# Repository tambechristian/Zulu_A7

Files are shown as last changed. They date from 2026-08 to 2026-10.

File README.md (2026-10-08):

# Zulu A7

Zulu A7 is a USB FPGA board built around an AMD/Xilinx Artix-7
XC7A35T-1CPG236C. An FTDI FT2232HL bridge provides JTAG (channel A) and a
UART (channel B) over one micro-USB port. The board carries 64 MB of SDRAM,
a 128 Mbit quad-SPI configuration flash, a microSD socket, a Pmod host
header and a 40-pin breadboard header. It runs from USB through a
single-cell LiPo charger with power path and three buck regulators (3.3 V,
1.8 V and 1.0 V). The PCB is a 69.85 x 25.40 mm, six-layer HDI board.

The main design is the Altium Designer project in `Zulu_Altium_VS_Code/`.
Its fabrication and turnkey-assembly packages for PCBWay are dated
2026-10-07. Build and test results are not recorded in this repository.

## Origin and attribution

Zulu A7 is an adaptation of **XuLA2**, the USB FPGA prototyping board by
Dave Vandenbout / XESS Corp. (copyright 2012 XESS Corp.), published at
<https://github.com/xesscorp/XuLA2>. Its hardware design (schematic and
layout in `pcb/`) is licensed under
[CC BY-SA 3.0 Unported](https://creativecommons.org/licenses/by-sa/3.0/),
per the notice on its schematic. This repository does
not imply any connection with, or endorsement by, XESS Corp. or Dave
Vandenbout.

XESS's [product listing](https://www.tindie.com/products/xesscorp/xula2-lx25-fpga-prototyping-board/)
says the whole XuLA2 design was made open source and that anyone who
re-designs it must open-source their design too. As of 2026-10-07 it lists
XuLA2 as retired. The licence terms are those of CC BY-SA 3.0.

XuLA2 (schematic version 2.0, EAGLE 5 files) had a Xilinx Spartan-6
XC6SLX25 in FT256 and a Microchip PIC18F14K50 that handled reset and
initialisation, clock generation and USB-to-JTAG. It also had 256 Mbit
SDRAM, 8 Mbit SPI flash, a microSD socket, a mini-USB connector, ZLDO1117
3.3 V and 1.2 V regulators, a 40-pin breadboard prototyping header and an
aux JTAG header.

### Lineage

1. **XuLA2**: XESS Corp., 2012. The upstream design.
2. **XuLA3**: Christian Tambe's own rework of XuLA2, started 2026-08-10 in a
   separate local repository that is not published. It is not an XESS
   design. Its baseline is the XuLA2 schematic in EAGLE XML. The move to the
   Artix-7, the FT2232H bridge and an LTC3569 triple buck was made in XuLA3,
   before the fork. There the `xess` library was renamed `ctambe`, and the
   schematic AUTHOR and copyright line were changed to Christian Tambe.
3. **Zulu A7**: forked from XuLA3 on 2026-08-29 (commit `30a0e65`, "Zulu A7
   forks from XuLA3: the board is renamed, not redesigned"). That commit
   renamed X2's package XULA-DIP37 to ZULU-DIP37 and its deviceset XULA-CONN
   to ZULU-CONN, dropped unused devicesets including XC6SLX25-FT256 and
   PIC18F14K50, and set the version to 1.0. `zulu_a7.brd` took only its
   layer, settings and autorouter sections from the XuLA3 board;
   `tools/make_board.py` writes the geometry new.
4. **Altium and KiCad copies**: the EAGLE schematic was imported into Altium
   with the EAGLE Import Wizard in `Zulu_Altrium/` (commit `6d2efd6`).
   `Zulu_Altium_VS_Code/` is a later working copy of that project. The SC189
   regulators, the BQ24232 charger and the X2 pin field are Altium-side
   changes, and the board was routed there. `Zulu_kicad/` is a KiCad
   conversion of the Altium project.

### Main changes from XuLA2

| | XuLA2 | Zulu A7 |
|---|---|---|
| FPGA | Xilinx Spartan-6 XC6SLX25, FT256 | AMD/Xilinx Artix-7 XC7A35T-1CPG236C |
| USB bridge | Microchip PIC18F14K50 | FTDI FT2232HL with a 93LC46B EEPROM |
| USB connector | Hirose UX60SC-MB-5ST mini-USB | Molex 105017-0001 micro-USB |
| SDRAM | W9825G6JH-5, 256 Mbit | Alliance AS4C32M16SB-7TCN, 512 Mbit |
| Flash | W25Q80BV, 8 Mbit | Winbond W25Q128JV, 128 Mbit quad SPI |
| microSD | ALPS SCHD3A0100 | Hirose DM3D-SF |
| Clock | generated by the PIC18F14K50 | 12.000 MHz oscillator shared by the FT2232HL and the FPGA |
| Power | ZLDO1117 3.3 V and 1.2 V regulators | BQ24232 LiPo charger and three SC189 bucks (3.3 / 1.8 / 1.0 V) |
| Headers | 40-pin breadboard header, aux JTAG header | 40-pin breadboard header X2 with its own pin map, 2x6 Pmod host header J1, unpopulated JTAG holes JP3/JP4 |
| PCB | 2 in x 1 in | 69.85 x 25.40 mm, six-layer HDI |

XuLA3 and the EAGLE-era Zulu A7 used an LTC3569 triple buck. The Altium
copy replaced it on 2026-09-06 with the three SC189 bucks, so the EAGLE
files in this repository still show the LTC3569.

`docs/Zulu_A7-Design-Change-Record.html` lists the part changes from the
fork. Its "Was" column is the XuLA3 rev 1 state, which is mostly but not
entirely the XuLA2-LX25 BOM (the ESP8266 header and the BTN1 PTA-142 button
were XuLA3 additions). It predates the SC189 power section.

### What still comes from XuLA2

Compared with the `xess` library of the XuLA2 schematic (in its EAGLE XML
form), the `ctambe` library in the root `zulu_a7.sch` keeps 16 packages
byte-identical (for example TSOPII-54, SCHD3A0100, UX60SC-MB-5ST, CC_BY,
CC_CC and CC_COPYRIGHT), and 7 symbols and 5 devicesets are identical. The
later EAGLE copies keep the same packages with their keepout outlines
removed. Sheet text such as "Block Diagram",
"PROTOTYPING HEADER", "FPGA Connections" and the three licence lines is
kept verbatim. This material is in the EAGLE files (`zulu_a7.sch`,
`zulu_a7.brd` and the EAGLE copies in `Claude_Fable/`, `Zulu_Altrium/`,
`Zulu_Altium_VS_Code/` and `Altium_backup/`), in the SchDoc, PcbLib and
PcbDoc files of the four Altium copies and the September schematic PDFs,
and in `Zulu_kicad/kicad_project/` (`ctambe.kicad_sym`, footprints in
`zulu_a7.pretty/`, `zulu_a7.kicad_pcb` and `zulu_a7_2.kicad_sch`).

### Notices

In every copy of the schematic, the General IO sheet (sheet 3 of 7 in EAGLE
and Altium, `zulu_a7_2.SchDoc`; page 4 of 8 in KiCad, `zulu_a7_2.kicad_sch`,
under the added root sheet) carries "2026, Christian Tambe. Some rights
reserved." and the three CC BY-SA Unported licence lines, beside the CC
logos. The title block of every sheet reads "AUTHOR: Christian Tambe": in the
EAGLE files through the AUTHOR attribute, and in the Altium copies
(`Zulu_Altium_VS_Code/`, `Zulu_Altium_VS_Code_HDI_Optimized/`) and the KiCad
copy since 2026-10-08 (`Zulu_Altium_VS_Code/docs/schematic_author.md`). The
superseded `Zulu_Altrium/` and the `Altium_backup/` snapshot still show the
importer's placeholder "AUTHOR".
The upstream line "2012, XESS Corp. Some rights reserved." and the upstream
AUTHOR "Dave Vandenbout / XESS Corp." were replaced during the XuLA3 rework
and have never been in this repository's history, and the sheets do not yet
carry the XESS line again.
[LICENSE](LICENSE) reproduces the upstream notice and gives the credit for
XuLA2; keep it with any copy of the schematics.

## Board facts

- **FPGA**: U1 XC7A35T-1CPG236C, CPG236 BGA, 10 x 10 mm, 0.5 mm pitch.
- **USB**: U2 FTDI FT2232HL (LQFP-64). Channel A is MPSSE JTAG plus
  PROG#/DONE, channel B is the UART. U10 93LC46B configuration EEPROM.
  X1 Molex 105017-0001 micro-USB-B.
- **Memory**: U3 Alliance Memory AS4C32M16SB-7TCN, 512 Mbit (64 MB) SDRAM;
  the memory controller must use 10 column bits (A0-A9). U4 Winbond
  W25Q128JVSIQ, 128 Mbit quad SPI; the 17,536,096-bit bitstream leaves about
  14 MB for user data.
- **Clock**: Q1 ECS-3225SMV-120-FP-TR, 12.000 MHz, +-10 ppm HCMOS
  oscillator, driving the FT2232HL and the FPGA through 33 ohm each.
- **Power**: U8 TI BQ24232 single-cell LiPo charger with power path. Its
  output VU, the system rail that feeds the three bucks, is 4.4 V from USB
  and VBAT - 60 mV on battery; 495 mA input limit, 244 mA charge current.
  Battery on X4, a JST PH 2-pin header (pin 1 = battery +); the BOM has no
  battery. U5, U6 and U7 are Semtech SC189 bucks for 3.3 V, 1.8 V and 1.0 V
  (FPGA core).
- **I/O**: X2 40-pin breadboard header, 2.54 mm pitch, rows 22.86 mm apart,
  mounted from the underside; GND on pins 1, 17 and 21, +3.3 V on 18,
  +1.8 V on 19, +1.0 V on 20, VU on 22. J1 2x6 Pmod host header. X3 Hirose
  DM3D-SF microSD socket with card detect. JP3/JP4 unpopulated 1x3 JTAG
  holes. User button BTN, RGB LED LD0 and five 0603 LEDs (LD1-LD5).
- **PCB**: 69.85 x 25.40 mm, six layers (Top / L2 GND / L3 / L4 / L5 VCC3V3 /
  Bottom). Two-step HDI 1+1+N+1+1 with 0.15 mm laser microvias, 0.15 mm
  L3-L4 buried vias and 0.20 mm through vias. 3.0 / 3.5 mil minimum
  track / space. USB pair 90 ohm differential.
- **Status**: fully routed. Altium DRC on the final saved board (2026-10-07
  16:53) reports 0 violations; the report is
  `Zulu_Altium_VS_Code/Imported zulu_a7.PrjPcb/Design Rule Check - zulu_a7.drc`.
  The release packages identify the board by its PcbDoc SHA-256,
  `89a421b9060195d66bed82f7a4e7d80121bd0e9d679a3fee32289e8f541f4bde`.
- **Assembly**: 172 fitted designators (32 top, 140 bottom), 76 parts in
  0201. ENIG finish recommended. No fiducials on the board.

Known caveats, from `Zulu_Altium_VS_Code/docs/power_budget.md` and the
assembly notes:

- The worst-case draw (about 697 mA) exceeds the 495 mA input limit and needs
  the battery; with no battery the board browns out at that load. The board
  draws more than 100 mA before the FT2232HL enumerates.
- Every rail has more output capacitance than the SC189 datasheet's 30 uF
  start-up limit. Scope the three rails at power-on on the first board.
- LD0 green and blue are sunk from 3.3 V through 33 ohm and may be dim or
  dark; only red has margin.
- U5 and U7 look alike; swapping them puts 3.3 V on the FPGA core.

## Repository layout

| Entry | Status | Contents |
|---|---|---|
| `Zulu_Altium_VS_Code/` | **Current, authoritative** | Main Altium project: `Imported zulu_a7.PrjPcb/` (7 SchDocs, PcbDoc, PcbLib, released Gerber and NC-drill files, DRC report), `fabrication/`, `assembly/`, `docs/` (stage and decision records), `tools/`, `board/` (outline DXF; `JLCPCB-HDI-ENQUIRY.md` is superseded). The Stage-13 route plan is `tools/stage13/plan.json`; the root `plan.json` is a small XADC-knot plan. Its root `zulu_a7.sch` is the stale EAGLE import source. |
| `Zulu_Altium_VS_Code_HDI_Optimized/` | Derivative | Same-outline copy of the main board with 13 HDI sites turned into through vias, with its own fab zips and assembly release. |
| `Zulu_kicad/` | Derivative | KiCad 10 conversion of the main project, netlist-proven. Design rules were not translated, so KiCad DRC is not meaningful; do not refill zones. Altium stays the fabrication master. |
| `Zulu_Altrium/` | Superseded | Earlier Altium working copy: the EAGLE import, the September schematic work, routing placed through Stage 8 and the Stage 9-12 records (plans, never placed). Its PcbDoc is an intermediate Stage-13 Phase II board. |
| `Altium_backup/` | Snapshot | Backup of the Altium project taken during the September routing stages. |
| `Claude_Fable/` | Legacy | EAGLE/Fusion-era 8-layer HDI working copy, its board variants and tools. |
| `zulu_a7.sch` | Legacy | EAGLE schematic from the fork. It predates the released design (no BQ24232, no SC189) and is not the Altium import source, which is the later `Zulu_Altrium/zulu_a7.sch`. |
| `zulu_a7.brd` | Legacy | EAGLE board from the fork. |
| `tools/` | Legacy | EAGLE-era Python tools that read or write the root `zulu_a7.sch` / `zulu_a7.brd` (for example `make_board.py`, `validate.py`, `change_record.py`). |
| `board/` | Legacy | EAGLE/Fusion-era fab planning: `STACKUP.md`, EAGLE `.dru` rule files, DFM enquiry drafts, `pcbway/README.md`. Superseded by `Zulu_Altium_VS_Code/fabrication/PCBWAY_FAB_NOTES.txt`. |
| `docs/` | Mixed | `zulu_a7-bom.csv` is the current master BOM. `Zulu_A7-Design-Change-Record.html` is an EAGLE-era record. |
| `vivado/` | Mixed | `zulu_a7_pins.xdc` is current (Stage-13 pin permutation). `zulu_a7_io.rpt`, `zulu_a7_io.csv` and `zulu_a7_clocks.rpt` come from the 2026-09-10 Vivado run and show pre-swap balls; `zulu_a7_top.v` is the HDL top module used for that run. |
| `Zulu A7 Board Plan.html` | Legacy | Generated by `tools/board_plan.py`; shows the old 60.96 x 25.40 mm board. |
| `fix_sheet_names.cmd` | Legacy | EAGLE-era helper, run after exporting `zulu_a7.sch` from Fusion. |
| `W*P1.pdf`, `W*P2.pdf` | Vendor documents | PCBWay order-page printouts. They are not the fabrication spec; see `PCBWAY_FAB_NOTES.txt`. |
| `.gitignore` | | Ignores EAGLE and Vivado scratch files, `Datasheet/`, `board/*.pdf` and `archives/`. |

`archives/` and `Datasheet/` are ignored and are not part of the repository.

## Where to start

1. Open `Zulu_Altium_VS_Code/Imported zulu_a7.PrjPcb/zulu_a7.PrjPcb` in
   Altium Designer. The folder name comes from the EAGLE Import Wizard.
2. `Zulu_Altium_VS_Code/fabrication/PCBWAY_FAB_NOTES.txt`: what the current
   board is (stack, vias, impedance, outline, file map, final DRC).
3. `Zulu_Altium_VS_Code/assembly/Zulu_A7_Assembly_Notes.txt` and
   `Zulu_Altium_VS_Code/docs/pcbway_assembly_release.md`: the assembly
   release. To regenerate it, run
   `python tools/generate_jlcpcb_assembly.py --release-date 2026-10-07` from
   `Zulu_Altium_VS_Code/`.
4. `docs/zulu_a7-bom.csv`: the master BOM. Regenerate it only with
   `Zulu_Altium_VS_Code/tools/master_bom.py`; the copies in `Zulu_Altrium/`
   and `Altium_backup/` read stale sheets.
5. `Zulu_Altium_VS_Code/docs/power_budget.md`: power path, current budget
   and the caveats above.
6. `Zulu_Altium_VS_Code/docs/stage13_route_plan.md`, section "Final
   implementation closeout": how routing was finished. Later board changes
   are in `x1_slot_fix.md`, `x2_power_pins.md`, `x2_pin_labels.md` and
   `btn_move.md` in the same folder.
7. For FPGA work: `vivado/zulu_a7_pins.xdc` is the current pin map (the
   SDRAM ports need DRIVE 8, as set there). This repository has no
   programming instructions, FT2232H EEPROM image or example bitstream.
8. `Zulu_Altium_VS_Code_HDI_Optimized/HDI_OPTIMIZATION_NOTES.md` (the
   derivative board) and `Zulu_kicad/CONVERSION.md` (the KiCad copy).

Notes:

- No current schematic PDF is tracked. The `zulu_a7.pdf` files in
  `Zulu_Altrium/` and `Altium_backup/` are 2026-09-10 prints and are out of
  date.
- `Zulu_Altium_VS_Code/docs/` is a dated record of stages and decisions, and
  older entries describe superseded states. For example,
  `Zulu_Altium_VS_Code/docs/hdi_spec.md` and `board/pcbway/README.md` name
  JLCPCB as the fab. Where they disagree with the release files, the release
  files are current.
- `Zulu_Altium_VS_Code/tools/README.md` covers the import, schematic-edit and
  audit scripts (`pip install olefile pywin32`). It does not cover the
  routing toolkits or the assembly generator, which also needs `pymupdf` and
  `altium-monkey` (`pip install olefile pymupdf altium-monkey`).
- Vendor datasheets are not tracked. After a fresh clone, put AMD's package
  pinout file for the XC7A35T-CPG236 back as
  `Datasheet/xc7a35tcpg236pkg_pinout.txt`. Without it, `tools/validate.py`,
  `tools/vivado_io_check.py`, `tools/escape/rings.py` and
  `tools/change_record.py`, and the Altium copy's `tools/bom_audit.py`,
  `tools/connectivity_check.py` and `tools/stage13/xdc_check.py`, lose their
  ball checks or fail.

## Licence

See [LICENSE](LICENSE). Except for the third-party material listed there,
this repository, scripts included, is licensed under
[CC BY-SA 3.0 Unported](https://creativecommons.org/licenses/by-sa/3.0/legalcode).
It is an adaptation of XuLA2 (see above). Under section 8(b) of the licence,
XESS Corp., as Licensor of XuLA2, offers each recipient a licence to the
original XuLA2 Work on the same terms.

Design references, not files: some circuit choices follow Digilent's Cmod
A7. The SC189 bucks are "Cmod A7 style", the XADC input network is the one
Digilent uses on the Cmod A7, and the SDRAM, microSD and GPIO ball
assignments were first checked against the Cmod A7-35T. No Digilent file is
in this repository, and this licence grants nothing on Digilent's behalf.

Not in this repository: XuLA2's firmware (XESS code under GPL v2 or later,
plus Microchip USB-stack files under Microchip's licence), its FPGA example
designs (many files under GPL or LGPL), and the vendor datasheets and the
AMD/Xilinx pinout file (`Datasheet/` is ignored).

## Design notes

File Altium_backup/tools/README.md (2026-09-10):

# Altium import checks

Scripts used to convert `zulu_a7.sch` (EAGLE 9.7 XML, written by Fusion 360)
into `Imported zulu_a7.PrjPcb` with Altium Designer's EAGLE Import Wizard,
and to check the result.  They edit the SchDoc files directly (OLE compound
documents, `FileHeader` stream of `|RECORD=n|Key=Value|` records), so close
the project in Altium before running the two fix scripts.

    pip install olefile pywin32

* `verify_import.py zulu_a7.sch "Imported zulu_a7.PrjPcb"` - every EAGLE
  part, gate, supply symbol and named net has its Altium counterpart.
* `fix_text_orientation.py <SchDoc...>` - EAGLE draws R180/R270 text
  readable; Altium draws Orientation 2/3 upside down.  Turns them into
  0/90 with mirrored justification, so anchors and text boxes stay put.
* `fix_labels.py <this folder> "Imported zulu_a7.PrjPcb"` - the label
  placements adjusted after reviewing the Smart PDF export (see docstring).
* `fix_gate_labels.py <this folder> <SchDoc...>` - the one-pin-per-gate
  parts (X2, U3, U4, U1) show their gate names through EAGLE's >GATE text;
  the importer gives every such label OwnerPartId=1, so Altium hides all but
  one per part.  Re-owns each label to its gate.
* `add_noerc.py <this folder> "Imported zulu_a7.PrjPcb"` - No-ERC markers on
  the nine pins that are open on purpose (the eight GTP balls the sheet
  marks "float per UG482", and the USB ID pin X1-4).
* `fix_pin_types.py <this folder> "Imported zulu_a7.PrjPcb"` - the EAGLE
  library types the supply/ground pins of U2, U3, U4, U10 and all of X2's
  pins as "io"; makes them Power and Passive so the ERC pin-type rules mean
  something.
* `swap_vcc3v3_to_sw1.py <this folder> "Imported zulu_a7.PrjPcb/zulu_a7_1.SchDoc"` -
  the 2026-09-06 design change: VCC3V3 onto the LTC3569's 1.2 A channel
  (SW1) and VCC1V0 onto SW3, by swapping the two rail labels after L1/L3,
  the R65/R66 and R71/R73 divider values and the EN1/EN3 wiring. Applied
  once; the docstring is the change record. Not reflected in zulu_a7.sch
  (EAGLE), which is now history.
* `sc189_power_section.py <this folder> "Imported zulu_a7.PrjPcb/zulu_a7_1.SchDoc"` -
  the 2026-09-06 regulator change: the LTC3569 section (U8, dividers, the
  EN_BIAS network) replaced by three fixed SC189 bucks U5/U6/U7 with L1-L3
  at 1.5 uH, C80/C82/C84 as 22 uF outputs, new C147-C149 10 uF inputs, C78
  at 10 uF. Rewrites the sheet record by record; run once, on the sheet as
  committed in bedd4a7 (its delete list is keyed to that file). SC189 pin
  numbers (1 VIN, 2 GND, 3 EN, 4 VOUT, 5 LX) were checked against the Semtech
  datasheet (Datasheet/SC189-datasheet 08 27 10.pdf, p2 and p14) on 2026-09-06.
* `fix_sc189_bom.py <this folder> "Imported zulu_a7.PrjPcb/zulu_a7_1.SchDoc"` -
  follow-up to the above: the hidden MANF#/SPEC parameters that the value
  edits had left stale (L2/L3 still named the 3.3/2.2 uH inductors, C82/C84
  a 10 uF part under a 22 uF value, C78 the 22 uF part under 10 uF) and the
  three input caps moved to a 10 V 0805 part (GRM21BR61A106KE19L) because a
  6.3 V 0603 is under the datasheet's 4.7 uF at 5 V. Keyed by designator,
  safe to re-run.
* `x3_dm3d_sf.py <this folder> "Imported zulu_a7.PrjPcb/zulu_a7_3.SchDoc"` -
  2026-09-06: X3 (microSD) from the Hirose DM3AT-SF-PEJM5 push-push socket to
  the DM3D-SF push-pull one (HRS 609-0025-8, DM3 catalog p9 in
  Datasheet/DM3AT-SF-PEJM5.pdf). Same eight contacts; the two 'G1,3'/'G2,4'
  multi-pad shell pins become G1-G4 on the GND bus; new pins A/B for the
  card-detect switch, left open with No-ERC markers; footprint model renamed
  DM3D-SF (to be drawn at the PCB stage). Refuses to run twice.
* `btn_pts810.py <this folder> "Imported zulu_a7.PrjPcb/zulu_a7_2.SchDoc"` -
  2026-09-08: BTN from the PTA-142 (no maker, no distributor) to the C&K /
  Littelfuse PTS810SJM250SMTR LFS (4.2 x 3.2 mm J-lead, 1.6 N). Parameters,
  an inserted MANF parameter (OwnerIndex renumbering) and the footprint model
  name PTS810; pins 1,2 / 3,4 already match the datasheet's 1-2 / 3-4 pairing.
  Refuses to run twice.
* `ld0_east1616.py <this folder> "Imported zulu_a7.PrjPcb/zulu_a7_2.SchDoc"` -
  2026-09-08: LD0 from the Victory VS NRD8 (maker-direct only) to the Everlight
  EAST1616RGBA8 (19-337/R6GHBHW-A01/2T), the same body, pads and arrangement
  with different pad numbers: pins renumbered 1/2/3 -> 2/4/6 (cathodes) and
  4/5/6 -> 1/3/5 (anodes), nets untouched, footprint model EVERLIGHT-19-337.
  Refuses to run twice.
* `x2_sullins.py <this folder> "Imported zulu_a7.PrjPcb/zulu_a7_2.SchDoc"` -
  2026-09-08: the ZULU-CONN pin field X2 gets MANF, MANF#, SPEC and NOTE
  (Sullins PRPC024SAAN-RC + PRPC009SAAN-RC + PRPC011SAAN-RC, one of each per
  board) inserted into all 45 placed gates with OwnerIndex renumbering;
  comment and footprint ZULU-DIP37 unchanged. Refuses to run twice.
* `x2_lipo_corner.py <this folder> "Imported zulu_a7.PrjPcb"` - 2026-09-09: room for
  the LiPo connector at the right-hand end of X2. Sheet 2: +5V-INPUT (pad 44)
  with D2/D3, VEXT and GND5 (pad 23) deleted; +3.3V2/GND3 swapped with
  CHAN12/CHAN13 (pads 2/3 <-> 25/26) as a net-label, GATE-label and GateName
  swap; the two dead sub-parts removed from all 43 gate copies and parts
  renumbered 1-43 (PartCount 44, AllPinCount 42); displayed pins 2/3 retyped
  passive and 25/26 power; MANF#/SPEC/NOTE and the text frame rewritten for
  the split bottom row (PRPC020 + PRPC002). Sheet 1: charger note updated.
  Verifies the result and refuses to run twice. Its sub-part deletion also took the
  seven catalogue parameters of two copies whose serial OwnerPartId was 35 or 45
  (found by the review workflow); `x2_restore_params.py` put them back.
* `x2_restore_params.py <this folder> "Imported zulu_a7.PrjPcb/zulu_a7_2.SchDoc"` -
  2026-09-09: re-appends DeviceName/LibraryName/DeviceSetName/MANF/MANF#/SPEC/NOTE
  to any X2 gate copy missing them, cloned from a healthy copy.
* `x2_jst_gap.py <this folder> "Imported zulu_a7.PrjPcb"` - 2026-09-09, second pass:
  GND3 deleted, the bottom row closed up and re-numbered by position (23 RST#,
  24 +3.3V, 25-27 CHAN14-16, 28-30 empty for the LiPo header, 31-44 CHAN17..
  ANALOG-IO1), gate copies/wires/labels moved to the rows of their new pads,
  designators remapped in all 42 copies, sub-parts renumbered 1-42, catalogue
  parameters exempt from the sub-part deletion; MANF#/SPEC/NOTE and the text
  frame rewritten (PRPC007 + PRPC014 on the bottom row); U8 NOTE on sheet 1
  loses its D2 sentence. Verifies rows against pad numbers; refuses to run twice.
* `x2_drop_3v3.py <this folder> "Imported zulu_a7.PrjPcb"` - 2026-09-09, third pass:
  +3.3V2 (pad 24) deleted, its position left empty like the LiPo gap; sub-part
  removed from all 41 copies and parts renumbered 1-41 (PartCount 42,
  AllPinCount 40); no pin slides, so the only netlist effect is X2-24 leaving
  VCC3V3. MANF#/SPEC/NOTE and the text frame rewritten (bottom row now 1x3 +
  1x3 + 1x14). The header takes 3.3 V from pad 17. Refuses to run twice.
* `x2_renumber_40.py <this folder> "Imported zulu_a7.PrjPcb"` - 2026-09-09, fourth
  pass: CHAN14-16 slide one position right into the hole +3.3V2 left, so the LiPo
  landing widens to four positions and matches the USB landing (12.70 mm between
  neighbouring pin centres, 11.176 mm clear); the field is then renumbered 1-40
  straight through, skipping both landings. Designators remapped in all 41 gate
  copies, three gate copies with their wires and labels shifted, MANF#/SPEC/NOTE
  and the text frame rewritten (1x6 + 1x14 on the bottom row). Connectivity is
  untouched: the netlist differs only in X2 pad names. Refuses to run twice.
* `x2_move_landing.py <this folder> "Imported zulu_a7.PrjPcb"` - 2026-09-09,
  fifth pass: CHAN17-19 (pins 27-29) slide four positions towards the corner, so
  the LiPo landing moves to between pins 29 and 30, on the same four x values as
  the USB landing above it, and the two rows become mirror images (9 + landing +
  11 each). Pin numbers do not move, so the exported netlist is byte-identical;
  only geometry, MANF#/SPEC/NOTE and the text frame change (strips become 2x 1x9
  + 2x 1x11). Refuses to run twice.
* `sc189_pin_ids.py <this folder> "Imported zulu_a7.PrjPcb/zulu_a7_1.SchDoc"` -
  2026-09-09: the fifteen pins of U5, U6 and U7 all carried one UniqueID
  (PDYAEPSY, from cloning a pin record in sc189_power_section.py); each gets a
  fresh one, clear of the others on the sheet. Only the UniqueID field changes,
  which verify() proves by masking it and comparing byte for byte, so the
  netlist is unaffected. Refuses to run twice.
* `x2_top_row_order.py <this folder> "Imported zulu_a7.PrjPcb"` - 2026-09-09,
  sixth pass: the top row put in channel order (1 GND, 2 CHAN-CLK, 3-9 CHAN0-6,
  USB landing, 10-16 CHAN7-13, 17-20 the supplies), so CHAN12/CHAN13 leave the
  corner. Sixteen gate copies move with their wires and labels and every pin
  designator is remapped in all 41 copies; connectivity is unchanged, only which
  X2 pad each net lands on. Refuses to run twice.
* `sheet0_pmic_block.py <this folder> "Imported zulu_a7.PrjPcb"` - 2026-09-09:
  the block diagram gains PMIC BQ24232 between the USB port and the voltage
  regulators, with LiPo Connect on its right; the +5V riser is extended into the
  charger, VU drops from the charger into the regulators and VBATT runs to the
  battery block. Drawing furniture only (RECORD=4 text, RECORD=6 lines), so the
  netlist cannot change. Refuses to run twice.
* `jp_dns.py <this folder> "Imported zulu_a7.PrjPcb/zulu_a7_4.SchDoc"` - 2026-09-08:
  JP3/JP4 (bare JTAG holes) get DNS = Yes and a SPEC line, inserted after
  their NOTE with OwnerIndex renumbering; bom_audit lists them as DNS
  positions instead of parts. Refuses to run twice.
* `u2_ft2232hl.py <this folder> "Imported zulu_a7.PrjPcb"` - 2026-09-09: U2 from
  the FT2232HQ (QFN-64, dry until April 2027) to the FT2232HL (LQFP-64, same
  die and pin numbering): part number, comment, label, device names,
  description, footprint model FT2232HL-LQFP64, SPEC/NOTE inserted, the EP
  pin and its ground stub removed (bus wire shortened), sheet-4 title and
  sheet-0 block renamed. Refuses to run twice.
* `bq24232_charger.py <this folder> "Imported zulu_a7.PrjPcb/zulu_a7_1.SchDoc"` -
  2026-09-09: D1 (USB VBUS Schottky) replaced by a TI bq24232 LiPo charger and
  power path (U8), JST PH battery connector X4, C150/C151, R102-R108, LD3/LD4:
  deletes D1 and its cathode wire by content, appends the new symbols, wires,
  labels, ports and notes. Values from SLUS821J section 9.2.1 (495 mA input
  limit, 244 mA charge, 36 mA termination, 7.5 h timer, TS disabled).
  Footprints VQFN16-3X3-RGT and JST-B2B-PH-SM4-TB are for the PCB stage.
  Refuses to run twice.
* `sheet1_rearrange.py <this folder> "Imported zulu_a7.PrjPcb/zulu_a7_1.SchDoc"` -
  2026-09-09 re-layout of sheet 1: the charger block up under the USB
  connector (+460), the SC189 blocks and the LD5 power-good circuit down
  (-500), X1's VBUS pin wired straight into U8 IN, C78 moved onto U8 OUT
  (pins 10/11) with its own ground, C151 nudged left. Netlist unchanged.
  Refuses to run twice.
* `d2_note.py` - D2 gets the NOTE parameter (D1 removal, SOD323F footprint)
  as a hidden parameter, so the master BOM's note for it comes from the sheet
  like every other note.
* `ft_vcore_caps.py <this folder> "Imported zulu_a7.PrjPcb/zulu_a7_4.SchDoc"` -
  2026-09-09: C152, C153 and C154, three 0.1uF 0201 GRM033R61A104KE15D cloned
  from C136, hung off the FT-VCORE rail beside C39 with their own ground ports,
  one per FT2232H VCORE pin, after connectivity_check.py found that rail carrying
  bulk only. The rail is extended left and junctioned; no net label is added
  because the extension is one wire with the rail. Refuses to run twice.
* `tck_pullup_out.py <this folder> "Imported zulu_a7.PrjPcb/zulu_a7_4.SchDoc"` -
  2026-09-09: R89, the 10 K pull-up on TCK, is removed.  It sat on the BRIDGE
  side of the damping resistor and fought R5, 5.1 K to ground on the FPGA side,
  so with ADBUS0 tri-state -- power-up, and any time no USB host has opened the
  MPSSE -- the FPGA's clock input rested at 3.3 x 5100/(10000+100+5100) = 1.11 V,
  between VIL and VIH.  Dropping the pull-up and keeping the pull-down leaves TCK
  idling low, which is the JTAG convention and the safe level for a clock.  R89's
  rail drop goes with it and so does the junction at (692,1072), which was a
  three-wire branch and is now a corner; the wire carrying U2 pin 16 out to the
  column is SHORTENED rather than deleted, because it holds the TCK net label.
  Netlist: pads 785 -> 783, TCK keeps JP3-1, R4-6 and U2-16.  Refuses to run twice.
* `resistor_packs.py <this folder> "Imported zulu_a7.PrjPcb/zulu_a7_4.SchDoc"` -
  2026-09-09: the six 100 ohm JTAG/config series resistors (R9 PROG#, R38 DONE,
  R8 TDI, R37 TDO, R4 TMS, R36 TCK) become one CTS 742C163101JP and the two 4.7 K
  configuration pull-ups (R1 INIT_B, R3 PROGRAM_B) one CTS 742C043472JP, drawn the
  way R34 is: one RECORD=1 per placed element, all sharing a designator, each
  carrying the whole pin set, differing only in CurrentPartId, PartCount = elements
  + 1.  They read R4A..R4F and R1A/R1B.  Isolated arrays pair pad k with pad 2N+1-k,
  so the bridge side lands on pads 1-6 and the FPGA side on 16-11; the two spare
  elements hold pads 7-10.  A genuine 6-element part exists (CTS 753123101GP,
  12-SRT) but Digi-Key holds none at 28 weeks and MOQ 1000, and its body is bigger
  than the 8-element chip array, so the six go into an eight.  Every pin gets a
  fresh PinUniqueId and the stale HiddenNetName parameters are dropped.  Nets and
  placed pad count come out unchanged (178 and 785); component count 190 -> 184.
  Run sheet4_layout.py first.  Refuses to run twice.
* `sheet4_layout.py <this folder> "Imported zulu_a7.PrjPcb/zulu_a7_4.SchDoc"` -
  2026-09-09, four cosmetic moves that leave the netlist identical.  R3, the
  PROGRAM_B pull-up, is mirrored about its own origin so it stands ON the RST#
  wire with the rail above it instead of hanging below on a 110-unit stub with
  VCC3V3 at the bottom, which read like a pull-down; its rail label becomes a
  horizontal font-3 one like R1's, and the stub wire is deleted.  R1 moves up 60
  to clear it.  C41 turns over (orientation 3 -> 1, pin conglomerates swapped)
  and drops 50 so both FT2232H bypasses hang the same way with their ground
  symbols side by side, and C40 slides 40 right, with its FT-VPHY label, to make
  the room.  Everything around C40 carries sub-unit _Frac offsets from the EAGLE
  import -- three junctions and a 0.04-unit wire hold that node together at three
  different fractional positions -- so that cluster is translated by whole units
  with every _Frac untouched.  Refuses to run twice.
* `r3_pullup_c39_out.py <this folder> "Imported zulu_a7.PrjPcb/zulu_a7_4.SchDoc"` -
  2026-09-09, two changes.  R3 4.7K moves from GND to VCC3V3: connectivity_check.py
  solved the resistor network on every configuration pin and found PROGRAM_B (ball
  V10, net RST#) resting at 1.63 V, in the undefined band, because R3 pulled it
  down and its only pull-up sat behind R9's 100 ohm on a net the FT2232H tri-states
  until a host opens the bridge.  UG470 wants that pin pulled up to VCCO_0; the
  lower end is redrawn the way R1, the INIT_B pull-up on the same sheet, is drawn
  (ground symbol removed, VCC3V3 net label on the stub end).  Both resets survive:
  X2-23 and the bridge through R9.  C39 4.7uF goes: DS_FT2232H Figures 4.1 and 6.1
  show ONE 4.7 uF on the core rail beside the 100 nF parts, and C139 is it, so with
  C152-C154 added the rail now matches the reference exactly.  Its stub, ground
  symbol, net label and rail junction go with it.  Deletes records, so every later
  OwnerIndex is renumbered and the header count rewritten.  Refuses to run twice.
* `sheet0_fixes.py <this folder> "Imported zulu_a7.PrjPcb/zulu_a7_0.SchDoc"` -
  2026-09-09: five things the block diagram said that were not true.  CHAN-I/O
  (28) -> (29), because the netlist holds CHAN0..CHAN28 and the sheet has already
  taught the reader that a bracket is a bus width.  The SDRAM-CLK return branch
  and its arrowhead into the FPGA are deleted -- it implied a feedback path on a
  net that is two pads, U1-M1 and U3-38.  The microSD note's "six bank-34 balls"
  becomes banks 34, 16 and 35, which is what the package file and the sheet-5 pin
  designators say.  The XADC link loses its header-end arrowhead, since the two
  analogue signals only go one way.  The LED/Button link gains an arrowhead into
  the block, because five of its six signals are FPGA outputs.  The Pmod link was
  checked and left alone: the review said it had one arrowhead, it has two.  Ten
  lines deleted and two added, so OwnerIndex is renumbered and the header count
  rewritten -- this is the sheet that was left unopenable once by skipping that.
* `label_justification.py <this folder> "Imported zulu_a7.PrjPcb"` - 2026-09-09:
  254 net labels stop hanging below their wires.  Altium's Justification is a 3x3
  anchor grid (h = j%3, v = j//3); a label with v=2 is anchored at the TOP of its
  text box, so the anchor sits on the wire and the glyphs are drawn underneath it,
  while pin designators are bottom-anchored and sit above theirs.  Rows are 10
  units apart and the text is ~6.8 tall, so every net name landed on the NEXT
  pin's line: CHAN0 (X2 pin 3) rendered at PDF y 100.88..104.00 against the digit
  4 at 101.60..104.72.  Subtracting 6 (6->0, 7->1, 8->2) moves the anchor to the
  bottom and leaves the horizontal half alone; CHAN0 now renders at 97.29..100.40,
  character for character its own digit 3.  Locations are untouched, so the
  netlist is unchanged.  Eight ROTATED top-anchored labels are left alone and
  listed on every run - for those the same flip moves the glyphs sideways.
* `sheet5_ball_captions.py <this folder> "Imported zulu_a7.PrjPcb"` - 2026-09-09:
  the grey "<ball>  <pin function>" captions beside each FPGA pin row on sheet 5
  are regenerated from the pin each one annotates, with the function name read
  from Datasheet/xc7a35tcpg236pkg_pinout.txt.  They had survived the re-pin: 94 of
  137 named a ball that no longer carried that row's net (SD-DAT2's row said W2,
  which really carries SDRAM-CS#), and the Pmod block claimed A14/A15/W7, which
  carry SDRAM D14/D15/D2.  99 rewritten, 37 already right, one left alone and
  reported.  Only pins whose OwnerPartId equals their placement's CurrentPartId
  count as live -- U1 is placed 139 times and every placement carries all 236
  balls, so a naive search finds thousands.  Text only; the netlist is unchanged.
* `schematic_review.py > docs/schematic_review.md` - readability and labelling
  hygiene over the seven sheets, read from the .SchDoc records so it sees what
  Altium sees rather than what the PDF renders.  Checks that every net label and
  power port lands on a wire or a pin (a label one unit off names nothing and the
  netlist never complains), that no wire end dangles, that no two net names differ
  only in case or separator, that every label text became a real net and no net
  has a single pad, that every part can be named by a reader, and how much of the
  printed page the drawing actually gets.  Read-only.  It says where it stops:
  whether a sheet READS well is a judgement it cannot make, so the judgement half
  lives in `schematic_review_notes.md` beside it and is appended verbatim to the
  output -- re-running the tool never overwrites it.
* `connectivity_check.py > docs/connectivity_check.md` - power and ground
  architecture plus bus and differential-pair mapping, read from the exported
  netlist and the datasheets. Traces every supply and ground pin of every IC to
  its rail (the FPGA against the whole CPG236 package pin list, not just the
  symbol), counts the decoupling by value tier against UG483 Table 2-2 and the
  FTDI reference circuit, and verifies every bus line against the pin the part's
  datasheet gives. Read-only. It cannot judge placement, and says so.
* `master_bom.py` - rewrites ../docs/zulu_a7-bom.csv (the master BOM, formerly
  from the root tools/bom.py and the EAGLE schematic) from the Altium sheets,
  keeping its column layout and line order; notes come from the NOTE
  parameters, DNS parts are marked DNP. Run after any sheet change that
  touches parts.
* `bom_audit.py > docs/component_validation.md` - component and BOM validation
  (2026-09-06): BOM from the sheets; FPGA balls and power tree against AMD's
  CPG236 pinout file; FT2232H, SDRAM, flash, EEPROM, oscillator, USB, RGB LED
  and resistor-array pads against their datasheet tables; EAGLE package
  geometry against the datasheet land patterns; capacitor voltage and
  resistor power derating from the nets; a dated Digi-Key snapshot of
  status/stock/price and a second-source table typed in from the lookups.
* `apply_bom_substitutions.py <this folder> "Imported zulu_a7.PrjPcb"` - the
  part-number replacements the audit recommends (obsolete, mistyped and dry
  parts), NOT applied; edit the table, run with the project closed, re-run
  the audit. Rounds applied so far: 2026-09-07 (44 components), 2026-09-08
  (GRM188R61C475KE11D, ECS-3225SMV, the 4.7 uF 0402) and 2026-09-08 U3
  AS4C32M16SB-6TIN -> AS4C32M16SB-7TCN (the -6 grade is dry until October;
  U3 has no SPEC parameter, so the timing text is appended to its NOTE),
  and 2026-09-08 L4-L7 BLM18PG601SN1D (a number Murata never made) ->
  BLM18KG601SN1D.
* `power_budget.py [--fpga-int mA --fpga-io mA --header mA ...]` - rail-by-rail
  power budget from the schematic and the datasheets; writes markdown
  (docs/power_budget.md is its default output). The FPGA dynamic currents
  are assumptions until Vivado's report_power replaces them.
* `erc_summary.py erc.txt` - groups a Messages-panel export (right-click,
  Save...) by message kind.
* `eagle_netlist.py zulu_a7.sch eagle.json` then
  `compare_netlists.py "Imported zulu_a7.PrjPcb/Project Outputs for zulu_a7/zulu_a7.NET" eagle.json`
  - connectivity of the Altium project (Design > Netlist For Project >
  Protel) against the EAGLE schematic, pad by pad.  It last agreed on
  2026-09-07 (190 components, 175 nets, 799 pads, no differences) and has
  since been left behind on purpose: the Altium side has taken the SC189
  regulators, the bq24232 charger, the X2 pin field, the C39 removal and the
  two resistor arrays, none of which exist in ../zulu_a7.sch.  As of
  2026-09-09 it reports 184 components against the EAGLE 190.  Keep it for
  the day the EAGLE source is regenerated; do not read its output as a fault.

Import Wizard settings that matter: untick "Do not translate hidden net
names" (else 16 nets named without a label lose their names).  Pins that
own several pads in EAGLE (BTN 1/2 and 3/4, X1 5+shell, X3 G1/G3 and
G2/G4) become single Altium pins named "1,2" etc.; split them before
matching to the imported board.

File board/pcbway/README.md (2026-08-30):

# PCBWay variant — provisional, do not edit by hand

`zulu_a7.sch` and `zulu_a7.brd` in this directory are a complete, openable Eagle pair
for the **PCBWay 1+4+1 HDI** build. They are **generated**, not authored:

```bash
python tools/make_board.py --fab pcbway
```

Anything you edit here is lost on the next run. **The one schematic to edit is
`zulu_a7.sch` at the repository root.** Both variants come from it, and the only
thing that differs between them is the diameter of the 238 CPG236 ball lands.

## Why this variant exists

The active fab is JLCPCB, at a **0.225 mm** land. This variant keeps the full
**0.275 mm** land — UG475's maximum, and its recommended 1:1 ratio to the package
pad "for improved board level reliability". **HDI is the only route that keeps
it**, and JLCPCB does not do HDI at all.

| | root — JLCPCB | here — PCBWay |
|---|---|---|
| ball land | 0.225 mm (0.82:1) | **0.275 mm (1:1)** |
| solder mask opening | 0.325 mm | 0.375 mm |
| line / space | 3 mil trace, 3.5 mil clearance | 0.065 / 0.065 mm |
| escape | trace between two lands, +0.0188 mm | laser via inside every land |
| vias | 0.2 mm drill, 0.30 mm land, through | 4 mil laser, L1→L2 |
| status | **active, route this one** | provisional |

## What is not settled

1. **The DFM enquiry is unanswered.** It went out 2026-08-26; see
   `board/PCBWAY-DFM-ENQUIRY.md`, questions 5–7. Until they reply this is a
   guess at what they will build, made from their published HDI page.
2. **The layer plan does not survive HDI unchanged.** A 1+4+1 build lands every
   ball on L2, which `STACKUP.md` has as a solid ground plane. That is a rework
   of the plan, not a parameter, and it is not done.
3. **The stackup in the `.dru` is still the through-hole one.** HDI will change
   it. Do not compute an impedance width from this file until PCBWay sends the
   real build.

So: this pair is here so the option stays open and comparable, not because it is
ready to send. Route the root pair.

## Checking it

```bash
python tools/check_board.py board/pcbway/zulu_a7.brd board/pcbway/zulu_a7.sch
```

`check_board.py` reads the fab out of the board's design-rules name and checks
the rules *and the land* against it, so a board carrying the wrong land for its
fab fails rather than looking fine.

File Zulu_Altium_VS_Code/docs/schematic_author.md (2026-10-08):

# Author in the schematic title blocks (2026-10-08)

The user asked for their name, Christian Tambe, to appear as author on the schematic sheets.

## What was wrong

The EAGLE title block (the DOCFIELD symbol) has the text "AUTHOR:" followed by `>AUTHOR`. In EAGLE, `>AUTHOR`
resolves to the schematic's global attribute, which is "Christian Tambe".

The Altium EAGLE importer turned `>AUTHOR` into a DOCFIELD parameter named AUTHOR whose text is the literal word
"AUTHOR". It also dropped the "AUTHOR:" label, whose name collided with that parameter. So every Altium sheet showed
just "AUTHOR" in the author row. "Christian Tambe" existed only as a hidden sheet parameter, `Author`. The KiCad
conversion inherited the same placeholder.

## Change

`tools/schematic_author.py` makes three edits to every SchDoc:
1. It sets the DOCFIELD's AUTHOR parameter to "Christian Tambe", at the `>AUTHOR` position.
2. It appends a sheet label "AUTHOR:" at the PROJECT: label's x and the author row's y, in PROJECT:'s font
   (FontID 2) and colour. The row now reads "AUTHOR: Christian Tambe", as in the EAGLE original.
3. It updates the header Weight to the new record count.

| Sheet | Title block | AUTHOR value at | Label at |
|---|---|---|---|
| zulu_a7_0 Block Diagram | (250, 112) | (330, 97) | (255, 97) |
| zulu_a7_1 Power | (250, 112) | (330, 97) | (255, 97) |
| zulu_a7_2 General IO | (380, 114) | (460, 99) | (385, 99) |
| zulu_a7_3 Memory | (380, 112) | (460, 97) | (385, 97) |
| zulu_a7_4 FT2232 | (262, 112) | (342, 97) | (267, 97) |
| zulu_a7_5 FPGA Connections | (380, 112) | (460, 97) | (385, 97) |
| zulu_a7_6 FPGA Power | (266, 112) | (346, 97) | (271, 97) |

Coordinates are Altium schematic units (10 mil).

The script refuses to run twice, and checks after writing that every other record is byte-identical. The same
script was run on the HDI_Optimized copy's sheets.

## Checks

- **Visual:** Altium opens the sheets, and the title blocks of sheets 1 and 3 read "AUTHOR: Christian Tambe",
  aligned under "PROJECT: zulu_a7".
- **ECO:** the preview (Design > Update PCB Document) lists only the usual baseline: the ten PCB-only net classes
  and the USB differential pair, never executed. The edit adds no schematic-to-PCB change.
- **Records:** in every sheet, every record header is consistent and every record is NUL-terminated.

## Scope

- **Edited:** `Zulu_Altium_VS_Code/` and `Zulu_Altium_VS_Code_HDI_Optimized/` (seven SchDocs each), and the KiCad
  copy (`Zulu_kicad/tools/apply_schematic_author.py`; see `Zulu_kicad/CONVERSION.md`).
- **Left as they were:** the superseded `Zulu_Altrium/` and the `Altium_backup/` snapshot, which still show
  "AUTHOR".
- **Already correct:** the EAGLE files.
- **Not affected:** the PcbDoc and the fabrication and assembly outputs.

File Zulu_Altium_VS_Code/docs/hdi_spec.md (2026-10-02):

# HDI specification — the judge's full reasoning (2026-09-29, workflow wf_d61d6c0f, 7 agents, 1.29M tokens)

Structured result: docs/hdi_spec.json. Proposed tools/hdi.json: docs/hdi.proposed.json. Fab facts: docs/hdi_fab_facts.md.

# Zulu A7 HDI specification (judge, 2026-09-29)

Board `Imported zulu_a7.PrjPcb/zulu_a7.PcbDoc` md5 `210a6f2b7669980309fb2472a125ad98` (= brief). `tools/route_inputs.json`
md5 `e166d74aa85467675801e6e7802c7104` (the brief's `f5903da8` is stale: the `hdi` block was added; geometry identical to the
PcbDoc within 0.044 um -- three independent regenerations agree). Live `tools/hdi.json` md5 `b05f58bb` = the through-only
default. This directory: `hdi.json` (md5 `dab6ffb3`, the exact content for `tools/hdi.json`), `arith.py`/`arith.out` (every
derived number), `exercise_hdi.py`/`.out` (the live `tools/hdi.py` loading that JSON), `remeasure/sites_0p12.out` (U1 site
count re-measured at 0.12/0.27, 0.15/0.30 and 0.10/0.25 with a copy of the u1_sites enumerator; COMBOS swapped, nothing else).

Inputs judged: the three measurements and their verifier verdicts (impedance, dfm_rules, u1_sites), the three fact sheets,
`docs/stack_switch_3313E.md`, `docs/sdram_bus_widths.md`, `docs/pwr_rail_widths.md`, `docs/via_land_decision.md`,
`docs/stage9_decision.md`, `docs/hdi_fab_facts.md`, `board/JLCPCB-DFM-ENQUIRY-2.md`, `tools/hdi.py`, `tools/verify_stack.py`,
Rules6 (55 rules, `dfm_rules/rules_all.json`). Where a verifier refuted a claim the verifier wins; the only re-measurement I
made myself is the U1 site count at 0.12/0.27 (`remeasure/`), because no sibling had measured that combination.

## 1. The decision in one paragraph

**JLCPCB, HDI 2-step, Structure B on the named stack `JLCH061611N2-2116` exactly as JLC publish it** (2+2+2, 1 oz inner
forced), **laser microvia 0.15 mm hole / 0.30 mm land (ring 0.075)**, stacked Top->L2-GND->L3-SIG and Bottom->L5-VCC3V3->L4-SIG,
buried mechanical L3-SIG->L4-SIG 0.15/0.27 through the 0.930 core only once JLC have priced it, through vias 0.20/0.35 unchanged,
**no via-in-pad anywhere, no placed copper changes width** (0 of 1518 tracks). The one fab question that can improve the spec
before ordering is a **0.12 hole / 0.27 land** on the same stack (rule-legal at 0.93:1, ring 0.075; it turns the 47 U1
interstitial sites from a 0.9 um margin into 15.9 um). Cost: **$309.34 (qty 5) / $313.19 (qty 10), 12-13 days** plus the
buried-via and lamination fees JLC only quote manually, against $186.13 / $201.97 and 8-9 days today.

Why this and not the two siblings' preferred 0.10/0.25: on this board the microvia hole/land does not change the U1 site
count (87 legal at 0.075/0.225, 0.10/0.25, 0.12/0.27 and 0.15/0.30 alike, because the board's own 0.09 clearance to the
placed Top fan-out and to the placed 0.35 lands binds first everywhere), while the only stacks that admit a 0.10 hole put a
thin 1080/1078 prepreg under the SDRAM bus and drop the **placed** L3/L4 copper to 43.1-45.2 ohm (wanting 0.092-0.105 mm on
607.8 mm of it = a re-route), and the hybrid that keeps the bus (1078 on L1-L2 only) still needs hole >= 0.112 for the L2-L3
member of every signal stack, so it buys no U1 signal site and costs the USB pair 7.4 ohm plus a custom stack. 2116 as named
costs +2.5 ohm on the (unplaced) USB pair, +1.2 ohm on the placed SDRAM bus, and nothing else.

## 2. Fab and structure

- **Fab: JLCPCB** (HDI launched 2026-09-14; fact sheet `jlcpcb_hdi_facts.md`). PCBWay is out: only 1+N+1 is priceable
  ($495.01 qty 5, 10-11 d, +$185.67 over JLC's 2-step), 2+N+2 "not priceable online", no published 6L HDI stack, via-in-pad
  +$125.61-170.40, and the project already priced and rejected PCBWay for the standard board (memory).
- **Structure: 2-step at 6 layers = Structure B of the brief**: stacked laser microvias Top->L2->L3 and Bottom->L5->L4, through
  vias stay legal, buried L3->L4 "as needed". JLC's 6L 2-step layer pairs are by analogy with their 8L example (L1-L3 / L4-L6):
  **open question 1 of the fact sheet, first fab question below.** 1-step (1+4+1, $208.96) is Structure A's path and rips 288
  inner tracks / 857.8 mm / 50 nets incl. all 39 SDRAM nets (brief) -- refused. Plain 1+4+1 with the planes as they are converts
  97 of 377 vias (brief) -- not enough.
- **Stacked, not staggered**: JLC do both; stacked "requires copper fill (filled and planarized by electroplating, dimple <= 10 um)"
  with an unstated surcharge (fab question 3). Staggered would spend two of U1's 87 legal sites per stack; sites are the binding
  resource (`docs/stage9_decision.md`: "the binding resource is via slots").
- Buried L3->L4: JLC offer mechanical buried 0.15-0.55 mm, epoxy filled and capped, core across the span >= 0.30 (0.930 here,
  aspect 6.2:1); the quote shows "Buried Via Fee: Manual Quote" and "Lamination Fee: Manual Quote" and the named stack is
  listed "no buried". The span is in `hdi.json` so plans can be measured with it, but **no plan may depend on it until JLC price
  it** (user decision 4).

## 3. Stack: named, and the exact per-layer request under "Subject to Review"

Order **by name: `JLCH061611N2-2116`**, 1.58 mm nominal, selected in the HDI impedance flow, and get the engineer-generated
stack onto the order acknowledgement (the lesson of `docs/stack_switch_3313E.md`: a free-text remark is not a binding channel).
The per-layer request, so the emailed stack can be checked line by line:

| # | layer | thickness (mm) | material / Dk | note |
|---|---|---|---|---|
| L1 Top | copper | 0.035 finished (1 oz) | | unchanged |
| PP | 2116 x1 | **0.112 pressed** | Dk 4.29 @1 GHz (JLC PP library) | JLC named-stack figure; library nominal 0.127 |
| L2-GND | copper | **0.030** (1 oz, forced) | | today 0.0152 |
| PP | 2116 x1 | **0.112 pressed** | Dk 4.29 | the SDRAM reference gap; today a 0.100 core Dk 4.6 |
| L3-SIG | copper | 0.030 | | |
| core | | **0.930** | Dk unmeasured (4.6 assumed in every solve; sensitivity 0.9 ohm on the SDRAM far-plane term, 0 on the pair) | today 1.1208 (7628+0.7+7628) |
| L4-SIG | copper | 0.030 | | |
| PP | 2116 | 0.112 | Dk 4.29 | |
| L5-VCC3V3 | copper | 0.030 | | |
| PP | 2116 | 0.112 | Dk 4.29 | |
| L6 Bottom | copper | 0.035 | | |

Laminate 2x0.035 + 4x0.030 + 4x0.112 + 0.930 = **1.568 mm** (JLC round it to 1.58 +-10 %); with the two 1.2 mil masks
1.629 mm; today's laminate 1.65038. Through-via aspect 1.568/0.20 = 7.84:1 (JLC <= 16:1). Laminate TG170 (NP-175F or S1000-2M,
+$6.76 already in the quote). Copper-face-to-copper-face convention for every gap must be confirmed (fab question 4) -- the
whole impedance solve pivots on it.

Refused stacks, with the number that refuses each: `JLCH061611N1-2116D` (1+4+1: Structure A, converts too little; SDRAM
47.0 ohm would be fine); `JLCH06161HN1-1078` (L3 sits 0.550 from L2: placed 0.125 bus reads 83 ohm, 0.545 mm to restore, not
routable in U3's 0.35 mm street); 2+2+2 with 1080/1078 on L1-L2 **and** L2-L3 (bus 45.2 ohm at 0.086 / 43.1 at 0.0784 pressed,
at or below the 45-60 band; restoring 0.105/0.092 mm on 607.8 mm of placed L3/L4 copper = re-route); hybrid 1078 L1-L2 / 2116
L2-L3 (bus stays 50.2, pair 77.9, rule 0.1235/0.150, custom stack, and the 0.10 hole is legal only on the Top->L2 span while every
signal stack's L2->L3 member still needs >= 0.112, so it gains no U1 signal site); 106/1037 outers for a 0.075 hole (custom
stack, USB 63-67 ohm, 90 ohm unreachable at >= 3 mil on 106).

## 4. Microvia

- **Hole 0.15 / land 0.30 mm, laser, ring 0.075.** Forced by JLC's aspect <= 1:1 (hole >= dielectric = 0.112) using their
  default sizes (0.10 default, range 0.075-0.15) and pad >= hole + 0.15. 0.112/0.15 = 0.75:1; if JLC count the 0.035 outer foil
  in the laser depth (unstated), 0.147/0.15 = 0.98:1 still passes, while 0.12 would fail (1.23:1) -- one more reason 0.15 is the
  guaranteed baseline and 0.12/0.27 is a question, not an assumption.
- **Alternative to ask for: 0.12 hole / 0.27 land** (0.933:1, ring 0.075, inside the 0.075-0.15 range; whether JLC laser
  non-default sizes is unstated). Same 87 U1 sites, same 84 max simultaneous, same 51 stackable, but the interstitial margin
  to the 0.09 rule becomes +0.0159 mm (+0.0059 under a "BGA pad to copper 0.10" reading, all 87 kept) instead of +0.0009 /
  -0.0091 (87 -> 40) at 0.15/0.30 (`remeasure/sites_0p12.out`, `arith.out`). Rule values in Altium and `hdi.json` change in
  four places if JLC say yes (`_alternates["0.12_0.27"]`: pitch 0.36, antipad 0.45, laser-to-mechanical 0.40).
- **Spans**: Blind Top->L2-GND, Blind L2-GND->L3-SIG, Blind L4-SIG->L5-VCC3V3, Blind L5-VCC3V3->Bottom (all uVia); Buried
  L3-SIG->L4-SIG (mechanical 0.15/0.27); Thru 1:6. No skip via type: JLC split a Top->L3 skip into a stacked pair anyway and
  Altium has no separate stacked type -- a stack is two objects at one XY.
- **Stacked** (same net, one XY, `stacked_same_xy: true`), copper-filled and planarized per JLC.
- **Via-in-pad: NO, nowhere.** 0.15 in U1's 0.225 land = 0.0375 ring (0.12 -> 0.0525), below JLC's 0.075. The only via-in-pad
  combinations that exist (0.075-in-0.225 on 106/1037; 0.10-in-0.225 on 1078 with a 0.0625-ring waiver) each need a different,
  custom stack; they reach ring 0 (40 of the 42 ring-0 signal balls) but cost 7.4-22 ohm on the USB pair. Not in this order; user
  decision 5 says whether to ask JLC about it as a rev-B option.
- Pitches (different nets, centre to centre, `arith.out`): microvia-microvia 0.39, microvia-through 0.415, microvia-buried
  0.39, buried-buried 0.39, through-through 0.44 (unchanged). Same-net stacks need no pitch (one XY).
- Plane void for a foreign-net microvia on L2-GND / L5-VCC3V3: **0.48 mm** = 2 x max(0.075 + 0.15, 0.15 + 0.09); through vias
  keep 0.70. Two foreign-net voids in adjacent 0.5 mm sites leave a **0.02 mm web** (< 3 mil): foreign-net stacks must not
  occupy two adjacent interstitials/cells; diagonal neighbours (0.7071) keep 0.227. The site matching below did not apply this
  constraint (unmeasured impact on the 41).

## 5. Why the combination is one decision, resolved

The brief's collision (2116 at 0.112 makes a 0.10 hole illegal) resolves as: the hole follows the prepreg, the prepreg follows
the placed SDRAM bus, and the bus is placed. Numbers, all under the file's mask model (1.2 mil / Dk 3.8) with three solvers
agreeing within 0.4 ohm:

| stack (outer PP L1-L2 / L2-L3) | legal laser hole | USB 0.150/0.150 | SDRAM 0.125 L3/L4 (placed) | placed copper |
|---|---|---|---|---|
| today 3313E 0.0994 / 0.100 core | -- | 85.3 | 49.0 | -- |
| **N2-2116 0.112 / 0.112** | **0.15 (0.12 if accepted)** | 87.8 (+2.5) | 50.2 (+1.2; 50.4 with the slot as PP resin) | **none** |
| 2313 0.103 / 0.103 | 0.15 (0.103 > 0.10) | 85.3 | 48.3 | none, but no named stack |
| 1080 0.086 / 0.086 | 0.10 | 81.2 (-4.1) | 45.2 (-3.8) | re-route 607.8 mm |
| 1078 0.0784 / 0.0784 | 0.10 | 77.9 (-7.4) | 43.1 (-5.9) | re-route |
| hybrid 1078 / 2116 | 0.10 on L1-L2 only | 77.9 | 50.2 | none, custom stack, no site gain |
| HN1-1078 (1+4+1) | 0.10 | 77.9 | 83.2 | 0.545 mm to restore: out |

The +2.5 on the pair is a one-solver but not a one-Dk-source delta (today's 4.10 is JLC's 3313E table, 2116's 4.29 is the PP
library at 1 GHz): +1.4 at Dk 4.45, +3.8 at Dk 4.10 (verifier). U2 is an FT2232HL, USB 2.0 Hi-Speed, so 1 GHz Dk is the right
frequency. Absolute pair values carry +-5 ohm of mask-model spread (no mask 94.4, file mask 85.3, Altium stock mask 91.1); the
stack-to-stack deltas are the robust numbers. The docs' 87.37 was reproduced by no model and its two "independent 2-D FEM
solvers" exist nowhere on disk nor in git history.

## 6. `tools/hdi.json` -- exact content: `judge/hdi.json` (md5 dab6ffb3)

Loaded through the live `tools/hdi.py` (`exercise_hdi.out`): spans T-L2 / L2-L3 / L4-L5 / L5-B laser 0.15/0.30 pitch 0.39
antipad 0.48; L3-L4 mechanical 0.15/0.27 pitch 0.39; through 0.20/0.35 pitch 0.44; `laser_to_mechanical_pitch` 0.415;
`disjoint_span_pitch` 0.0 (JLC state no rule for spans that share no layer -- fab question 11); `stacked_same_xy` true. Pitch
matrix as intended (0.39 / 0.415 / 0.44, `None` for disjoint spans); `antipad_r` 0.24 -> 0.48, through 0.70; `punches` void for
foreign nets only; `stacked()` accepts T-L2 over L2-L3 and L2-L3 over the buried L3-L4 on one net, rejects different nets and
non-adjacent spans.

Two things the JSON cannot fix and the tools workflow must (not mine to edit):
1. `via_in_pad` is false on every span (correct: no via-in-pad), but `hdi.field_ban()` lifts U1's land-field ban only for
   via-in-pad spans, so **as hdi.py stands every span here is banned inside the field** (conservative, verified in
   `exercise_hdi.out`). The JSON carries a new key `field_ok` (true on Top->L2, L2->L3, L4->L5, L3->L4; false on L5->Bottom and
   through); `field_ban()` must become `return not bool(self.params(span).get('field_ok', False))`. This is the land-field
   raster change stage 9 left open (user decision 7).
2. `hdi.usable('Top','SIG')` returns only the through span: a Top->L2 via alone reaches no second signal layer, so **the gates
   never propose a stack**; stack planning must pair Blind 1:2 + Blind 2:3 explicitly. Also `route_reach.py:197` bans vias
   across the whole land field and `route_inputs.py EDGE_CLEARANCE = 0.25` is 0.025 short of JLC's 0.35 hole-edge for vias
   (0.275 land-edge at ring 0.075; the project convention 0.80 binds anyway).

## 7. Altium: Via Types and rules

LSM > Via Types (GUI only; save the LSM, then Ctrl+S the PcbDoc): **Blind 1:2** Top Layer -> L2-GND uVia; **Blind 2:3** L2-GND ->
L3-SIG uVia; **Blind 4:5** L4-SIG -> L5-VCC3V3 uVia; **Blind 5:6** L5-VCC3V3 -> Bottom Layer uVia; **Buried 3:4** L3-SIG -> L4-SIG
(uVia off); **Thru 1:6** stays. The final Stage 13 board uses L2-GND and L5-VCC3V3 as Signal layers, not Internal Plane
layers. All six Via Types are saved and file-verified; the NC drill export produced one file for every pair. Script side:
a stack = two `IPCB_Via` objects at one XY, each Size 0.30 / HoleSize 0.15, with `Net.AddPCBObject` too. Drill pairs are
read-only from script, so the Via Types still come first in the GUI.

Rules (name | kind | scope | value | status). Values in brackets are the 0.12/0.27 alternative.

| rule | kind | scope | value | status |
|---|---|---|---|---|
| RoutingVias_uVia | RoutingVias | `IsMicroVia` | hole 0.15 min=max=pref, diameter 0.30 min=max=pref [0.12 / 0.27], priority 1 | new; optional per-span split `IsMicroVia And (StartLayer = 'Top Layer') And (StopLayer = 'L2-GND')` etc. |
| RoutingVias_Buried | RoutingVias | `IsBuriedVia` | hole 0.15, diameter 0.27 (ring 0.06: 0.06 + 0.09 = JLC's 0.15 hole-to-trace), priority 2 | new |
| RoutingVias | RoutingVias | `All` -> `IsThruVia` | 0.20 / 0.35, priority 3 | exists (13.7795 / 7.874 mil, "Through Hole") |
| HoleSize_uVia | HoleSize | `IsMicroVia` | 0.15-0.15 absolute [0.12], priority 1 | new: the existing HoleSize All 0.20-1.02 would flag every microvia |
| HoleSize_Buried | HoleSize | `IsBuriedVia` | 0.15-0.55, priority 2 | new |
| HoleSize | HoleSize | `All` | 0.20-1.02 | exists, drops to priority 3 |
| MinimumAnnularRing_uVia / _Buried / (All) | MinimumAnnularRing | `IsMicroVia` / `IsBuriedVia` / `All` | 0.075 / 0.06 / 0.075 | new (no rule of this kind exists today) |
| HoleToHoleClearance | HoleToHoleClearance | All, All | 0.20 -> **0.24**, "Allow Stacked Micro Vias" TRUE (already TRUE) | exists; audit: 0 pairs below 0.24 today, 8 same-net pairs at exactly 0.2400 (0.44 pitch) -- if the first DRC flags them by rounding, 0.2399 is a rounding artefact, not a JLC concession |
| LayerPairs | LayerPairs | | ENFORCE TRUE | exists; the only check catching a script-placed via whose span is not a Via Type |
| Clearance_Plane_ThruVia | Clearance | named L2/L5 plane polygon, `IsThruVia` | 0.175 mm from the 0.35 mm via land -> 0.70 mm void, priority 1 | final signal-polygon rule; Gerber measures nominal 0.7001 mm |
| Clearance | Clearance | All, All | 0.09 mm; 0.30 mm microvia land -> 0.48 mm void | final signal-polygon microvia behavior; Gerber measures nominal 0.4800 mm |
| PlaneConnect_Vias | plane/polygon connect | `IsVia` | Direct | final DRC 0; all 135 L2 GND and 85 L5 VCC3V3 via positions connect without a centered void |
| BoardOutlineClearance_Vias | BoardOutlineClearance | `IsVia` | 0.80 mm | new (no outline rule exists); JLC need 0.275 land-edge; closest via land-edge today 0.825 -> 0 violations |
| Clearance | Clearance | All, All | 0.09 unchanged | ring 0.075 + 0.09 = 0.165 hole-edge >= JLC 0.15, so the board's rule binds |
| SolderMaskExpansion_Vias | SolderMaskExpansion | `IsVia` | tented both sides | exists, unchanged |
| Fanout_BGA | FanoutControl | `IsBGA` | Centered | exists, unchanged |
| DiffPairsRouting | DiffPairsRouting | All | 0.150 / 0.150 provisional (see widths) | exists |

Scope keywords `IsBuriedVia` / `IsThruVia` are documented for Routing Via Style. The final saved board and zero-violation
DRC verify `IsBuriedVia` in HoleSize and `IsThruVia` in the named-polygon Clearance rule. `IsMicroVia` in HoleSize /
MinimumAnnularRing is documented and the final board's 1,038 marked records pass it.

**Gate result, completed 2026-10-02:** the negative-plane representation was not retained. L2/L5 were converted to Signal
layers with full GND/VCC3V3 polygons before Stage 13 placement. Final Gerbers contain all 0.300 mm microvia lands,
nominal 0.4800 mm foreign-microvia voids, nominal 0.7001 mm foreign-through-via voids, and direct same-net via
connections. This signal-polygon implementation is the baseline for future routing.

## 8. Width changes -- rules and placed copper, before / after

Placed copper: **0 of 1518 tracks change** (SDRAM 39 nets: L3 81 tracks / 276.2 mm, L4 127 / 331.6 mm, Bottom 45 / 48.7 mm at
0.125, Top 147 / 121.1 mm at 0.0762; the only placed inner rail copper is VCC1V0 on L3, 5 tracks / 13.6 mm at exactly the 0.50
floor; USB_D_P / USB_D_N have zero tracks).

| what | before | after | reason |
|---|---|---|---|
| `Width_SDRAM` L3/L4/Bottom | 0.10 / 0.125 / 0.15 | **unchanged** | placed 0.125 reads 50.2 ohm on N2-2116 (etch band 48.24-52.28) vs 49.0 today, nearer the 8 mA (~50 ohm) driver; inside the docs' 45-60 band |
| `Width_SDRAM` Top | 0.0762 / 0.0762 / 0.15 | unchanged | the 3 mil escape reads 68.0 ohm single-ended vs 65.4 today (number, not a constraint) |
| `DiffPairsRouting` USB | 0.150 / gap 0.150 | **0.150 / 0.150 provisional** | 87.8 ohm on N2-2116 (today 85.3), nearer the 90 nominal, inside JLC's +-10 % (81-99); 0.162/0.150 would hold today's 85.3, 0.141/0.150 gives 90 in our model. Freeze only after JLC's calculator figure (fab question 5); the pair is not placed, so this is rule-only |
| `Width_PWR_VCC3V3` inner min | 1.05 | **1.05 now; 0.55 optional** once 1 oz inner is on the acknowledgement | IPC-2221 10 C width 1.0187 -> 0.5161 at 0.030 Cu (ratio 0.5067); DRC-only, no copper moves |
| `Width_PWR_U8` inner min | 1.10 | 1.10 now; 0.60 optional | 1.0937 -> 0.5541 |
| `Width_PWR_VCC1V0` inner min | 0.50 | 0.50 now; 0.25 optional | 0.4515 -> 0.2288; the 5 placed L3 tracks at 0.50 stay |
| every other Width / Clearance rule | | unchanged | |

If the floors are relaxed, `tools/verify_widths.py` (the acceptance test) and `SetPwrRailWidths` in `tools/ZuluSetup.pas` carry
the same values. The relaxation is void if JLC honour 0.5 oz inner on request (fab question 6): on 0.0152 Cu the floors stand.

## 9. U1 via sites under 0.15/0.30 on N2-2116 (`remeasure/sites_0p12.out`, u1_sites verifier)

- **87 of 447 positions legal today** (40 vacant cells: E6-E15, F5, F14, G5, G15, H5, H15, J5, J15, K5, L5, L6, L15, M5, M6,
  M14, M15, N5, P5, P15, R5-R15; 47 interstitials: 42 ring-1/2 + 5 moat/core); **max simultaneous 84** (diagonal
  cell/interstitial pairs 0.3536 apart are exclusive: land gap 0.0534 < 0.09, hole gap 0.2034 < 0.24); **51 of the 87 also
  clear the placed L3 copper** for the L2->L3 member (stackable), **45** also clear L3+L4 for a buried via beneath. Identical
  at 0.12/0.27 and 0.10/0.25 (87 / 84 or 87 / 51 / 45): the placed copper and the 0.09 rule bind, never JLC's hole rules.
- Interstitial margin to the 0.09 rule: **+0.0009 mm at 0.30** (grid minimum 0.240946 - 0.150 - 0.09), **-0.0091 under a
  "BGA pad to copper 0.10" reading (87 -> 40)**; at 0.27: +0.0159 / +0.0059 (87 kept). This is the quantified reason for the
  0.12/0.27 question and for fab question 9.
- Signal balls served by in-field sites: at most **41 of 117** (18 ring-1 + 23 ring-2 by maximum matching; 37 of 40 ring-1
  alone); **ring 0: 0 of 42** at every combination without via-in-pad; restricted to L3-stackable sites 16. Of the 82 ring-0/1
  balls that need an outside via today, 64 still do.
- The **24 signal-net Top-only vias** (107 Top-only in all) convert in place at every combination (nearest foreign through via
  0.5 mm: hole and land margins +0.085 at 0.15/0.30); far ends 8 Bottom-only / 8 through-hole / 8 Top or Top+Bottom nets.
- Through via 0.20/0.35: 41 sites (40 cells + 1 interstitial).
- Plane web: foreign-net stacks in two adjacent 0.5 mm sites cut L2 to 0.02 mm -- alternate sites; the effect on the 41 is
  unmeasured.

## 10. `tools/verify_stack.py` must become

1. `EXPECT` for `JLCH061611N2-2116`: Top Layer 0.035; Dielectric 2 **0.112 Dk 4.29 PREPREG**; L2-GND **0.030**; Dielectric 4
   **0.112 Dk 4.29 PREPREG** (today 0.100 core 4.6, type CORE=1 -> 2); L3-SIG 0.030; Dielectric 1 **0.930, type CORE (1)**, Dk =
   JLC's emailed value (4.6 assumed; today 1.1208 / 4.523 / GENERIC because it was a merged row -- now a single core, so CORE is
   the honest label); L4-SIG 0.030; Dielectric 5 0.112 / 4.29 / PREPREG; L5-VCC3V3 0.030; Dielectric 3 0.112 / 4.29 / PREPREG;
   Bottom 0.035; masks unchanged 1.2 mil / 3.8 / SURFACE. `INNER_CU_MM = 0.030`. Dk values are placeholders until the stack
   review: keep `TOL_DK` and print the emailed figure beside them.
2. Laminate line: **1.568 mm <- JLC 1.58 +-10 %** (not 1.65040); total with mask 1.629.
3. Legacy `LAYERn` table expectations: Top 0.112/4.29, L2 0.112/4.29, L3 0.930/Dk core, L4 0.112/4.29, L5 0.112/4.29; PASS string
   `JLCH061611N2-2116`.
4. Section [4] unchanged (PLANE1NETNAME GND, PLANE2NETNAME VCC3V3, 20 mil pullbacks, the six LAYERIDs) -- the edit must again be
   in place, row by row, Stack Symmetry OFF, never a rebuild (stack_switch_3313E.md's warning stands).
5. **New section [5]: the Via Types.** After the GUI save, read Board6/Data for the drill-pair keys (`LAYERPAIR0LOW/HIGH` exist
   today; the count key and any uVia flag are unknown to every open parser) and assert the five spans Top-L2, L2-L3, L4-L5, L5-Bottom,
   L3-L4 plus Thru; fail if a pair is missing or a plane layer is not offered. Section [6] (or `verify_widths.py`): the new
   Rules6 entries -- RoutingVias_uVia 0.15/0.30, HoleSize_uVia, MinimumAnnularRing_uVia, HoleToHole 0.24, PlaneClearance_uVia,
   BoardOutlineClearance_Vias.
6. `Vias6` census: bytes 29/30 per via must now be one of (1,39), (39,2), (3,40), (40,32), (2,3), (1,32) once microvias exist
   (layer codes TOP 1 / MID1 2 / MID2 3 / BOTTOM 32 / PLANE1 39 / PLANE2 40 per the KiCad offsets; the fact sheet's "(74,1,0)" is
   wrong, byte 30 is 32 on all 377 today).

## 11. Cost and lead time (fact sheets, 70x26 mm, 6L, 1.6 mm, ENIG, 3 mil tier, impedance)

- **JLC HDI 2-step: $309.34 qty 5 / $313.19 qty 10, 12-13 days**; standard 6L today $186.13 / $201.97, 8-9 days: **+$123.21
  (+66.2 %) / +$111.22 (+55.1 %), +4 days**; vs 1-step ($208.96) +$100.38. Itemised: HDI structure fee $167.30 (1-step $66.92),
  eng $33, impedance $33.08 (the standard stack had it at $0 per JLC's 2026-09-14 reply -- ask), ENIG $16.80, inner Cu 1 oz
  $16.62, min via $16.77, Kelvin $16.66, material $6.76, board $1.20, file confirm $1.05 (sum 308-309, matches).
- **Not in the quote: Buried Via Fee and Lamination Fee ("Manual Quote"), the stacked-via copper-fill surcharge (unstated), and
  whether the 12-13 days include the "Subject to Review" stack round trip.** JLC holidays Sep 25, 27, Oct 1-4 2026.
- PCBWay 1+N+1 $495.01 / $507.23, 10-11 days; 2+N+2 not priceable; via-in-pad +$125.61-170.40 -- not chosen.

## 12. Questions to send JLC before ordering (in the order they decide the spec)

1. On `JLCH061611N2-2116` ordered as HDI 2-step, confirm the layer pairs: L1-L2 and L2-L3 laser (stacked, copper filled and
   planarized) and L6-L5 / L5-L4 likewise; surcharge for stacked vs staggered; may a stack sit on an epoxy-filled buried via?
2. Laser hole sizes on the 0.112 mm 2116 outer PP: is 0.12 mm (0.93:1, pad 0.27) accepted, or only 0.10/0.15 -- which discrete
   sizes do you laser between 0.075 and 0.15? Does the 1:1 aspect count the 0.035 mm outer foil (0.147 mm)? Via-hole and
   laser-position tolerance ("not controlled" on the capability page) and layer-to-layer registration.
3. Buried via L3-L4 (0.15 hole, 0.27 pad, 0.930 mm core) on this stack: Buried Via Fee and Lamination Fee amounts; do they apply
   to the N-type named stack; may we keep the stack name with buried vias added?
4. The engineer-generated stack: PRESSED thickness and Dk (state the frequency) of each 2116 (we assume 0.112 / 4.29; your
   3313E table used 4.10 and PCBWay quote 4.45 for 2116 -- the USB pair moves 2.4 ohm across that range) and of the 0.930 core;
   confirm gaps are copper-face to copper-face; 1.58 mm total.
5. Impedance on HDI: your calculator's figure for a 0.150/0.150 Top-layer pair on this stack (we solve 87.8; 85 at 0.162/0.150;
   90 at 0.141/0.150), the mask thickness/Dk you model (1.2 mil / 3.8?), the +-10 % promise, the $33.08 line item (standard
   stacks were $0), and whether the 3 mil / 0.09 BGA allowance (+20 % tier, 2026-09-14 reply) still stands on an HDI order with
   impedance control; fine-line tolerance +-8-12 % on HDI outer layers.
6. Is 0.5 oz (0.0152 mm) inner copper honoured on a 6L HDI order or is 1 oz truly forced? (Our inner power floors halve at 1 oz.)
7. Plane anti-pads: is a 0.48 mm void around a 0.15/0.30 microvia on an inner plane acceptable (hole-edge to plane copper
   0.165); is a plane web narrower than 3 mil between two adjacent voids rejected, or merged by CAM?
8. Hole-edge rules: 0.24 different-net / 0.13 same-net applies laser-to-mechanical too (0.15 microvia vs 0.20 through = 0.415
   pitch)? Is a same-net trace entering its own via exempt from the 0.15 hole-to-trace figure?
9. Does "BGA pad to trace >= 0.10" apply to a microvia land at an interstitial of the 0.5 mm BGA? A 0.30 land clears the 0.225
   lands by 0.0909 (0.27: 0.1059) against our 0.09 rule.
10. "Blind via edge to board edge >= 0.35": hole edge or pad edge; the through-via-to-edge minimum on HDI.
11. Any minimum spacing between two vias whose spans share no layer (a Top-L2 microvia directly over an L5-Bottom one)?
12. Lead time: do 12-13 days include the stack review; the forced 4-wire Kelvin test; expedite options; Oct 1-4 holiday effect.
13. (Rev B, not this order) Filled-and-capped microvia in a 0.225 mm BGA land: 0.10 hole (ring 0.0625) or 0.075 hole (ring
    0.075) -- accepted, on which outer prepreg, at what cost?

## 13. User decisions

1. **Approve the stack + microvia**: `JLCH061611N2-2116` as named with 0.15/0.30 as the rule-guaranteed baseline; authorise
   asking for 0.12/0.27 and switching the four rule values if JLC say yes.
2. **DiffPairsRouting**: keep 0.150/0.150 (87.8, nearer 90) or move to 0.162/0.150 (hold today's 85.3); either way freeze only
   after JLC's own figure. Stage 9's "may USB ship broken in rev A" decision is still open and interacts: if USB is deferred the
   value is moot for rev A.
3. **Inner power floors**: keep 1.05/1.10/0.50 or relax to 0.55/0.60/0.25 once 1 oz inner is on the acknowledgement (DRC-only;
   no copper moves; void if 0.5 oz is honoured).
4. **Buried L3-L4 via**: keep it in the structure (unknown fee, +lamination) or drop it (plain 2+2+2 with stacks only); no plan
   depends on it until priced.
5. **Via-in-pad at ring 0**: not in this order; ask JLC question 13 for rev B, or not.
6. **Budget**: +$123 (+66 %) and +4 days over the standard board, plus the unpriced buried/lamination/copper-fill items.
7. **Lift the U1 land-field via ban for microvia spans only** (`field_ok`): the blanket rectangle was the user's constraint and
   every gate was built on it (stage 9 decision 2).
8. **If the L2 test via shows no landing pad for a foreign-net stack**: convert L2-GND / L5-VCC3V3 to signal layers with full
   polygons (a structural edit of the file with its own verification chain), or restrict stacks to GND/VCC3V3 nets and use
   Structure A's spans for signals -- decide after the 10-minute test, not before.
9. Still open from stage 9: the MUST 52, the 2 GND ties (R15-1, U2-5) by hand, teardrops, final DRC, IBIS, fab outputs.

## 14. Corrections to the record

1. Brief: `route_inputs.json` md5 `f5903da8` -> `e166d74a` (hdi block added; geometry identical). Brief: 1518 tracks is the
   JSON's copper-layer count; the PcbDoc holds 1526 track records (+4 on L2-GND, +4 on L5-VCC3V3: split-plane boundary lines).
2. Brief: via census 155/136/86 holds only with GNDADC (2) counted as GND and VCC1V8/VCC1V0/VCCADC (20) as "signal"; by net name
   157 / 134 / 86.
3. Brief: "203 at a 0.35 land" IS a grid count (123 vacant cells + 80 moat interstitials, pre-copper), and "447 at <= 0.30" is
   pre-copper too; with today's placed copper the counts are 87 (<= 0.30) and 41 (0.35).
4. Brief: 0.241124 mm is the 0.5001-pitch maximum; the binding minimum is 0.240946 (0.4999 pitch); `docs/via_land_decision.md`'s
   0.240941 is 5 nm off.
5. Brief: "a 0.10 mm microvia is ILLEGAL on N2-2116; it needs a 0.15 hole (pad 0.30)": the rule's minimum is hole >= 0.112, so
   0.12/0.27 is legal if JLC laser non-default sizes; 0.15/0.30 is the default-size choice.
6. Brief: "26 placed Top-only stubs" -> 24 signal-net Top-only vias (107 in all), invariant to endpoint tolerance 0.2-50 um.
7. `docs/stack_switch_3313E.md`: the "two independent 2-D FEM solvers" exist nowhere on disk nor in git history; 87.37 ohm is
   reproduced by no width/gap/mask combination (file mask 85.3, Altium stock mask 91.1, substrate-only 87.9); "bit-for-bit
   unchanged on both stacks" has no surviving instrument. Absolute pair values carry +-5 ohm of mask-model spread.
8. `altium_microvia_facts.md`: "(74,1,0)" is wrong -- byte 30 = 32 (Bottom) on all 377 vias; the KiCad offsets hold.
9. u1_sites finding: its impedance table (z0.py) was grid-biased (1080 solved at an effective 0.090 mm); corrected 1080 shift on
   the pair -4.1 ohm (-4.7 %), not -2.1; 90-ohm width on 1080 0.118-0.128, not 0.140; 2116 +1.7 (aligned z0.py) / +2.5
   (impedance solvers).
10. u1_sites finding: "(b) reaches 16 ring-0 signal balls / 49 of 82" -> 0 ring-0 signal balls (the 16 are GND, VCC3V3 and
    no-net); (b) serves 33 ring-1 + 35 ring-2 = 68. Its "all 42 ring-0" under (a) is 40 (T1, U1 refused). Far ends 8/8/8, not
    8/9/7. Pads6 shape byte is 49, not 72 (all 238 lands circles; the rectangular-land uncertainty is dropped).
11. u1_sites recommendation "(c) 0.10/0.25 on a 1080-outer 2+2+2 as the nothing-waived baseline" is refuted by the impedance
    workflow: 1080 on L2-L3 drops the placed SDRAM bus to 45.2 ohm (0.086) / 43.1 (0.0784) and wants 0.105 / 0.092 mm on
    607.8 mm of placed copper; its hdi.json laser-to-mechanical 0.44 -> 0.39 (0.10/0.25) / 0.415 (0.15/0.30).
12. dfm_rules finding: "hdi.json = the exact tools/hdi.json content" -> the live file is still the through-only default
    (b05f58bb); its proposal (39a1f943) and now this one (dab6ffb3) are proposals. Its headline "zero margin" -> the placed
    different-net minimum is 0.2430 hole-edge; the 8 pairs at 0.2400 are same-net (JLC 0.13). Its 0.2411 interstitial figure is
    the first cell; the grid minimum is 0.2410.
13. impedance finding: the Cohn calibration numbers are not what its validate.py prints (K(k)/K(k') inverted); correct Cohn
    67.52 / 48.47 / 31.54, solvers within 1.8 %; the thick-copper microstrip cases rest on three-solver agreement, not on a closed
    form; "USB full-speed" -> U2 is an FT2232HL, USB 2.0 Hi-Speed (docs/zulu_a7-bom.csv line 44, in Zulu_A7/docs, not
    Zulu_Altrium/docs as memory says); "w = g has no solution on 1080" -> crosses 85.3 at about 0.115-0.120 (bracketing
    failure); N2-2116 SDRAM slot should be PP resin (50.39, +0.2); "every comparison is a delta under one model" -> one solver
    but two Dk sources (+1.4..+3.8 on the pair).
14. `tools/route_inputs.py EDGE_CLEARANCE = 0.25` is 0.025 short of JLC's 0.35 hole-edge for a 0.075-ring via (land-edge 0.275);
    harmless while the 0.80 convention binds. `tools/route_reach.py:197` (stage 9 correction 1) still bans the whole land field.
15. `tools/hdi.py`: `field_ban()` conflates via-in-pad with field permission, and `usable()` never proposes a stack -- both must
    change before any gate can use the 87 in-field sites.

## 15. Unmeasured, stated as such

The former negative-plane landing-pad and clearance-model questions are closed by the final signal-polygon Gerbers and
DRC. Still unmeasured: `IsBuriedVia`/`IsThruVia` in rule kinds not exercised by the final board; JLC's 6L 2-step layer
pairs, discrete laser sizes, foil-in-aspect reading, buried/lamination/copper-fill
fees, stack-review lead time; the 0.930 core's Dk; the pressed 2116 thickness; whether 1 oz inner really ships; the effect of the
L2 plane-web constraint on the 41-ball matching; JLC's laser position tolerance against the 0.9 um interstitial margin at
0.30 (the reason 0.27 is asked for).

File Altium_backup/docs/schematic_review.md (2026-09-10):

# Zulu A7 schematic review: readability, labelling and flow

Generated by `tools/schematic_review.py` from the seven `.SchDoc` files, so it sees what Altium sees rather than what the PDF renders. It covers the objective half of a review -- geometry and spelling. Where a question needs judgement rather than arithmetic, it says so and stops.

| Sheet | Title | Parts | Wires | Net labels | Power ports | Free text | Junctions |
|---|---|---:|---:|---:|---:|---:|---:|
| 0 | block diagram | 1 | 0 | 0 | 0 | 50 | 0 |
| 1 | power supplies | 32 | 81 | 6 | 30 | 7 | 29 |
| 2 | general IO | 76 | 121 | 88 | 2 | 5 | 13 |
| 3 | memory | 84 | 90 | 58 | 22 | 3 | 24 |
| 4 | FT2232HL, JTAG, clock | 46 | 149 | 61 | 29 | 1 | 55 |
| 5 | FPGA connections | 148 | 145 | 134 | 7 | 154 | 4 |
| 6 | FPGA power | 49 | 271 | 5 | 20 | 11 | 177 |

## 1. Labels and power ports that do not sit on a wire

A net label one unit off its wire names nothing at all, and the netlist gives no warning: the net simply is not called that. Pins carry their own hidden names, so a missed label can hide until the board is routed.

None. Every net label and power port lands on a wire.

## 2. Wire ends that touch nothing

An end that meets no pin, no other wire, no junction and no label is either a leftover or a connection that was never made. Ends that carry a label are listed separately: a labelled stub is a deliberate off-sheet connection, not a fault.

10 unlabelled loose ends, 272 ends that carry a label.

| Sheet | X | Y | Note |
|---|---:|---:|---|
| 1 | 735 | 207 | nothing within 1.5 units |
| 1 | 735 | 247 | nothing within 1.5 units |
| 1 | 740 | 377 | nothing within 1.5 units |
| 1 | 845 | 357 | nothing within 1.5 units |
| 4 | 197 | 852 | nothing within 1.5 units |
| 4 | 632 | 1027 | nothing within 1.5 units |
| 4 | 692 | 802 | nothing within 1.5 units |
| 6 | 606 | 557 | nothing within 1.5 units |
| 6 | 606 | 702 | nothing within 1.5 units |
| 6 | 606 | 872 | nothing within 1.5 units |

## 3. What grid the sheets are actually on

The sheet records say `SnapGridSize=10`, but the EAGLE importer placed parts on its own grid and Altium kept the coordinates. This matters for the redraw: a wire drawn on the declared grid will not meet a pin that sits between grid points, and the mismatch is why a hand edit here needs the snap turned off or reset first.

| Sheet | On 10 | On 5 (not 10) | Whole units | Fractional | Worst example |
|---|---:|---:|---:|---:|---|
| 0 | 0 | 0 | 1 | 0 | none |
| 1 | 17 | 9 | 6 | 0 | none |
| 2 | 0 | 0 | 76 | 0 | none |
| 3 | 0 | 0 | 84 | 0 | none |
| 4 | 0 | 0 | 45 | 1 | C40 at (304.557, 1087.756) |
| 5 | 0 | 0 | 148 | 0 | none |
| 6 | 0 | 0 | 44 | 5 | C141 at (86.000, 662.866) |

6 parts sit at fractional coordinates, in two clusters. C40 on sheet 4 is the FT2232H VPHY bypass, whose node the import left held together by three junctions and a 0.04-unit wire at three different sub-unit positions; that one is documented in `tools/sheet4_layout.py` and must be moved as a block, never rebuilt. The other five are FPGA bulk capacitors on sheet 6 sharing two fractional Y values (662.866 and 521.134), which is the signature of a row the importer scaled rather than placed. None of them is a fault in itself -- every one is wired correctly -- but each is a place where a hand edit on the snap grid will miss the pin it is aiming at.

## 4. Net names that differ only in case, separator or spacing

One net becoming two is usually a spelling accident, and the netlist cannot tell you: both names are valid. Names are folded to lower case with `-` and `_` removed, and anything that collides is listed.

None.

## 5. Labels against the exported netlist

The previous section asks whether names collide. This one asks the netlist whether each name actually became a net, and whether any net ended up with a single pad. A label whose text is not a net name did not name what its author thought; a one-pad net is a connection that was never completed.

The netlist holds 179 nets over 785 pads, against 167 distinct label and port texts on the sheets.

Every label and port text appears as a net name in the netlist.

No net has fewer than two pads.

## 6. How each part is named on the drawing

A multi-gate part shows its reference on one gate and hides it on the rest, which is right. What would matter is a part a reader cannot name at all. The EAGLE importer did not always use the designator object for this: on the biggest parts it left every designator hidden and put the reference in a visible parameter on the part-value gate instead. That prints the same and is not a fault, but it is worth knowing before anyone goes looking for the designator to move it.

183 placements carry a reference. 4 references are hidden on every one of their placements; of those, 0 are not written anywhere else on the sheet either.

| Sheet | Reference | Placements | Symbol | Named elsewhere on the sheet |
|---|---|---:|---|---|
| 2 | X2 | 41 | `ZULU-CONN` | yes, by a visible parameter or note |
| 3 | U3 | 55 | `SDRAM-X16-ALLIANCE-512M` | yes, by a visible parameter or note |
| 3 | U4 | 9 | `SPI_FLASH-SOIC_150_208` | yes, by a visible parameter or note |
| 5 | U1 | 139 | `XC7A35T-CPG236-1CPG236C` | yes, by a visible parameter or note |

Every part on every sheet can be named by a reader.

## 7. Text that lands on a wire

Approximate: a designator, comment or free-text anchor within half a character height of a wire it does not belong to. Altium draws text over wires without complaint, and it is the commonest reason a printed sheet is hard to read.

1 text anchors sit on a wire.

| Sheet | Text | X | Y | Belongs to |
|---|---|---:|---:|---|
| 6 | `VCCBRAM -- 1x0.47uF, 1x47uF ` | 151 | 822 | free text |

## 8. How much of the printed page the drawing gets

Measured off the exported PDF itself, with no assumption about what the sheet records mean: each page is 792 x 612 points, landscape letter, and the drawing on it is portrait. Nothing here is inferred from the schematic files.

| Page | Page size | Ink on it | Share of the page | Blank width |
|---|---|---|---:|---:|
| 0 | 792 x 612 | 456 x 602 | 57% | 42% |
| 1 | 792 x 612 | 453 x 602 | 56% | 43% |
| 2 | 792 x 612 | 477 x 602 | 59% | 40% |
| 3 | 792 x 612 | 477 x 602 | 59% | 40% |
| 4 | 792 x 612 | 460 x 602 | 57% | 42% |
| 5 | 792 x 612 | 490 x 602 | 61% | 38% |
| 6 | 792 x 612 | 463 x 602 | 58% | 41% |

Every page fits its drawing to the HEIGHT -- the ink is 602 points tall against a 612-point page -- and leaves 43 per cent of the width blank. Turn the page portrait and the same drawing has 792 points of height to fill instead of 612, which is about 1.3x linearly: every line and character a third bigger, no redrawing. It is a page-setup choice in the Smart PDF wizard, and it is the cheapest readability gain available on this schematic.

What I could NOT settle from the records: whether any content falls outside the sheet rectangle. The header gives `CustomX`/`CustomY` per sheet, and taken as a portrait rectangle those numbers reproduce the printed aspect exactly on every page -- but they also put thousands of objects on sheet 5 outside the sheet, while the rendered page shows the border comfortably enclosing all of them. Rather than pick a reading, it is left open: if sheet 5 ever prints clipped at the right, this is where to look.

## What the machine half found

Worth acting on before the board work:

- 10 wire ends touch nothing.
- the PDF prints portrait sheets on landscape pages, wasting ~40% of the width.

Worth knowing, not worth stopping for:

- 6 parts sit at fractional coordinates.
- 1 text anchors land on a wire.

For context on what a clean result here does and does not mean: this checks that labels land on wires, that names resolve to nets, that nothing dangles and that the page is used. It cannot see a sheet that is correct and still hard to read.

## 9. The half that needs eyes

Everything above is arithmetic. This half is judgement, and it was done by looking: seven reviewers,
one per sheet, each rendering its page in overlapping tiles at 320 dpi and higher and reading them,
with the `.SchDoc` records and the exported netlist beside them. They returned 127 findings, 48 of
them marked as things that could mislead a competent reader. A verification pass then re-rendered
the areas behind every "misleading" claim and tried to knock it down; nine did not survive, and the
five that matter are ranked below. This file is written by hand and is appended to the generated
document; re-running `tools/schematic_review.py` does not touch it.

**The headline, because the volume of findings hides it: the schematic is sound.** Every
connectivity claim in the review was checked against the project's own netlist and exactly one came
back as a real circuit defect. The nets are right, the pin map in the netlist is right, and the
board can be laid out from this schematic. What is wrong is presentation -- text placement inherited
from the EAGLE importer -- and documentation that was never regenerated after the FPGA re-pin and
the part substitutions. That second category is the dangerous one, because stale text looks
authoritative.

### The five that matter, in the order to fix them

**1. Sheet 5's ball annotations were stale on three rows in four. FIXED 2026-09-09.** Beside each
FPGA pin row is a grey `<ball>  <pin function>` caption. It named a ball that no longer carried that
row's net on 94 of 137 rows. Two independent methods agreed: matching each caption to the live pin
on its row gave 42 right and 94 wrong; cross-checking each caption against the exported netlist gave
34 right and 102 wrong. The failures were coherent, which is what made it certain -- `SD-DAT2`'s row
was captioned `W2`, a ball that really carries SDRAM-CS#; `CHAN0`'s said `W3`, which carries CAS#;
`CHAN2`'s said `W5`, which carries D5. It was the fingerprint of a pin reshuffle where the captions
were left behind.

Worst was the Pmod block, whose captions claimed balls A14, A15 and W7. Those three carry SDRAM D14,
D15 and D2. The real Pmod balls are U18, U19, G17, C17, T17, E19, V19 and U17.

`tools/sheet5_ball_captions.py` rewrote 99 captions from the pin each one annotates, taking the
function name from `Datasheet/xc7a35tcpg236pkg_pinout.txt` -- the same package file `bom_audit.py`
checks the power tree against, and the source the originals were copied from. 37 were already right.
One was left alone and reported: `C13  VCCADC`, whose row has no live pin for the tool to check it
against, and which is correct anyway. Re-running the netlist cross-check afterwards gives **128 agree,
0 disagree**, with 9 rows carrying no net label to check (the floating MGT balls).

STILL OPEN on the same block: the symbol's own pin NAMES still read `IO_A14`, `IO_A15` and `IO_W7`,
so the old assignment is still baked into the symbol even though the captions beside it are now
right. Those are library pin names, not sheet text, and changing them is a different job.

**2. `PGOOD` is two different things wearing one name, and one of them is a dead net.** The netlist
gives `PGOOD = {Q2-G, R77-1}` with R77's other end on VCC3V3. Nothing can pull Q2's gate down, so Q2
is permanently on and LD5 lights whenever 3.3 V is present. The bq24232's actual PGOOD output, U8
pin 7, is on a different net entirely -- the auto-named `NetLD3_K`, with LD3's cathode. The drawing
shows a pin called PGOOD at the top left and a wire called PGOOD at the bottom right whose left end
dangles in mid-air, as though the signal arrives from somewhere.

This is a leftover from the LTC3569 era: that part had a power-good output, the three SC189s that
replaced it do not, and R77 was left pulling the gate high. Electrically LD5 works -- it is a
power-ON indicator. The name is what misleads, and Q2 with R77 and R78 is three parts doing a
resistor's job.

*Fix:* a decision, then two or three objects. If LD5 is meant to be a 3V3-present indicator, delete
Q2 and R77 and run VCC3V3 - R78 - LD5 - GND, and rename the net. If it is meant to follow the
charger, wire it to U8 pin 7 and drop the duplicate name. **Not actioned: this is a design choice.**

**3. Every net label hung below its wire while every pin number sat above its own. FIXED
2026-09-09.** The labels were `Justification=8` -- anchored at the top of the text box -- so although
the anchor sat exactly on the wire, the glyphs were drawn underneath it, while pin designators are
anchored at the bottom and sit above theirs. Rows are 10 units apart and the text is about 6.8 units
tall, which put every net name on the NEXT pin's line.

Measured on the PDF before: on sheet 2 the label `CHAN0` -- X2 pin 3 -- had its glyph box at y
100.88..104.00 while the digit 4 sat at 101.60..104.72, a 2.4 point overlap of a 3.1 point box; its
own digit 3 was above at 97.29..100.40. Reading across a row to find which pin a signal is on, which
is exactly what the 40-pin footprint work needs, gave the wrong answer. On the Pmod the pin name
inside the symbol did not save you either: pin 11's `GND` landed on the `PMOD-10` line.

`tools/label_justification.py` subtracted 6 from the justification of every horizontal net label that
had a top value (6 -> 0, 7 -> 1, 8 -> 2), which moves the anchor to the bottom of the box and leaves
the horizontal half alone: 254 labels over sheets 1 to 5. Measured on the PDF after, `CHAN0` is at y
97.29..100.40 -- character for character the same box as its own digit 3. Nothing moved
electrically; a label's Location is its attachment point and was not touched, and the netlist came
back with the same 178 nets over 783 pads.

The 117 labels that were already bottom-anchored are why this was worth doing at all: the sheets were
inconsistent with themselves, so a reader could not learn one rule and trust it.

STILL OPEN: eight ROTATED labels that are also top-anchored (two on sheet 1, three on sheet 4, three
on sheet 5). For a label at 90 degrees the vertical half of the justification moves the glyphs
sideways rather than up, so the same flip is not obviously right and eight is few enough to judge by
eye. `tools/label_justification.py` lists them every time it runs.

**4. Five things the block diagram said that were not true. FIXED 2026-09-09.** Three were the
factual errors ranked here, and checking the sheet to fix them turned up two more of the same kind.

`CHAN-I/O (28)` should have been 29: the netlist holds CHAN0 through CHAN28, and the sheet has
already taught the reader that a number in brackets is a bus width via `CTRL (7)`, `ADDRESS (15)` and
`DATA (16)`, all three correct. 28 was a trap because it is also the highest channel number, so it
survives a spot-check.

`SDRAM-CLK` was drawn leaving the FPGA at (460,612), running down to y 542, jogging right to x 480
and coming back UP into an arrowhead at (480,612) pointing into the FPGA, while the main line
continued down into the SDRAM. It read as a clock the FPGA sends out and gets back; the net is
exactly two pads, U1-M1 and U3-38. The return branch and its arrowhead are gone, leaving one line
with one arrowhead, drawn the way CTRL and ADDRESS beside it are.

The microSD note claimed six bank-34 balls. It spans three: CLK U8 and CMD U7 in bank 34, DAT0 C15,
DAT1 B15 and DAT3 A16 in 16, DAT2 L3 in 35 -- confirmed against the package file and the pin
designators on sheet 5. The note now says so, and keeps the claim that actually matters, which is
that a card cannot reach the config bus.

Found while fixing those: the `XADC` link was drawn with an arrowhead at BOTH ends, i.e.
bidirectional, when X2-39 and X2-40 feed the XADC through dividers and nothing comes back. The
header-end arrowhead is gone and the line now runs flat to the header, which is the shape this sheet
already uses for one-way links. And the `LED/Button` link had a single arrowhead pointing INTO the
FPGA, which on this sheet's convention means the FPGA only receives -- but LED0_R (P19), LED0_G
(R18), LED0_B (N19), LED1 (N18) and LED2 (M19) are FPGA outputs and only BTN (N17) is an input. An
arrowhead into the block has been added, so it now reads bidirectional.

CHECKED AND LEFT ALONE: the review also said the Pmod link was drawn with a single arrowhead into
the FPGA. It already had one at each end -- into the FPGA at (615,722) and up into the block at
(720,787) -- so that claim was wrong and the link was correct as drawn.

`tools/sheet0_fixes.py` does all five: ten line records deleted, two added, two text edits. Sheet 0
is the sheet that was left unopenable once by deleting records without renumbering OwnerIndex, so
the script renumbers and rewrites the header count, and the first thing done after applying it was
to open sheet 0 in Altium and watch it draw.

STILL NOT CHANGED on this sheet, because they are naming style rather than error: the rail nicknames
+5V, +3.3V, +1.8V and +1.0V, which are not the net names (USB5V0, VCC3V3, VCC1V8, VCC1V0); the flash
link labels FCS_B, CCLK and DQ[3:0], which are pin names where the neighbouring SD-CLK, SD-CMD and
SD-DAT[3:0] are net names; the 12 MHz oscillator drawn as a two-terminal passive when Q1 is an
active four-pad part; and the absence of designators on the blocks.

**5. GND and VCC drawn as bare red text instead of power ports. FIXED 2026-09-09.** On sheets 1, 3,
4, 5 and 6 the supply and ground connections were plain net labels sitting on a wire rather than port
symbols. Sheet 3 was the extreme: 24 rail labels and not one power port on the whole page.

Three places where it made a correct netlist read as a wrong circuit, and all three are now redrawn:

*Sheet 3's seven-row U3 decoupling ladder* rendered as an unbroken line, `pin 54 -GND- ||C3||
-VCC3V3- pin 1`, seven times. Every row was right -- each cap bridges one supply ball to the ground
ball opposite it -- but nothing on the row said which half was ground except two words of 8-point
text. A named ground bar is 30 units tall and the rows were 30 units apart, so there was physically
nowhere to put one: the GND text would have finished 0.5 units above the next row's wire. The pitch
is now 45 (the ladder had 145 units of headroom before U3's body; the new top row uses 90 of it), the
two labels moved to the middle of the segments they name, and each row now reads ground symbol, cap,
supply arrow.

*Sheet 6's bulk column* stacked three cap banks 70 units apart when a bank needs about 99 from the
top of a supply arrow's name to the bottom of a ground bar's, so each ground bar was drawn straight
through the next bank's supply label -- `GND` at x 22..88 across `VCC1V8` at 65..145 on the same
line. The column is boxed in by C86/C92 above and U1C below, 315 units, which holds two banks and not
three, so the VCC3V3 bank moved out into the empty band beside U1C and the VCC1V8 bank dropped 40
into the space it left. Three banks, three supply arrows, three ground symbols, nothing touching.

*Sheet 4's oscillator*: the `VCC3V3` naming C38's top plate sat on a stub that ran LEFT out of its
junction, right-justified, so Q1's pin-2 ground drop went through its glyphs 3 points above the
ground symbol -- it read as VDD grounded. The stub now runs down instead, into clear space between
the ground bar and C38's designator.

`tools/rail_layout.py` makes that room; `tools/rail_ports.py` then rewrites each label in place as a
RECORD=17 port -- same index, same UniqueID, same location -- choosing Style 4 for GND and GNDADC and
Style 2 for the seven supplies, and choosing which way the symbol points by reading the wire
directions at the point and then testing the symbol's own footprint against every drawn object on the
sheet. 55 labels became ports and 31 junctions were added at mid-wire taps. Sheet 3 went from 0 ports
to 22.

34 labels are still labels, and that is the tool working rather than failing: they are rows of a
connector or FPGA pin list on a 10-unit pitch, where a 30-unit ground symbol cannot go and the word
GND in a column of row labels is the clearer drawing anyway. It is also why sheet 2 was never in the
run -- almost all of its rail names are ZULU-CONN rows. Each one that keeps its label is printed with
the reason every time the tool runs.

WHAT THE NETLIST CAUGHT, and the reason to export it rather than trust the drawing: the first run
lost two nets. A net label does not have to touch its wire -- Altium associates it with the wire it
is nearest -- but a port has one electrical hot point and must land ON the conductor, and two sheet-6
wires sit at y 682.866 and 612.134 (`Y1_Frac=86600`). Ports written at whole units missed them by
0.866 and 0.134 of a unit, and because those two cap banks are islands whose only tie to their rail
was that one name, they fell off as `NetC141_1` and `NetC145_1`. `tools/snap_ports.py` now projects
every port and junction onto the exact wire, `_Frac` included; 4 of 396 needed it. This is the same
sub-unit trap the C40 cluster on sheet 4 sprang once already. After the fix the exported netlist is
identical to the one before any of this work: 183 components, 178 nets, 783 pads, every net the same
set of pads.

**7. Text printed on top of other text, on five sheets. FIXED 2026-09-10.** Not one of the original
findings either; it came out of checking that the rail-port work had not made anything worse.

Counting glyph boxes in the exported PDF gives 12409 overlapping pairs, which is nonsense: Altium
writes three invisible metadata layers into the PDF, `COxxx` per component, `PIxxx` per pin and
`NLxxx` per net, each sitting exactly on the visible text it describes. Filter those, and ignore a
parameter drawn twice at one spot the way the title block does it, and 40 real collisions are left --
5 on sheet 1, 5 on sheet 2, 4 on sheet 3, 13 on sheet 4 and 13 on sheet 5, with sheets 0 and 6 clean.

The worst were two labels drawn on top of each other. Sheet 4 carried two `FT-RESETN` labels on one
wire, at 302 left justified and 343 right justified, so both sets of glyphs landed on x 300..345; the
same for `FT-REF`. The net keeps its name from the survivor and the duplicate goes. Everything else
is a nudge: `tools/text_overlaps.py` takes the geometry from the PDF, because a pin's name and number
are drawn by the pin and are not records at all, matches each span back to the record that drew it,
and searches candidate positions until one hits nothing. A net label may only slide along the wire it
names; a gate pin name only along its own row and only away from its pin; a port not at all unless
nothing else can move, and then only on its own wire. Pins never move.

Two things were caught by checking rather than by looking. `UART_FT_RXD` slid 30 units up its stub,
past R94, and landed on the VCC3V3 rail -- which would have named the rail UART_FT_RXD. Sliding is
now confined to one connected wire run. And the last stubborn overlap was one this project had made
itself: `rail_ports.py` had pointed a ground symbol on sheet 3 RIGHT, because down was blocked at the
time, and its name landed on R6's pin number; the fix was to turn it down, not to move it.

40 down to 0 on all seven sheets, with the netlist identical at 182 components, 179 nets and 785 pads.

**6. Sheet 5's right-hand blocks were drawn through the frame. FIXED 2026-09-09.** Not one of the
original findings -- it came from reading the exported PDF. 25 objects crossed the inner border at
x 1020 and ran off the printed page: `MGTREFCLK0P/0N/1P/1N` by 34.6 units, `UART_CTS/RTS/DTR` by
31.7, `MGTPTXP0/N0/P1` and `MGTPTXN1` and `UART_TXD/RXD` by 21.7, the six `IO_A1x/B15/C15/W19` names
by 13.2, `IO_N2` and `IO_W7` by 8.9, and four `GNDADC` net labels by 2.5. 21 of them are the gate pin
names -- RECORD=41 parameters drawn just right of the pin, which is where this symbol puts its pin
names on every block of the sheet.

A row of those blocks is caption, net label, wire, pin, pin name: 165 units end to end with the
border 165 units away, so it fits only if the whole row moves left. Two of the five blocks had
nowhere to go -- the SDRAM block's pin names end at x 830.3 and the Pmod captions begin at 843.6 --
so the SDRAM block moved too; it had 71.8 units of clear space to its own left. Six blocks now sit 40
units further left, translated rigidly, and nothing on the sheet reaches the border.

Measured two ways that agree to 0.3 units over an 11-character string: from the PDF, and from the
records using a Courier advance of 0.535 * FontSize schematic units calibrated against it. That
metric is what let `rail_ports.py` decide where a power port would fit.

### What did not survive checking

Nine "misleading" findings were knocked down, and they are listed because a review that reports only
its hits cannot be trusted:

- Sheet 3, C11 printed over the `FLASH-D03` label: re-rendered at 1100 dpi, the plates stop above
  the text and the label is fully legible.
- Sheet 3, the R34/R35 array reading off by one: in that block the label and the pin number are both
  above the wire, so they pair correctly. The U3 half of the same finding is confirmed.
- Sheet 3, the offset "flipping mid-symbol" so a reader carries the wrong rule across: U3's right
  column reads correctly on its own terms. The left column alone justifies the fix.
- Sheet 0, XADC drawn bidirectional "against the sheet's own convention": the fact survives, the
  reasoning does not -- CHAN-CLK one row below is drawn the same way.
- Sheet 1, C78's ground symbol appearing to sit on the battery-positive net: it is 10 pt clear. The
  X1 instance of the same finding is real.
- Sheet 1, the rotated GND pin name destroying the SC189 suffix: the overprint is real but it
  strikes the "18", not the Z/L/A that carries the meaning.
- Sheet 1, R102-R106 values misreading at ordinary scale: the overprint is real, the misreading is
  not demonstrated.

And one correction to this document's own machine half, which claimed on its first run that U1, U3,
U4 and X2 are never named on the drawing. Their designators are indeed hidden on every placement,
but the importer put the reference in a visible parameter instead, so the drawing reads correctly.

### Where this leaves the ZULU-DIP37 redraw

Nothing blocks it, and the two findings that touched it are now fixed. Sheet 2, the sheet the
footprint is drawn from, no longer pairs each net name with the next pin's number; sheet 5, where
the ball assignments get read, no longer names the wrong ball on three rows in four. Both were fixed
before the redraw rather than after precisely because a footprint drawn against a misread row is
expensive to find later.

What is left for the redraw to work around: the symbol pin names `IO_A14`, `IO_A15` and `IO_W7` on
the Pmod block, which still carry an assignment the board no longer has.

Four of the five ranked findings are now fixed -- the ball captions, the label justification, the
block diagram, and the bare GND and VCC text -- along with the sheet-5 blocks that were drawn through
the frame. What remains is finding 2, the `PGOOD` name and its vestigial Q2/R77/R78 driver, which is
a design decision rather than a drawing fault and is the user's to make.

Every one of those changes was checked the same way: the project's own netlist exported from Altium
before and after, and required to come back with the same 183 components, 178 nets and 783 pads, with
every net holding the same set of pads. It caught a real break once, which is the only reason to keep
doing it.

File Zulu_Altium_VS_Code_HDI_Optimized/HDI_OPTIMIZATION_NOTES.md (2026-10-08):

# Zulu A7 conservative HDI optimization

## Scope

This is an isolated, same-outline derivative of the fully routed Zulu A7
production board. The production board was not edited.

The optimization is deliberately conservative:

- No components were moved.
- No nets, track widths, layer assignments, keepouts, or board-outline
  geometry were changed.
- Thirteen existing HDI transition sites were replaced by genuine mechanical
  through vias using the existing 0.35 mm land / 0.20 mm drill rule.
- L2-GND and L5-VCC3V3 polygons were repoured in Altium so they clear the new
  through vias.
- `ZULU A7` was added to Top Overlay at X=6.0 mm, Y=20.0 mm using 2.0 mm
  stroke text with a 0.25 mm stroke width.
- X1-MS1 and X1-MS2 were corrected from 0.60 mm round holes to the Molex
  105017-0001 requirement: plated 0.60 mm x 1.30 mm vertical slots.
- A short CHAN12 corridor and its two stacked vias were moved locally to clear
  the corrected X1 slot. Net, width, layers, and total track/via counts remain
  unchanged.
- The `HoleSize_X1` rule permits the 1.30 mm X1 slot length without weakening
  the global hole-size rule, and the X1 designator was moved clear of solder
  mask.
- Later on 2026-10-07 the MS1/MS2 lands and slot clearances were brought to
  PCBWay's "normal" class, matching the production board's fix. CHAN12 was
  re-routed around the slots. See "X1 lands and clearances" below.
- Also on 2026-10-07, at the user's request, X2's supply pins were re-ordered:
  17 GND, 18 VCC3V3, 19 VCC1V8, 20 VCC1V0 (was 17 VCC3V3, 18 VCC1V8,
  19 VCC1V0, 20 GND). See "X2 power pins" below.
- Then X2's pin numbers and short names went onto the top silkscreen for the
  33 pins with room. To make room, the U2 designator moved, and the `ZULU A7`
  title moved to free space at 1.6 mm. See "X2 pin labels" below.

This remains an HDI board. It is not the full placement/layer-function/reroute
redesign that would be required to approach zero buried vias, and it does not
make the design eligible for JLCPCB assembly.

## Files and fingerprints

| Item | SHA-256 |
|---|---|
| Historical production source used for the optimization | `72E9A716E03616D9464C0040A7B1187561E740C551104720DD288EA147B4E30B` |
| Production `zulu_a7.PcbDoc` when the X1 slot correction was made here, not written by it | `181B1A8CC47D591023BFB5E683A1D7FC3F66063C18EC0D94D65964AD3BB25504` |
| Production `zulu_a7.PcbDoc` after its own X1 slot and land fixes (never written from this copy) | `4F73E1A215A21D19623C0956719072AEAA8C6B258501A21DE8923BFFF705F688` |
| Production `zulu_a7.PcbDoc` after the X2 power-pin re-order | `517B553E53D2148F2704600BB90345A12782C01B58199DC36E62376971A67054` |
| Production `zulu_a7.PcbDoc` after the X2 pin labels | `BD7CBFD775B741521D8AB8AC197FF58D2A7674C2757522FA4702CB32F46489C2` |
| Production `zulu_a7.PcbDoc` now, after the BTN move | `89A421B9060195D66BED82F7A4E7D80121BD0E9D679A3FEE32289E8F541F4BDE` |
| Via-only intermediate, before Altium repour | `FB9CE613BED4512F1B3B67D9AB6BFB29A3CFA007ED5AE46BBEAC22C5E7F620C7` |
| Optimized board, 2026-10-04 (History `~(2)`) | `60294BF7E6B159569DF3BF40E12B51081653BCD40C5434E55782723CB1B5F80B` |
| Board just before the X1 slot correction (History `~(5)`, 2026-10-06) | `52E8438F649E04845077D82DEA01D3EB8FE0A85B03D1F2F668040158DBF87F8A` |
| After the X1 slot correction, round 0.90 mm lands (History `~(8)`); superseded | `5E885D522F27F39FE3042062336B2A9D71FBCC85A11B77017C1D22DBD5F929C8` |
| After the X1 land fix (slots plus PCBWay lands and clearances); superseded | `0CFFBF05E98EB0DCA85336350EE6244E748E4679B6C28E9545B0198F8F05D6C5` |
| After the X2 power-pin re-order; superseded | `71E75C10890AF834F98ECEB9E10981AA1AD6301A51087FBB7A328B4E49486D6E` |
| After the X2 pin labels; superseded | `A3436176F03BD3E7195F777322BC68DA107D3A8AB82A80259D8F1A6A5AAC6A4E` |
| Final `zulu_a7_hdi_optimized.PcbDoc`, after the BTN move | `F97D0F4D6FB9439ADDF64BD6DA2620E2BF3D35228E0CC4B053859F38BDB5E64B` |

The production board hash was rechecked after the isolated X1 slot correction
and was still `181B...`; only the optimized derivative was written. The
production board has since had its own fixes (`4F73...`, then `517B...`, then
`BD7C...`, then `89A4...`).

`~(2)` is not the board immediately before the slot correction. Between them,
History `~(3)` (2026-10-05) moved the X1 designator, and `~(4)` (2026-10-06)
moved the X3, U1, JP3 and JP4 designators; autoposition was cleared on all
five. `~(5)` is geometrically equal to `~(4)`. The slot correction first
appears in `~(6)` (2026-10-07 04:27).

## Board and routing invariants

- Outline: 69.85 mm x 25.40 mm, unchanged.
- Layer stack: JLC06161H-3313E, unchanged.
- Signal tracks: 4,200 (4,828 track objects in all). The land fix changed four
  CHAN12 tracks and added four; the slot correction before it only moved CHAN12
  endpoints. The BTN move added three: 4,203 (4,831).
- Physical via locations: 1,081, unchanged.
- Via objects: 1,768, unchanged by the X1 correction; 1,771 after the BTN move.
- X1 slot centers: (29.5199, 23.9585) mm and (36.5201, 23.9585) mm.
- X1 slot geometry: plated 0.60 mm x 1.30 mm, vertical.
- X1-MS1/MS2 lands: 1.11 x 1.81 mm oblong on Top and Bottom, 0.90 x 1.60 mm on
  L2-L5.
- Pad centers, pad nets, net classes, keepouts, and outline match the
  pre-correction optimized model.

## Via census

| Via type/span | Production | Optimized | Change |
|---|---:|---:|---:|
| Top-Bottom through | 380 | 393 | +13 |
| Top-L2 microvia | 296 | 291 | -5 |
| L2-L3 microvia | 282 | 278 | -4 |
| L3-L4 buried | 369 | 362 | -7 |
| L4-L5 microvia | 230 | 222 | -8 |
| L5-Bottom microvia | 230 | 222 | -8 |
| Total via objects | 1,787 | 1,768 | -19 |

Laser-microvia records fell from 1,038 to 1,013. Physical HDI sites fell from
701 to 688. The BTN move (below) later added one Top-L5 stack and removed one through
via: 1,016 records, 689 sites.

## Converted sites

| Net | X (mm) | Y (mm) |
|---|---:|---:|
| CHAN19 | 53.2 | 23.5 |
| CHAN23 | 36.3 | 7.1 |
| CHAN25 | 47.9 | 2.0 |
| CHAN27 | 38.825 | 4.075 |
| CHAN28 | 16.5 | 6.0 |
| CHAN7 | 49.4 | 13.45 |
| CHAN9 | 49.4 | 12.4 |
| CLK-12M-FT | 61.1 | 13.0 |
| EE-CLK | 24.4 | 20.0 |
| GND | 45.9 | 11.8999 |
| JA1 | 61.35 | 6.2 |
| PMOD-4 | 63.5 | 9.9 |
| TDI | 62.75 | 12.7 |

## Validation

The final saved board passed:

- Altium full Design Rule Check: 0 warnings, 0 rule violations.
- X1-MS1/MS2: exactly two plated 0.60 mm x 1.30 mm vertical slots.
- Fresh NC Drill output: exactly two 0.60 mm G85 slot records, each using a
  0.70 mm route centerline for 1.30 mm overall length.
- Top-Bottom round-hole output: 393 x 0.20 mm vias, 2 x 0.85 mm X1 holes,
  and 58 x 1.016 mm component holes.
- CHAN12 stacked vias: two records at (37.45, 24.40) mm (at (35.80, 23.35) mm
  after the slot correction, before the land fix).
- X1 designator: (37.442, 22.250) mm.
- Top Overlay title: one `ZULU A7` record at X=6.0 mm, Y=20.0 mm,
  2.0 mm height, 0.25 mm stroke, and 0 degree rotation.
- Refreshed Top Overlay Gerber: title stroke aperture and coordinates verified.
- Clearance: 0.
- Short-circuit: 0.
- Un-routed net: 0.
- Net antennae: 0.
- Hole size: 0.
- Hole-to-hole clearance: 0.
- Modified polygon: 0.
- Saved-file geometry comparison: 4,196 tracks and 1,768 via objects, with
  no missing or extra objects (4,200 tracks after the land fix).
- Stack verification: all V9, V8, legacy, plane, and via-type checks passed.
- Microvia metadata: all 1,013 remaining laser-via records verified.
- Signal connectivity: all 174 routed non-plane signal nets joined.
- GND plane ties: 206/206 SMD pads tied.
- VCC3V3 plane ties: 129/129 SMD pads tied.

The signal-only island checker reports VCC3V3 as split because it does not
model the full-board L5 polygon as routed copper. The independent VCC3V3 plane
tie check is the authoritative result and passes 129/129.

The final reports are:

- `Imported zulu_a7.PrjPcb/Project Outputs for zulu_a7_hdi_optimized/Design Rule Check - zulu_a7_hdi_optimized.html`
- `Imported zulu_a7.PrjPcb/Project Outputs for zulu_a7_hdi_optimized/Design Rule Check - zulu_a7_hdi_optimized.drc`

## Reproduction

1. Start from a byte-identical copy of the production board whose SHA-256 is
   the guarded value above.
2. Run `tools/apply_through_via_optimization.py`.
3. Open `zulu_a7_hdi_optimized.PrjPcb` in Altium Designer.
4. Repour all polygons.
5. Run `tools/AddZuluTitle.pas` with the optimized PcbDoc focused.
6. Run `tools/CorrectX1Slots.pas` procedures `CorrectX1Slots`,
   `ResolveX1SlotClearances`, and `RefineX1SlotClearances` in that order.
   This file was reconstructed after the board was saved: run on History
   `~(6)` it reproduces the saved geometry, but it is not byte-for-byte the code
   that ran.
7. Run the full Design Rule Check.
8. Require 0 warnings and 0 rule violations, then save the optimized PCB.
9. Apply the land fix: `tools/HdiX1Pads.pas` (`HdiX1Canary`, then `FixHdiX1`,
   then `AddX1Rules`) and `tools/HdiX1Rules.pas` (`FixX1RuleScope`), each
   loaded as its own `.PrjScr`. Then save, close and reopen the board, repour
   all polygons, run the DRC and save again.
10. Re-order X2's supply pins: run `Zulu_Altium_VS_Code/tools/x2_power_pins.py`
    on this copy's `zulu_a7_2.SchDoc`, then `tools/X2PowerPins.pas`
    (`X2PinsCanary`, then `FixX2PowerPins`) on the board. Save, close and
    reopen, repour, run the DRC, import the X2 NOTE change only (untick the
    ten net-class removals and the USB pair), and save again.
11. Add the X2 pin labels with `tools/X2PinLabels.pas` (`X2LabelsCanary`, then
    `PlaceX2LabelsHdi`), run the DRC and save.

The optimizer uses `altium-monkey==2026.6.9` and refuses an input board whose
source hash or planned via-span multiset does not match the verified baseline.
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

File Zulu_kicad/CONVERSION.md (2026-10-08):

# Zulu A7: Altium to KiCad 10 conversion (2026-10-06)

Source: `Zulu_Altium_VS_Code/Imported zulu_a7.PrjPcb` working copy (includes the
uncommitted HDI stack), imported with KiCad 10.0.5 *Import Non-KiCad Project > Altium*.

Open `kicad_project/zulu_a7.kicad_pro`.

## What was fixed after the import (tools/, in run order)

| Step | Script | Why |
|---|---|---|
| 1 | `fix_hierarchy.py` | Altium project is Flat (HierarchyMode=0): net labels are project-wide, but KiCad imported them as sheet-local, which broke every cross-sheet net. All 351 labels are now global labels. KiCad 10 also imported the 7 sheets as 7 top-level sheets, which kicad-cli could not read. They now sit under a classic root sheet (`zulu_a7.kicad_sch`; old page 1 is `zulu_a7_0.kicad_sch`). The 119 `#PWR?` symbols are annotated. |
| 2 | `link_board.py` | Footprints were not linked to symbols (178 parity errors). Each footprint now has its symbol path, and `zulu_a7.pretty` holds the 32 footprints as placed on the board. |
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

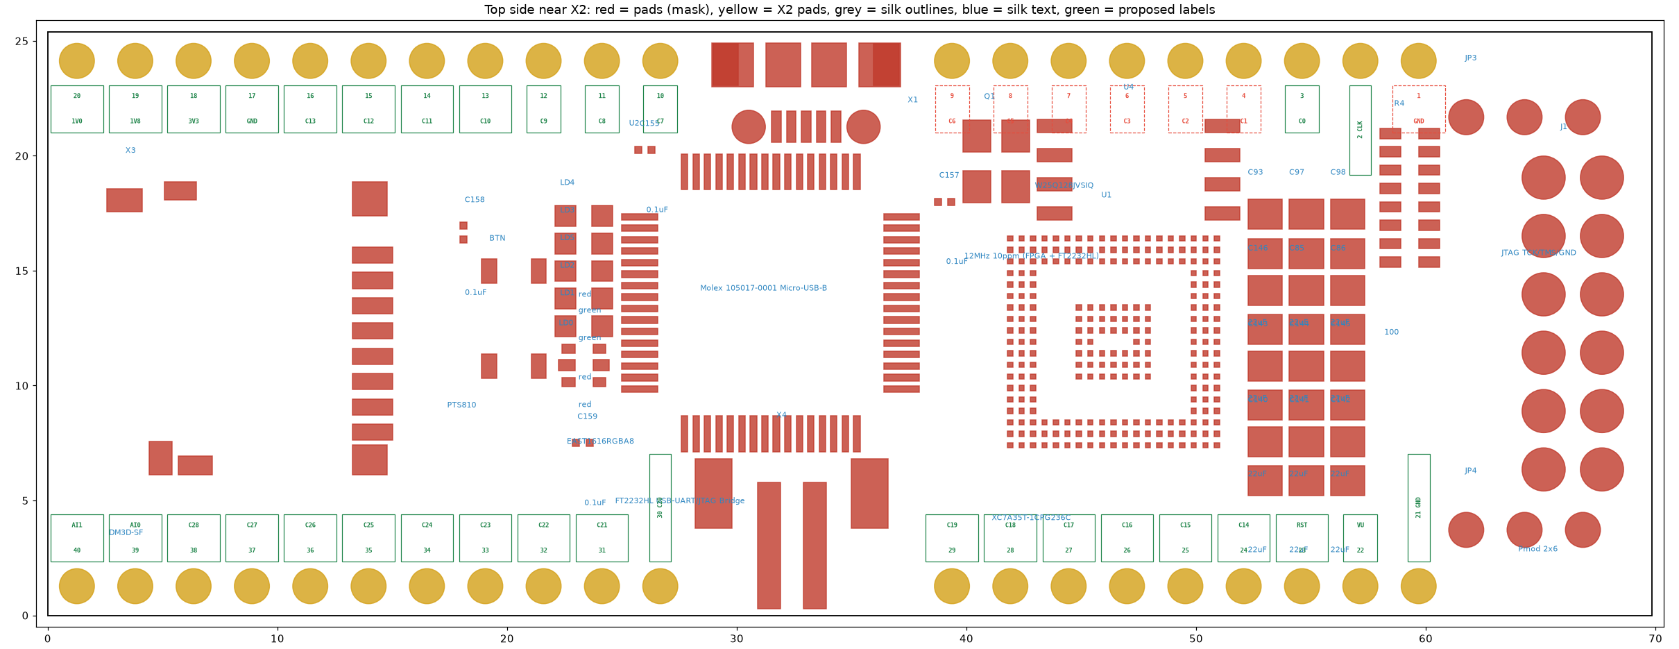
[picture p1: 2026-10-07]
Zulu_Altrium/x2_label_proposal.png

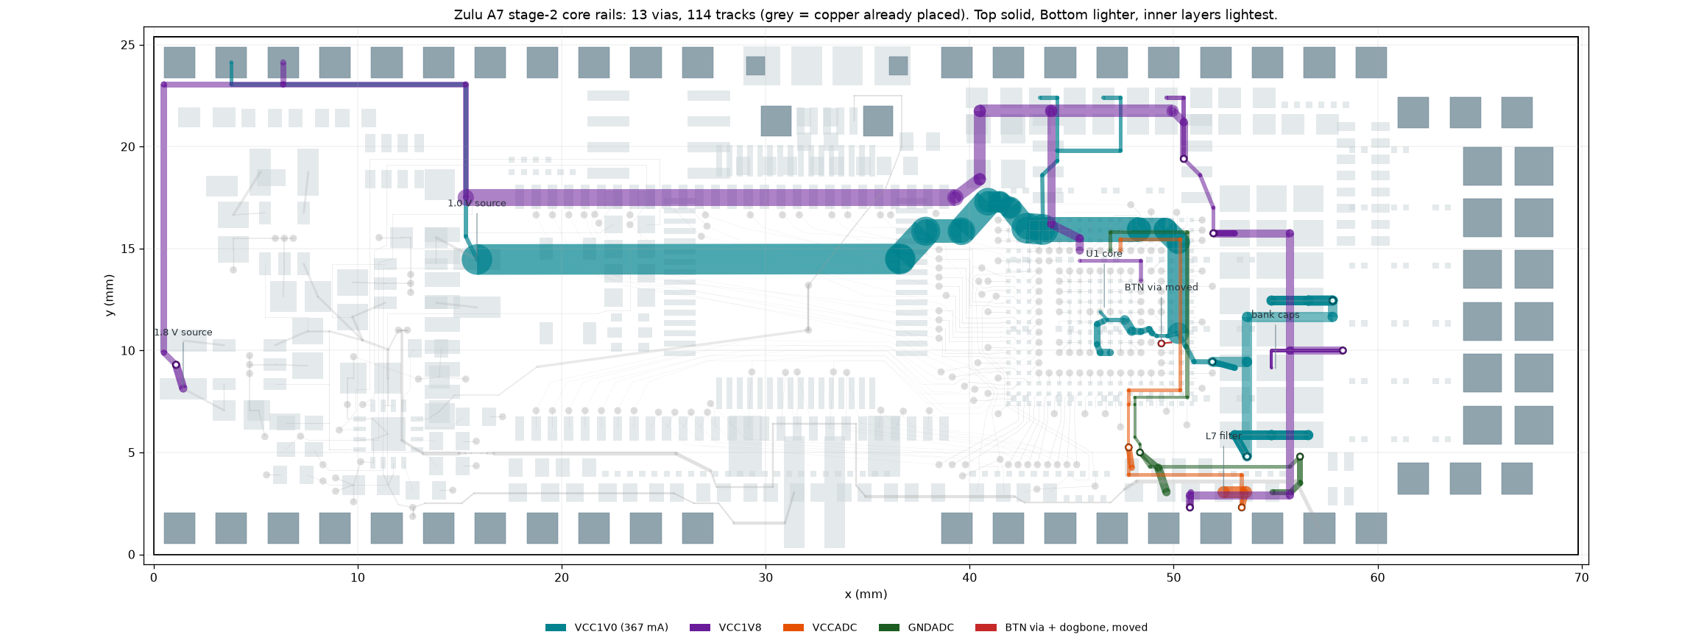
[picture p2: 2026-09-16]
Altium_backup/docs/stage2_rails.png

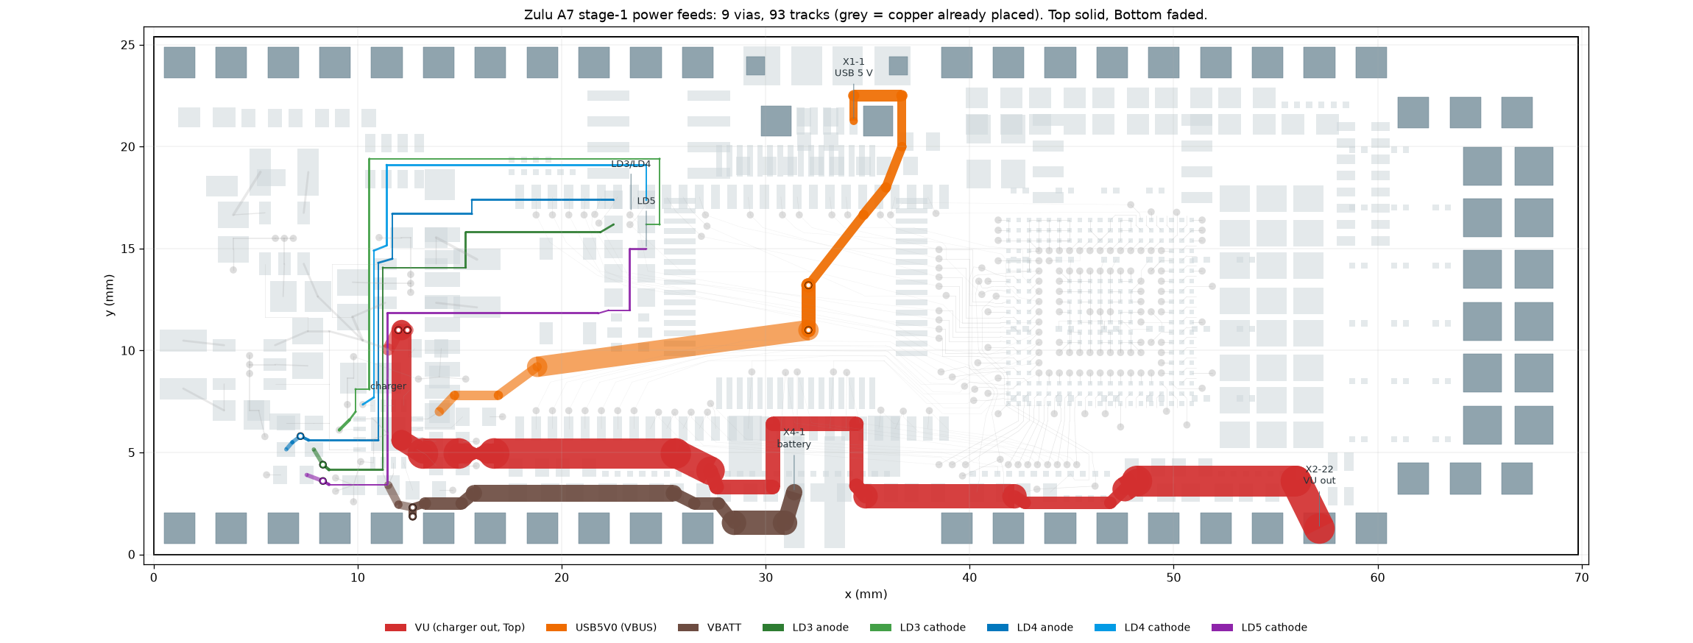
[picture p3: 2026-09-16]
Altium_backup/docs/stage1_feeds.png

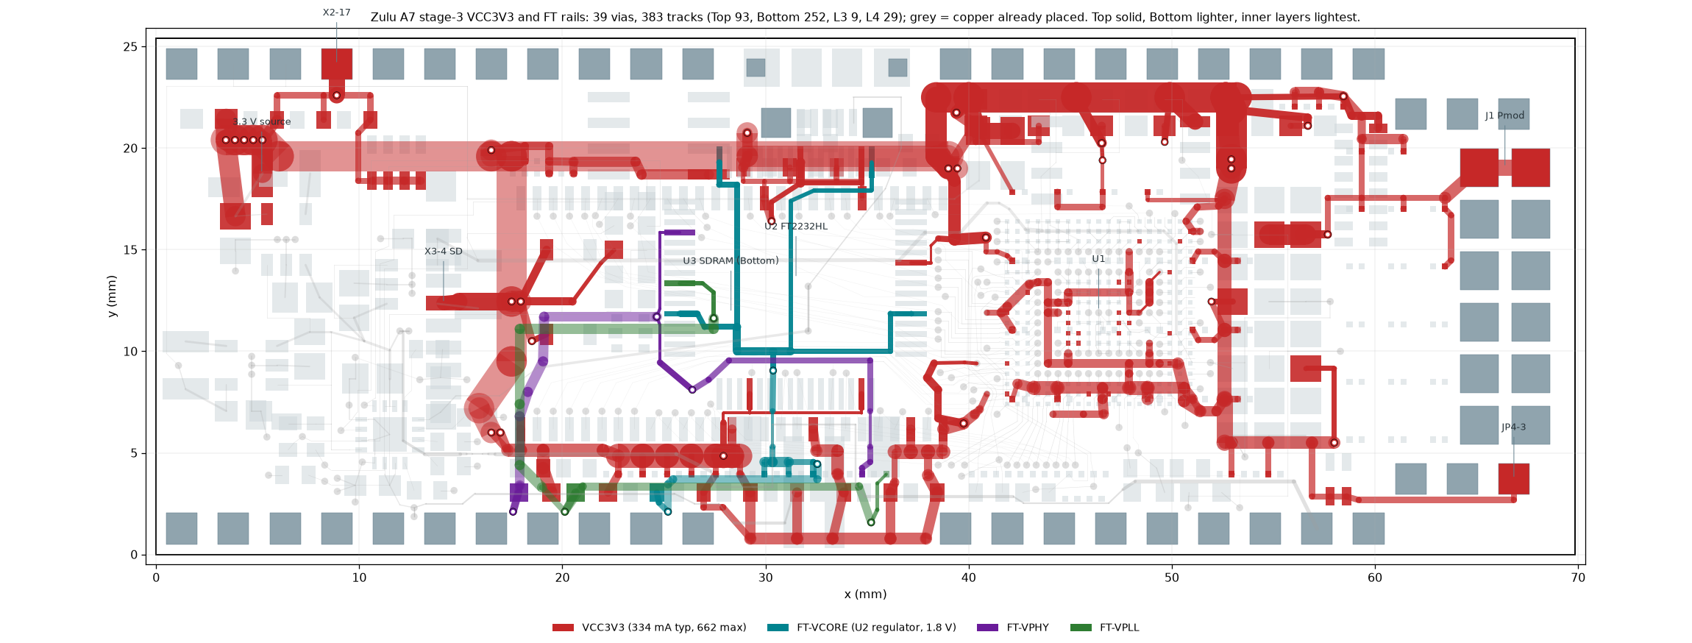
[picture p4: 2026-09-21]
Altium_backup/docs/stage3_vcc3v3.png

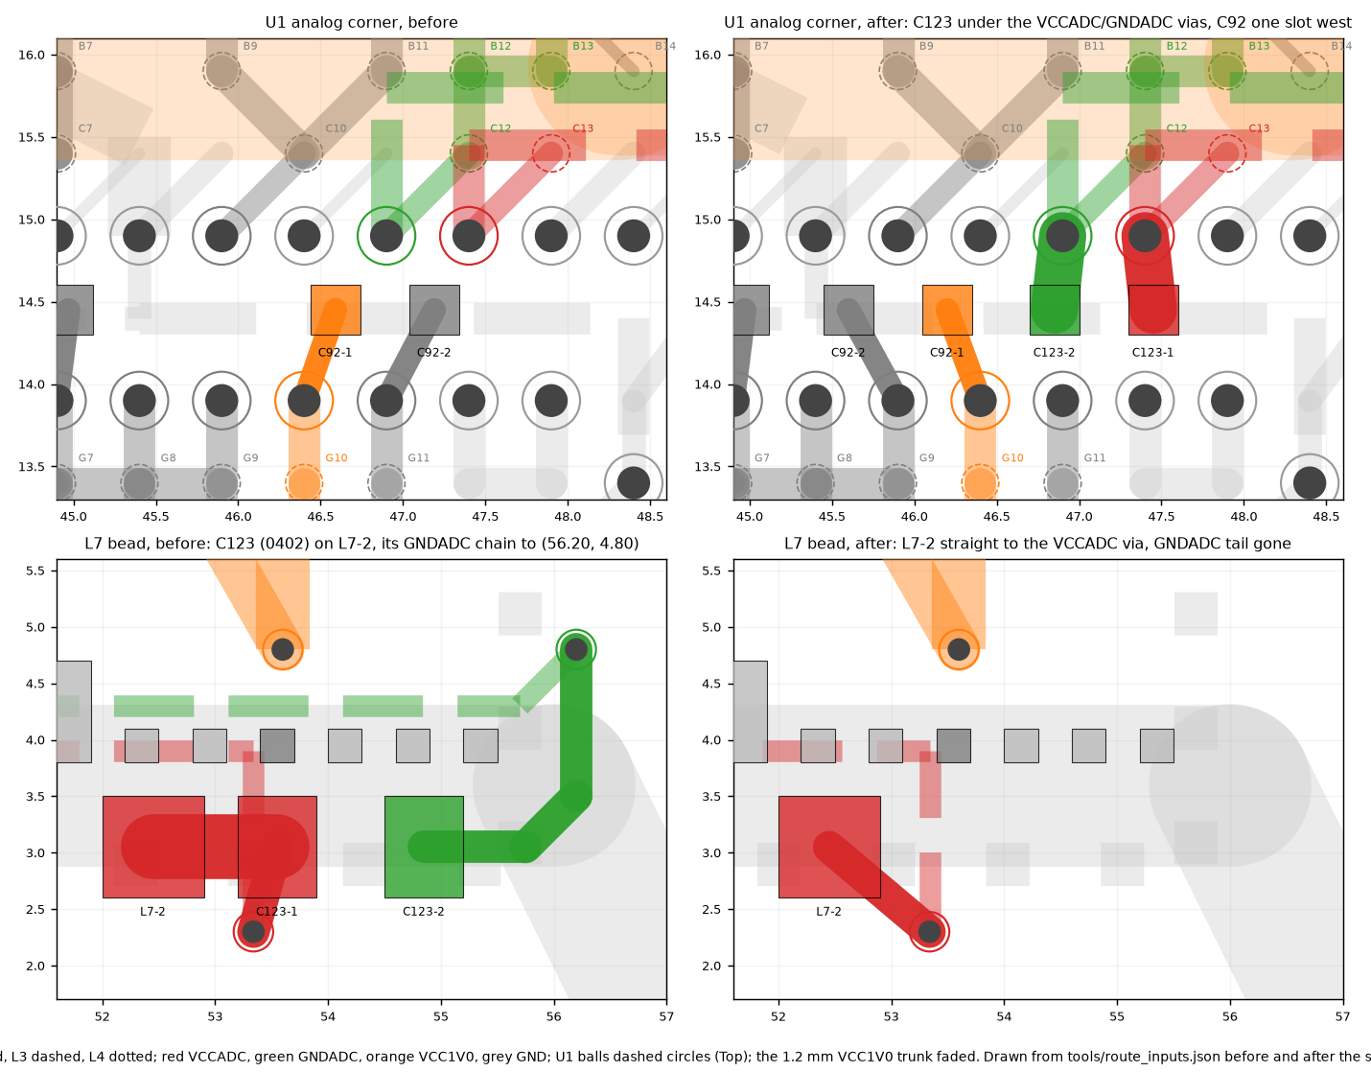
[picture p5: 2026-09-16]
Altium_backup/docs/c123_move.png

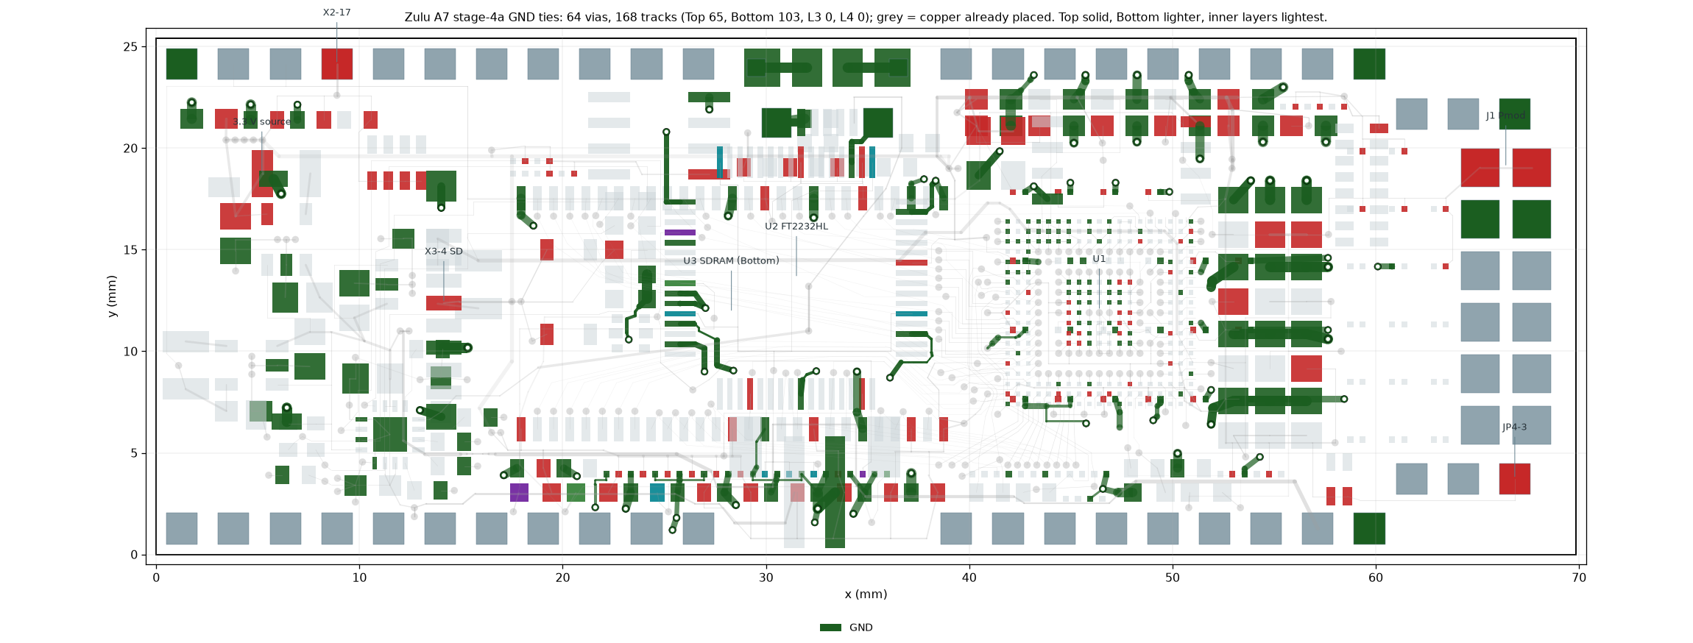
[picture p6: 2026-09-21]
Altium_backup/docs/stage4a_gnd_ties.png

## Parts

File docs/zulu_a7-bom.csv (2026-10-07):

Item | Qty | Refdes | Value | Package | Manufacturer | MANF# | Spec | Fitted | Note
1 | 1 | J1 | Pmod 2x6 | 2X06 | Sullins | PPTC062LFBN-RC | 2x6 female header, 2.54 mm pitch, through-hole, 12 way -- Pmod host socket | yes | A SOCKET, NOT PINS, AND THE LIBRARY NAME DISAGREES WITH THAT. The package is called PIN HEADER 2x6 and the deviceset PINHD-2X6, which is inherited naming, but on a Digilent Pmod the HOST carries the female socket and the peripheral module carries the male pins that plug into it. Cmod A7 is the same. Order male pins off that library name and no Pmod will mate. The footprint is 12 plated holes on 2.54 either way, so a male header such as Sullins PRPC006DAAN-RC drops into the same land if you would rather have pins and a cable. Height 8.5 mm is not a problem: J1 is on the FRONT, and it is the back that faces a breadboard a couple of millimetres away.
2 | 1 | Q1 | 12MHz 10ppm (FPGA + FT2232HL) | 32X25 | ECS | ECS-3225SMV-120-FP-TR | 12.000 MHz HCMOS XO, 1.62-3.63 V, +-10 ppm incl. initial, temp -40..105 C, supply, load, reflow and aging (ECS-3225SMV sheet p1), 3.2x2.5x1.2 mm, pin 1 tri-state (H/NC = run), 6 mA typ / 10 mA max; replaced the +-50 ppm ASEM1-12.000MHZ-LC-T on 2026-09-08 | yes | ACTIVE OSCILLATOR, NOT A CRYSTAL -- the schematic settles it: pin 2 to GND, pin 4 to VCC3V3, pin 3 out into R24 and R25, and pin 1 tied to VCC3V3, which is a 4-pad XO with its enable held high. A crystal would have two pads and load capacitors. THE FREQUENCY IS NOT A CHOICE: the FT2232H wants 12 MHz for its USB PLL, so that was fixed before anything else. 25 ppm is the value already recorded and is comfortably inside what FTDI asks of the reference. Output drives two loads through 33R each, the FT2232's OSCI and the FPGA clock ball. Pin 1 to Vdd suits either an OE part or one with pin 1 not connected, so the choice is not narrowed by it. ASEM1 is the family the design note already named. Confirm the suffix -- it encodes stability and temperature range and is the easy thing to get wrong.
3 | 1 | R1 | 4.7K | 742C043 | CTS | 742C043472JP | 2 x 4.7K +-5% isolated array, 0606 concave 1.60 x 1.60 mm, 0.80 mm pitch, 63 mW per element | yes | The two configuration pull-ups in one package: A on INIT_B (net FPGA-INIT#), B on PROGRAM_B (net RST#). Both commons are pads 3 and 4, side by side on one long side of the body, and both go to VCC3V3. CTS publishes ONE recommended land pattern for the whole 742 package family, so this footprint is the 742C083 pad cell already validated for R34 with two pads per side instead of four. 5 percent: the 742C043 has no 1 percent option either, and a configuration pull-up does not care; 63 mW per element against the 2.3 mW that 3.3 V across 4.7 k actually dissipates. Alternate on the identical land: Panasonic EXB-V4V472JV, same 1.60 x 1.60 mm concave body on 0.80 mm pitch. Do NOT substitute EXB-34V472JV -- same size, convex terminals, different land. R99, the third 4.7 k pull-up on this sheet, stays discrete: it sits on PROG#, the far side of the 100 ohm now in R4. TOLERANCE AGAINST UG470: Table 2-4 asks for a pull-up of 4.7 kohm OR LESS on both of these pins, and this is a 5 percent part, so its worst case is 4.935 k -- 5 percent outside the stated maximum. That is a wording problem rather than a physical one. The limit exists to hold the pin high against input leakage, and DS181 worst-case leakage of 15 uA across 4.935 k is 74 mV, against a VIH of 2.0 V. The discretes this replaces were 1 percent parts and were already outside the same limit, at 4.747 k. Strict compliance would mean 4.3 kohm +-5 percent (4.515 k worst case), but CTS does not stock a 432 code in the 742C043 family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
4 | 1 | R34 | 4.7K | 742C083 | CTS | 742C083472JP | 4x4.7K isolated array 0603x4, 0.8 mm pitch; direct successor of the obsolete JTR | yes | The microSD DAT0-3 pull-ups, all four elements used -- which is what an array is actually for. R1, R2 and R4 used 2, 3 and 6 of theirs in the EAGLE original and were split into discretes during the import; on 2026-09-09 R1 and R4 went back into arrays of their own (742C043472JP and 742C163101JP), so all three arrays on this board are CTS 74x concave parts sharing one land-pattern rule. R2 is still a discrete. 4.7k is the conventional value for SD data lines and it was already chosen; only the part number was missing. 5 percent is ample for a pull-up, so this is a J part where the discrete resistors on this board are F. CTS 742C is the family the footprint is named after. Confirm the suffix -- it encodes tolerance and packaging and is the easy thing to get wrong.
5 | 1 | R4 | 100 | 742C163 | CTS | 742C163101JP | 8 x 100 ohm +-5% isolated array, 2506 concave 6.40 x 1.60 mm, 0.80 mm pitch, 63 mW per element; six elements used, two spare | yes | The six 100 ohm series resistors between the FT2232H and the FPGA in one package: A PROG#, B DONE, C TDI, D TDO, E TMS, F TCK, in the order they are drawn down the sheet. Pads 1-6 face the bridge and pads 16-11 face the FPGA, one long side of the body per end of the link. TWO ELEMENTS ARE SPARE (pads 7-10); they sit at the far end of the body, so the six used run contiguously from pad 1. Leave the spare pads unconnected. There is no purchasable 6-element part: CTS 753123101GP is a genuine 12-terminal, 6-isolated-element, 100 ohm array, but Digi-Key holds none, quotes 28 weeks at MOQ 1000 and $2.63 each, and its 12-SRT body is 8.76 x 2.03 mm, LARGER than this 8-element chip array. Same CTS 74x concave family as R34, so all three arrays on the board answer to one CTS land-pattern rule (0.45 x 0.80 mm pads, 0.80 mm pitch, 2.60 mm across). 5 percent like R34: the 742C163 has no 1 percent option, which series damping does not care about, and 63 mW per element is twenty times the worst case. Alternate if the layout needs the length back: Panasonic EXB-2HV101JV is the same 8 x 100 ohm isolated in 3.80 x 1.60 mm, but convex terminals on 0.50 mm pitch, so it needs its own land pattern. AT LAYOUT: all six lines now converge on one part -- put it between the bridge and the FPGA where the four JTAG lines already run together, and keep TCK, element F on pads 6/11, at the end of the body: its only live neighbour is TMS. SUPPLY CAVEATS, all read 2026-09-09. (1) CTS files the whole 74x ser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
6 | 22 | C89 C90 C91 C92 C95 C96 C107 C108 C109 C110 C111 C112 C113 C114 C115 C116 C117 C118 C119 C120 C121 C122 | 0.47uF | C0201 | Murata | GRM033R60J474KE90D | X5R 6.3V +-10% 0201 0.47uF; KE15D was a typo, KE90D is the live number | yes | 0402 -> 0201 to cut ESL, following Cmod A7. THE VOLTAGE RATING DROPS 16V to 6.3V and that costs real capacitance: on VCC3V3 a 6.3V 0201 sits at 52 percent of rating and DC bias typically removes 60-75 percent of it, against 15-25 percent for the 16V 0402 it replaces. The BOM value is unchanged, so validate.py's UG483 count still passes -- it counts nominal values and cannot see bias derating. Effective decoupling on 3V3 is roughly half what it was. Confirm the MPN suffix and the bias curve against Murata's data before ordering.
7 | 17 | C40 C41 C123 C133 C134 C135 C136 C137 C138 C152 C153 C154 C155 C156 C157 C158 C159 | 0.1uF / 100nF | C0201 | Murata | GRM033R61A104KE15D | X5R 10V +-10%, 0.30 mm max | yes | C40: 0402 -> 0201 on U2's support. The DIELECTRIC AND VOLTAGE BOTH CHANGE: X7R 16V becomes X5R 10V, because 0201 at this capacitance is an X5R part. X5R narrows the temperature range to -55..+85 C from X7R's +125, which suits this board but is not a like-for-like swap. At 0.1 uF the DC bias derating is mild, unlike the 0.47 uF on sheet 7. Confirm the MPN suffix against Murata's data before ordering. || C152: FT2232H core-rail decoupling. DS_FT2232H Figures 4.1 and 6.1 show a 100 nF at each VCORE pin besides the 4.7 uF bulk (C39, C139); the board had the bulk and none of these. Same part as the eight 0.1 uF and 100 nF 0201 capacitors already on this sheet, so no new BOM line. AT LAYOUT: put one beside each of pins 12, 37 and 64 with the shortest ground return you can manage -- that placement is the whole point of them. || C155: RETURN-PATH STITCHING FOR THE L5 PLANE, NOT DECOUPLING. L5 carries VCC3V3 and L2 carries GND, so a signal via that moves between an L2-referenced layer (Top, L3) and an L5-referenced one (L4, Bottom) has nowhere for its return current to go except through a VCC3V3-to-GND capacitor. Fifty-two vias on this board do that and thirty-nine of them are the AS4C32M16SB bus; before these five parts the nearest such capacitor was a median of 3.30 mm and up to 12.70 mm away, because all forty-six sit in the y 3.0-4.2 row, round U1, or at x 2.6-7.6, and none was anywhere in x 12-39, y 6-25.4. These five fill that hole: C155 (26.000,20.250) Top carries UDQM, CKE a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
8 | 1 | C38 | 0.01uF | C0201 | Murata | GRM033R71E103KE14D | X7R 25V +-10%, 0.30 mm max | yes | 0402 -> 0201 on U2's support. 50V drops to 25V, which is still far over what a 3.3V rail needs -- the 50V part was over-specified. Confirm the MPN suffix before ordering.
9 | 1 | C124 | 470nF | C0402 | Samsung | CL05A474KO5NNNC | X5R 16V +-10% 0402 0.47uF, 0.55 mm max; replaced GRM155R61C474KA88D (a number no distributor knows) on 2026-09-07 | yes
10 | 9 | C3 C4 C5 C6 C7 C8 C9 C11 C12 | 0.1uF | C0402 | Murata | GRM155R71C104KA88D | X7R 16V +-10%, 0.50 mm max | yes
11 | 2 | C36 C37 | 1nF | C0402 | Murata | GRM155R71H102KA01D | X7R 50V +-10%, 0.50 mm max | yes
12 | 1 | C139 | 4.7uF | C0402 | Taiyo Yuden | MSASJ105BB5475MFNA01 | X5R 6.3V +-20% 0402 4.7uF, 0.65 mm max, about 3.7 uF left at 1.8 V; Digi-Key alias JMK105BBJ475MV-F (587-2787-1-ND, 1.6 M pcs); replaced the unobtainable 3.3 uF GRM155R60J335ME15D on the FT2232H VCORE node (FTDI minimum 3.3 uF) on 2026-09-08 | yes
13 | 2 | C82 C84 | 22uF | C0603 | Samsung | CL10A226MP8NUNE | X5R 10V +-20% 0603 22uF, 1.05 mm max (T 0.80 +-0.25); replaced the 6.3 V Murata GRM188R60J226MEA0D (1.00 mm max, dry until 2027) on 2026-09-07 | yes
14 | 1 | C13 | 10uF | C0603 | Murata | GRM188R60J106ME47D | X5R 6.3V +-20%, 0.90 mm max | yes
15 | 13 | C87 C88 C94 C99 C100 C101 C102 C103 C104 C105 C106 C150 C151 | 4.7uF | C0603 | Murata | GRM188R61C475KE11D | X5R 16V +-10% 0603 4.7uF, 0.95 mm max; 10 V grades (KE15D obsolete, KAAJD NRND) replaced by the 16 V one on 2026-09-08 | yes
16 | 4 | C78 C147 C148 C149 | 10uF / 10uF 10V | C0805 | Samsung | CL21A106KPFNNNG | X5R 10V +-10% 0805 10uF; replaces the obsolete Murata GRM21BR61A106KE19L | yes
17 | 13 | C80 C85 C86 C93 C97 C98 C140 C141 C142 C143 C144 C145 C146 | 22uF | C0805 | Murata | GRM21BR61A226ME44L | X5R 10V +-20%, 1.45 mm max -- SC189 COUT on VCC3V3, sense pin 4 lands here | yes | Second half of a bulk position: each 47uF 1206 became two 22uF 0805. Nominal drops 47 -> 44 uF per position, but the 0805 is 10V where the 1206 was 6.3V, so it derates less under bias and the pair should deliver at least what the single part did. Height also drops 1.60 -> 1.45 mm max, which the back-side budget against the 2.54 mm header standoff cares about.
18 | 1 | X3 | DM3D-SF | DM3D-SF | Hirose | DM3D-SF | microSD push-pull (no eject), top mount, 0.5 A; 8 contacts + 4 shell pads G1-G4 + card-detect switch A/B (open without card); DM3 catalog p9 | yes
19 | 1 | LD0 | EAST1616RGBA8 | EVERLIGHT-19-337 | Everlight | EAST1616RGBA8 | RGB LED, three independent diodes, 1.6 x 1.6 x 0.35 mm, diffused lens, 624 / 525 / 468 nm, VF typ 2.05 / 3.2 / 3.2 V (max 2.4 / 3.7 / 3.7), IF 25 mA max per colour; anodes 1 B, 3 R, 5 G, cathodes 2 B, 4 R, 6 G (19-337 sheet p8); replaced the distributor-less Victory VS NRD8 on 2026-09-08 | yes | Everlight EAST1616RGBA8 = 19-337/R6GHBHW-A01/2T (DSE-0009126 Rev.3, 22-Dec-2016); water-clear twin EAST1616RGBA4 = 19-337/R6GHBHC-A01/2T. Same body, lens and recommended pads as the Victory VS NRD8 it replaces (0.55 x 0.4 outer pads at +-0.725 mm, 0.7 x 0.5 middle, 1.9 / 2.2 mm spans) and the same arrangement: cathodes in the left column under the cathode mark, blue / red / green top to bottom, anodes on the right. Only the numbering differs (Everlight anodes 1/3/5 on the right, cathodes 2/4/6 on the left), so on 2026-09-08 the pins were renumbered 1/2/3 -> 2/4/6 and 4/5/6 -> 1/3/5 with the nets unchanged: LED0_B/R/G on the cathodes to the FPGA, N$LD0B/R/G on the anodes through R80/R81/R82. Footprint EVERLIGHT-19-337 = the VS-NRD8 pattern with Everlight pad numbers. Digi-Key 15,840 in stock at $0.43 on 2026-09-08.
20 | 1 | U2 | FT2232HL USB-UART/JTAG Bridge | FT2232HL-LQFP64 | FTDI | FT2232HL-REEL | USB 2.0 Hi-Speed dual-channel UART/FIFO/MPSSE bridge, LQFP-64 10 x 10 mm body, 12 x 12 mm over leads, 0.5 mm pitch, JEDEC MS-026 BCD, no exposed pad; same die and pin numbering as the FT2232HQ (DS_FT2232H v2.10 section 3.1); channel A MPSSE JTAG + PROG#/DONE, channel B UART; 12 MHz CMOS oscillator into OSCI, internal 1.8 V regulator, 93LC46B EEPROM, REF 12 k; replaced the FT2232HQ (0 stock until April 2027) on 2026-09-09 | yes | FT2232HL-REEL: Digi-Key 0 with 1,000 expected 19-Feb-2027 ($5.30, 50-week lead); LCSC C27882 4,767 in stock at $11.45 (not an FTDI-authorized channel: name it explicitly or consign for a PCBWay build). Pin numbers unchanged from the FT2232HQ; the QFN exposed pad (pin EP, GND) has no LQFP counterpart, so that pin and its ground stub were removed. thetaJA 37.66 C/W for the LQFP vs 29.67 for the QFN (DS_FT2232H Table 5.7). Footprint FT2232HL-LQFP64 to be drawn from Figure 8.2 or FTDI TN_166. Alternates on the same pin numbers: FT2232HQ (QFN-64) and FT4232HL / FT4232HQ (UART lands on channel C, EEPROM re-templated, PID 0x6011); the FT2232H-56Q keeps every signal but renumbers every pin.
21 | 4 | L4 L5 L6 L7 | FB 600R | IND0603 | Murata | BLM18KG601SN1D | ferrite bead 600 ohm at 100 MHz +-25%, 1.3 A at 85 C, 0.15 ohm max, 0603, 0.90 mm max; replaced BLM18PG601SN1D (a number Murata never made; the spec 600 ohm/1.5 A is BLM18SP601SN1D) on 2026-09-08; L4/L5 feed the FT2232H VPHY/VPLL (60 mA max), L6 GNDADC, L7 VCCADC (25 mA) | yes
22 | 3 | L1 L2 L3 | 1.5uH | IND2520 | Murata | DFE252010P-1R5M=P2 | 1.5uH +-20%, Isat >=1.8A, 1.00 mm max -- SC189 LX inductor, 2.5 MHz, <=0.31 A p-p ripple | yes
23 | 1 | X4 | JST PH 2-pin, 1S LiPo | JST-B2B-PH-SM4-TB | JST | B2B-PH-SM4-TB(LF)(SN) | JST PH 2.0 mm, 2 circuits, top-entry SMT header with fixing tabs, 2 A, 100 V, -25..85 C, mates with PHR-2 housing; pin 1 = battery +, pin 2 = GND | yes | B2B-PH-SM4-TB(LF)(SN): 8 mm tall, wire leaves upward; the side-entry twin is S2B-PH-SM4-TB(LF)(SN) (5.5 mm). There is no polarity standard for JST-PH LiPo packs: check pin 1 = + against the pack before plugging in. Footprint JST-B2B-PH-SM4-TB to draw from the catalog page (two contact pads on 2.0 mm plus two 1.6 x 3.0 mm fixing pads). Digi-Key 57,541 in stock at $0.47 on 2026-09-09.
24 | 2 | LD3 LD5 | green | LED0603 | Lite-On | LTST-C191KGKT | green indicator, 0603, Vf 2.1V max at 2mA | yes | LD3: Charger power-good: bq24232 PGOOD sinks LD3 through R107 1.5k from VU when a valid USB input is present || LD5: Power-good indicator: VCC3V3 to LD5 to R78 680R to Q2 drain to GND. SELECTED FROM THE CIRCUIT, not recovered -- the part carried no value and no number. THE RESISTOR ALREADY CHOSE THE COLOUR: 680R off 3.3 V passes (3.3 - Vf)/680, which is 1.9 mA for a green LED or 2.1 for a red, but only 0.6 mA for a blue or white one, too dim to read. So it is a green or red part, and green is the convention for power good. 1.9 mA is low but plain on a modern high-efficiency 0603; take R78 to 330R if you want it brighter.
25 | 3 | LD1 LD2 LD4 | red | LED0603 | Lite-On | LTST-C191KRKT | red indicator, 0603, Vf 2.1V max at 4mA | yes | LD1: User status LED, driven straight off an FPGA pin through R83 at 330R: (3.3 - Vf)/330 is 3.9 mA green, 4.2 red, 3.6 yellow, and 1.2 mA blue or white. Any of the first three is comfortable and well inside an LVCMOS33 pin's 12 mA. RED IS A PREFERENCE, NOT A CONSTRAINT -- the circuit takes green just as happily. It is red so that the two user LEDs read differently from LD5, which is green and means power good; on a board being brought up that is worth being able to tell apart at a glance. Same LTST-C191 family and the same 0603 land as LD5, so it is one line in the catalogue, not two. Confirm the suffix before ordering. || LD2: User status LED, driven straight off an FPGA pin through R84 at 330R: (3.3 - Vf)/330 is 3.9 mA green, 4.2 red, 3.6 yellow, and 1.2 mA blue or white. Any of the first three is comfortable and well inside an LVCMOS33 pin's 12 mA. RED IS A PREFERENCE, NOT A CONSTRAINT -- the circuit takes green just as happily. It is red so that the two user LEDs read differently from LD5, which is green and means power good; on a board being brought up that is worth being able to tell apart at a glance. Same LTST-C191 family and the same 0603 land as LD5, so it is one line in the catalogue, not two. Confirm the suffix before ordering. || LD4: Charging: bq24232 CHG sinks LD4 through R108 1.5k from VU while the battery charges, off when done or disabled
26 | 1 | X1 | Molex 105017-0001 Micro-USB-B | MOLEX-105017-0001 | Molex | 105017-0001 |  | yes
27 | 1 | BTN | PTS810 | PTS810 | Littelfuse (C&K) | PTS810SJM250SMTR LFS | tactile switch SPST-NO momentary, SMT J-lead, 4.2 x 3.2 x 2.5 mm, 1.6 N (160 gf), 0.15 mm travel, 150000 cycles, 16 VDC 50 mA, -40..85 C; terminals 1-2 and 3-4 internally common (PTS810 sheet p1); replaced the unsourceable PTA-142 on 2026-09-08 | yes | PTS810SJM250SMTR LFS, Littelfuse (C&K) PTS810 series, Datasheet/Littelfuse-CK-Tactile-PTS810-Series-Datasheet.pdf rev 02/02/26. Recommended PCB layout (p1): four pads (5.2 - 3.1)/2 = 1.05 mm wide by (2.8 - 1.5)/2 = 0.65 mm high, centred at +-2.075 mm and +-1.075 mm; body 4.2 x 3.2 mm, J-leads to 4.6 mm, height 2.5 mm. The datasheet schematic joins 1 with 2 and 3 with 4, so pins 1,2 (VCC3V3) and 3,4 (BTN) are unchanged. Footprint PTS810 to be drawn at the PCB stage; the PTA-142 pattern (1.6 mm pads at +-3.75 / +-1.4 mm) does not fit. Other force grades on the same pads: K 2.6 N, G 4.0 N, S 6.0 N. Digi-Key 106,352 in stock at $0.58, 16-week lead (2026-09-08); LCSC C116501 dry, the K grade C221896 stocked.
28 | 9 | R19 R90 R91 R92 R93 R94 R96 R97 R98 | 10K / 10k | R0201 | Yageo | RC0201FR-0710KL | thick film +-1%, 1/20W, 0201 | yes
29 | 2 | R12 R16 | 140 | R0201 | Yageo | RC0201FR-07140RL | thick film +-1%, 1/20W, 0201 | yes
30 | 5 | R11 R15 R20 R22 R23 | 1K | R0201 | Yageo | RC0201FR-071KL | thick film +-1%, 1/20W, 0201 | yes
31 | 8 | R26 R27 R28 R29 R30 R31 R32 R33 | 200 | R0201 | Yageo | RC0201FR-07200RL | thick film +-1%, 1/20W, 0201 | yes
32 | 1 | R101 | 2.21k | R0201 | Yageo | RC0201FR-072K21L | thick film +-1%, 1/20W, 0201 | yes
33 | 2 | R10 R14 | 2.32K | R0201 | Yageo | RC0201FR-072K32L | thick film +-1%, 1/20W, 0201 | yes
34 | 2 | R24 R25 | 33 | R0201 | Yageo | RC0201FR-0733RL | thick film +-1%, 1/20W, 0201 | yes
35 | 4 | R2 R6 R7 R99 | 4.7K / 4.7k | R0201 | Yageo | RC0201FR-074K7L | thick film +-1%, 1/20W, 0201 | yes
36 | 1 | R5 | 5.1K | R0201 | Yageo | RC0201FR-075K1L | thick film +-1%, 1/20W, 0201 | yes
37 | 2 | R13 R17 | 845 | R0201 | Yageo | RC0201FR-07845RL | thick film +-1%, 1/20W, 0201 | yes
38 | 3 | R85 R86 R106 | 10K | R0402 | Yageo | RC0402FR-0710KL | thick film +-1%, 1/16W, 0402 | yes
39 | 1 | R18 | 12K 1% | R0402 | Yageo | RC0402FR-0712KL | thick film +-1%, 1/16W, 0402 | yes | Stays 0402 deliberately. Power is trivial (0.9 mW) and 1 percent is 1 percent at any size, but this is the FT2232's RREF -- it sets the USB transceiver bias current. There is no space pressure on this board any more, so there is nothing to gain against a part whose drift shows up as USB signal quality.
40 | 2 | R107 R108 | 1.5K | R0402 | Yageo | RC0402FR-071K5L | thick film +-1%, 1/16W, 0402 -- PGOOD LED current: (4.4 - 2.1) / 1.5k = 1.5 mA | yes
41 | 1 | R21 | 1K | R0402 | Yageo | RC0402FR-071KL | thick film +-1%, 1/16W, 0402 | yes
42 | 3 | R81 R83 R84 | 330 | R0402 | Yageo | RC0402FR-07330RL | thick film +-1%, 1/16W, 0402 | yes | RGB LED balance. The green and blue dice are 3.3 V-class parts on a 3.3 V rail, so the resistor never dominates their current -- that is structural and no resistor value fixes it. What the values CAN do is stop red swamping the other two. As built, and as Cmod A7 ships the same LED, 182/182/100 gave red 6.9 mA against green 1.9 and blue 1.5: red about four times either. At 330/33/33 it is red 3.8, green 2.9, blue 2.9. Worst case improves too, not just nominal -- green with a part 0.15 V high in Vf goes from 1.4 mA to 1.8. Lower resistors do make the current MORE sensitive in percentage terms, 77 percent of nominal retained at 100R against 61 at 33R, but the absolute floor is what you see and it rises. Currents read off the datasheet's own Vf/If curve at the working point, not off the 20 mA table.
43 | 2 | R80 R82 | 33 | R0402 | Yageo | RC0402FR-0733RL | thick film +-1%, 1/16W, 0402 | yes | RGB LED balance. The green and blue dice are 3.3 V-class parts on a 3.3 V rail, so the resistor never dominates their current -- that is structural and no resistor value fixes it. What the values CAN do is stop red swamping the other two. As built, and as Cmod A7 ships the same LED, 182/182/100 gave red 6.9 mA against green 1.9 and blue 1.5: red about four times either. At 330/33/33 it is red 3.8, green 2.9, blue 2.9. Worst case improves too, not just nominal -- green with a part 0.15 V high in Vf goes from 1.4 mA to 1.8. Lower resistors do make the current MORE sensitive in percentage terms, 77 percent of nominal retained at 100R against 61 at 33R, but the absolute floor is what you see and it rises. Currents read off the datasheet's own Vf/If curve at the working point, not off the 20 mA table.
44 | 1 | R103 | 3.09K | R0402 | Yageo | RC0402FR-073K09L | thick film +-1%, 1/16W, 0402 -- ILIM: 1530 / 3.09k = 495 mA input current limit (EN2 = VU, EN1 = GND select the resistor) | yes
45 | 1 | R102 | 3.57K | R0402 | Yageo | RC0402FR-073K57L | thick film +-1%, 1/16W, 0402 -- ISET: 870 / 3.57k = 244 mA fast-charge current | yes
46 | 1 | R105 | 4.32K | R0402 | Yageo | RC0402FR-074K32L | thick film +-1%, 1/16W, 0402 -- ITERM: 0.03 A x 4.32k / 3.57k = 36 mA termination (15 % of the charge current) | yes
47 | 1 | R35 | 4.7K | R0402 | Yageo | RC0402FR-074K7L | thick film +-1%, 1/16W, 0402 | yes
48 | 1 | R104 | 56.2K | R0402 | Yageo | RC0402FR-0756K2L | thick film +-1%, 1/16W, 0402 -- TMR: 10 x 56.2k x 48 s/k = 7.5 h fast-charge and 45 min precharge safety timers | yes
49 | 1 | R78 | 680 | R0402 | Yageo | RC0402FR-07680RL | thick film +-1%, 1/16W, 0402 | yes
50 | 1 | U4 | W25Q128JVSIQ | SOIC-8_208MIL | Winbond | W25Q128JVSIQ |  | yes | 128Mbit quad SPI, SOIC-8 208mil. The XC7A35T bitstream is 17,536,096 bits, so the previous W25Q80BV (8Mbit) could not boot the part at all. 128Mbit leaves ~14MB for user data above the bitstream.
51 | 1 | U7 | SC189ASKTRT | SOT23-5 | Semtech | SC189ASKTRT |  | yes
52 | 1 | U6 | SC189LSKTRT | SOT23-5 | Semtech | SC189LSKTRT |  | yes
53 | 1 | U5 | SC189ZSKTRT | SOT23-5 | Semtech | SC189ZSKTRT |  | yes
54 | 1 | U10 | 93LC46BT-I/SN | SPI-8_SOIC_150 | Microchip | 93LC46BT-I/SN |  | yes
55 | 1 | U3 | AS4C32M16SB-7TCN | TSOPII-54 | Alliance Memory | AS4C32M16SB-7TCN |  | yes | 512Mbit (32M x 16) = 64MB. Pin-for-pin and dimensionally identical to the 256Mb AS4C16M16SA-6TIN it replaces: all 54 pins and every TSOP-II dimension were checked against both datasheets, and pin 40 is NC on both. ONE DIFFERENCE, AND IT IS NOT A PIN -- the column address is A0-A9 (1024 columns) instead of A0-A8 (512). The memory controller must be set to 10 column bits or it reaches only half the array. Row A0-A12, banks BA0/BA1 and refresh (8192 cycles/64ms) are unchanged. IDD1 rises 60mA to 120mA on the 600mA VCC3V3 buck (LTC3569 SW3). 2026-09-08: AS4C32M16SB-6TIN replaced by AS4C32M16SB-7TCN (same B die, 54-TSOP II 400 mil and pinout, datasheet Rev 1.4 Table 2): -7 speed bin, 143 MHz max at CL3 (tCK 7 ns, tAC 5.4 ns), tRCD/tRP 21 ns, tRC/tRFC 63 ns, tRRD/tMRD/tWR 14 ns, tCH/tCL 2.5 ns; 100 MHz at CL2 for every grade. Commercial TA 0..70 C, matching the -1C FPGA. IDD1 max 110 mA (was 120). AS4C32M16SB-7TIN (industrial) is the timing-identical alternate; the -6TIN only if the controller is clocked above 143 MHz.
56 | 1 | U8 | BQ24232 LiPo charger + power path | VQFN16-3X3-RGT | Texas Instruments | BQ24232RGTR | single-cell Li-ion/LiPo linear charger with power path, 16-pin VQFN 3 x 3 mm (RGT), IN 4.35-10.2 V with 10.5 V OVP, OUT 4.4 V regulated or VBAT - 60 mV on battery, input limit 495 mA (R103), charge 244 mA (R102), termination 36 mA (R105), 7.5 h timer (R104), TS disabled with 10k (R106), CE and EN1 to GND, EN2 to VU; thetaJA 44.5 C/W; added 2026-09-09 in place of D1 | yes | bq24232 (SLUS821J): USB5V0 into IN, OUT onto VU, battery on BAT/X4. With USB present OUT is 4.4 V (LDO) and the input is capped at 495 mA: DPPM trims the charge current first, then the battery supplements the load; the board therefore never draws more than the limit from the port. On battery alone VU = VBAT - 60 mV, and the 3.3 V buck holds regulation down to about 3.45 V. The +5V-INPUT path with D2 and D3 was removed on 2026-09-09, so the charger is the only input. Dissipation about 0.6 W worst case (0.3 W power path at 500 mA plus 0.3 W charging), a 27 C rise at 44.5 C/W. Battery-only start-up into the 40 uF on VU relies on the part's inrush sequence and the 250 mV / 250 us short-circuit detector: scope it on the first board. Footprint VQFN16-3X3-RGT to draw from the datasheet package drawing (3 x 3 mm, 0.5 mm pitch, 1.68 mm pad). Digi-Key 541 in stock at $1.93 on 2026-09-09.
57 | 1 | U1 | XC7A35T-1CPG236C | XC7A35T-CPG236 | AMD/Xilinx | XC7A35T-1CPG236C |  | yes
58 | 1 | X2 | ZULU-CONN | ZULU-DIP37 | Sullins | 2x PRPC009SAAN-RC + 2x PRPC011SAAN-RC | four 0.1 in male breakaway header strips, 0.64 mm square gold-flash pins, 2.54 mm pitch, through-hole, mounted from the underside, two part numbers and two of each per board: PRPC009SAAN-RC 1x9 twice (pins 1-9 and 21-29) and PRPC011SAAN-RC 1x11 twice (pins 10-20 and 30-40); the two rows are cut identically since the LiPo landing was moved opposite the micro-USB on 2026-09-09 | yes | Pin field ZULU-DIP37: 40 pins of 1.016 mm on 2.54 mm pitch, two rows 22.86 mm (0.900 in) apart, numbered 1-40 straight through and skipping both landings. The rows are mirror images: top row pins 1-9 (x 59.69..39.37) = GND, CHAN-CLK, CHAN0..CHAN6, FOUR positions for the micro-USB X1 (36.83..29.21), pins 10-20 (26.67..1.27) = CHAN7..CHAN13, GND, +3.3V, +1.8V, +1.0V (channel order since 2026-09-09, power pins re-ordered 2026-10-07); bottom row pins 21-29 (59.69..39.37), FOUR positions for the LiPo header X4 at the SAME four x values (36.83..29.21), pins 30-40 (26.67..1.27), so X4 sits on the top side directly opposite the edge-mounted USB receptacle. Each landing is 12.70 mm between the neighbouring pin centres, 11.176 mm clear: the JST B2B-PH-SM4-TB body is 7.95 mm, so 1.61 mm each side. Reworked 2026-09-09 from the old 44-position pattern: +5V-INPUT with D2/D3, GND5, GND3 and +3.3V2 removed, CHAN12/CHAN13 moved to pins 2/3, the bottom row closed up, the field renumbered and the landing moved. Three grounds (1, 17, 21); 3.3 V for the header is pin 18 alone; pin 22 VU sources the 4.4 V rail. THE PCB FOOTPRINT MUST BE REDRAWN with 40 pads named 1-40 in these positions -- the imported ZULU-DIP37 still names 44. Sullins PRPC strips fit the holes (0.64 mm square pins, Sullins recommends 1.02 mm). Digi-Key 2026-09-08: PRPC009SAAN-RC 1,201 at $0.18, PRPC011SAAN-RC 428 at $0.22, two of each per board (the 1x11 stock covers about 200 boards). Alternate: any 2.54 mm 1x40 breakaway str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
59 | 1 | JP3 | JTAG TCK/TMS/GND | 1X03-NOSILK |  |  | DNS - do not stuff: three bare plated holes, 1x3 on 2.54 mm, for flying leads or pogo pins; no part to order (flagged 2026-09-08) | DNP | Bare plated holes -- NO HEADER FITTED, nothing to order. Three of the six JTAG holes; JP4 carries the other three, 17.96 mm away on the far side of the Pmod. Each row has 3.05 mm of board to the Pmod but only 0.09 mm to a 1x3 strip's body, so these are for flying leads or a pogo jig. The FT2232 does JTAG over USB on channel B; this is the fallback.
60 | 1 | JP4 | JTAG TDI/TDO/3V3 | 1X03-NOSILK |  |  | DNS - do not stuff: three bare plated holes, 1x3 on 2.54 mm, for flying leads or pogo pins; no part to order (flagged 2026-09-08) | DNP | Bare plated holes -- NO HEADER FITTED, nothing to order. Three of the six JTAG holes; JP3 carries the other three, 17.96 mm away on the far side of the Pmod. Each row has 3.05 mm of board to the Pmod but only 0.09 mm to a 1x3 strip's body, so these are for flying leads or a pogo jig. The FT2232 does JTAG over USB on channel B; this is the fallback.

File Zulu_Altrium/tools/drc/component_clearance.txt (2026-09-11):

Component Clearance Constraint ( Horizontal Gap = 10mil, Vertical Gap = 10mil ) (All),(All)
===========================================================================================
Component Clearance Constraint: (Collision < 10mil) Between BGA Component U1-XC7A35T-1CPG236C (1649.606mil,645.669mil) on Top Layer And DIP Component X2-ZULU-CONN (0mil,0mil) on Top Layer
Component Clearance Constraint: (Collision < 10mil) Between BGA Component U1-XC7A35T-1CPG236C (1649.606mil,645.669mil) on Top Layer And SMT Small Component C140-22uF (2086.618mil,263.775mil) on Top Layer
Component Clearance Constraint: (Collision < 10mil) Between BGA Component U1-XC7A35T-1CPG236C (1649.606mil,645.669mil) on Top Layer And SMT Small Component C143-22uF (2086.618mil,393.684mil) on Top Layer
Component Clearance Constraint: (Collision < 10mil) Between BGA Component U1-XC7A35T-1CPG236C (1649.606mil,645.669mil) on Top Layer And SMT Small Component C146-22uF (2086.618mil,523.598mil) on Top Layer
Component Clearance Constraint: (Collision < 10mil) Between BGA Component U1-XC7A35T-1CPG236C (1649.606mil,645.669mil) on Top Layer And SMT Small Component C93-22uF (2086.618mil,653.507mil) on Top Layer
Component Clearance Constraint: (Collision < 10mil) Between BGA Component U1-XC7A35T-1CPG236C (1649.606mil,645.669mil) on Top Layer And SOIC Component U4-W25Q128JVSIQ (1714.588mil,838.779mil) on Top Layer
Component Clearance Constraint: (Collision < 10mil) Between Component BTN-PTS810 (799.214mil,508.662mil) on Top Layer And DIP Component X2-ZULU-CONN (0mil,0mil) on Top Layer
Component Clearance Constraint: (Collision < 10mil) Between Component LD0-EAST1616RGBA8 (968.505mil,428.543mil) on Top Layer And DIP Component X2-ZULU-CONN (0mil,0mil) on Top Layer
Component Clearance Constraint: (Collision < 10mil) Between Component LD0-EAST1616RGBA8 (968.505mil,428.543mil) on Top Layer And LCC Component U2-FT2232HL USB-UART/JTAG Bridge (1297.245mil,535.435mil) on Top Layer
Component Clearance Constraint: (Collision < 10mil) Between Component LD0-EAST1616RGBA8 (968.505mil,428.543mil) on Top Layer And SMT Small Component LD1-red (968.504mil,495.472mil) on Top Layer
Component Clearance Constraint: (Collision < 10mil) Between Component Q1-12MHz 10ppm (FPGA + FT2232HL) (1592.52mil,820.862mil) on Top Layer And DIP Component X2-ZULU-CONN (0mil,0mil) on Top Layer
Component Clearance Constraint: (Collision < 10mil) Between Component Q1-12MHz 10ppm (FPGA + FT2232HL) (1592.52mil,820.862mil) on Top Layer And LCC Component U2-FT2232HL USB-UART/JTAG Bridge (1297.245mil,535.435mil) on Top Layer
Component Clearance Constraint: (Collision < 10mil) Between Component Q1-12MHz 10ppm (FPGA + FT2232HL) (1592.52mil,820.862mil) on Top Layer And SOIC Component U4-W25Q128JVSIQ (1714.588mil,838.779mil) on Top Layer
Component Clearance Constraint: (Collision < 10mil) Between Component R1-4.7K (2291.341mil,145.67mil) on Bottom Layer And SMT Small Component R24-33 (2324.802mil,222.441mil) on Bottom Layer
Component Clearance Constraint: (Collision < 10mil) Between Component U5-SC189ZSKTRT (96.455mil,228.345mil) on Bottom Layer And Component U6-SC189LSKTRT (206.684mil,228.345mil) on Bottom Layer
Component Clearance Constraint: (Collision < 10mil) Between Component U5-SC189ZSKTRT (96.455mil,228.345mil) on Bottom Layer And SMT Small Component L1-1.5uH (216.536mil,356.295mil) on Bottom Layer
Component Clearance Constraint: (Collision < 10mil) Between Component U5-SC189ZSKTRT (96.455mil,228.345mil) on Bottom Layer And SMT Small Component Q2-2N7002 (92.52mil,356.296mil) on Bottom Layer
Component Clearance Constraint: (Collision < 10mil) Between Component U6-SC189LSKTRT (206.684mil,228.345mil) on Bottom Layer And Component U7-SC189ASKTRT (316.916mil,228.345mil) on Bottom Layer
Component Clearance Constraint: (Collision < 10mil) Between Component U6-SC189LSKTRT (206.684mil,228.345mil) on Bottom Layer And SMT Small Component L1-1.5uH (216.536mil,356.295mil) on Bottom Layer
Component Clearance Constraint: (Collision < 10mil) Between Component U6-SC189LSKTRT (206.684mil,228.345mil) on Bottom Layer And SMT Small Component Q2-2N7002 (92.52mil,356.296mil) on Bottom Layer
Component Clearance Constraint: (Collision < 10mil) Between Component U7-SC189ASKTRT (316.916mil,228.345mil) on Bottom Layer And LCC Component U8-BQ24232 LiPo charger + power path (444.868mil,224.412mil) on Bottom Layer
Component Clearance Constraint: (Collision < 10mil) Between Component U7-SC189ASKTRT (316.916mil,228.345mil) on Bottom Layer And SMT Small Component L1-1.5uH (216.536mil,356.295mil) on Bottom Layer
Component Clearance Constraint: (Collision < 10mil) Between Component U7-SC189ASKTRT (316.916mil,228.345mil) on Bottom Layer And SMT Small Component L2-1.5uH (362.205mil,356.295mil) on Bottom Layer
Component Clearance Constraint: (Collision < 10mil) Between Component X1-Molex 105017-0001 Micro-USB-B (1300.001mil,836.949mil) on Top Layer And DIP Component X2-ZULU-CONN (0mil,0mil) on Top Layer
Component Clearance Constraint: (Collision < 10mil) Between Component X1-Molex 105017-0001 Micro-USB-B (1300.001mil,836.949mil) on Top Layer And LCC Component U2-FT2232HL USB-UART/JTAG Bridge (1297.245mil,535.435mil) on Top Layer
Component Clearance Constraint: (Collision < 10mil) Between Component X4-JST PH 2-pin, 1S LiPo (1275.591mil,208.663mil) on Top Layer And DIP Component X2-ZULU-CONN (0mil,0mil) on Top Layer
Component Clearance Constraint: (Collision < 10mil) Between Component X4-JST PH 2-pin, 1S LiPo (1275.591mil,208.663mil) on Top Layer And LCC Component U2-FT2232HL USB-UART/JTAG Bridge (1297.245mil,535.435mil) on Top Layer
Component Clearance Constraint: (Collision < 10mil) Between DIP Component J1-Pmod 2x6 (2614.173mil,500mil) on Top Layer And Small Component JP3-JTAG TCK/TMS/GND (2531.496mil,853.543mil) on Top Layer
Component Clearance Constraint: (Collision < 10mil) Between DIP Component J1-Pmod 2x6 (2614.173mil,500mil) on Top Layer And Small Component JP4-JTAG TDI/TDO/3V3 (2531.496mil,146.457mil) on Top Layer
Component Clearance Constraint: (Collision < 10mil) Between DIP Component X2-ZULU-CONN (0mil,0mil) on Top Layer And LCC Component U2-FT2232HL USB-UART/JTAG Bridge (1297.245mil,535.435mil) on Top Layer
Component Clearance Constraint: (Collision < 10mil) Between DIP Component X2-ZULU-CONN (0mil,0mil) on Top Layer And Small Component JP3-JTAG TCK/TMS/GND (2531.496mil,853.543mil) on Top Layer
Component Clearance Constraint: (Collision < 10mil) Between DIP Component X2-ZULU-CONN (0mil,0mil) on Top Layer And Small Component JP4-JTAG TDI/TDO/3V3 (2531.496mil,146.457mil) on Top Layer
Component Clearance Constraint: (Collision < 10mil) Between DIP Component X2-ZULU-CONN (0mil,0mil) on Top Layer And SMT SIP Component X3-DM3D-SF (346.457mil,491.142mil) on Top Layer
Component Clearance Constraint: (Collision < 10mil) Between DIP Component X2-ZULU-CONN (0mil,0mil) on Top Layer And SMT Small Component C140-22uF (2086.618mil,263.775mil) on Top Layer
Component Clearance Constraint: (Collision < 10mil) Between DIP Component X2-ZULU-CONN (0mil,0mil) on Top Layer And SMT Small Component C141-22uF (2157.488mil,263.775mil) on Top Layer
Component Clearance Constraint: (Collision < 10mil) Between DIP Component X2-ZULU-CONN (0mil,0mil) on Top Layer And SMT Small Component C142-22uF (2228.358mil,263.775mil) on Top Layer
Component Clearance Constraint: (Collision < 10mil) Between DIP Component X2-ZULU-CONN (0mil,0mil) on Top Layer And SMT Small Component C143-22uF (2086.618mil,393.684mil) on Top Layer
Component Clearance Constraint: (Collision < 10mil) Between DIP Component X2-ZULU-CONN (0mil,0mil) on Top Layer And SMT Small Component C144-22uF (2157.488mil,393.684mil) on Top Layer
Component Clearance Constraint: (Collision < 10mil) Between DIP Component X2-ZULU-CONN (0mil,0mil) on Top Layer And SMT Small Component C145-22uF (2228.358mil,393.684mil) on Top Layer
Component Clearance Constraint: (Collision < 10mil) Between DIP Component X2-ZULU-CONN (0mil,0mil) on Top Layer And SMT Small Component C146-22uF (2086.618mil,523.598mil) on Top Layer
Component Clearance Constraint: (Collision < 10mil) Between DIP Component X2-ZULU-CONN (0mil,0mil) on Top Layer And SMT Small Component C85-22uF (2157.488mil,523.598mil) on Top Layer
Component Clearance Constraint: (Collision < 10mil) Between DIP Component X2-ZULU-CONN (0mil,0mil) on Top Layer And SMT Small Component C86-22uF (2228.358mil,523.598mil) on Top Layer
Component Clearance Constraint: (Collision < 10mil) Between DIP Component X2-ZULU-CONN (0mil,0mil) on Top Layer And SMT Small Component C93-22uF (2086.618mil,653.507mil) on Top Layer
Component Clearance Constraint: (Collision < 10mil) Between DIP Component X2-ZULU-CONN (0mil,0mil) on Top Layer And SMT Small Component C97-22uF (2157.488mil,653.507mil) on Top Layer
Component Clearance Constraint: (Collision < 10mil) Between DIP Component X2-ZULU-CONN (0mil,0mil) on Top Layer And SMT Small Component C98-22uF (2228.358mil,653.507mil) on Top Layer
Component Clearance Constraint: (Collision < 10mil) Between DIP Component X2-ZULU-CONN (0mil,0mil) on Top Layer And SMT Small Component LD1-red (968.504mil,495.472mil) on Top Layer
Component Clearance Constraint: (Collision < 10mil) Between DIP Component X2-ZULU-CONN (0mil,0mil) on Top Layer And SMT Small Component LD2-red (968.504mil,542.716mil) on Top Layer
Component Clearance Constraint: (Collision < 10mil) Between DIP Component X2-ZULU-CONN (0mil,0mil) on Top Layer And SMT Small Component LD3-green (968.504mil,637.205mil) on Top Layer
Component Clearance Constraint: (Collision < 10mil) Between DIP Component X2-ZULU-CONN (0mil,0mil) on Top Layer And SMT Small Component LD4-red (968.504mil,684.449mil) on Top Layer
Component Clearance Constraint: (Collision < 10mil) Between DIP Component X2-ZULU-CONN (0mil,0mil) on Top Layer And SMT Small Component LD5-green (968.504mil,589.961mil) on Top Layer
Component Clearance Constraint: (Collision < 10mil) Between DIP Component X2-ZULU-CONN (0mil,0mil) on Top Layer And SOIC Component R4-100 (2334.646mil,715.669mil) on Top Layer
Component Clearance Constraint: (Collision < 10mil) Between DIP Component X2-ZULU-CONN (0mil,0mil) on Top Layer And SOIC Component U4-W25Q128JVSIQ (1714.588mil,838.779mil) on Top Layer
Component Clearance Constraint: (Collision < 10mil) Between LCC Component U2-FT2232HL USB-UART/JTAG Bridge (1297.245mil,535.435mil) on Top Layer And SMT Small Component LD1-red (968.504mil,495.472mil) on Top Layer
Component Clearance Constraint: (Collision < 10mil) Between LCC Component U2-FT2232HL USB-UART/JTAG Bridge (1297.245mil,535.435mil) on Top Layer And SMT Small Component LD2-red (968.504mil,542.716mil) on Top Layer
Component Clearance Constraint: (Collision < 10mil) Between LCC Component U2-FT2232HL USB-UART/JTAG Bridge (1297.245mil,535.435mil) on Top Layer And SMT Small Component LD3-green (968.504mil,637.205mil) on Top Layer
Component Clearance Constraint: (Collision < 10mil) Between LCC Component U2-FT2232HL USB-UART/JTAG Bridge (1297.245mil,535.435mil) on Top Layer And SMT Small Component LD4-red (968.504mil,684.449mil) on Top Layer
Component Clearance Constraint: (Collision < 10mil) Between LCC Component U2-FT2232HL USB-UART/JTAG Bridge (1297.245mil,535.435mil) on Top Layer And SMT Small Component LD5-green (968.504mil,589.961mil) on Top Layer
Component Clearance Constraint: (Collision < 10mil) Between Small Component JP3-JTAG TCK/TMS/GND (2531.496mil,853.543mil) on Top Layer And SOIC Component R4-100 (2334.646mil,715.669mil) on Top Layer
Component Clearance Constraint: (Collision < 10mil) Between SMT Small Component C100-4.7uF (1622.043mil,830.709mil) on Bottom Layer And SMT Small Component C101-4.7uF (1744.086mil,830.709mil) on Bottom Layer
Component Clearance Constraint: (Collision < 10mil) Between SMT Small Component C100-4.7uF (1622.043mil,830.709mil) on Bottom Layer And SMT Small Component C106-4.7uF (1622.043mil,881.89mil) on Bottom Layer
Component Clearance Constraint: (Collision < 10mil) Between SMT Small Component C100-4.7uF (1622.043mil,830.709mil) on Bottom Layer And SMT Small Component C87-4.7uF (1744.086mil,881.89mil) on Bottom Layer
Component Clearance Constraint: (Collision < 10mil) Between SMT Small Component C101-4.7uF (1744.086mil,830.709mil) on Bottom Layer And SMT Small Component C102-4.7uF (1866.125mil,830.709mil) on Bottom Layer
Component Clearance Constraint: (Collision < 10mil) Between SMT Small Component C101-4.7uF (1744.086mil,830.709mil) on Bottom Layer And SMT Small Component C106-4.7uF (1622.043mil,881.89mil) on Bottom Layer
Component Clearance Constraint: (Collision < 10mil) Between SMT Small Component C101-4.7uF (1744.086mil,830.709mil) on Bottom Layer And SMT Small Component C87-4.7uF (1744.086mil,881.89mil) on Bottom Layer
Component Clearance Constraint: (Collision < 10mil) Between SMT Small Component C101-4.7uF (1744.086mil,830.709mil) on Bottom Layer And SMT Small Component C88-4.7uF (1866.125mil,881.89mil) on Bottom Layer
Component Clearance Constraint: (Collision < 10mil) Between SMT Small Component C102-4.7uF (1866.125mil,830.709mil) on Bottom Layer And SMT Small Component C103-4.7uF (1988.169mil,830.709mil) on Bottom Layer
Component Clearance Constraint: (Collision < 10mil) Between SMT Small Component C102-4.7uF (1866.125mil,830.709mil) on Bottom Layer And SMT Small Component C87-4.7uF (1744.086mil,881.89mil) on Bottom Layer
Component Clearance Constraint: (Collision < 10mil) Between SMT Small Component C102-4.7uF (1866.125mil,830.709mil) on Bottom Layer And SMT Small Component C88-4.7uF (1866.125mil,881.89mil) on Bottom Layer
Component Clearance Constraint: (Collision < 10mil) Between SMT Small Component C102-4.7uF (1866.125mil,830.709mil) on Bottom Layer And SMT Small Component C94-4.7uF (1988.169mil,881.89mil) on Bottom Layer
Component Clearance Constraint: (Collision < 10mil) Between SMT Small Component C103-4.7uF (1988.169mil,830.709mil) on Bottom Layer And SMT Small Component C104-4.7uF (2110.208mil,830.709mil) on Bottom Layer
Component Clearance Constraint: (Collision < 10mil) Between SMT Small Component C103-4.7uF (1988.169mil,830.709mil) on Bottom Layer And SMT Small Component C88-4.7uF (1866.125mil,881.89mil) on Bottom Layer
Component Clearance Constraint: (Collision < 10mil) Between SMT Small Component C103-4.7uF (1988.169mil,830.709mil) on Bottom Layer And SMT Small Component C94-4.7uF (1988.169mil,881.89mil) on Bottom Layer
Component Clearance Constraint: (Collision < 10mil) Between SMT Small Component C103-4.7uF (1988.169mil,830.709mil) on Bottom Layer And SMT Small Component C99-4.7uF (2110.208mil,881.89mil) on Bottom Layer
Component Clearance Constraint: (Collision < 10mil) Between SMT Small Component C104-4.7uF (2110.208mil,830.709mil) on Bottom Layer And SMT Small Component C105-4.7uF (2232.247mil,830.709mil) on Bottom Layer
Component Clearance Constraint: (Collision < 10mil) Between SMT Small Component C104-4.7uF (2110.208mil,830.709mil) on Bottom Layer And SMT Small Component C94-4.7uF (1988.169mil,881.89mil) on Bottom Layer
Component Clearance Constraint: (Collision < 10mil) Between SMT Small Component C104-4.7uF (2110.208mil,830.709mil) on Bottom Layer And SMT Small Component C99-4.7uF (2110.208mil,881.89mil) on Bottom Layer
Component Clearance Constraint: (Collision < 10mil) Between SMT Small Component C104-4.7uF (2110.208mil,830.709mil) on Bottom Layer And SMT Small Component R2-4.7K (2194.849mil,868.11mil) on Bottom Layer
Component Clearance Constraint: (Collision < 10mil) Between SMT Small Component C105-4.7uF (2232.247mil,830.709mil) on Bottom Layer And SMT Small Component C99-4.7uF (2110.208mil,881.89mil) on Bottom Layer
Component Clearance Constraint: (Collision < 10mil) Between SMT Small Component C105-4.7uF (2232.247mil,830.709mil) on Bottom Layer And SMT Small Component R2-4.7K (2194.849mil,868.11mil) on Bottom Layer
Component Clearance Constraint: (Collision < 10mil) Between SMT Small Component C105-4.7uF (2232.247mil,830.709mil) on Bottom Layer And SMT Small Component R6-4.7K (2242.09mil,868.11mil) on Bottom Layer
Component Clearance Constraint: (Collision < 10mil) Between SMT Small Component C105-4.7uF (2232.247mil,830.709mil) on Bottom Layer And SMT Small Component R7-4.7K (2289.33mil,868.11mil) on Bottom Layer
Component Clearance Constraint: (Collision < 10mil) Between SMT Small Component C106-4.7uF (1622.043mil,881.89mil) on Bottom Layer And SMT Small Component C87-4.7uF (1744.086mil,881.89mil) on Bottom Layer
Component Clearance Constraint: (Collision < 10mil) Between SMT Small Component C11-0.1uF (208.657mil,842.126mil) on Bottom Layer And SMT Small Component C12-0.1uF (299.204mil,842.126mil) on Bottom Layer
Component Clearance Constraint: (Collision < 10mil) Between SMT Small Component C11-0.1uF (208.657mil,842.126mil) on Bottom Layer And SMT Small Component C13-10uF (102.358mil,844.095mil) on Bottom Layer
Component Clearance Constraint: (Collision < 10mil) Between SMT Small Component C12-0.1uF (299.204mil,842.126mil) on Bottom Layer And SMT Small Component R35-4.7K (389.755mil,842.126mil) on Bottom Layer
Component Clearance Constraint: (Collision < 10mil) Between SMT Small Component C123-100nF (2133.869mil,120.079mil) on Bottom Layer And SMT Small Component L7-FB 600R (2033.472mil,120.079mil) on Bottom Layer
Component Clearance Constraint: (Collision < 10mil) Between SMT Small Component C123-100nF (2133.869mil,120.079mil) on Bottom Layer And SMT Small Component R20-1K (2072.834mil,155.508mil) on Bottom Layer
Component Clearance Constraint: (Collision < 10mil) Between SMT Small Component C123-100nF (2133.869mil,120.079mil) on Bottom Layer And SMT Small Component R22-1K (2120.074mil,155.508mil) on Bottom Layer
Component Clearance Constraint: (Collision < 10mil) Between SMT Small Component C123-100nF (2133.869mil,120.079mil) on Bottom Layer And SMT Small Component R23-1K (2167.314mil,155.508mil) on Bottom Layer
Component Clearance Constraint: (Collision < 10mil) Between SMT Small Component C124-470nF (1913.385mil,167.319mil) on Bottom Layer And SMT Small Component L6-FB 600R (1923.232mil,120.079mil) on Bottom Layer
Component Clearance Constraint: (Collision < 10mil) Between SMT Small Component C124-470nF (1913.385mil,167.319mil) on Bottom Layer And SMT Small Component L7-FB 600R (2033.472mil,120.079mil) on Bottom Layer
Component Clearance Constraint: (Collision < 10mil) Between SMT Small Component C124-470nF (1913.385mil,167.319mil) on Bottom Layer And SMT Small Component R17-845 (1828.723mil,155.508mil) on Bottom Layer
Component Clearance Constraint: (Collision < 10mil) Between SMT Small Component C124-470nF (1913.385mil,167.319mil) on Bottom Layer And SMT Small Component R21-1K (2003.937mil,167.319mil) on Bottom Layer
Component Clearance Constraint: (Collision < 10mil) Between SMT Small Component C133-0.1uF (883.857mil,155.508mil) on Bottom Layer And SMT Small Component C134-0.1uF (931.097mil,155.508mil) on Bottom Layer
Component Clearance Constraint: (Collision < 10mil) Between SMT Small Component C133-0.1uF (883.857mil,155.508mil) on Bottom Layer And SMT Small Component C139-4.7uF (944.893mil,120.079mil) on Bottom Layer
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

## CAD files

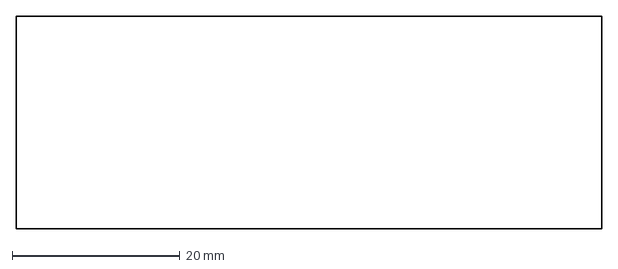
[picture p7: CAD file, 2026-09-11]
Altium_backup/board/zulu_a7_outline.dxf
69.8 x 25.4 mm

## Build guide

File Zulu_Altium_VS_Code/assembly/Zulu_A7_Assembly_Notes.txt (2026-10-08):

ZULU A7 - PCBWAY ASSEMBLY NOTES
Release date: 2026-10-07
Source: working copy after commit 07b7bb4 (the PCB SHA-256 below identifies it)
PCB SHA-256: 89A421B9060195D66BED82F7A4E7D80121BD0E9D679A3FEE32289E8F541F4BDE

UPLOAD SET
PCBWay fabricates the HDI board and assembles it, Turnkey: PCBWay buys every part.
- PCB: Zulu_A7_PCBWay_Fabrication_2026-10-07.zip (Gerbers incl. the GTP/GBP paste
  layers, drill files, PCBWAY_FAB_NOTES.txt), ordered as "HDI (Buried/blind
  vias)" per PCBWAY_FAB_NOTES.txt.
- BOM: Zulu_A7_PCBWay_BOM.csv (PCBWay's BOM template columns). Centroid:
  Zulu_A7_PCBWay_CPL.csv (SMT parts only, both sides in one file).
- Drawings: Zulu_A7_Assembly_Drawing_Top.pdf,
  Zulu_A7_Assembly_Drawing_Bottom.pdf. These notes.
- Preferred: tick Assembly Service on the HDI quote, so it is one order.
  Alternative: once the HDI PCB order exists and before it ships, open a
  separate assembly quote and link it with "Select PCBWay's PCB Order#".
Copy every critical item below into "Detailed information of assembly" and
email this file to Service@pcbway.com with the order number.

RECOMMENDED FORM SETTINGS (adjust if you decide otherwise)
- Assembly: Service = Turnkey; Assembly side(s) = Both sides.
- Number of Unique Parts = 59; Number of SMD Parts = 170;
  Number of BGA/QFP Parts = 2 (U1 BGA, U2 LQFP); Number of Through-Hole
  Parts = 5 (J1 and four X2 strips, 52 joints).
- Contains sensitive components/parts = Yes. Paste into its box:
  "XC7A35T-1CPG236C, FT2232HL-REEL, AS4C32M16SB-7TCN, W25Q128JVSIQ,
  BQ24232RGTR: moisture sensitive, follow the MSL label, bake if floor life
  is exceeded. XC7A35T-1CPG236C: 0.5 mm BGA, X-ray every board. 105017-0001:
  one reflow cycle maximum."
- Do you accept alternatives/substitutes made in China = No.
- Number of X-ray test = the number of boards ordered (one X-ray of U1 per
  board); please confirm what this field counts.
- PCB: surface finish ENIG recommended (0.225 mm BGA lands, 0201 pads).
- Panel (the board is only 69.85 x 25.40 mm): PCB Board type = Panel by
  Supplier; Break-away rail = Yes; Route Process = Panel as Tab Route;
  X-out Allowance = Not Accept. Assembly Board type = Panelized PCBs;
  Depanel the boards to delivery = Yes.

ASSEMBLY SCOPE
Fitted PCB designators: 172
Top-side fitted designators: 32
Bottom-side fitted designators: 140
Physical parts per board: 175 (X2 is four strips under one designator)
BOM purchase lines: 59; DNS lines: 2 (JP3, JP4)
Assembly is required on both sides: SMT bottom, SMT top, then hand soldering.
BGA: U1 only, XC7A35T-1CPG236C, 0.5 mm pitch, 238 round lands of
0.225 mm. Other 0.5 mm pitch: U2 LQFP-64 (top), U8 VQFN-16 with
exposed pad (bottom). Smallest package 0201: 76 parts (4 on top).
Board: 69.85 x 25.40 mm, six-layer two-step sequential HDI, about 1.63 mm
thick with solder mask.

HDI AND U1 ORDER GATE
The bare board is a 1+1+N+1+1 HDI build with stacked, copper-filled laser
microvias and an L3-L4 buried-via stage, quoted manually after engineering
review (PCBWAY_FAB_NOTES.txt). Before payment, please confirm in writing:
- turnkey assembly is accepted on this HDI build within the same order;
- U1's 0.225 mm round lands (0.5 mm pitch) are within your fabrication
  line and the assembly process you quote;
- U1's top-side land field holds 59 plated 0.20 mm through vias (all at depopulated
  ball sites) and 33 Top-L2 laser microvias (10 at depopulated ball sites, 16
  interstitial, 7 elsewhere in the field). No via is in a land.
  The through vias are tented but not filled. Per your BGA rule (tent and
  fill vias near BGA pads), please plug or fill them and quote the method.
PANEL: please send the panel drawing for approval before production.
- Copper reaches about 0.3 mm from the board edge: rails on the long edges
  and tab routing, not V-score.
- Keep tabs clear of X1 (top edge, X about 29-37 mm) and X4 (bottom edge,
  X about 28-37 mm). X2's housings seat along both long edges: no tab
  residue where a housing seats.
- MLCCs sit about 3 mm from the long edges: depanel with a router or
  cutter, not by hand-snapping. Depanel before fitting X2.
- The board has no fiducials. Please put global fiducials on the rails
  (top and bottom) and confirm that they suffice for U1 and the 0201s,
  or propose another alignment method.

CPL AND ORIENTATION
Zulu_A7_PCBWay_CPL.csv: Designator, Mid X, Mid Y, Layer (Top/Bottom), Rotation.
It lists the SMT parts only; J1 and X2 are hand-soldered and are not in it.
If your line needs one file per side, please split it by the Layer column.
- Units are millimetres ("mm" suffix). Origin: the board's lower-left
  corner; the outline runs from 0,0 to 69.85,25.40.
- Coordinates on both sides are as viewed from the top. Bottom-side X
  values are NOT mirrored.
- Mid X/Y is the centre of each part's pad extents, not the footprint
  origin. For connectors (X1, X3, X4) align the part to its pads in CAM.
- Rotations are the values stored in the final Altium PCB, in degrees
  (0/90/180/270), not converted for bottom-side parts. Please confirm your
  bottom-side convention against the bottom drawing before programming.
- The top drawing is viewed from the top; the bottom drawing is mirrored,
  viewed from the bottom. Red dot = pin 1/A1; red bar = LED cathode (K);
  dashed red label = DNP. The silkscreen has no polarity marks, so the
  drawings and this file are the orientation reference.
If the CPL and a drawing disagree, please send an engineering query.

SPECIAL COMPONENT INSTRUCTIONS
- Reflow order: bottom side FIRST, top side LAST. X1 is rated for one
  reflow cycle and U1 should see only one. Then hand-solder J1, X2 and
  X1's shell stakes.
- X2 is not one 40-pin part: four single-row 2.54 mm THT strips mounted on
  the underside, 2 x Sullins PRPC009SAAN-RC (X2 pins 1-9, 21-29) and
  2 x PRPC011SAAN-RC (pins 10-20, 30-40). The BOM has one line per strip
  part number with designator X2 on both. Housings on the BOTTOM side;
  insert the SHORT post end (about 3 mm) up through the board so about
  1.4 mm stands on top for soldering; the LONG mating end points down.
  Solder on top by hand or selectively, after both reflows and depanel.
  Fit check: in plan view the housings overlap the pads of C87, C88, C94, C99,
  C106, R1 (worst 0.14 mm) and come within 0.1 mm of C3, C4, C8, C36, C37,
  C139, L4, L5, L6, L7, R10, R11, U10. Seat each strip without force, check
  that it sits flush on the first article, and report any interference rather
  than forcing it.
  If you cannot quote X2, leave it unpopulated, do not buy the strips,
  and say so in the quotation.
- J1 (Sullins PPTC062LFBN-RC): vertical 2x6 female Pmod header, top side.
  Pin 1 is the square pad. Hand or selective solder after both reflows.
- JP3 and JP4 are intentional DNS flying-lead/pogo positions (DNS rows in
  the BOM): bare plated holes, no paste, leave empty.
- X1 (Molex 105017-0001 micro-USB-B, top side) opens toward the upper
  board edge. Its shell stakes go into the plated 0.60 x 1.30 mm slots
  MS1/MS2 at the mating-face end, beside the board edge. The MP1/MP4
  paste only tacks them: please hand-solder MS1/MS2 from the bottom side
  after reflow to
  full barrel fill. Please confirm from the Molex drawing whether the
  MH1/MH2 locating pegs are to be soldered.
- X3 (Hirose DM3D-SF microSD, top side): the card opening faces the left
  board edge.
- X4 (JST B2B-PH-SM4-TB, top side): pin 1 (the west contact) is battery
  positive, pin 2 is GND.
- U5, U6 and U7 are look-alike Semtech SC189 bucks (SOT23-5, bottom side):
  U5 = SC189ZSKTRT (3.3 V), U6 = SC189LSKTRT (1.8 V), U7 = SC189ASKTRT
  (1.0 V, FPGA core). A U5/U7 swap puts 3.3 V on U1's core. Check reel and
  marking at each position on the first article.
- LD1, LD2, LD3, LD4, LD5 (0603): cathode = pad K on the EAST side (X 24.15 mm);
  all face the same way. The drawings mark it with a red bar.
- LD0 (Everlight EAST1616RGBA8, 1.6 x 1.6 mm): cathodes are pads 2, 4, 6
  on the WEST side, anodes 1, 3, 5 on the east side, opposite to the
  0603 LEDs. The drawing's red dot marks pad 1, an anode. The land is
  symmetric, so a part turned 180 degrees fits but stays dark.
- Verify pin 1/A1 against the drawings on U1, U2, U3, U4, U5, U6, U7, U8,
  U10, Q1 and X4.
- Stencil from the GTP/GBP layers, whose apertures are 1:1 with copper.
  Please apply your house reductions, in particular: U2 LQFP-64 0.5 mm
  pitch; U8 exposed pad (about 85 % area, windowpane); U1 0.225 mm round
  apertures need a thin stencil (0.08 mm or thinner suggested) and a
  paste that releases them reliably.

SOURCING
Please buy by the Manufacturer and Mfg Part # columns; every purchase line
carries an exact manufacturer part number. Nothing is consigned.
- Make no substitution without our written approval. Report any line with
  no stock, a lifecycle problem or an ambiguous MPN as an engineering query.
- U1 XC7A35T-1CPG236C: AMD-authorized distributors only (e.g. Digi-Key,
  Mouser, Avnet); no local, broker or open-market stock. Ask us first if
  none can supply it.
- U2 FT2232HL-REEL: FTDI-authorized distributors only (FTDI clones exist).
- The BOM's last column carries per-line instructions; please follow them.

QUALITY AND TEST
- Lead-free (SAC) solder process.
- Moisture-sensitive parts: U1, U2, U3, U4 and U8. Follow their MSL labels
  for storage, floor life and bake.
- X-ray U1 on every board and include it in the quotation.
- AOI on both sides; workmanship to IPC-A-610 Class 2.
- No firmware programming or functional test is included unless separately
  quoted and supplied with a test procedure and programming image.
- First article: please send photos of BOTH sides and the U1 X-ray images,
  and wait for our approval before building the rest.

REQUIRED ORDER REVIEW
Before releasing the order, please confirm in writing:
- the HDI fabrication quote, with turnkey assembly on the same order;
- U1 land acceptance, and the plugging or filling of the vias near U1;
- the panel drawing, tab positions and rail fiducials (and that rail
  fiducials alone suffice);
- your bottom-side CPL rotation convention;
- authorized sourcing for U1 and U2, and any lines with no stock;
- hand soldering of X2's four strips and X1's stakes, or X2 left
  unpopulated;
- the stencil apertures for U1, U2 and U8, and X-ray of U1 (and what the
  Number of X-ray test field counts);
- polarity and pin 1 against both drawings, then first-article approval.

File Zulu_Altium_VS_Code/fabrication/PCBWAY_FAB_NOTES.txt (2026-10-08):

ZULU A7 - PCBWAY FABRICATION NOTES
Release date: 2026-10-07
Source: working copy after commit 07b7bb4 plus the 2026-10-07 BTN move;
zulu_a7.PcbDoc SHA-256
89a421b9060195d66bed82f7a4e7d80121bd0e9d679a3fee32289e8f541f4bde

FABRICATOR
PCBWay, bare-board fabrication. Order as Material "HDI (Buried/blind vias)"
with Custom stackup ticked and impedance control ticked. Online HDI pricing
covers 1+N+1 only, so this two-step build needs a manual quotation and
engineering review before release.

HDI CONSTRUCTION (sequential 1+1+N+1+1, symmetric)
  Top -> L2       0.15 mm laser microvia
  L2 -> L3        0.15 mm laser microvia
  L3 -> L4        0.15 mm mechanically drilled buried via (in the core)
  L4 -> L5        0.15 mm laser microvia
  L5 -> Bottom    0.15 mm laser microvia
  Top -> Bottom   0.20 mm plated through via
Stacked adjacent-layer microvias share XY locations: copper-fill and planarize
them ("Via filled with copper"). The vias in U1's land field (0.5 mm BGA)
sit at depopulated ball sites or interstitial positions, never in a land, so no
via-in-pad is required. The 0.20 mm through vias there are tented but not
filled: please plug or fill them per your BGA rule (tent and fill vias near BGA
pads) and state the method in the quotation.
Via-in-pad occurs only at BTN (PTS810 switch, top side): three filled Top-L2
microvias overlap its pads 1, 3 and 4 (pad 3's lies inside the pad; the other
two cross the pad edge). Copper-fill and cap them flat (VIPPO) so the pads
take paste normally.

TARGET STACKUP (as modelled in the PCB file; please return your proposed
manufacturable stack with pressed thicknesses and Dk for approval)
  L1  Top          copper 0.035
      Prepreg      0.112   (2116-class; design assumed Dk 4.29)
  L2  GND          copper 0.030
      Prepreg      0.112
  L3  Signal       copper 0.030
      Core         0.930   (Dk 4.6 assumed)
  L4  Signal       copper 0.030
      Prepreg      0.112
  L5  VCC3V3       copper 0.030
      Prepreg      0.112
  L6  Bottom       copper 0.035
  Laminate about 1.57 mm; about 1.63 mm with solder mask. Inner copper 1 oz.
The outer prepregs carry the 0.15 mm laser vias, so keep them at or below
about 0.12 mm (1:1 laser aspect ratio).

CONTROLLED IMPEDANCE
USB_D_P / USB_D_N: 90 ohm differential, +/-10 %.
Top layer, 0.150 mm trace / 0.150 mm gap, referenced to L2 GND.
Please return the calculated impedance on your stack; trace width may be
adjusted by your CAM within tolerance.

BOARD
Finished outline 69.85 mm x 25.40 mm. Layer order:
  L1  Top
  L2  GND plane polygon (positive plot)
  L3  Signal
  L4  Signal
  L5  VCC3V3 plane polygon (positive plot)
  L6  Bottom
The L2 and L5 Gerbers are positive polygon plots, not negative plane files.

VIA AND HOLE GEOMETRY
Laser microvias: 0.15 mm hole / 0.30 mm land
L3-L4 buried vias: 0.15 mm hole / 0.27 mm land
Signal through vias: 0.20 mm hole / 0.35 mm land
Component holes: 0.85 mm (X1 MH1/MH2) and 1.016 mm (headers), plated.
There are no non-plated holes.

PLATED SLOTS (X1, Molex 105017-0001 micro-USB-B front shell stakes)
Two plated slots, 0.60 mm wide x 1.30 mm long overall, long axis
perpendicular to the board edge, centred at X 29.520 / Y 23.959 mm and
X 36.520 / Y 23.959 mm. They are in zulu_a7-SlotHoles.TXT as G85 drilled
slots (0.60 mm tool, 0.70 mm between end centres). They are oval; do not
make them round. There are no slots on GKO/GM1. Lands: 1.11 x 1.81 mm oblong
on Top and Bottom (0.255 mm ring), 0.90 x 1.60 mm on the inner layers.

ITEMS FOR ENGINEERING REVIEW (the design was drawn to tighter limits than
some of your published "normal" values; please confirm or propose changes)
  - Minimum track / space 0.0762 / 0.09 mm (3.0 / 3.5 mil) on all layers.
  - Via annular rings: through 0.075 mm, laser 0.075 mm, buried 0.06 mm.
  - Different-net via hole-to-hole down to 0.24 mm.
  - 0.20 mm through vias in a board of about 1.63 mm (aspect about 8:1).
  - Laser and buried via holes to inner plane copper about 0.165 mm
    (0.075 mm ring + 0.09 mm clearance).

FILE MAP
  zulu_a7.GTL   Top copper
  zulu_a7.G1    L2 GND
  zulu_a7.G2    L3 signal
  zulu_a7.G3    L4 signal
  zulu_a7.G4    L5 VCC3V3
  zulu_a7.GBL   Bottom copper
  zulu_a7.GTS   Top solder mask
  zulu_a7.GBS   Bottom solder mask
  zulu_a7.GTO   Top silkscreen
  zulu_a7.GBO   Bottom silkscreen
  zulu_a7.GTP   Top paste
  zulu_a7.GBP   Bottom paste
  zulu_a7.GM    Board profile
  zulu_a7-RoundHoles.TXT   Top-Bottom plated round holes
  zulu_a7-SlotHoles.TXT    Top-Bottom plated slots (X1, G85)
  zulu_a7-RoundHoles.TX3   L3-L4 buried vias
  zulu_a7-RoundHoles.TX6   Top-L2 microvias
  zulu_a7-RoundHoles.TX7   L2-L3 microvias
  zulu_a7-RoundHoles.TX9   L4-L5 microvias
  zulu_a7-RoundHoles.TX10  L5-Bottom microvias
  zulu_a7.LDP   Drill-pair layer map
  zulu_a7.DRR   Drill sizes and counts

FINAL VERIFICATION
Altium DRC 2026-10-07 16:53 (after the final save): 0 warnings, 0 rule violations
Gerbers: metric RS-274X, 0.0001 mm coordinate resolution
Microvias: 1,041 total; L3-L4 buried vias: 370; signal through vias: 379;
plated slots: 2 (X1).

Solder-mask colour, surface finish, quantity and panelization are order
selections and are not encoded by this text file.

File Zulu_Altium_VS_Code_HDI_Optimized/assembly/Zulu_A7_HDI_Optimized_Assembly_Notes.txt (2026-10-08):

ZULU A7 HDI OPTIMIZED - ASSEMBLY NOTES
Release date: 2026-10-07
Source: working copy after commit 07b7bb4 (the PCB SHA-256 below identifies it)
PCB SHA-256: F97D0F4D6FB9439ADDF64BD6DA2620E2BF3D35228E0CC4B053859F38BDB5E64B

UPLOAD SET
Provide the fabrication ZIP to the PCB fabricator and provide this BOM,
CPL, both drawings, and these notes separately to the assembly provider.
Copy all critical instructions into the quotation/order remarks.

ASSEMBLY SCOPE
Fitted PCB designators: 172
Top-side fitted designators: 32
Bottom-side fitted designators: 140
Do not populate: JP3, JP4
Assembly is required on both sides.

ASSEMBLER QUALIFICATION
JLCPCB does not support assembly of this HDI board. Use a separate
assembler qualified for six-layer two-step sequential HDI, stacked
laser microvias, an L3-L4 buried-via stage, 0201 parts, two-sided SMT,
mixed SMT/THT assembly, and X-ray inspection of the CPG236 BGA.

CPL AND ORIENTATION
CPL units are millimetres from the board lower-left origin. The top drawing
is viewed from the top; the bottom drawing is mirrored and viewed from the
bottom. CPL rotations are the rotations stored in the final Altium PCB.
Review every polarized part and all rotations in the assembly provider's placement preview.
Do not approve the order if the preview disagrees with either assembly drawing.

SPECIAL COMPONENT INSTRUCTIONS
- X2 is not one 40-pin component. It is four underside-mounted THT strips:
  2 x PRPC009SAAN-RC (9-pin) and 2 x PRPC011SAAN-RC (11-pin). The BOM
  therefore reports physical quantity 4 for the single PCB designator X2.
  Quote this as manual THT work. If the assembler cannot process that exception,
  leave X2 unpopulated for post-assembly installation.
- J1 is a vertical 2x6 female through-hole Pmod header on the top side.
- JP3 and JP4 are intentional DNP flying-lead/pogo positions.
- X4 pin 1 is battery positive.
- X3's microSD card opening faces the left board edge.
- X1's micro-USB opening faces the upper board edge.
- X1-MS1/MS2 are plated 0.60 x 1.30 mm front shell-stake slots. Confirm
  that both connector shell stakes seat fully before soldering.
- Verify pin 1/A1 on U1, U2, U3, U4, U8, U10, Q1, and every polarized LED.
- LD0 cathodes are pads 2, 4, and 6; its anodes are pads 1, 3, and 5.

SOURCING
The LCSC codes in the BOM are exact identities captured by the project's
September 2026 sourcing audit, not a claim of current stock. Revalidate
manufacturer, MPN, package, lifecycle, authenticity, and stock using
the selected supplier's live parts system. Do not make substitutions
without written approval.
BOM lines without a verified exact LCSC code: 17
  C124: CL05A474KO5NNNC (C0402)
  L1,L2,L3: DFE252010P-1R5M=P2 (IND2520)
  LD0: EAST1616RGBA8 (EVERLIGHT-19-337)
  R1: 742C043472JP (742C043)
  R2,R6,R7,R99: RC0201FR-074K7L (R0201)
  R4: 742C163101JP (742C163)
  R10,R14: RC0201FR-072K32L (R0201)
  R12,R16: RC0201FR-07140RL (R0201)
  R101: RC0201FR-072K21L (R0201)
  R102: RC0402FR-073K57L (R0402)
  R103: RC0402FR-073K09L (R0402)
  R104: RC0402FR-0756K2L (R0402)
  R105: RC0402FR-074K32L (R0402)
  R107,R108: RC0402FR-071K5L (R0402)
  U3: AS4C32M16SB-7TCN (TSOPII-54)
  U7: SC189ASKTRT (SOT23-5)
  X2: 2x PRPC009SAAN-RC + 2x PRPC011SAAN-RC (ZULU-DIP37)

QUALITY AND TEST
- Inspect all BGA joints for U1 with the process controls appropriate to
  an Artix-7 CPG236 package; follow MSL storage/bake requirements.
- No firmware programming or functional test is included unless separately
  quoted and supplied with a test procedure and programming image.
- Request first-article inspection and placement-photo approval before the
  remainder of the build.

REQUIRED ORDER REVIEW
Confirm HDI-capable two-sided SMT/THT assembly, BGA X-ray inspection,
X2's four-piece manual installation, unresolved/consigned parts,
polarity, and placement preview before releasing the order.

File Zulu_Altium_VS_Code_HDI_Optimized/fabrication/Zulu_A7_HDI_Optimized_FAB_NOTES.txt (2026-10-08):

ZULU A7 HDI OPTIMIZED - JLCPCB FABRICATION NOTES
Release date: 2026-10-07
PCB SHA-256: F97D0F4D6FB9439ADDF64BD6DA2620E2BF3D35228E0CC4B053859F38BDB5E64B

FABRICATOR AND ASSEMBLY LIMITATION
This bare-board release targets the named JLCPCB six-layer stack
JLC06161H-3313E. Select that stack by name in the impedance-control flow
and place it on the order acknowledgement. Do not substitute the similarly
named -3313 or -1080 stacks.

Request JLCPCB engineering review and a manual HDI fabrication quotation
before release. JLCPCB does not support assembly of this HDI board. Send the
separate assembly release to a qualified HDI-capable assembly provider.

BOARD
Finished outline: 69.85 mm x 25.40 mm
Layer order:
  L1  Top
  L2  GND plane polygon
  L3  Signal
  L4  Signal
  L5  VCC3V3 plane polygon
  L6  Bottom

The L2 and L5 Gerbers are positive signal-layer polygon plots, not negative
plane files.

HDI CONSTRUCTION
The drill data requires a symmetric two-step sequential buildup:
  Top -> L2       0.15 mm laser microvia
  L2 -> L3        0.15 mm laser microvia
  L3 -> L4        0.15 mm mechanically drilled buried via
  L4 -> L5        0.15 mm laser microvia
  L5 -> Bottom    0.15 mm laser microvia
  Top -> Bottom   0.20 mm plated through via

Stacked adjacent-layer microvias occur at common XY locations. Apply JLCPCB's
required copper fill and planarization process for stacked microvias.
Via-in-pad occurs only at BTN (PTS810 switch, top side): three filled Top-L2
microvias overlap its pads 1, 3 and 4 (pad 3's lies inside the pad; the other
two cross the pad edge). Copper-fill and cap them flat (VIPPO) so the pads
take paste normally.

VIA GEOMETRY AND DRILL COUNTS
Laser microvias: 0.15 mm hole / 0.30 mm land
L3-L4 buried vias: 0.15 mm hole / 0.27 mm land
Signal through vias: 0.20 mm hole / 0.35 mm land

  Top -> Bottom signal through vias: 392
  Top -> L2 microvias:               292
  L2 -> L3 microvias:                279
  L3 -> L4 buried vias:              363
  L4 -> L5 microvias:                223
  L5 -> Bottom microvias:            222
  Total laser-microvia records:    1,016

The Top-Bottom round-hole drill file also contains two 0.85 mm and 58
1.016 mm plated component holes. There are no separate non-plated holes.

X1 MOLEX 105017-0001 PLATED SLOTS
X1-MS1 and X1-MS2 are two plated, vertical 0.60 mm x 1.30 mm full-radius
front shell slots (mating-face end). Their centers are (29.5199, 23.9585) mm and
(36.5201, 23.9585) mm. The dedicated SlotHoles file uses a 0.60 mm tool
over a 0.70 mm G85 centerline route to produce the 1.30 mm overall length.
Do not convert these slots to round holes or treat them as non-plated.
Slot lands: 1.11 x 1.81 mm oblong on Top and Bottom (0.255 mm ring),
0.90 x 1.60 mm oblong on L2-L5. Other-net copper is at least 0.247 mm
from the slot walls on every layer.

CONTROLLED IMPEDANCE
USB_D_P / USB_D_N: 90 ohm differential target
Top-layer geometry: 0.15 mm trace / 0.15 mm pair gap, referenced to L2 GND

FILE MAP
  zulu_a7_hdi_optimized.GTL   Top copper
  zulu_a7_hdi_optimized.G1    L2 GND
  zulu_a7_hdi_optimized.G2    L3 signal
  zulu_a7_hdi_optimized.G3    L4 signal
  zulu_a7_hdi_optimized.G4    L5 VCC3V3
  zulu_a7_hdi_optimized.GBL   Bottom copper
  zulu_a7_hdi_optimized.GTS   Top solder mask
  zulu_a7_hdi_optimized.GBS   Bottom solder mask
  zulu_a7_hdi_optimized.GTO   Top silkscreen
  zulu_a7_hdi_optimized.GBO   Bottom silkscreen
  zulu_a7_hdi_optimized.GTP   Top paste
  zulu_a7_hdi_optimized.GBP   Bottom paste
  zulu_a7_hdi_optimized.GM    Board profile
  zulu_a7_hdi_optimized-RoundHoles.TXT   Top-Bottom plated round holes
  zulu_a7_hdi_optimized-SlotHoles.TXT    Top-Bottom plated X1 slots
  zulu_a7_hdi_optimized-RoundHoles.TX3   L3-L4 buried vias
  zulu_a7_hdi_optimized-RoundHoles.TX6   Top-L2 microvias
  zulu_a7_hdi_optimized-RoundHoles.TX7   L2-L3 microvias
  zulu_a7_hdi_optimized-RoundHoles.TX9   L4-L5 microvias
  zulu_a7_hdi_optimized-RoundHoles.TX10  L5-Bottom microvias
  zulu_a7_hdi_optimized.LDP   Drill-pair layer map
  zulu_a7_hdi_optimized.DRR   Drill sizes and counts

FINAL VERIFICATION
Altium DRC 2026-10-07 16:48: 0 warnings, 0 rule violations
Gerbers: metric RS-274X, 0.0001 mm coordinate resolution
NC Drill: metric Excellon, separate round/slot files, G85 plated slots
Total via objects: 1,771
Physical HDI sites: 689

Solder-mask color, surface finish, finished copper options, quantity, and
panelization are order selections and are not encoded by this text file.

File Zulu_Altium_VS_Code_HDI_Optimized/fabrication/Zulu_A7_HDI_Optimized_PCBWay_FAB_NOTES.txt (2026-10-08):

ZULU A7 HDI OPTIMIZED - PCBWAY FABRICATION NOTES
Release date: 2026-10-07
PCB SHA-256: F97D0F4D6FB9439ADDF64BD6DA2620E2BF3D35228E0CC4B053859F38BDB5E64B

ORDER AND CAM GATE
This is a bare-board, six-layer, two-step sequential HDI release. Route it to
PCBWay HDI engineering/CAM review. Do not release fabrication as a standard
six-layer prototype without confirming every blind/buried drill pair.

PCBWay previously advised this project that its controlled-impedance stack is
customized from the impedance target rather than selected from a committed
standard stack. Return the proposed materials, copper weights, dielectric
thicknesses, finished thickness, lamination sequence, and calculated USB
impedance for written approval before fabrication. Do not silently substitute
a standard stack or change the artwork.

BOARD
Finished outline: 69.85 mm x 25.40 mm
Nominal thickness class: 1.6 mm
Surface finish: ENIG
Solder mask: green
Silkscreen: white
Layer order:
  L1  Top signal/components
  L2  GND plane polygon
  L3  Signal
  L4  Signal
  L5  VCC3V3 plane polygon
  L6  Bottom signal/components

The L2 and L5 Gerbers are positive signal-layer polygon plots, not negative
plane files. Minimum designed signal trace width is 0.0762 mm. Minimum designed
copper spacing is 0.09 mm. Do not globally resize copper without approval.

NOMINAL ELECTRICAL STACK TARGET
The source board was routed and checked against this nominal construction:

  Layer/material                         Thickness       Nominal Dk
  L1 finished copper                     0.0350 mm
  3313 prepreg, L1-L2 gap                0.0994 mm       4.100
  L2 finished copper                     0.0152 mm
  Core, L2-L3 gap                        0.1000 mm       4.600
  L3 finished copper                     0.0152 mm
  Central bonded structure, L3-L4 gap    1.1208 mm       4.523 effective
  L4 finished copper                     0.0152 mm
  Core, L4-L5 gap                        0.1000 mm       4.600
  L5 finished copper                     0.0152 mm
  3313 prepreg, L5-L6 gap                0.0994 mm       4.100
  L6 finished copper                     0.0350 mm

Nominal laminate thickness: 1.65038 mm
Nominal total with 0.01016 mm solder mask per side: 1.67070 mm

The central 1.1208 mm row is an electrical solver model of the bonded central
structure, not a mandatory material recipe. PCBWay may propose a manufacturable
equivalent, but L2-L3 and L4-L5 must remain close reference-plane gaps and the
large separation between L3 and L4 must be preserved as closely as practical.
Do not substitute 1 oz inner copper without confirming that every 0.0762 mm
trace and 0.09 mm spacing remains manufacturable.

HDI CONSTRUCTION
The drill data requires a symmetric two-step sequential buildup:
  Top -> L2       0.15 mm laser microvia
  L2 -> L3        0.15 mm laser microvia
  L3 -> L4        0.15 mm mechanically drilled buried via
  L4 -> L5        0.15 mm laser microvia
  L5 -> Bottom    0.15 mm laser microvia
  Top -> Bottom   0.20 mm plated through via

Adjacent-layer laser microvias are stacked at common XY locations. Fill and
planarize the receiving microvias before the next buildup step. Confirm the
complete lamination and fill/cap process in the CAM response.
Via-in-pad occurs only at BTN (PTS810 switch, top side): three filled Top-L2
microvias overlap its pads 1, 3 and 4 (pad 3's lies inside the pad; the other
two cross the pad edge). Copper-fill and cap them flat (VIPPO) so the pads
take paste normally.

VIA GEOMETRY AND DRILL COUNTS
Laser microvias: 0.15 mm hole / 0.30 mm land
L3-L4 buried vias: 0.15 mm hole / 0.27 mm land
Signal through vias: 0.20 mm hole / 0.35 mm land

  Top -> Bottom signal through vias: 392
  Top -> L2 microvias:               292
  L2 -> L3 microvias:                279
  L3 -> L4 buried vias:              363
  L4 -> L5 microvias:                223
  L5 -> Bottom microvias:            222
  Total laser-microvia records:    1,016

The Top-Bottom round-hole drill file also contains two 0.85 mm and 58
1.016 mm plated component holes. There are no non-plated holes.

X1 MOLEX 105017-0001 PLATED SLOTS
X1-MS1 and X1-MS2 are two plated, vertical 0.60 mm x 1.30 mm full-radius
front shell slots (mating-face end). Their centers are (29.5199, 23.9585) mm and
(36.5201, 23.9585) mm. The dedicated SlotHoles file uses a 0.60 mm tool
over a 0.70 mm G85 centerline route to produce the 1.30 mm overall length.
Do not convert these slots to round holes or treat them as non-plated.
Slot lands: 1.11 x 1.81 mm oblong on Top and Bottom (0.255 mm ring),
0.90 x 1.60 mm oblong on L2-L5. Other-net copper is at least 0.247 mm
from the slot walls on every layer.

CONTROLLED IMPEDANCE
USB_D_P / USB_D_N: 90 ohm differential, +/-10 percent
Layer/reference: L1 Top referenced to L2 GND
Drawn geometry: 0.15 mm trace / 0.15 mm pair gap

Use the returned CAM stack to calculate this pair. If the target cannot be met
without changing the drawn geometry, stop and request approval. Provide the
final impedance calculation and, if included in the quotation, coupon results.

FILE MAP
  zulu_a7_hdi_optimized.GTL   L1 Top copper
  zulu_a7_hdi_optimized.G1    L2 GND
  zulu_a7_hdi_optimized.G2    L3 signal
  zulu_a7_hdi_optimized.G3    L4 signal
  zulu_a7_hdi_optimized.G4    L5 VCC3V3
  zulu_a7_hdi_optimized.GBL   L6 Bottom copper
  zulu_a7_hdi_optimized.GTS   Top solder mask
  zulu_a7_hdi_optimized.GBS   Bottom solder mask
  zulu_a7_hdi_optimized.GTO   Top silkscreen
  zulu_a7_hdi_optimized.GBO   Bottom silkscreen
  zulu_a7_hdi_optimized.GTP   Top paste
  zulu_a7_hdi_optimized.GBP   Bottom paste
  zulu_a7_hdi_optimized.GM    Board profile
  zulu_a7_hdi_optimized-RoundHoles.TXT   Top-Bottom plated round holes
  zulu_a7_hdi_optimized-SlotHoles.TXT    Top-Bottom plated X1 slots
  zulu_a7_hdi_optimized-RoundHoles.TX3   L3-L4 buried vias
  zulu_a7_hdi_optimized-RoundHoles.TX6   Top-L2 microvias
  zulu_a7_hdi_optimized-RoundHoles.TX7   L2-L3 microvias
  zulu_a7_hdi_optimized-RoundHoles.TX9   L4-L5 microvias
  zulu_a7_hdi_optimized-RoundHoles.TX10  L5-Bottom microvias
  zulu_a7_hdi_optimized.LDP   Drill-pair layer map
  zulu_a7_hdi_optimized.DRR   Drill sizes and counts

FINAL VERIFICATION
Altium DRC 2026-10-07 16:48: 0 warnings, 0 rule violations
Gerbers: metric RS-274X, 0.0001 mm coordinate resolution
NC Drill: metric Excellon, separate round/slot files, G85 plated slots
Total via objects: 1,771
Physical HDI sites: 689

This ZIP intentionally contains fabrication data only. Assembly BOM, CPL,
drawings, and assembly instructions are supplied separately if assembly is
quoted.

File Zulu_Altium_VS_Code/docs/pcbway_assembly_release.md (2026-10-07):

# PCBWay assembly release (2026-10-07)

Fabrication moved to PCBWay, so the production assembly release now targets a PCBWay turnkey order, in which
PCBWay fabricates the HDI board and assembles it. `tools/generate_jlcpcb_assembly.py` gained
`--assembler {pcbway,jlcpcb,neutral}`.
- **pcbway:** the default.
- **jlcpcb:** reproduces the old JLCPCB files byte for byte.
- **neutral:** what the HDI copy uses. `--assembler-neutral` still works.

## Files (`assembly/`)

| File | What changed for PCBWay |
|---|---|
| `Zulu_A7_PCBWay_BOM.csv` (was `Zulu_A7_JLCPCB_BOM.csv`) | See the BOM list below. |
| `Zulu_A7_PCBWay_CPL.csv` (was `Zulu_A7_JLCPCB_CPL.csv`) | SMT parts only (PCBWay's centroid rule): J1 and X2 are hand-soldered. Every other row is unchanged. |
| `Zulu_A7_Assembly_Notes.txt` | Rewritten for PCBWay; see the notes list below. |
| Assembly drawings | The LED cathode (pad K) is marked with a red bar. LD1-LD5 had no polarity mark anywhere in the release. The footer refers to PCBWay's engineering review. |

The new BOM:
- **Columns:** PCBWay's own template: Item #, Designator, Qty, Manufacturer, Mfg Part #, Description / Value,
  Package/Footprint, Type (SMD / thru-hole / DNS), Your Instructions / Notes.
- **No LCSC column and no "consign" wording.** PCBWay buys by manufacturer part number.
- **X2** is split into its two strip part numbers (PRPC009SAAN-RC x2, PRPC011SAAN-RC x2).
- **JP3/JP4** appear as DNS rows.
- **Per-line instructions:**
  - U1 and U2: authorized channels only.
  - SC189 look-alikes: which voltage goes where.
  - LED polarity.
  - X1: one reflow only.
  - X2: pin orientation.
- **Descriptions** are the schematic SPEC without its design commentary.

The new notes:
- **Upload set:** with the recommended form settings (unique parts 59, SMD 170, BGA/QFP 2, THT 5 strips with 52
  joints).
- **Sensitive parts:** text ready to paste into the sensitive-parts box.
- **Order settings:** X-ray count, panelization (Panel by Supplier, rails, tab route, depanel by router) and
  fiducials on the rails.
- **HDI and U1 gate:**
  - U1's top land field holds 59 tented but unfilled 0.20 mm through vias, all at depopulated ball sites. The
    sites are classified by U1's 0.5 mm grid, as an independent check found.
  - PCBWay's BGA rule asks for them to be plugged.
- **CPL conventions.**
- **Reflow order:** bottom first, top last. X1 is rated for one reflow.
- **X2:** the short post end goes up through the board, and the housings overlap R1 and five 0603 caps in plan view.
- **X1:** stakes hand-soldered after reflow.
- **Polarity:** LED polarity by side and X, and look-alike-part checks.
- **Stencil and sourcing:** stencil notes; sourcing with no substitution without approval.
- **QA and order review:** a QA list and the order-review checklist.

## How it was checked

- **Research and review:** a research workflow read PCBWay's pages (BOM template, centroid rules, DNP marking,
  substitutes, sourcing policy, the order-form fields) and the project files, and drafted the notes. Three
  independent reviewers then tried to refute the draft, checking:
  - the PCBWay facts;
  - the board and BOM facts;
  - completeness for an assembly engineer.
- **Reviewer findings applied:**
  - the "consign" wording in the old BOM;
  - LD1-LD5 had no polarity mark;
  - X2's pin orientation was unstated;
  - X1's stake fill;
  - the U1 via plugging;
  - the panel form fields;
  - the THT rows in the CPL;
  - the 58-line vs 59-part count.
- **Generator checks:** it validates the PCBWay BOM columns and quantities, the DNS rows, the SMT-only CPL, and
  that the notes contain no JLCPCB/LCSC text and no line over 88 characters.
- **Not pre-approved:** the alternates in `docs/pcbway_bom_substitutes.csv` (2026-09-08, partly stale) were left
  out. The notes ask PCBWay to raise an engineering query rather than substitute.
- **Fab notes, U1 vias:** `PCBWAY_FAB_NOTES.txt` called U1's vias interstitial. It now says where they sit
  and asks PCBWay to plug or fill the through vias, matching the assembly notes.
- **Fab notes, X1 slots:** `PCBWAY_FAB_NOTES.txt` called X1's slots "rear shell legs". They are the front shell stakes at the
  mating-face end beside the board edge (MH1/MH2 are the rear pegs). The wording was corrected here and in the
  HDI copy's notes.

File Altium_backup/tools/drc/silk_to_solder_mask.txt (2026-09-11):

Silk To Solder Mask (Clearance=10mil) (IsPad),(All)
===================================================
Silk To Solder Mask Clearance Constraint: (Collision < 10mil) Between Pad C147-1(72.835mil,442.913mil) on Bottom Layer And Text "Q2" (131.778mil,447.542mil) on Bottom Overlay [Bottom Overlay] to [Bottom Solder] clearance [0mil]
Silk To Solder Mask Clearance Constraint: (8.211mil < 10mil) Between Pad C147-2(139.755mil,442.913mil) on Bottom Layer And Text "L1" (218.542mil,447.541mil) on Bottom Overlay [Bottom Overlay] to [Bottom Solder] clearance [8.211mil]
Silk To Solder Mask Clearance Constraint: (Collision < 10mil) Between Pad C147-2(139.755mil,442.913mil) on Bottom Layer And Text "Q2" (131.778mil,447.542mil) on Bottom Overlay [Bottom Overlay] to [Bottom Solder] clearance [0mil]
Silk To Solder Mask Clearance Constraint: (Collision < 10mil) Between Pad C148-1(202.744mil,442.913mil) on Bottom Layer And Text "L1" (218.542mil,447.541mil) on Bottom Overlay [Bottom Overlay] to [Bottom Solder] clearance [0mil]
Silk To Solder Mask Clearance Constraint: (Collision < 10mil) Between Pad C149-1(332.658mil,442.913mil) on Bottom Layer And Text "L2" (379.463mil,447.541mil) on Bottom Overlay [Bottom Overlay] to [Bottom Solder] clearance [0mil]
Silk To Solder Mask Clearance Constraint: (Collision < 10mil) Between Pad C149-2(399.577mil,442.913mil) on Bottom Layer And Text "L2" (379.463mil,447.541mil) on Bottom Overlay [Bottom Overlay] to [Bottom Solder] clearance [0mil]
Silk To Solder Mask Clearance Constraint: (2.221mil < 10mil) Between Pad C150-1(198.811mil,503.937mil) on Bottom Layer And Text "L1" (218.542mil,447.541mil) on Bottom Overlay [Bottom Overlay] to [Bottom Solder] clearance [2.221mil]
Silk To Solder Mask Clearance Constraint: (2.221mil < 10mil) Between Pad C151-1(320.85mil,503.937mil) on Bottom Layer And Text "L2" (379.463mil,447.541mil) on Bottom Overlay [Bottom Overlay] to [Bottom Solder] clearance [2.221mil]
Silk To Solder Mask Clearance Constraint: (2.221mil < 10mil) Between Pad C151-2(387.77mil,503.937mil) on Bottom Layer And Text "L2" (379.463mil,447.541mil) on Bottom Overlay [Bottom Overlay] to [Bottom Solder] clearance [2.221mil]
Silk To Solder Mask Clearance Constraint: (Collision < 10mil) Between Pad C78-1(462.567mil,442.913mil) on Bottom Layer And Text "L3" (525.136mil,447.541mil) on Bottom Overlay [Bottom Overlay] to [Bottom Solder] clearance [0mil]
Silk To Solder Mask Clearance Constraint: (Collision < 10mil) Between Pad C78-2(529.487mil,442.913mil) on Bottom Layer And Text "L3" (525.136mil,447.541mil) on Bottom Overlay [Bottom Overlay] to [Bottom Solder] clearance [0mil]
Silk To Solder Mask Clearance Constraint: (2.222mil < 10mil) Between Pad C80-1(72.835mil,513.784mil) on Bottom Layer And Text "Q2" (131.778mil,447.542mil) on Bottom Overlay [Bottom Overlay] to [Bottom Solder] clearance [2.222mil]
Silk To Solder Mask Clearance Constraint: (2.222mil < 10mil) Between Pad C80-2(139.755mil,513.784mil) on Bottom Layer And Text "Q2" (131.778mil,447.542mil) on Bottom Overlay [Bottom Overlay] to [Bottom Solder] clearance [2.222mil]
Silk To Solder Mask Clearance Constraint: (2.221mil < 10mil) Between Pad C82-2(509.814mil,503.937mil) on Bottom Layer And Text "L3" (525.136mil,447.541mil) on Bottom Overlay [Bottom Overlay] to [Bottom Solder] clearance [2.221mil]
Silk To Solder Mask Clearance Constraint: (Collision < 10mil) Between Pad JP3-2(2531.496mil,853.543mil) on Multi-Layer And Text "J1" (2539.667mil,848.745mil) on Top Overlay [Top Overlay] to [Top Solder] clearance [0mil]
Silk To Solder Mask Clearance Constraint: (Collision < 10mil) Between Pad L1-1(170.276mil,356.295mil) on Bottom Layer And Text "U6" (231.941mil,365.591mil) on Bottom Overlay [Bottom Overlay] to [Bottom Solder] clearance [0mil]
Silk To Solder Mask Clearance Constraint: (7.184mil < 10mil) Between Pad L1-2(262.796mil,356.295mil) on Bottom Layer And Text "U6" (231.941mil,365.591mil) on Bottom Overlay [Bottom Overlay] to [Bottom Solder] clearance [7.184mil]
Silk To Solder Mask Clearance Constraint: (3.225mil < 10mil) Between Pad L1-2(262.796mil,356.295mil) on Bottom Layer And Text "U7" (342.173mil,365.591mil) on Bottom Overlay [Bottom Overlay] to [Bottom Solder] clearance [3.225mil]
Silk To Solder Mask Clearance Constraint: (Collision < 10mil) Between Pad L2-1(315.945mil,356.295mil) on Bottom Layer And Text "U7" (342.173mil,365.591mil) on Bottom Overlay [Bottom Overlay] to [Bottom Solder] clearance [0mil]
Silk To Solder Mask Clearance Constraint: (Collision < 10mil) Between Pad L2-2(408.465mil,356.295mil) on Bottom Layer And Text "U8" (442.812mil,337.657mil) on Bottom Overlay [Bottom Overlay] to [Bottom Solder] clearance [0mil]
Silk To Solder Mask Clearance Constraint: (Collision < 10mil) Between Pad L3-1(461.618mil,356.295mil) on Bottom Layer And Text "U8" (442.812mil,337.657mil) on Bottom Overlay [Bottom Overlay] to [Bottom Solder] clearance [0mil]
Silk To Solder Mask Clearance Constraint: (Collision < 10mil) Between Pad LD1-K(1000.004mil,495.472mil) on Top Layer And Text "LD0" (969.492mil,511.788mil) on Top Overlay [Top Overlay] to [Top Solder] clearance [0mil]
Silk To Solder Mask Clearance Constraint: (Collision < 10mil) Between Pad LD2-K(1000.004mil,542.716mil) on Top Layer And Text "LD0" (969.492mil,511.788mil) on Top Overlay [Top Overlay] to [Top Solder] clearance [0mil]
Silk To Solder Mask Clearance Constraint: (Collision < 10mil) Between Pad Q1-3(1659.45mil,734.252mil) on Top Layer And Text "U1" (1637.1mil,731.415mil) on Top Overlay [Top Overlay] to [Top Solder] clearance [0mil]
Silk To Solder Mask Clearance Constraint: (3.235mil < 10mil) Between Pad Q2-G(55.12mil,383.856mil) on Bottom Layer And Text "U5" (121.713mil,365.591mil) on Bottom Overlay [Bottom Overlay] to [Bottom Solder] clearance [3.235mil]
Silk To Solder Mask Clearance Constraint: (Collision < 10mil) Between Pad Q2-S(129.92mil,383.856mil) on Bottom Layer And Text "U5" (121.713mil,365.591mil) on Bottom Overlay [Bottom Overlay] to [Bottom Solder] clearance [0mil]
Silk To Solder Mask Clearance Constraint: (4.276mil < 10mil) Between Pad R97-1(690.945mil,761.811mil) on Bottom Layer And Text "U3" (756.609mil,760.163mil) on Bottom Overlay [Bottom Overlay] to [Bottom Solder] clearance [4.276mil]
Silk To Solder Mask Clearance Constraint: (Collision < 10mil) Between Pad R97-2(714.565mil,761.811mil) on Bottom Layer And Text "U3" (756.609mil,760.163mil) on Bottom Overlay [Bottom Overlay] to [Bottom Solder] clearance [0mil]
Silk To Solder Mask Clearance Constraint: (Collision < 10mil) Between Pad R98-1(738.185mil,761.811mil) on Bottom Layer And Text "U3" (756.609mil,760.163mil) on Bottom Overlay [Bottom Overlay] to [Bottom Solder] clearance [0mil]
Silk To Solder Mask Clearance Constraint: (Collision < 10mil) Between Pad R98-2(761.805mil,761.811mil) on Bottom Layer And Text "U3" (756.609mil,760.163mil) on Bottom Overlay [Bottom Overlay] to [Bottom Solder] clearance [0mil]
Silk To Solder Mask Clearance Constraint: (Collision < 10mil) Between Pad U2-10(1072.835mil,505.905mil) on Top Layer And Text "LD0" (969.492mil,511.788mil) on Top Overlay [Top Overlay] to [Top Solder] clearance [0mil]
Silk To Solder Mask Clearance Constraint: (9.087mil < 10mil) Between Pad U2-17(1149.605mil,311.025mil) on Top Layer And Text "X4" (1141.833mil,353.408mil) on Top Overlay [Top Overlay] to [Top Solder] clearance [9.087mil]
Silk To Solder Mask Clearance Constraint: (8.912mil < 10mil) Between Pad U2-18(1169.295mil,311.025mil) on Top Layer And Text "X4" (1141.833mil,353.408mil) on Top Overlay [Top Overlay] to [Top Solder] clearance [8.912mil]
Silk To Solder Mask Clearance Constraint: (8.873mil < 10mil) Between Pad U2-19(1188.975mil,311.025mil) on Top Layer And Text "X4" (1141.833mil,353.408mil) on Top Overlay [Top Overlay] to [Top Solder] clearance [8.873mil]
Silk To Solder Mask Clearance Constraint: (Collision < 10mil) Between Pad U2-8(1072.835mil,545.275mil) on Top Layer And Text "LD0" (969.492mil,511.788mil) on Top Overlay [Top Overlay] to [Top Solder] clearance [0mil]
Silk To Solder Mask Clearance Constraint: (Collision < 10mil) Between Pad U2-9(1072.835mil,525.595mil) on Top Layer And Text "LD0" (969.492mil,511.788mil) on Top Overlay [Top Overlay] to [Top Solder] clearance [0mil]
Silk To Solder Mask Clearance Constraint: (Collision < 10mil) Between Pad X2-1(2350mil,950mil) on Multi-Layer And Text "R4" (2314.889mil,888.414mil) on Top Overlay [Top Overlay] to [Top Solder] clearance [0mil]
Silk To Solder Mask Clearance Constraint: (Collision < 10mil) Between Pad X2-11(950mil,950mil) on Multi-Layer And Text "U10" (958.663mil,959.269mil) on Bottom Overlay [Bottom Overlay] to [Bottom Solder] clearance [0mil]
Silk To Solder Mask Clearance Constraint: (0.272mil < 10mil) Between Pad X2-12(850mil,950mil) on Multi-Layer And Text "U10" (958.663mil,959.269mil) on Bottom Overlay [Bottom Overlay] to [Bottom Solder] clearance [0.272mil]
Silk To Solder Mask Clearance Constraint: (Collision < 10mil) Between Pad X2-7(1750mil,950mil) on Multi-Layer And Text "U4" (1728.33mil,916.025mil) on Top Overlay [Top Overlay] to [Top Solder] clearance [0mil]
Silk To Solder Mask Clearance Constraint: (Collision < 10mil) Between Pad X2-8(1650mil,950mil) on Multi-Layer And Text "Q1" (1590.014mil,900.608mil) on Top Overlay [Top Overlay] to [Top Solder] clearance [0mil]

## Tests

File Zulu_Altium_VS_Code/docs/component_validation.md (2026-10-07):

# Zulu A7 component and BOM validation

Generated by tools/bom_audit.py on 2026-09-07 from the Altium sheets, the Protel netlist, the EAGLE packages in zulu_a7.sch, AMD's CPG236 pinout file and the datasheets in Datasheet/. Distributor data is a Digi-Key snapshot from the evening of 2026-09-06.

## 1. Bill of materials

169 fitted components, 65 distinct parts, plus 2 DNS positions (do not stuff). Frames and the licence logos are excluded.

| Part | Manufacturer | Footprint | Value | Qty | Designators |
|---|---|---|---|---:|---|
| PTS810SJM250SMTR LFS | Littelfuse (C&K) | PTS810 | PTS810 | 1 | BTN |
| GRM155R71C104KA88D | Murata | C0402 | 0.1uF | 9 | C3, C4, C5, C6, C7, C8, C9, C11, C12 |
| GRM188R60J106ME47D | Murata | C0603 | 10uF | 1 | C13 |
| GRM155R71H102KA01D | Murata | C0402 | 1nF | 2 | C36, C37 |
| GRM033R71E103KE14D | Murata | C0201 | 0.01uF | 1 | C38 |
| GRM033R61A104KE15D | Murata | C0201 | 100nF | 2 | C40, C41 |
| CL21A106KPFNNNG | Samsung | C0805 | 10uF 10V | 1 | C78 |
| GRM21BR61A226ME44L | Murata | C0805 | 22uF | 13 | C80, C85, C86, C93, C97, C98, C140, C141, C142, C143, C144, C145, C146 |
| CL10A226MP8NUNE | Samsung | C0603 | 22uF | 2 | C82, C84 |
| GRM188R61C475KE11D | Murata | C0603 | 4.7uF | 13 | C87, C88, C94, C99, C100, C101, C102, C103, C104, C105, C106, C150, C151 |
| GRM033R60J474KE90D | Murata | C0201 | 0.47uF | 22 | C89, C90, C91, C92, C95, C96, C107, C108, C109, C110, C111, C112, C113, C114, C115, C116, C117, C118, C119, C120, C121, C122 |
| GRM155R71C104KA88D | Murata | C0402 | 100nF | 1 | C123 |
| CL05A474KO5NNNC | Samsung | C0402 | 470nF | 1 | C124 |
| GRM033R61A104KE15D | Murata | C0201 | 0.1uF | 9 | C133, C134, C135, C136, C137, C138, C152, C153, C154 |
| MSASJ105BB5475MFNA01 | Taiyo Yuden | C0402 | 4.7uF | 1 | C139 |
| CL21A106KPFNNNG | Samsung | C0805 | 10uF | 3 | C147, C148, C149 |
| PPTC062LFBN-RC | Sullins | 2X06 | Pmod 2x6 | 1 | J1 |
| DNS: JTAG TCK/TMS/GND |  | 1X03-NOSILK | JTAG TCK/TMS/GND | 1 | JP3 |
| DNS: JTAG TDI/TDO/3V3 |  | 1X03-NOSILK | JTAG TDI/TDO/3V3 | 1 | JP4 |
| DFE252010P-1R5M=P2 | Murata | IND2520 | 1.5uH | 3 | L1, L2, L3 |
| BLM18KG601SN1D | Murata | IND0603 | FB 600R | 4 | L4, L5, L6, L7 |
| EAST1616RGBA8 | Everlight | EVERLIGHT-19-337 | EAST1616RGBA8 | 1 | LD0 |
| LTST-C191KRKT | Lite-On | LED0603 | red | 3 | LD1, LD2, LD4 |
| LTST-C191KGKT | Lite-On | LED0603 | green | 2 | LD3, LD5 |
| ECS-3225SMV-120-FP-TR | ECS | 32X25 | 12MHz 10ppm (FPGA + FT2232HL) | 1 | Q1 |
| 2N7002LT1G | onsemi | SOT23-3 | 2N7002 | 1 | Q2 |
| 742C043472JP | CTS | 742C043 | 4.7K | 1 | R1 |
| RC0201FR-074K7L | Yageo | R0201 | 4.7K | 3 | R2, R6, R7 |
| 742C163101JP | CTS | 742C163 | 100 | 1 | R4 |
| RC0201FR-075K1L | Yageo | R0201 | 5.1K | 1 | R5 |
| RC0201FR-072K32L | Yageo | R0201 | 2.32K | 2 | R10, R14 |
| RC0201FR-071KL | Yageo | R0201 | 1K | 5 | R11, R15, R20, R22, R23 |
| RC0201FR-07140RL | Yageo | R0201 | 140 | 2 | R12, R16 |
| RC0201FR-07845RL | Yageo | R0201 | 845 | 2 | R13, R17 |
| RC0402FR-0712KL | Yageo | R0402 | 12K 1% | 1 | R18 |
| RC0201FR-0710KL | Yageo | R0201 | 10K | 6 | R19, R90, R91, R92, R93, R94 |
| RC0402FR-071KL | Yageo | R0402 | 1K | 1 | R21 |
| RC0201FR-0733RL | Yageo | R0201 | 33 | 2 | R24, R25 |
| RC0201FR-07200RL | Yageo | R0201 | 200 | 8 | R26, R27, R28, R29, R30, R31, R32, R33 |
| 742C083472JP | CTS | 742C083 | 4.7K | 1 | R34 |
| RC0402FR-074K7L | Yageo | R0402 | 4.7K | 1 | R35 |
| RC0402FR-07100KL | Yageo | R0402 | 100K | 1 | R77 |
| RC0402FR-07680RL | Yageo | R0402 | 680 | 1 | R78 |
| RC0402FR-0733RL | Yageo | R0402 | 33 | 2 | R80, R82 |
| RC0402FR-07330RL | Yageo | R0402 | 330 | 3 | R81, R83, R84 |
| RC0402FR-0710KL | Yageo | R0402 | 10K | 3 | R85, R86, R106 |
| RC0201FR-0710KL | Yageo | R0201 | 10k | 3 | R96, R97, R98 |
| RC0201FR-074K7L | Yageo | R0201 | 4.7k | 1 | R99 |
| RC0201FR-072K21L | Yageo | R0201 | 2.21k | 1 | R101 |
| RC0402FR-073K57L | Yageo | R0402 | 3.57K | 1 | R102 |
| RC0402FR-073K09L | Yageo | R0402 | 3.09K | 1 | R103 |
| RC0402FR-0756K2L | Yageo | R0402 | 56.2K | 1 | R104 |
| RC0402FR-074K32L | Yageo | R0402 | 4.32K | 1 | R105 |
| RC0402FR-071K5L | Yageo | R0402 | 1.5K | 2 | R107, R108 |
| XC7A35T-1CPG236C | AMD/Xilinx | XC7A35T-CPG236 | XC7A35T-1CPG236C | 1 | U1 |
| FT2232HL-REEL | FTDI | FT2232HL-LQFP64 | FT2232HL USB-UART/JTAG Bridge | 1 | U2 |
| AS4C32M16SB-7TCN | Alliance Memory | TSOPII-54 | AS4C32M16SB-7TCN | 1 | U3 |
| W25Q128JVSIQ | Winbond | SOIC-8_208MIL | W25Q128JVSIQ | 1 | U4 |
| SC189ZSKTRT | Semtech | SOT23-5 | SC189ZSKTRT | 1 | U5 |
| SC189LSKTRT | Semtech | SOT23-5 | SC189LSKTRT | 1 | U6 |
| SC189ASKTRT | Semtech | SOT23-5 | SC189ASKTRT | 1 | U7 |
| BQ24232RGTR | Texas Instruments | VQFN16-3X3-RGT | BQ24232 LiPo charger + power path | 1 | U8 |
| 93LC46BT-I/SN | Microchip | SPI-8_SOIC_150 | 93LC46BT-I/SN | 1 | U10 |
| 105017-0001 | Molex | MOLEX-105017-0001 | Molex 105017-0001 Micro-USB-B | 1 | X1 |
| 2x PRPC009SAAN-RC + 2x PRPC011SAAN-RC | Sullins | ZULU-DIP37 | ZULU-CONN | 1 | X2 |
| DM3D-SF | Hirose | DM3D-SF | DM3D-SF | 1 | X3 |
| B2B-PH-SM4-TB(LF)(SN) | JST | JST-B2B-PH-SM4-TB | JST PH 2-pin, 1S LiPo | 1 | X4 |

## 2. Footprint and pin verification

### 2.1 U1 XC7A35T-1CPG236C against the AMD pinout file

- Symbol pins: 238; AMD balls: 238; missing from the symbol: none; not in the package: none.
- Power, ground and dedicated balls and the nets they sit on:

| Ball function | Net(s) | Balls |
|---|---|---:|
| CCLK | FPGA-CCLK (1) | 1 |
| CFGBVS | VCC3V3 (1) | 1 |
| DONE | FPGA-DONE (1) | 1 |
| DXN | GND (1) | 1 |
| DXP | GND (1) | 1 |
| GND | GND (52) | 52 |
| GNDADC | GNDADC (1) | 1 |
| INIT_B | FPGA-INIT# (1) | 1 |
| M0 | CFG-M0 (1) | 1 |
| M1 | CFG-M1 (1) | 1 |
| M2 | CFG-M2 (1) | 1 |
| MGTAVCC | GND (5) | 5 |
| MGTAVTT | GND (4) | 4 |
| MGTPRXN0 | GND (1) | 1 |
| MGTPRXN1 | GND (1) | 1 |
| MGTPRXP0 | GND (1) | 1 |
| MGTPRXP1 | GND (1) | 1 |
| MGTPTXN0 | <open> (1) | 1 |
| MGTPTXN1 | <open> (1) | 1 |
| MGTPTXP0 | <open> (1) | 1 |
| MGTPTXP1 | <open> (1) | 1 |
| MGTREFCLK0N | <open> (1) | 1 |
| MGTREFCLK0P | <open> (1) | 1 |
| MGTREFCLK1N | <open> (1) | 1 |
| MGTREFCLK1P | <open> (1) | 1 |
| MGTRREF | GND (1) | 1 |
| PROGRAM_B | RST# (1) | 1 |
| TCK | FPGA-TCK (1) | 1 |
| TDI | FPGA-TDI (1) | 1 |
| TDO | FPGA-TDO (1) | 1 |
| TMS | FPGA-TMS (1) | 1 |
| VCCADC | VCCADC (1) | 1 |
| VCCAUX | VCC1V8 (2) | 2 |
| VCCBATT | VCC1V8 (1) | 1 |
| VCCBRAM | VCC1V0 (2) | 2 |
| VCCINT | VCC1V0 (6) | 6 |
| VCCO | VCC3V3 (27) | 27 |
| VN | GNDADC (1) | 1 |
| VP | GNDADC (1) | 1 |
| VREFN | GNDADC (1) | 1 |
| VREFP | GNDADC (1) | 1 |
| IO bank 14 | 50 signal nets | 50 |
| IO bank 16 | 12 signal nets | 12 |
| IO bank 34 | 24 signal nets | 24 |
| IO bank 35 | 20 signal nets | 20 |

VCCINT and VCCBRAM on VCC1V0, VCCAUX and VCCBATT on VCC1V8, every VCCO on VCC3V3, the unused GTP supplies and receivers on GND with the transmitters and reference clocks open (UG482 allows both), VP/VN/VREFP/VREFN on GNDADC (internal reference), CFGBVS high for a 3.3 V bank 0. Dedicated config pins (CCLK, DONE, INIT_B, PROGRAM_B, M0-M2, TCK/TMS/TDI/TDO) and the SPI flash D00-D03/FCS_B all sit on their AMD balls; CLK12M is on an MRCC pin and CHAN-CLK on an SRCC pin.

### 2.2 Other parts against their datasheet pin tables

| Part | Check | Result |
|---|---|---|
| U2 FT2232HL | 64 pins, symbol names vs DS_FT2232H tables 3.1-3.4 (the LQFP and QFN share the numbering; no EP on the LQFP) | all match |
| U3 AS4C32M16SB | 54 pads: net on each pad vs the JEDEC x16 pin assignment | all 54 match (pin 40 NC open) |
| U4 W25Q128JVSIQ | 8 pads vs W25Q128JV SOIC-8 pin configuration (1 CS#, 2 DO/IO1, 3 WP#/IO2, 4 GND, 5 DI/IO0, 6 CLK, 7 HOLD#/IO3, 8 VCC) | all match |
| U10 93LC46BT-I/SN | pins vs DS20001749 pin table, FTDI EEPROM wiring (DO via 2.2 k to EEDATA) | all match |
| Q1 ASEM1 | 1 ST/OE, 2 GND, 3 OUT, 4 VDD | all match |
| X1 Molex 105017-0001 | 1 VBUS, 2 D-, 3 D+, 4 ID open, 5 + shell GND | all match |
| LD0 EAST1616RGBA8 | cathodes 2 B, 4 R, 6 G to the FPGA; anodes 1/3/5 through R80/R81/R82 to 3.3 V (19-337 sheet p8 polarity) | all match |
| R34 742C083 | isolated 4-array, 1-8 2-7 3-6 4-5, the microSD DAT0..3 pull-ups | all match |
| R4 742C163 | isolated 8-array: six 100R series resistors, A PROG#, B DONE, C TDI, D TDO, E TMS, F TCK, bridge side on pads 1-6 and FPGA side on pads 16 down to 11; then G and H in series from VCC3V3 as the 200R DONE pull-up (2026-09-10), their common node named DONE-PU so it is not an auto-name | all match |
| R1 742C043 | isolated 2-array, A the INIT_B pull-up and B the PROGRAM_B pull-up, both commons on pads 4 and 3 | all match |
| Q2 2N7002LT1G | G on PGOOD, S on GND, D on the LED; SOT-23 1 G 2 S 3 D | matches (standard 2N7002 pinout, onsemi sheet not fetchable) |
| X2 pin field | 40 pins numbered 1-40 (2026-09-09); mirrored rows, 1-9 + USB landing + 10-20 above, 21-29 + LiPo landing + 30-40 below. Top row 1 GND, 2 CHAN-CLK, 3-9 CHAN0-6, 10-16 CHAN7-13, 17 GND, 18 +3.3V, 19 +1.8V, 20 +1.0V (power pins re-ordered 2026-10-07); bottom row 21 GND, 22 VU, 23 RST#, 24-29 CHAN14-19, 30-38 CHAN20-28, 39-40 ANALOG-IO0/1 | all match |
| U8 bq24232 | 17 pin names vs SLUS821J Pin Functions; IN on USB5V0, OUT on VU, BAT on VBATT with X4-1, CE/EN1 low, EN2 high | all match |
| BTN PTS810SJM250SMTR LFS | pins 1,2 = 3.3 V, pins 3,4 = BTN net | PTS810 sheet schematic joins 1-2 and 3-4: matches |

### 2.3 EAGLE package geometry against the datasheet land patterns

| Package | Datasheet | Library package | Verdict |
|---|---|---|---|
| XC7A35T-CPG236 | UG475 v1.20 Table A-1: 0.5 mm pitch, land 0.275 mm NSMD, mask 0.375 | pitch 0.5 OK; lands HELD at 0.225 mm (0.82:1), verified 238 at 0.225 mm by tools/verify_pcblib.py. UG475 gives 0.275 mm as the MAXIMUM land and recommends 1:1 with the package SMD opening for board-level reliability, but at 0.275 the inter-pad gap is 0.225 mm and a 3 mil trace at 3.5 mil clearance needs 0.2562 mm, so the escape is then geometrically impossible on any through-via stack. At 0.225 the gap is 0.275 mm and the margin is +0.0188 mm. PCBWay build BGA lands to 0.2032 mm at 0.4 mm pitch, so 0.225 is inside process | **ok** |
| FT2232HL-LQFP64 | DS_FT2232H Figure 8.2: LQFP-64, 10 x 10 mm body, 12 x 12 mm over leads, 0.5 mm pitch, JEDEC MS-026 BCD, no exposed pad | drawn 2026-09-10 into Imported zulu_a7.PrjPcb/zulu_a7.PcbLib (tools/make_fp_source.py + fp_emit.py, land patterns in docs/footprint_lands.md). FTDI publish NO land pattern -- section 8 is package outlines only -- so this one is DERIVED: IPC-7351B density level B, QFP50P1200X1200X160-64N, pads 0.28 x 1.55 on a 5.70 mm row centre, width rounded up from the strict 0.245 to the industry 0.28 for fillet inspection | **derived** |
| TSOPII-54 | AS4C32M16SB TSOP II 400 mil, 0.8 mm pitch, lead span 11.76 max | pitch 0.8, rows 11.36 apart, 1.2 mm pads OK | **ok** |
| SOIC-8_208MIL | W25Q128JVSIQ SOIC-8 208 mil, lead span 7.9-8.1 | rows 7.3 apart, 1.51 mm pads OK | **ok** |
| SPI-8_SOIC_150 | 93LC46BT-I/SN: SN = 3.90 mm narrow body, E = 6.00 BSC, foot 0.40-1.27 | U10 moved here from the 300-mil SOIC8 on 2026-09-10 (tools/u10_narrow_soic.py). Rows 4.93 apart, 2.07 x 0.51 pads on the 1.27 pitch: lands run 1.43 to 3.50 mm either side of the centreline, so they start inside the 1.95 mm body edge for a heel fillet and reach 0.50 mm past the 3.00 mm lead tip for a toe. The old SOIC8 pattern is still in the PcbLib but nothing references it | **ok** |
| SOT23-3 | 2N7002LT1G SOT-23: 1 G, 2 S, 3 D (standard 2N7002 pinout, datasheet not on disk) | pads G(-0.95,-0.7) S(0.95,-0.7) D(0,0.7), 0.95 pitch OK | **ok** |
| SOT23-5 | SC189xSKTRT SOT23-5, datasheet p23 land: 0.95 pitch, pads 0.60 x 1.10, inner gap 1.40, outer span 3.60 | drawn 2026-09-10 into Imported zulu_a7.PrjPcb/zulu_a7.PcbLib (tools/make_fp_source.py + fp_emit.py, land patterns in docs/footprint_lands.md). Semtech land p23: C (2.50) row centreline, G 1.40, P 0.95, X 0.60, Y 1.10, Z 3.60, all mutually consistent. NOTE pin 4 is DIRECTLY opposite pin 3, not diagonally -- 1/2/3 along one side, 5 opposite 1 and 4 opposite 3 | **ok** |
| DM3D-SF | DM3 catalog p9: 8 x 0.55 pads on 1.1 pitch, 4 cover pads, 2 switch pads, 2 keep-outs | drawn 2026-09-10 into Imported zulu_a7.PrjPcb/zulu_a7.PcbLib (tools/make_fp_source.py + fp_emit.py, land patterns in docs/footprint_lands.md). Taken from the DM3D-SF recommended pattern on catalog p9, not the DM3AT page: eight 0.70 x 1.75 contacts on 1.1 mm pitch, switch A and B, four shell pads G1-G4. The pad-width hint of 0.55 on file was the contact, not the land | **ok** |
| ZULU-DIP37 | Sullins PRPC drawing: 0.64 mm square pins on 2.54 mm, recommended hole 1.02 mm | redrawn 2026-09-10: 44 pads -> 40, the four bottom-row pads at x 36.83/34.29/31.75/29.21 deleted to open the LiPo landing and 34-44 renumbered 30-40, so both rows now read 9 + landing + 11. Verified in the PcbLib: 40 pads named 1-40, two rows of 20, every pad on the intended 2.54 grid, 1.524 mm pads on the Sullins 1.016 mm drill | **ok** |
| VQFN16-3X3-RGT | bq24232 SLUS821J RGT package: 16-pin VQFN 3.0 x 3.0 mm, 0.5 mm pitch, 1.68 mm thermal pad | drawn 2026-09-10 into Imported zulu_a7.PrjPcb/zulu_a7.PcbLib (tools/make_fp_source.py + fp_emit.py, land patterns in docs/footprint_lands.md). TI land pattern p44 (RGT0016C): 16 lands 0.6 x 0.24 on 0.5 mm pitch at a 1.40 mm row centre, 1.68 mm thermal land as pad 17. Two Altium-side settings still to make: pad 17 paste shrunk to 1.55 (TI ask ~85 % coverage) and 0.07 mm mask expansion on 1-16 so the 0.24 mm lands are not mask-defined | **ok** |
| JST-B2B-PH-SM4-TB | JST PH SM4 top-entry SMT: two contact pads on 2.0 mm pitch plus two 1.6 x 3.0 mm fixing pads (catalog page 1) | drawn 2026-09-10 into Imported zulu_a7.PrjPcb/zulu_a7.PcbLib (tools/make_fp_source.py + fp_emit.py, land patterns in docs/footprint_lands.md). JST SM4 top-entry land, p1: contacts 1.0 x 5.5 on the 2.0 mm pitch, fixing pads MP1/MP2 1.6 x 3.0 at +-3.4. The lands run 2.5 mm past the body on the lead side -- keep that strip clear | **ok** |
| 742C163 | CTS 742C163 (DOC 008-0335-0 Rev T): 8 x 0603 concave-termination array, body 6.4 x 1.6, 0.8 mm pitch, 16 pads; CTS publishes one land for the whole 742 family, the 0.45 x 0.9 pads at +-0.85 already checked for 742C083 | drawn 2026-09-10 into Imported zulu_a7.PrjPcb/zulu_a7.PcbLib (tools/make_fp_source.py + fp_emit.py, land patterns in docs/footprint_lands.md). Sixteen 0.45 x 0.9 lands on the 0.8 mm pitch at +-0.85, numbering counter-clockwise so each element spans one column (1-16, 2-15 ... 8-9), which is exactly the pairing the schematic wires. All eight elements used, G and H in series as the DONE pull-up | **ok** |
| 742C043 | CTS 742C043 (DOC 008-0335-0 Rev T): 2 x 0603 concave-termination array, body 1.6 x 1.6, 0.8 mm pitch, 4 pads; same family land as 742C083 | drawn 2026-09-10 into Imported zulu_a7.PrjPcb/zulu_a7.PcbLib (tools/make_fp_source.py + fp_emit.py, land patterns in docs/footprint_lands.md). Four 0.45 x 0.9 lands on the 0.8 mm pitch at +-0.85, elements 1-4 and 2-3. CTS publish no pin-1 marking for this package and the datasheet is not on disk, so the numbering rests on the family land plus the schematic pairing, not on a printed pin-1 callout | **ok** |
| MOLEX-105017-0001 | Molex 105017 drawing: 5 x 0.4 mm pads on 0.65 pitch, 4 shell pads, 2 pegs | 0.65 pitch, 0.4x1.35 pads, shell pads OK | **ok** |
| 32X25 | ASEM1 3.2x2.5 mm, 4 pads | pads 1.2x1.4 at 1.7 x 2.2 OK | **ok** |
| EVERLIGHT-19-337 | Everlight 19-337 p8 recommended pads: 0.55x0.4 outer at +-0.725, 0.7x0.5 middle, 1.9/2.2 spans (the VS NRD8 p2 drawing line for line) | identical to the VS-NRD8 pattern in the library; renumber the pads 1/2/3 -> 2/4/6, 4/5/6 -> 1/3/5 when the footprint is drawn | **ok** |
| PTS810 | C&K PTS810 sheet p1: four pads 1.05 x 0.65 mm centred at +-2.075 x +-1.075 mm (5.2 x 2.8 mm envelope), body 4.2 x 3.2 mm | drawn 2026-09-10 into Imported zulu_a7.PrjPcb/zulu_a7.PcbLib (tools/make_fp_source.py + fp_emit.py, land patterns in docs/footprint_lands.md). C&K land p1: four 1.05 x 0.65 pads at +-2.075, +-1.075. Pairing is ROW-WISE -- pads 1+2 are one terminal and 3+4 the other, not the diagonal many tact switches use -- which is how BTN is wired | **ok** |
| 742C083 | CTS 742C083: 4 x 0603 concave-termination array (3.2 x 1.6), 0.8 mm pitch; CTS land 0.45 x 0.9 pads at +-0.85 | pitch 0.8, 0.5 x 0.9 pads at +-0.9, 0.05 mm per side wider than CTS: OK; 742C083472JP shares the package code, the Bourns CAT16 and Panasonic EXB-V8V substitutes are convex parts on the same land | **ok** |
| IND2520 | Murata DFE252010P: 2.5 x 2.0 mm, two pads | pads 1.05x2.3 at 2.35 OK | **ok** |
| C0402 / R0402 | Murata GRM15 land 0.5 wide, gap 0.4, span 1.5; Samsung 1005 land 0.51-0.59 wide, gap 0.36-0.44, span 1.34-1.58 | pads 0.7 x 0.9 at +-0.65 (gap 0.6, span 2.0): larger in every dimension than either vendor asks; solders, but the extra solder volume raises tombstoning exposure on every 0402 position | **note** |
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

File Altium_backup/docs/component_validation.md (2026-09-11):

# Zulu A7 component and BOM validation

Generated by tools/bom_audit.py on 2026-09-07 from the Altium sheets, the Protel netlist, the EAGLE packages in zulu_a7.sch, AMD's CPG236 pinout file and the datasheets in Datasheet/. Distributor data is a Digi-Key snapshot from the evening of 2026-09-06.

## 1. Bill of materials

169 fitted components, 65 distinct parts, plus 2 DNS positions (do not stuff). Frames and the licence logos are excluded.

| Part | Manufacturer | Footprint | Value | Qty | Designators |
|---|---|---|---|---:|---|
| PTS810SJM250SMTR LFS | Littelfuse (C&K) | PTS810 | PTS810 | 1 | BTN |
| GRM155R71C104KA88D | Murata | C0402 | 0.1uF | 9 | C3, C4, C5, C6, C7, C8, C9, C11, C12 |
| GRM188R60J106ME47D | Murata | C0603 | 10uF | 1 | C13 |
| GRM155R71H102KA01D | Murata | C0402 | 1nF | 2 | C36, C37 |
| GRM033R71E103KE14D | Murata | C0201 | 0.01uF | 1 | C38 |
| GRM033R61A104KE15D | Murata | C0201 | 100nF | 2 | C40, C41 |
| CL21A106KPFNNNG | Samsung | C0805 | 10uF 10V | 1 | C78 |
| GRM21BR61A226ME44L | Murata | C0805 | 22uF | 13 | C80, C85, C86, C93, C97, C98, C140, C141, C142, C143, C144, C145, C146 |
| CL10A226MP8NUNE | Samsung | C0603 | 22uF | 2 | C82, C84 |
| GRM188R61C475KE11D | Murata | C0603 | 4.7uF | 13 | C87, C88, C94, C99, C100, C101, C102, C103, C104, C105, C106, C150, C151 |
| GRM033R60J474KE90D | Murata | C0201 | 0.47uF | 22 | C89, C90, C91, C92, C95, C96, C107, C108, C109, C110, C111, C112, C113, C114, C115, C116, C117, C118, C119, C120, C121, C122 |
| GRM155R71C104KA88D | Murata | C0402 | 100nF | 1 | C123 |
| CL05A474KO5NNNC | Samsung | C0402 | 470nF | 1 | C124 |
| GRM033R61A104KE15D | Murata | C0201 | 0.1uF | 9 | C133, C134, C135, C136, C137, C138, C152, C153, C154 |
| MSASJ105BB5475MFNA01 | Taiyo Yuden | C0402 | 4.7uF | 1 | C139 |
| CL21A106KPFNNNG | Samsung | C0805 | 10uF | 3 | C147, C148, C149 |
| PPTC062LFBN-RC | Sullins | 2X06 | Pmod 2x6 | 1 | J1 |
| DNS: JTAG TCK/TMS/GND |  | 1X03-NOSILK | JTAG TCK/TMS/GND | 1 | JP3 |
| DNS: JTAG TDI/TDO/3V3 |  | 1X03-NOSILK | JTAG TDI/TDO/3V3 | 1 | JP4 |
| DFE252010P-1R5M=P2 | Murata | IND2520 | 1.5uH | 3 | L1, L2, L3 |
| BLM18KG601SN1D | Murata | IND0603 | FB 600R | 4 | L4, L5, L6, L7 |
| EAST1616RGBA8 | Everlight | EVERLIGHT-19-337 | EAST1616RGBA8 | 1 | LD0 |
| LTST-C191KRKT | Lite-On | LED0603 | red | 3 | LD1, LD2, LD4 |
| LTST-C191KGKT | Lite-On | LED0603 | green | 2 | LD3, LD5 |
| ECS-3225SMV-120-FP-TR | ECS | 32X25 | 12MHz 10ppm (FPGA + FT2232HL) | 1 | Q1 |
| 2N7002LT1G | onsemi | SOT23-3 | 2N7002 | 1 | Q2 |
| 742C043472JP | CTS | 742C043 | 4.7K | 1 | R1 |
| RC0201FR-074K7L | Yageo | R0201 | 4.7K | 3 | R2, R6, R7 |
| 742C163101JP | CTS | 742C163 | 100 | 1 | R4 |
| RC0201FR-075K1L | Yageo | R0201 | 5.1K | 1 | R5 |
| RC0201FR-072K32L | Yageo | R0201 | 2.32K | 2 | R10, R14 |
| RC0201FR-071KL | Yageo | R0201 | 1K | 5 | R11, R15, R20, R22, R23 |
| RC0201FR-07140RL | Yageo | R0201 | 140 | 2 | R12, R16 |
| RC0201FR-07845RL | Yageo | R0201 | 845 | 2 | R13, R17 |
| RC0402FR-0712KL | Yageo | R0402 | 12K 1% | 1 | R18 |
| RC0201FR-0710KL | Yageo | R0201 | 10K | 6 | R19, R90, R91, R92, R93, R94 |
| RC0402FR-071KL | Yageo | R0402 | 1K | 1 | R21 |
| RC0201FR-0733RL | Yageo | R0201 | 33 | 2 | R24, R25 |
| RC0201FR-07200RL | Yageo | R0201 | 200 | 8 | R26, R27, R28, R29, R30, R31, R32, R33 |
| 742C083472JP | CTS | 742C083 | 4.7K | 1 | R34 |
| RC0402FR-074K7L | Yageo | R0402 | 4.7K | 1 | R35 |
| RC0402FR-07100KL | Yageo | R0402 | 100K | 1 | R77 |
| RC0402FR-07680RL | Yageo | R0402 | 680 | 1 | R78 |
| RC0402FR-0733RL | Yageo | R0402 | 33 | 2 | R80, R82 |
| RC0402FR-07330RL | Yageo | R0402 | 330 | 3 | R81, R83, R84 |
| RC0402FR-0710KL | Yageo | R0402 | 10K | 3 | R85, R86, R106 |
| RC0201FR-0710KL | Yageo | R0201 | 10k | 3 | R96, R97, R98 |
| RC0201FR-074K7L | Yageo | R0201 | 4.7k | 1 | R99 |
| RC0201FR-072K21L | Yageo | R0201 | 2.21k | 1 | R101 |
| RC0402FR-073K57L | Yageo | R0402 | 3.57K | 1 | R102 |
| RC0402FR-073K09L | Yageo | R0402 | 3.09K | 1 | R103 |
| RC0402FR-0756K2L | Yageo | R0402 | 56.2K | 1 | R104 |
| RC0402FR-074K32L | Yageo | R0402 | 4.32K | 1 | R105 |
| RC0402FR-071K5L | Yageo | R0402 | 1.5K | 2 | R107, R108 |
| XC7A35T-1CPG236C | AMD/Xilinx | XC7A35T-CPG236 | XC7A35T-1CPG236C | 1 | U1 |
| FT2232HL-REEL | FTDI | FT2232HL-LQFP64 | FT2232HL USB-UART/JTAG Bridge | 1 | U2 |
| AS4C32M16SB-7TCN | Alliance Memory | TSOPII-54 | AS4C32M16SB-7TCN | 1 | U3 |
| W25Q128JVSIQ | Winbond | SOIC-8_208MIL | W25Q128JVSIQ | 1 | U4 |
| SC189ZSKTRT | Semtech | SOT23-5 | SC189ZSKTRT | 1 | U5 |
| SC189LSKTRT | Semtech | SOT23-5 | SC189LSKTRT | 1 | U6 |
| SC189ASKTRT | Semtech | SOT23-5 | SC189ASKTRT | 1 | U7 |
| BQ24232RGTR | Texas Instruments | VQFN16-3X3-RGT | BQ24232 LiPo charger + power path | 1 | U8 |
| 93LC46BT-I/SN | Microchip | SPI-8_SOIC_150 | 93LC46BT-I/SN | 1 | U10 |
| 105017-0001 | Molex | MOLEX-105017-0001 | Molex 105017-0001 Micro-USB-B | 1 | X1 |
| 2x PRPC009SAAN-RC + 2x PRPC011SAAN-RC | Sullins | ZULU-DIP37 | ZULU-CONN | 1 | X2 |
| DM3D-SF | Hirose | DM3D-SF | DM3D-SF | 1 | X3 |
| B2B-PH-SM4-TB(LF)(SN) | JST | JST-B2B-PH-SM4-TB | JST PH 2-pin, 1S LiPo | 1 | X4 |

## 2. Footprint and pin verification

### 2.1 U1 XC7A35T-1CPG236C against the AMD pinout file

- Symbol pins: 238; AMD balls: 238; missing from the symbol: none; not in the package: none.
- Power, ground and dedicated balls and the nets they sit on:

| Ball function | Net(s) | Balls |
|---|---|---:|
| CCLK | FPGA-CCLK (1) | 1 |
| CFGBVS | VCC3V3 (1) | 1 |
| DONE | FPGA-DONE (1) | 1 |
| DXN | GND (1) | 1 |
| DXP | GND (1) | 1 |
| GND | GND (52) | 52 |
| GNDADC | GNDADC (1) | 1 |
| INIT_B | FPGA-INIT# (1) | 1 |
| M0 | CFG-M0 (1) | 1 |
| M1 | CFG-M1 (1) | 1 |
| M2 | CFG-M2 (1) | 1 |
| MGTAVCC | GND (5) | 5 |
| MGTAVTT | GND (4) | 4 |
| MGTPRXN0 | GND (1) | 1 |
| MGTPRXN1 | GND (1) | 1 |
| MGTPRXP0 | GND (1) | 1 |
| MGTPRXP1 | GND (1) | 1 |
| MGTPTXN0 | <open> (1) | 1 |
| MGTPTXN1 | <open> (1) | 1 |
| MGTPTXP0 | <open> (1) | 1 |
| MGTPTXP1 | <open> (1) | 1 |
| MGTREFCLK0N | <open> (1) | 1 |
| MGTREFCLK0P | <open> (1) | 1 |
| MGTREFCLK1N | <open> (1) | 1 |
| MGTREFCLK1P | <open> (1) | 1 |
| MGTRREF | GND (1) | 1 |
| PROGRAM_B | RST# (1) | 1 |
| TCK | FPGA-TCK (1) | 1 |
| TDI | FPGA-TDI (1) | 1 |
| TDO | FPGA-TDO (1) | 1 |
| TMS | FPGA-TMS (1) | 1 |
| VCCADC | VCCADC (1) | 1 |
| VCCAUX | VCC1V8 (2) | 2 |
| VCCBATT | VCC1V8 (1) | 1 |
| VCCBRAM | VCC1V0 (2) | 2 |
| VCCINT | VCC1V0 (6) | 6 |
| VCCO | VCC3V3 (27) | 27 |
| VN | GNDADC (1) | 1 |
| VP | GNDADC (1) | 1 |
| VREFN | GNDADC (1) | 1 |
| VREFP | GNDADC (1) | 1 |
| IO bank 14 | 50 signal nets | 50 |
| IO bank 16 | 12 signal nets | 12 |
| IO bank 34 | 24 signal nets | 24 |
| IO bank 35 | 20 signal nets | 20 |

VCCINT and VCCBRAM on VCC1V0, VCCAUX and VCCBATT on VCC1V8, every VCCO on VCC3V3, the unused GTP supplies and receivers on GND with the transmitters and reference clocks open (UG482 allows both), VP/VN/VREFP/VREFN on GNDADC (internal reference), CFGBVS high for a 3.3 V bank 0. Dedicated config pins (CCLK, DONE, INIT_B, PROGRAM_B, M0-M2, TCK/TMS/TDI/TDO) and the SPI flash D00-D03/FCS_B all sit on their AMD balls; CLK12M is on an MRCC pin and CHAN-CLK on an SRCC pin.

### 2.2 Other parts against their datasheet pin tables

| Part | Check | Result |
|---|---|---|
| U2 FT2232HL | 64 pins, symbol names vs DS_FT2232H tables 3.1-3.4 (the LQFP and QFN share the numbering; no EP on the LQFP) | all match |
| U3 AS4C32M16SB | 54 pads: net on each pad vs the JEDEC x16 pin assignment | all 54 match (pin 40 NC open) |
| U4 W25Q128JVSIQ | 8 pads vs W25Q128JV SOIC-8 pin configuration (1 CS#, 2 DO/IO1, 3 WP#/IO2, 4 GND, 5 DI/IO0, 6 CLK, 7 HOLD#/IO3, 8 VCC) | all match |
| U10 93LC46BT-I/SN | pins vs DS20001749 pin table, FTDI EEPROM wiring (DO via 2.2 k to EEDATA) | all match |
| Q1 ASEM1 | 1 ST/OE, 2 GND, 3 OUT, 4 VDD | all match |
| X1 Molex 105017-0001 | 1 VBUS, 2 D-, 3 D+, 4 ID open, 5 + shell GND | all match |
| LD0 EAST1616RGBA8 | cathodes 2 B, 4 R, 6 G to the FPGA; anodes 1/3/5 through R80/R81/R82 to 3.3 V (19-337 sheet p8 polarity) | all match |
| R34 742C083 | isolated 4-array, 1-8 2-7 3-6 4-5, the microSD DAT0..3 pull-ups | all match |
| R4 742C163 | isolated 8-array: six 100R series resistors, A PROG#, B DONE, C TDI, D TDO, E TMS, F TCK, bridge side on pads 1-6 and FPGA side on pads 16 down to 11; then G and H in series from VCC3V3 as the 200R DONE pull-up (2026-09-10), their common node named DONE-PU so it is not an auto-name | all match |
| R1 742C043 | isolated 2-array, A the INIT_B pull-up and B the PROGRAM_B pull-up, both commons on pads 4 and 3 | all match |
| Q2 2N7002LT1G | G on PGOOD, S on GND, D on the LED; SOT-23 1 G 2 S 3 D | matches (standard 2N7002 pinout, onsemi sheet not fetchable) |
| X2 pin field | 40 pins numbered 1-40 (2026-09-09); mirrored rows, 1-9 + USB landing + 10-20 above, 21-29 + LiPo landing + 30-40 below. Top row 1 GND, 2 CHAN-CLK, 3-9 CHAN0-6, 10-16 CHAN7-13, 17 +3.3V, 18 +1.8V, 19 +1.0V, 20 GND; bottom row 21 GND, 22 VU, 23 RST#, 24-29 CHAN14-19, 30-38 CHAN20-28, 39-40 ANALOG-IO0/1 | all match |
| U8 bq24232 | 17 pin names vs SLUS821J Pin Functions; IN on USB5V0, OUT on VU, BAT on VBATT with X4-1, CE/EN1 low, EN2 high | all match |
| BTN PTS810SJM250SMTR LFS | pins 1,2 = 3.3 V, pins 3,4 = BTN net | PTS810 sheet schematic joins 1-2 and 3-4: matches |

### 2.3 EAGLE package geometry against the datasheet land patterns

| Package | Datasheet | Library package | Verdict |
|---|---|---|---|
| XC7A35T-CPG236 | UG475 v1.20 Table A-1: 0.5 mm pitch, land 0.275 mm NSMD, mask 0.375 | pitch 0.5 OK; lands HELD at 0.225 mm (0.82:1), verified 238 at 0.225 mm by tools/verify_pcblib.py. UG475 gives 0.275 mm as the MAXIMUM land and recommends 1:1 with the package SMD opening for board-level reliability, but at 0.275 the inter-pad gap is 0.225 mm and a 3 mil trace at 3.5 mil clearance needs 0.2562 mm, so the escape is then geometrically impossible on any through-via stack. At 0.225 the gap is 0.275 mm and the margin is +0.0188 mm. PCBWay build BGA lands to 0.2032 mm at 0.4 mm pitch, so 0.225 is inside process | **ok** |
| FT2232HL-LQFP64 | DS_FT2232H Figure 8.2: LQFP-64, 10 x 10 mm body, 12 x 12 mm over leads, 0.5 mm pitch, JEDEC MS-026 BCD, no exposed pad | drawn 2026-09-10 into Imported zulu_a7.PrjPcb/zulu_a7.PcbLib (tools/make_fp_source.py + fp_emit.py, land patterns in docs/footprint_lands.md). FTDI publish NO land pattern -- section 8 is package outlines only -- so this one is DERIVED: IPC-7351B density level B, QFP50P1200X1200X160-64N, pads 0.28 x 1.55 on a 5.70 mm row centre, width rounded up from the strict 0.245 to the industry 0.28 for fillet inspection | **derived** |
| TSOPII-54 | AS4C32M16SB TSOP II 400 mil, 0.8 mm pitch, lead span 11.76 max | pitch 0.8, rows 11.36 apart, 1.2 mm pads OK | **ok** |
| SOIC-8_208MIL | W25Q128JVSIQ SOIC-8 208 mil, lead span 7.9-8.1 | rows 7.3 apart, 1.51 mm pads OK | **ok** |
| SPI-8_SOIC_150 | 93LC46BT-I/SN: SN = 3.90 mm narrow body, E = 6.00 BSC, foot 0.40-1.27 | U10 moved here from the 300-mil SOIC8 on 2026-09-10 (tools/u10_narrow_soic.py). Rows 4.93 apart, 2.07 x 0.51 pads on the 1.27 pitch: lands run 1.43 to 3.50 mm either side of the centreline, so they start inside the 1.95 mm body edge for a heel fillet and reach 0.50 mm past the 3.00 mm lead tip for a toe. The old SOIC8 pattern is still in the PcbLib but nothing references it | **ok** |
| SOT23-3 | 2N7002LT1G SOT-23: 1 G, 2 S, 3 D (standard 2N7002 pinout, datasheet not on disk) | pads G(-0.95,-0.7) S(0.95,-0.7) D(0,0.7), 0.95 pitch OK | **ok** |
| SOT23-5 | SC189xSKTRT SOT23-5, datasheet p23 land: 0.95 pitch, pads 0.60 x 1.10, inner gap 1.40, outer span 3.60 | drawn 2026-09-10 into Imported zulu_a7.PrjPcb/zulu_a7.PcbLib (tools/make_fp_source.py + fp_emit.py, land patterns in docs/footprint_lands.md). Semtech land p23: C (2.50) row centreline, G 1.40, P 0.95, X 0.60, Y 1.10, Z 3.60, all mutually consistent. NOTE pin 4 is DIRECTLY opposite pin 3, not diagonally -- 1/2/3 along one side, 5 opposite 1 and 4 opposite 3 | **ok** |
| DM3D-SF | DM3 catalog p9: 8 x 0.55 pads on 1.1 pitch, 4 cover pads, 2 switch pads, 2 keep-outs | drawn 2026-09-10 into Imported zulu_a7.PrjPcb/zulu_a7.PcbLib (tools/make_fp_source.py + fp_emit.py, land patterns in docs/footprint_lands.md). Taken from the DM3D-SF recommended pattern on catalog p9, not the DM3AT page: eight 0.70 x 1.75 contacts on 1.1 mm pitch, switch A and B, four shell pads G1-G4. The pad-width hint of 0.55 on file was the contact, not the land | **ok** |
| ZULU-DIP37 | Sullins PRPC drawing: 0.64 mm square pins on 2.54 mm, recommended hole 1.02 mm | redrawn 2026-09-10: 44 pads -> 40, the four bottom-row pads at x 36.83/34.29/31.75/29.21 deleted to open the LiPo landing and 34-44 renumbered 30-40, so both rows now read 9 + landing + 11. Verified in the PcbLib: 40 pads named 1-40, two rows of 20, every pad on the intended 2.54 grid, 1.524 mm pads on the Sullins 1.016 mm drill | **ok** |
| VQFN16-3X3-RGT | bq24232 SLUS821J RGT package: 16-pin VQFN 3.0 x 3.0 mm, 0.5 mm pitch, 1.68 mm thermal pad | drawn 2026-09-10 into Imported zulu_a7.PrjPcb/zulu_a7.PcbLib (tools/make_fp_source.py + fp_emit.py, land patterns in docs/footprint_lands.md). TI land pattern p44 (RGT0016C): 16 lands 0.6 x 0.24 on 0.5 mm pitch at a 1.40 mm row centre, 1.68 mm thermal land as pad 17. Two Altium-side settings still to make: pad 17 paste shrunk to 1.55 (TI ask ~85 % coverage) and 0.07 mm mask expansion on 1-16 so the 0.24 mm lands are not mask-defined | **ok** |
| JST-B2B-PH-SM4-TB | JST PH SM4 top-entry SMT: two contact pads on 2.0 mm pitch plus two 1.6 x 3.0 mm fixing pads (catalog page 1) | drawn 2026-09-10 into Imported zulu_a7.PrjPcb/zulu_a7.PcbLib (tools/make_fp_source.py + fp_emit.py, land patterns in docs/footprint_lands.md). JST SM4 top-entry land, p1: contacts 1.0 x 5.5 on the 2.0 mm pitch, fixing pads MP1/MP2 1.6 x 3.0 at +-3.4. The lands run 2.5 mm past the body on the lead side -- keep that strip clear | **ok** |
| 742C163 | CTS 742C163 (DOC 008-0335-0 Rev T): 8 x 0603 concave-termination array, body 6.4 x 1.6, 0.8 mm pitch, 16 pads; CTS publishes one land for the whole 742 family, the 0.45 x 0.9 pads at +-0.85 already checked for 742C083 | drawn 2026-09-10 into Imported zulu_a7.PrjPcb/zulu_a7.PcbLib (tools/make_fp_source.py + fp_emit.py, land patterns in docs/footprint_lands.md). Sixteen 0.45 x 0.9 lands on the 0.8 mm pitch at +-0.85, numbering counter-clockwise so each element spans one column (1-16, 2-15 ... 8-9), which is exactly the pairing the schematic wires. All eight elements used, G and H in series as the DONE pull-up | **ok** |
| 742C043 | CTS 742C043 (DOC 008-0335-0 Rev T): 2 x 0603 concave-termination array, body 1.6 x 1.6, 0.8 mm pitch, 4 pads; same family land as 742C083 | drawn 2026-09-10 into Imported zulu_a7.PrjPcb/zulu_a7.PcbLib (tools/make_fp_source.py + fp_emit.py, land patterns in docs/footprint_lands.md). Four 0.45 x 0.9 lands on the 0.8 mm pitch at +-0.85, elements 1-4 and 2-3. CTS publish no pin-1 marking for this package and the datasheet is not on disk, so the numbering rests on the family land plus the schematic pairing, not on a printed pin-1 callout | **ok** |
| MOLEX-105017-0001 | Molex 105017 drawing: 5 x 0.4 mm pads on 0.65 pitch, 4 shell pads, 2 pegs | 0.65 pitch, 0.4x1.35 pads, shell pads OK | **ok** |
| 32X25 | ASEM1 3.2x2.5 mm, 4 pads | pads 1.2x1.4 at 1.7 x 2.2 OK | **ok** |
| EVERLIGHT-19-337 | Everlight 19-337 p8 recommended pads: 0.55x0.4 outer at +-0.725, 0.7x0.5 middle, 1.9/2.2 spans (the VS NRD8 p2 drawing line for line) | identical to the VS-NRD8 pattern in the library; renumber the pads 1/2/3 -> 2/4/6, 4/5/6 -> 1/3/5 when the footprint is drawn | **ok** |
| PTS810 | C&K PTS810 sheet p1: four pads 1.05 x 0.65 mm centred at +-2.075 x +-1.075 mm (5.2 x 2.8 mm envelope), body 4.2 x 3.2 mm | drawn 2026-09-10 into Imported zulu_a7.PrjPcb/zulu_a7.PcbLib (tools/make_fp_source.py + fp_emit.py, land patterns in docs/footprint_lands.md). C&K land p1: four 1.05 x 0.65 pads at +-2.075, +-1.075. Pairing is ROW-WISE -- pads 1+2 are one terminal and 3+4 the other, not the diagonal many tact switches use -- which is how BTN is wired | **ok** |
| 742C083 | CTS 742C083: 4 x 0603 concave-termination array (3.2 x 1.6), 0.8 mm pitch; CTS land 0.45 x 0.9 pads at +-0.85 | pitch 0.8, 0.5 x 0.9 pads at +-0.9, 0.05 mm per side wider than CTS: OK; 742C083472JP shares the package code, the Bourns CAT16 and Panasonic EXB-V8V substitutes are convex parts on the same land | **ok** |
| IND2520 | Murata DFE252010P: 2.5 x 2.0 mm, two pads | pads 1.05x2.3 at 2.35 OK | **ok** |
| C0402 / R0402 | Murata GRM15 land 0.5 wide, gap 0.4, span 1.5; Samsung 1005 land 0.51-0.59 wide, gap 0.36-0.44, span 1.34-1.58 | pads 0.7 x 0.9 at +-0.65 (gap 0.6, span 2.0): larger in every dimension than either vendor asks; solders, but the extra solder volume raises tombstoning exposure on every 0402 position | **note** |
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

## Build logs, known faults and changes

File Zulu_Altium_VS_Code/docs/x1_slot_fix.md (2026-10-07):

# X1 shell-stake slots (2026-10-07)

X1 is a Molex 105017-0001 micro-USB-B. Its two front shell legs (MS1/MS2, at the mating-face end; the earlier text said "rear") were drilled as 0.60 mm round holes,
but the Molex land pattern (SD-105017-001, "Recommended P.C.B. pattern layout") calls for 0.60 x 1.30 mm slots
with full-radius ends. The legs are 0.60 +/- 0.10 mm wide and 0.30 mm thick, so they cannot enter a 0.60 mm round
hole and the connector would sit high on its SMT joints.

## Source of the fix

The fix was first made in `Zulu_Altium_VS_Code_HDI_Optimized` (`tools/CorrectX1Slots.pas`, notes in
`HDI_OPTIMIZATION_NOTES.md`). That copy was only read, never written. Its geometry was ported to this board unchanged.

## What changed on `Imported zulu_a7.PrjPcb/zulu_a7.PcbDoc`

Scripts: `tools/ProdX1Slots.pas` (`CorrectX1Slots`) and `tools/ProdX1Slots2.pas` (`ResolveX1SlotClearances`,
`RefineX1SlotClearances`), each loaded as its own `.PrjScr`. They differ from the reference only in the document
guard, which accepts this board only, and in the X1 designator guard. On this board the designator was off-board at
(28.829, 27.259), not at the reference's (37.167, 22.300).

- **X1-MS1/MS2:** plated slots, hole 0.60 mm, length 1.30 mm, rotation 90, centred at (29.5199, 23.9585) and
  (36.5201, 23.9585). The pad copper stays at 0.90 mm round.
- **CHAN12:** the CHAN12 route was moved clear of the slots.
  - Bottom run moved from y 23.20 to 23.15 (x 16.25 to 35.80).
  - The L4-L5 and L5-Bottom stacked microvias moved from (36.15, 23.25) to (35.80, 23.35), with their Bottom and
    L4 stubs.
  - The four tracks and two vias are byte-identical to the reference board's records.
- **X1 designator:** moved to (37.442, 22.250), the reference's final position.
- **Rule `HoleSize_X1`:** `InComponent('X1')`, 0.20 to 1.30 mm. It admits the 1.30 mm slot length without
  widening the global hole-size rule.
- **Planes:** the L2 and L5 polygons re-poured around the slots and the moved vias. The fill changes are local to X1
  apart from one L2 vertex at (36.759, 6.668) that moved by 1.9 um.
- **Save side effects, not design changes:** X1's designator autoposition flag cleared; three HoleSize rule
  priorities renumbered; one stale CHAN12 connection record dropped; drill-manager and GUID caches updated.

## Verification

- **Altium DRC** 2026-10-07 08:11: 0 warnings, 0 rule violations. The report is `Design Rule Check - zulu_a7.drc`.
- **`tools/verify_stack.py`:** PASS (JLCH061611N2-2116).
- **NC drill:**
  - `zulu_a7-SlotHoles.TXT` has exactly two G85 slots, 0.60 mm tool, ends 0.70 mm apart, so 1.30 mm overall.
  - The round-hole counts are unchanged. Top-Bottom has 440 holes: 380 vias, 2 x 0.85 and 58 x 1.016. The laser
    and buried pairs are 296 / 282 / 369 / 230 / 230.
  - The old 0.60 mm round tool is gone.
- **Gerbers versus 2026-10-02:**
  - Top copper, both masks, both pastes, Bottom silk and the profile are identical.
  - L2, L4, L5, Bottom copper and Top silk differ only at X1's slots, CHAN12 and the designator, plus the 1.9 um
    L2 vertex above.
- **New board hash:** PcbDoc SHA-256 `e91c148d92b3d73828f69b7a5623f56d86d6e40dd546c6b97d5ce94c9e88d4b7`. The
  pre-fix hash was `181b1a8c...`. (Superseded by the later changes below and in `x2_power_pins.md` and
  `x2_pin_labels.md`.)

## Release files

- `fabrication/Zulu_A7_JLCPCB_Fabrication_2026-10-07.zip` replaced the 2026-10-04 archive, which had the round
  holes. It has itself been superseded by the PCBWay package below.
- The drill files are now named `zulu_a7-RoundHoles.*` plus `zulu_a7-SlotHoles.TXT`. The old `zulu_a7.TXT` and
  `zulu_a7.TX*` files were removed.

## Not changed

- **PcbLib footprint:** the `MOLEX-105017-0001` footprint in `zulu_a7.PcbLib` still has round MS holes, as in the
  reference copy. An "Update from PCB Libraries" would revert the slots until the library is updated too.
- **Assembly release:** `assembly/` was not regenerated. X1's position and rotation are unchanged.

## Lands and clearances fixed for PCBWay (2026-10-07, later)

Verification of the slot fix found two problems, inherited from the reference geometry: no ring at the slot ends,
and copper under 0.15 mm from the slot walls. Fabrication moved to PCBWay, so the fix targets PCBWay's published
"Normal" class. The sources are capabilities.html items 10, 11, 13, 17 and 19, and the hole-to-edge and hole-spacing
engineering-question pages; the full list is in the session's research notes.

**Pads.** `tools/ProdX1Pads3.pas` (`FixX1PadsAndClearances`, after the read-only `X1PadsCanary`) switched the MS1/MS2
padstack to top/middle/bottom mode:
- Top and Bottom: oblong 1.11 x 1.81 mm. The ring is 0.255 mm, against PCBWay's component-hole ring of at least
  0.254 mm on 1 oz outer copper.
- Inner layers: 0.90 x 1.60 mm. The ring is 0.15 mm.

**CHAN12.** The route was re-done:
- The Bottom run now stops at x 27.95.
- It rises west of MS1 to (28.72, 23.92) and (28.72, 24.62).
- It crosses over both slots at y 25.02.
- It drops to the moved L4-L5 / L5-Bottom stacked microvias at (37.45, 24.40).
- L4 goes straight down from there to the existing run at (37.45, 23.15).

**Planes.** All polygons were re-poured.

Measured on the saved board (KiCad import of the PcbDoc, `scratchpad x1fix2/verify_saved.py` and `check.py`; exact values from
the independent verification):

| Check | Result | PCBWay normal |
|---|---|---|
| MS ring, Top/Bottom | 0.255 mm | >= 0.254 |
| Slot hole to inner copper | L5 VCC3V3 plane 0.240 mm (was 0.090); tracks >= 0.2477 mm (CHAN13 on L4) | >= 0.203 |
| Slot hole to outer copper | >= 0.3608 mm (FPGA-TCK on Bottom) | >= 0.152 (old engineering-question page 0.35) |
| Hole to hole, different nets | >= 0.559 mm | PTH >= 0.45, via >= 0.30 |
| Slot hole to board edge | 0.791 mm | >= 0.5 |
| New copper to board edge | 0.342 mm (CHAN12 at y 25.02); via land 0.85 mm | >= 0.25 |
| New copper to copper | 0.0900 mm (re-poured L5 plane to the MS inner lands and the moved via lands); >= 0.1058 mm on Bottom (MS2 to FPGA-TCK); 0.0977 mm MS1 to CHAN13 on L4 | board rule 0.09 |

The only object changes against the slot-fix board:
- the MS1/MS2 land sizes;
- 4 CHAN12 tracks changed and 4 added;
- 2 CHAN12 vias moved;
- the plane fills.

No pad moved or changed net.

- **Altium DRC** 2026-10-07 09:40: 0 warnings, 0 violations. It was re-run at 10:03, after the 09:41 save, on the
  unchanged board: 0 / 0. `verify_stack.py` passes. The PcbDoc SHA-256 is
  `4f73e1a215a21d19623c0956719072aeaa8c6b258501a21de8923bfff705f688` (superseded by the X2 changes:
  `x2_power_pins.md`, then `x2_pin_labels.md`).
- **Fab outputs** regenerated. The slot file is unchanged: two G85 slots. The round-hole counts are unchanged
  (440 / 369 / 296 / 282 / 230 / 230). Gerbers changed only at the MS lands, CHAN12 and the planes; GM and GBP differ
  only by aperture numbering.
- **Release:** `fabrication/PCBWAY_FAB_NOTES.txt` and `Zulu_A7_PCBWay_Fabrication_2026-10-07.zip` replace the JLCPCB
  notes and zip.
- **KiCad:** the copy was updated the same way (`Zulu_kicad/tools/apply_x1_pads.py`).

### Board-wide items PCBWay must review (not X1-specific; listed in the fab notes)

- Track/space 0.0762 / 0.09 mm. capabilities.html items 14/15 put 1 oz under 4 mil in "unable"; their order form
  allows 3/3 mil.
- Via rings: 0.075 mm (through and laser) and 0.06 mm (buried). PCBWay's via ring minimum is 3 mil (0.076 mm).
- Different-net via hole-to-hole down to 0.24 mm. PCBWay asks for 0.30 mm.
- 0.20 mm through-via drills in a board about 1.63 mm thick. capabilities.html item 5 caps a 0.20 mm drill at 1.6 mm.

## Library footprints updated (2026-10-07)

- **Altium `zulu_a7.PcbLib`:** footprint `MOLEX-105017-0001`, MS1/MS2 changed by `tools/ProdX1Lib2.pas`
  (`FixX1LibFootprint`, after the read-only `X1LibCanary`). They are now plated 0.60 x 1.30 slots at rotation 90 with
  top/middle/bottom lands 1.11 x 1.81 / 0.90 x 1.60 / 1.11 x 1.81. A first load, `ProdX1Lib.pas`, refused: its
  position guard subtracted the library origin, but library pad coordinates are footprint-relative.
- **Altium check:** with KiCad's Altium loader, MOLEX-105017-0001 is the only one of the 41 footprints that changed,
  and only MS1/MS2 within it changed. They now equal X1 on the board. The footprint graphics are unchanged. Pad 2 was
  already 10 nm off the board before this edit.
- **KiCad `zulu_a7.pretty/MOLEX-105017-0001.kicad_mod`:** the MS1/MS2 pad blocks were replaced with copies of the
  board's padstack (`Zulu_kicad/tools/apply_x1_libpads.py`, then a splice that keeps the pad UUIDs). The file differs
  from the old one only in those two blocks.
- **KiCad check:** MS1/MS2 now equal X1 on the board. MH1/MH2 already differed between library and board, as
  CONVERSION.md records for X1.

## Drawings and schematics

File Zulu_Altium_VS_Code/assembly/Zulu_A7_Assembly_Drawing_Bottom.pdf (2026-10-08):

# Zulu A7 - Bottom Assembly Drawing - Overview

## MIRRORED - viewed from bottom; dimensions and coordinate grid in millimetres

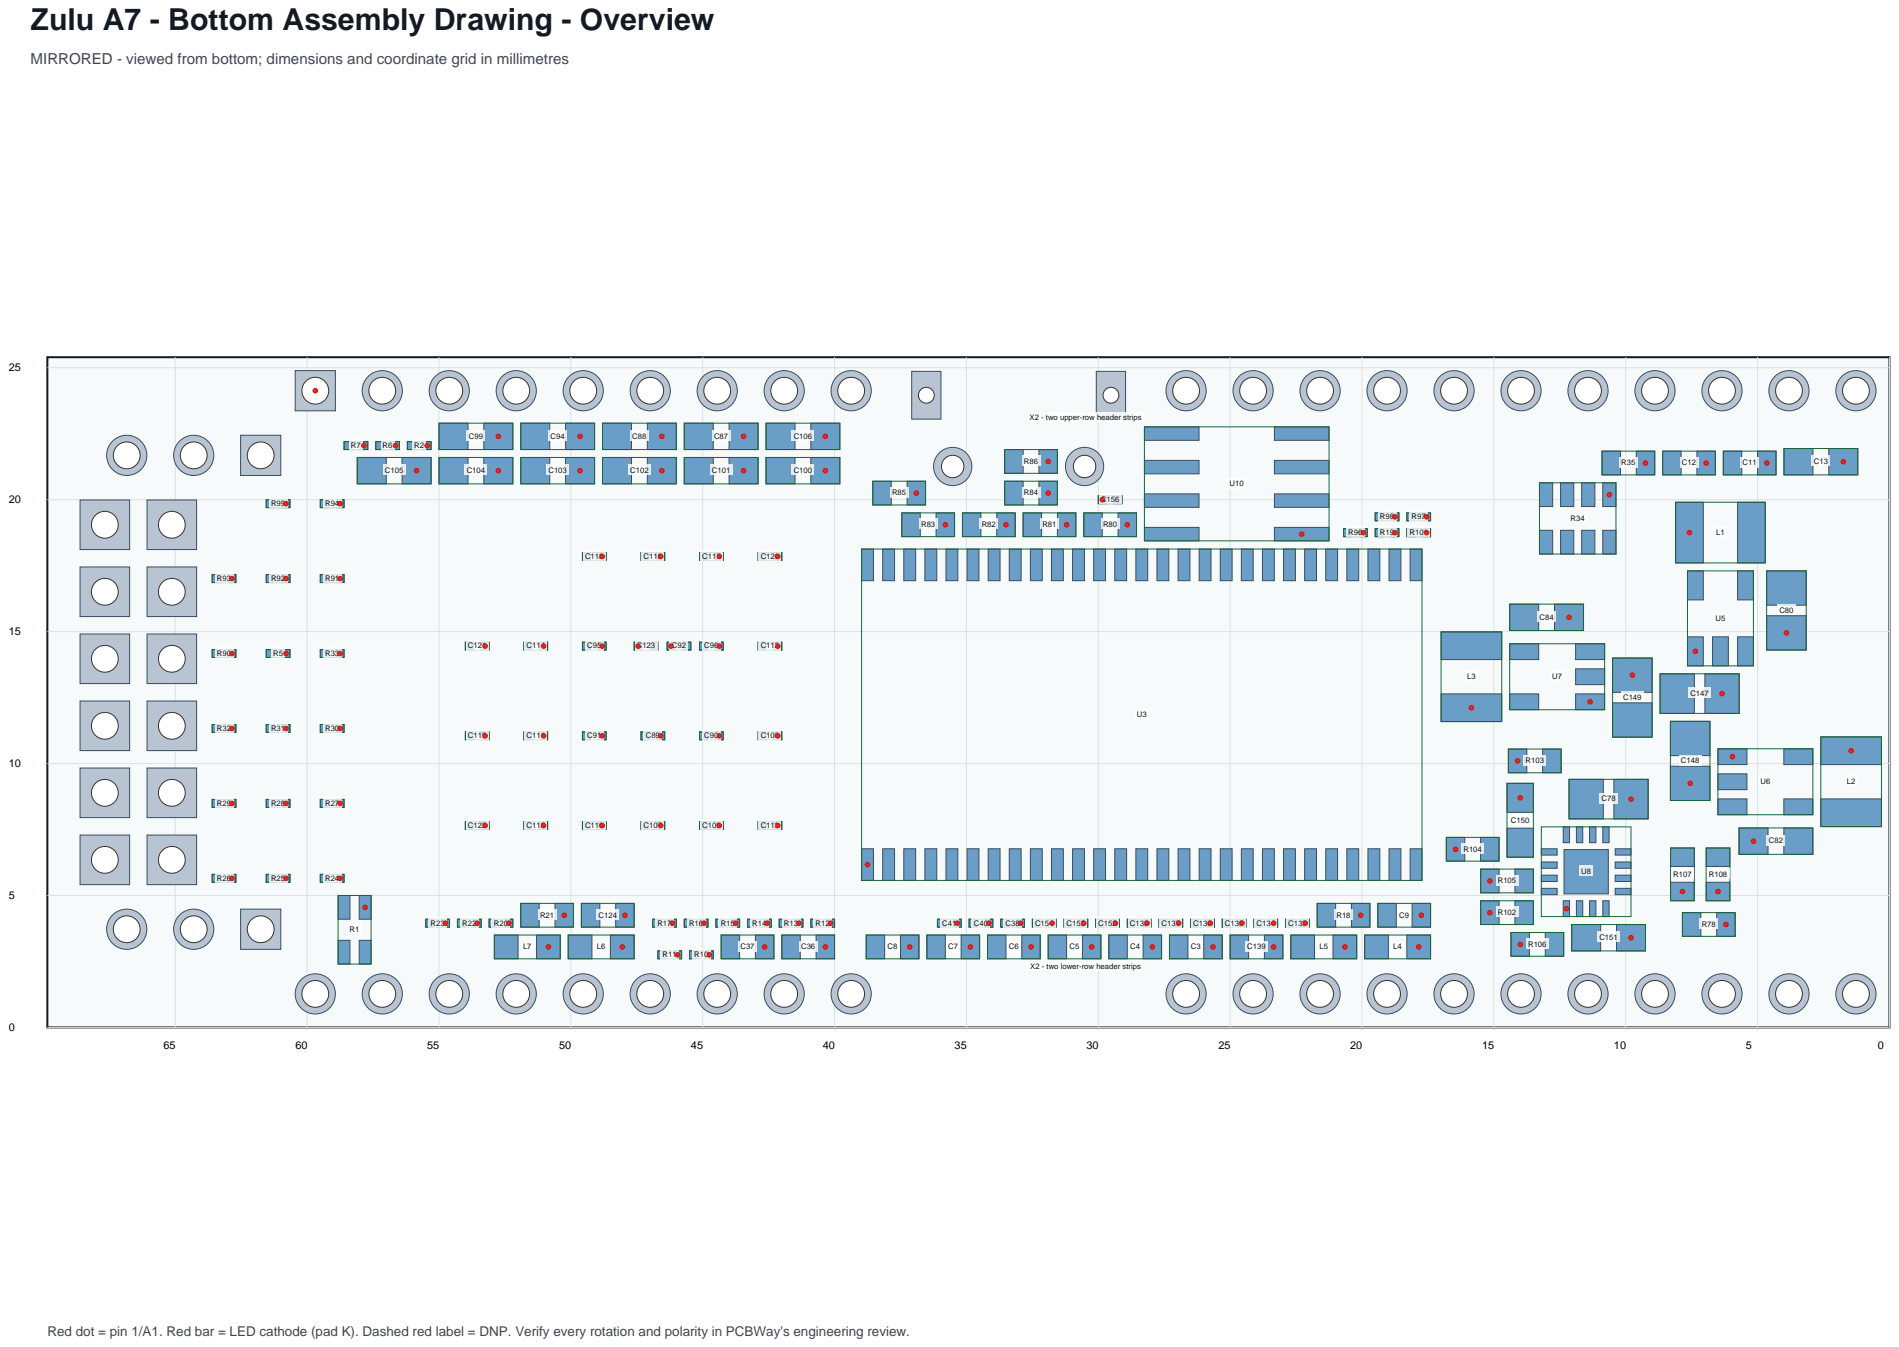
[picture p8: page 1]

X2 - two upper-row header strips

X2 - two lower-row header strips

Red dot = pin 1/A1. Red bar = LED cathode (pad K). Dashed red label = DNP. Verify every rotation and polarity in PCBWay's engineering review.

# Zulu A7 - Bottom Assembly Drawing - West Detail

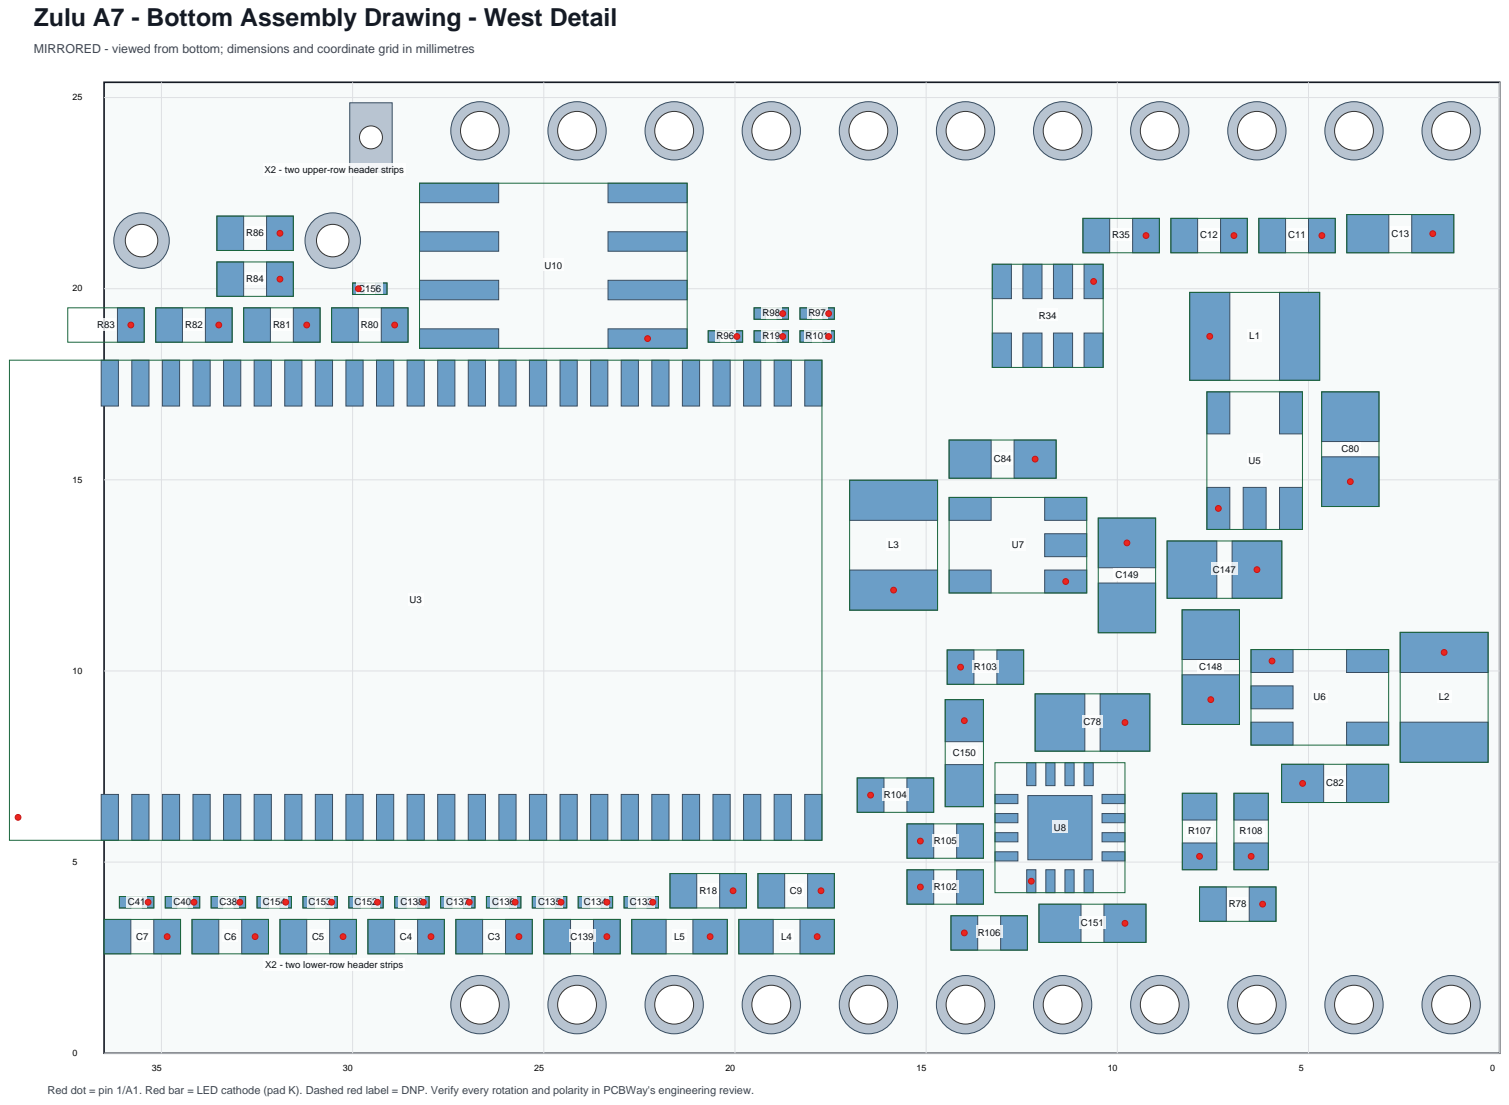
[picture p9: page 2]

X2 - two upper-row header strips

X2 - two lower-row header strips

# Zulu A7 - Bottom Assembly Drawing - East Detail

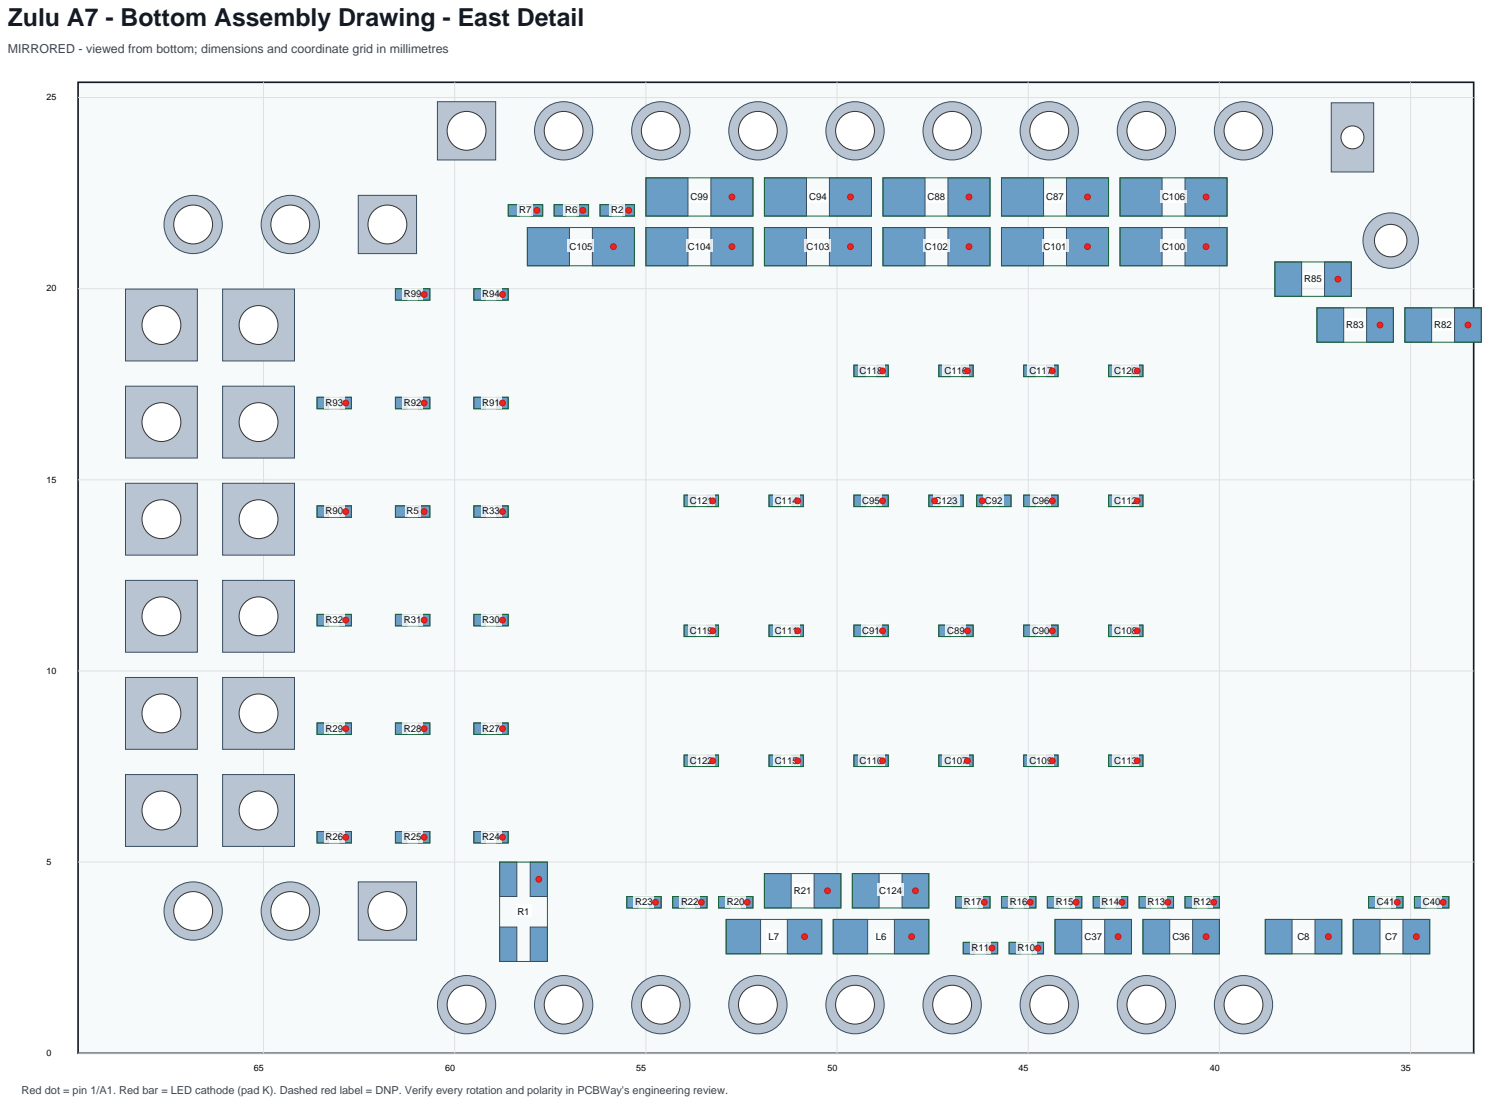
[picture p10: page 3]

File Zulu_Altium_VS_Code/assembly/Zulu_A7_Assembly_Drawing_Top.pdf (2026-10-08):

# Zulu A7 - Top Assembly Drawing - Overview

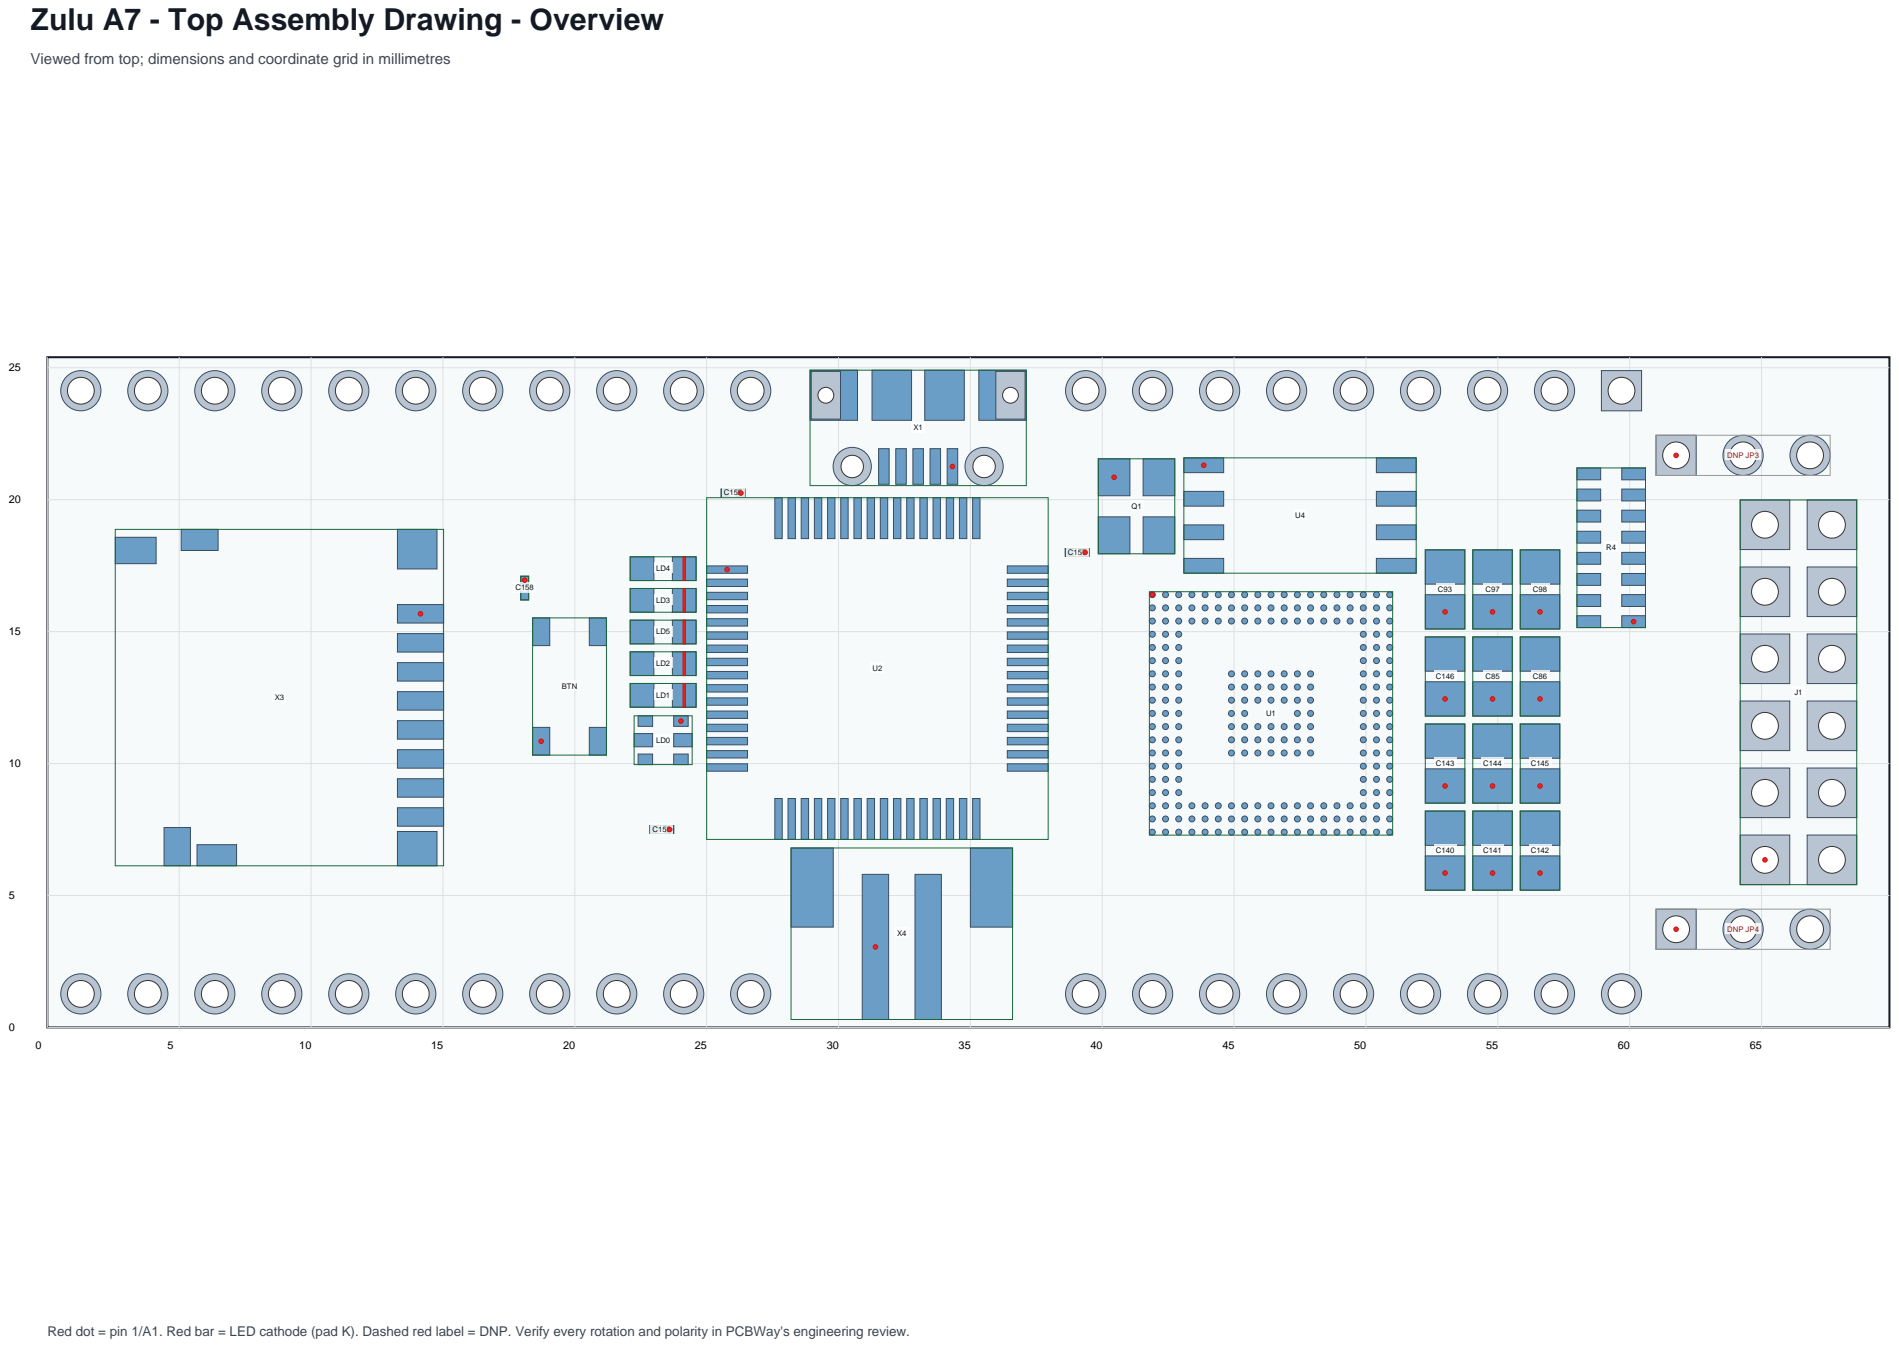
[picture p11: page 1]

Viewed from top; dimensions and coordinate grid in millimetres

Red dot = pin 1/A1. Red bar = LED cathode (pad K). Dashed red label = DNP. Verify every rotation and polarity in PCBWay's engineering review.

# Zulu A7 - Top Assembly Drawing - West Detail

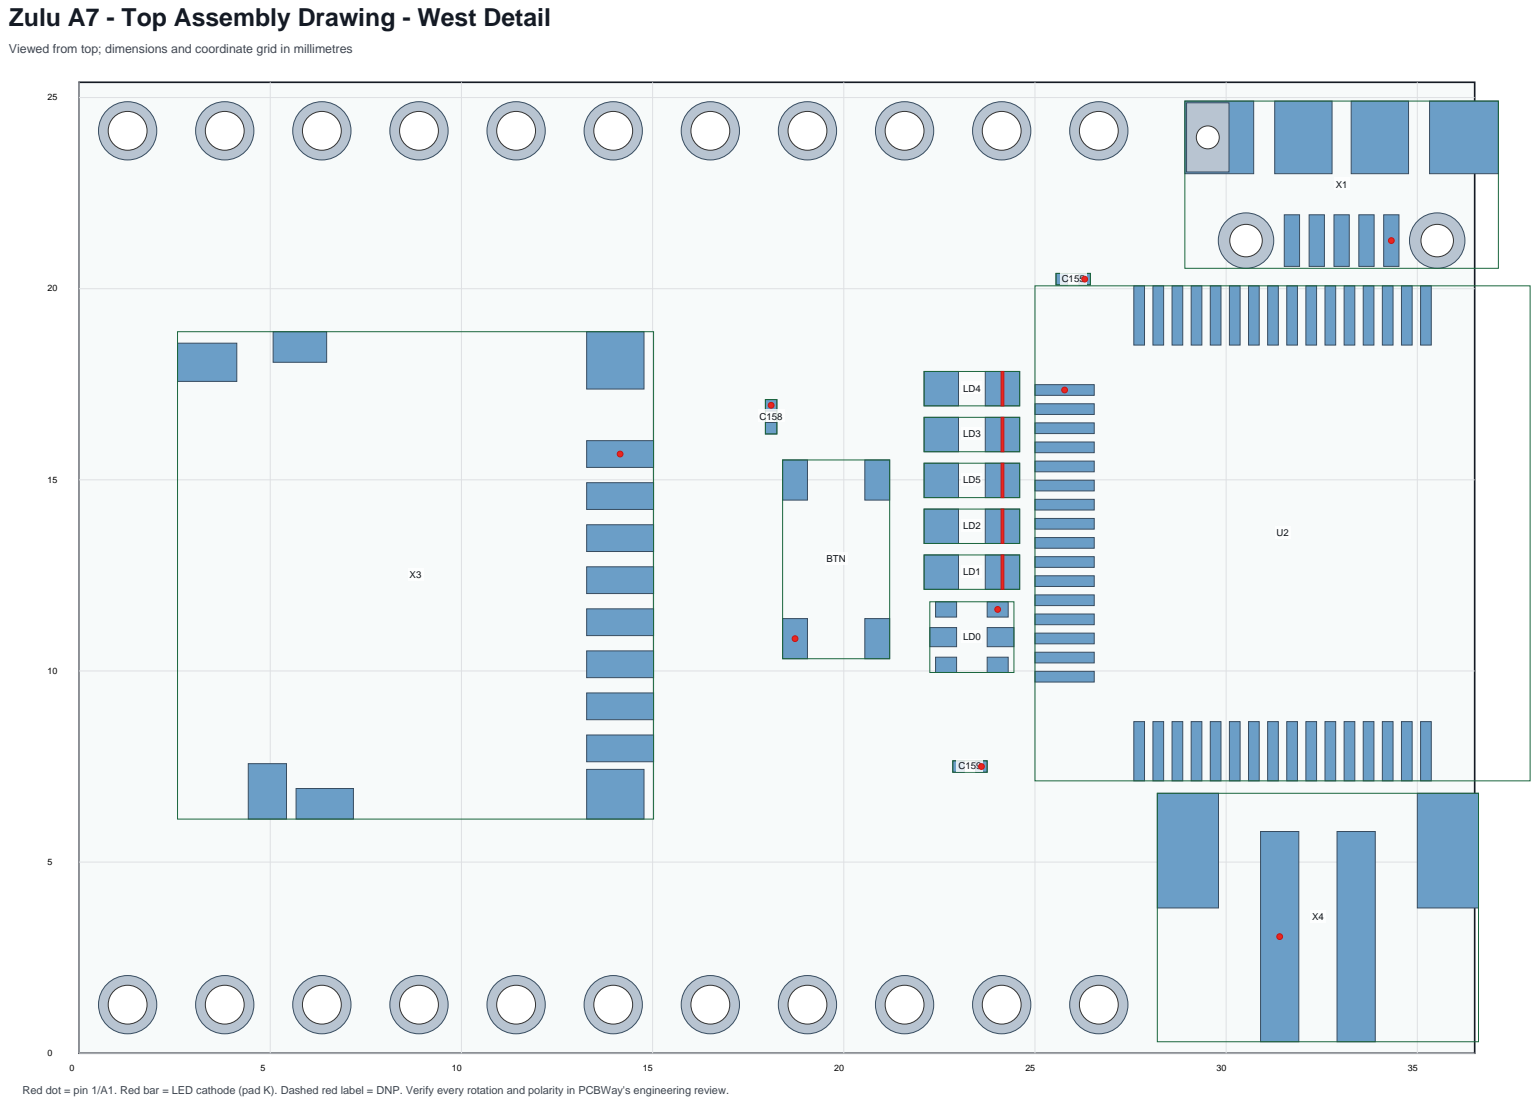
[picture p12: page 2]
BTN

# Zulu A7 - Top Assembly Drawing - East Detail

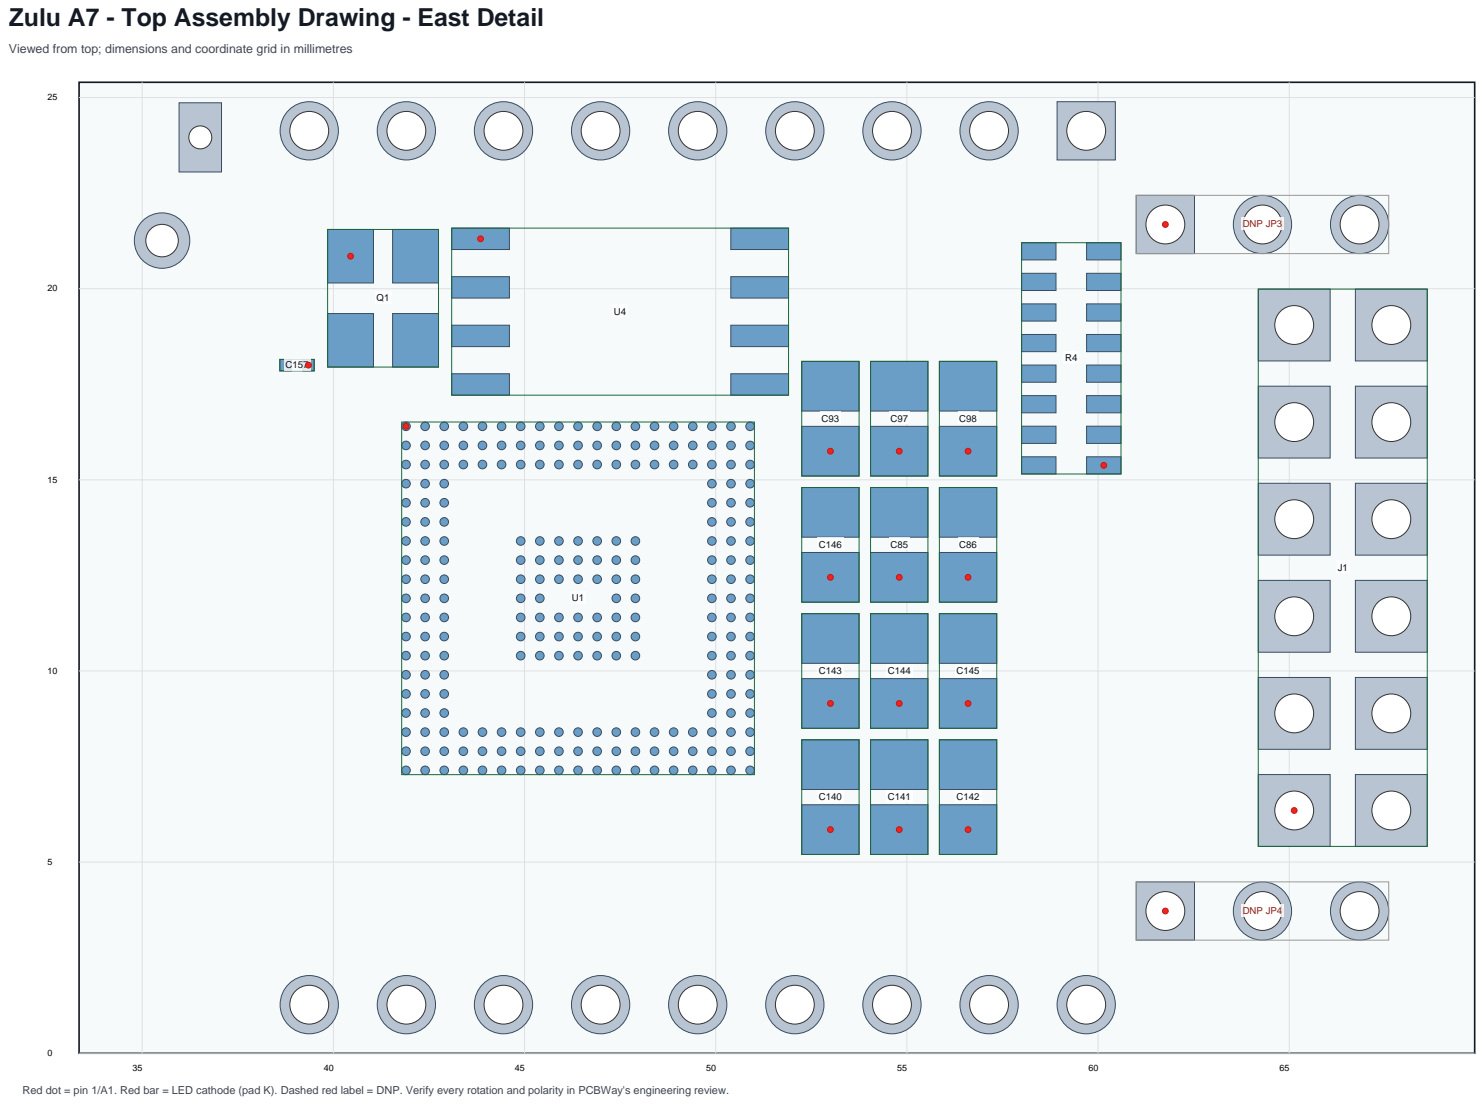
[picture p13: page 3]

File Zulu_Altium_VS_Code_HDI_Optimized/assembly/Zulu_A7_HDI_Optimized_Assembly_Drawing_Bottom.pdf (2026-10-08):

# Zulu A7 HDI Optimized - Bottom Assembly Drawing - Overview

## MIRRORED - viewed from bottom; dimensions and coordinate grid in millimetres

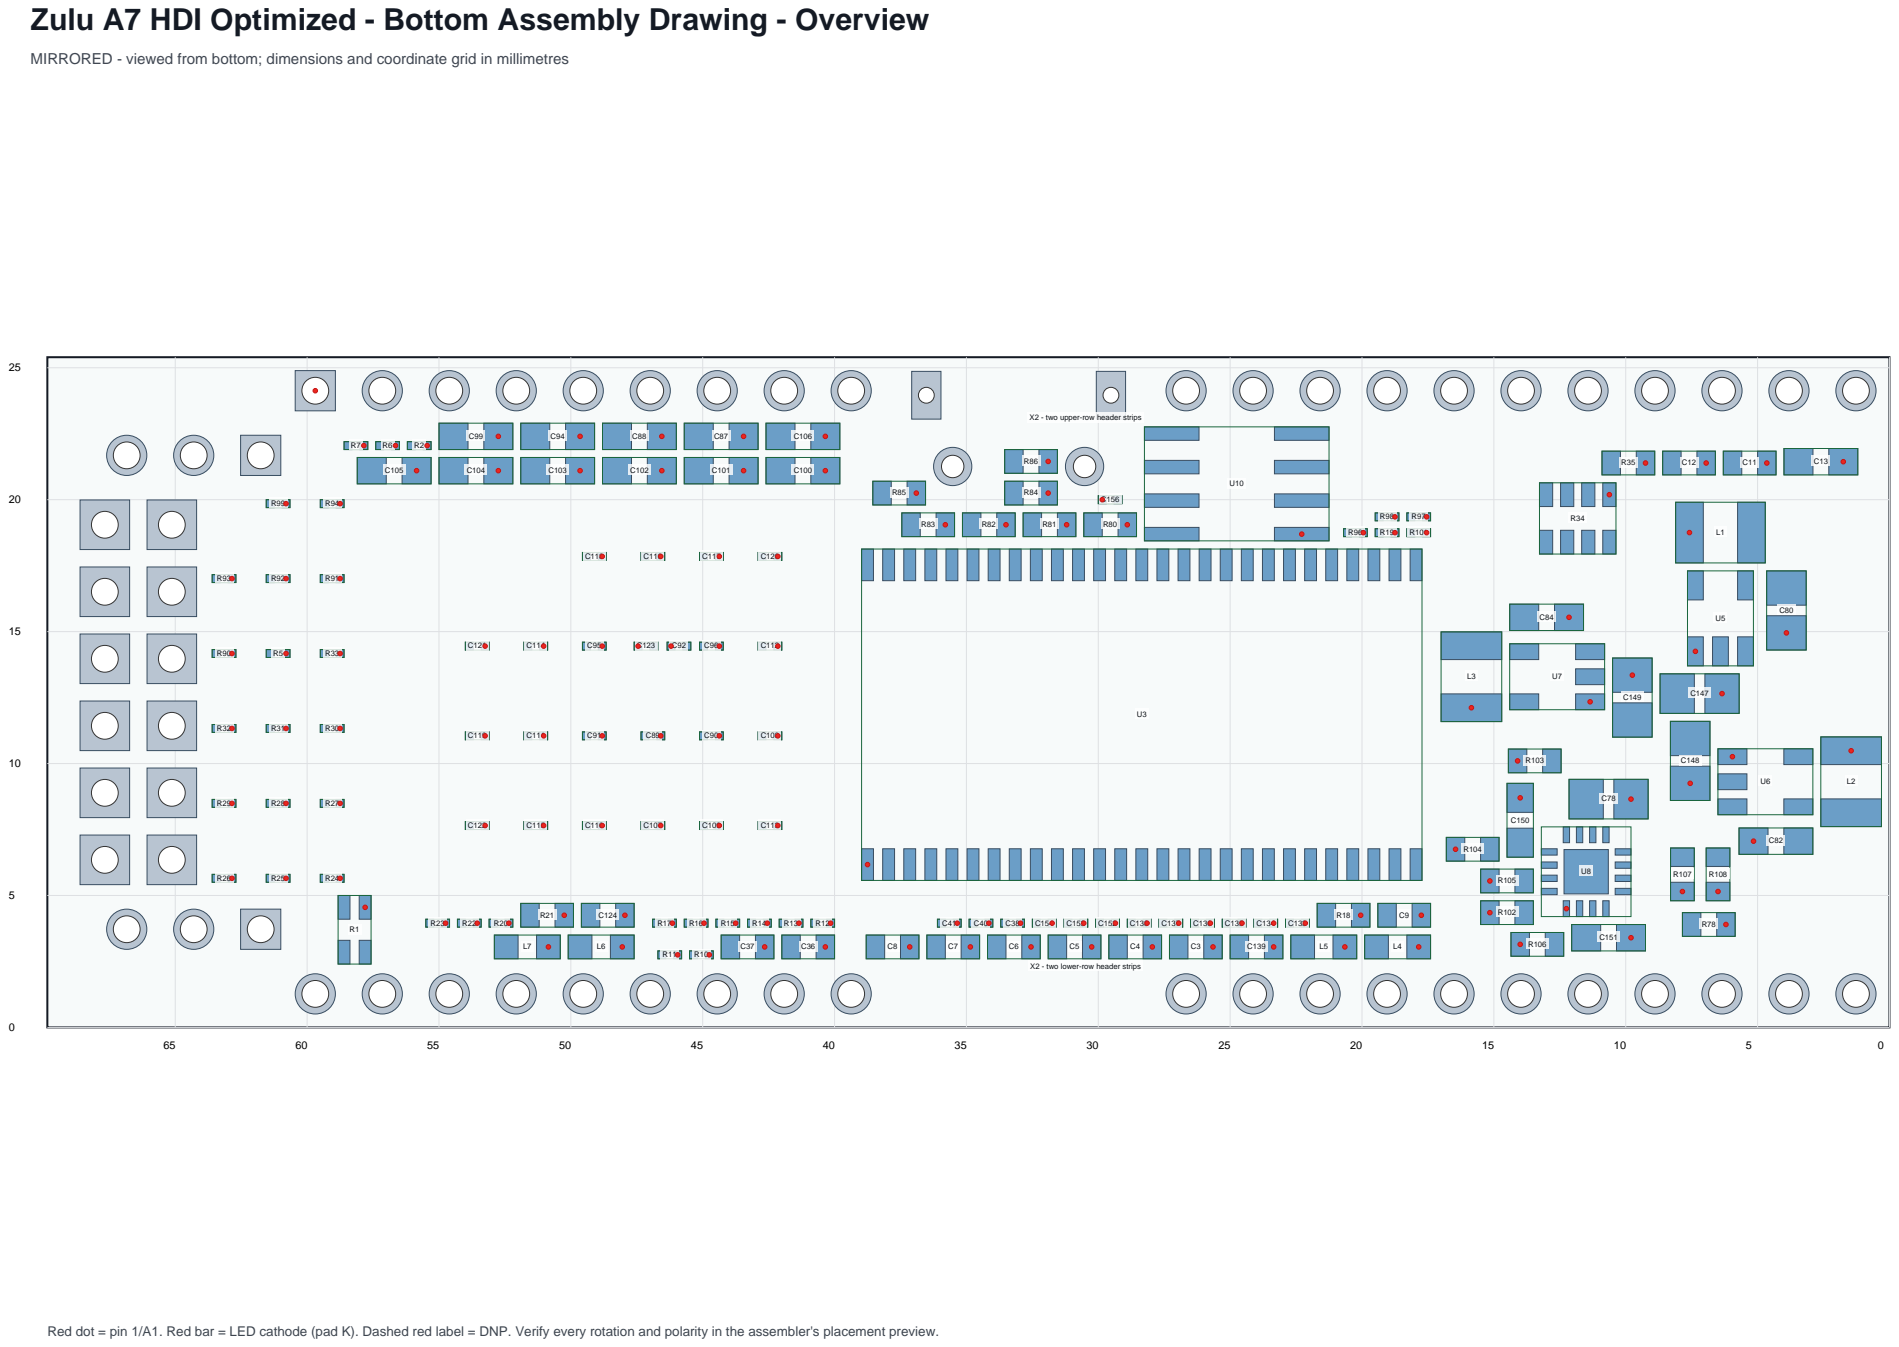
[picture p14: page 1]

X2 - two upper-row header strips

X2 - two lower-row header strips

Red dot = pin 1/A1. Red bar = LED cathode (pad K). Dashed red label = DNP. Verify every rotation and polarity in the assembler's placement preview.

# Zulu A7 HDI Optimized - Bottom Assembly Drawing - West Detail

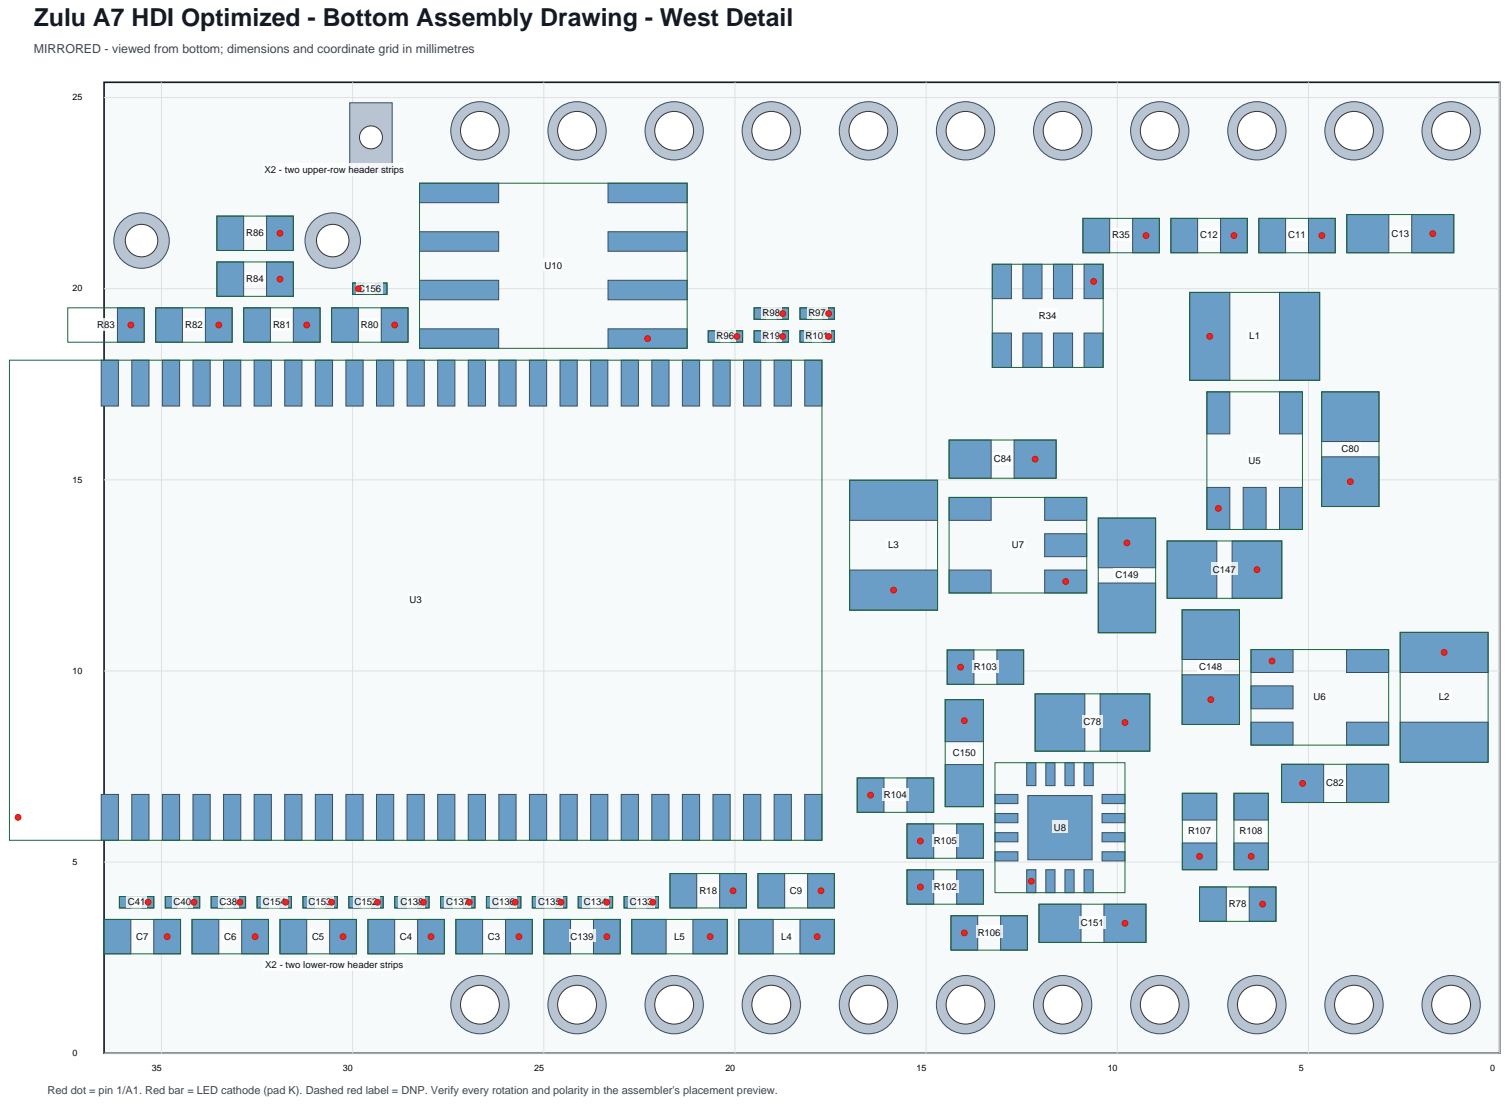
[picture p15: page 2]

X2 - two upper-row header strips

X2 - two lower-row header strips

# Zulu A7 HDI Optimized - Bottom Assembly Drawing - East Detail

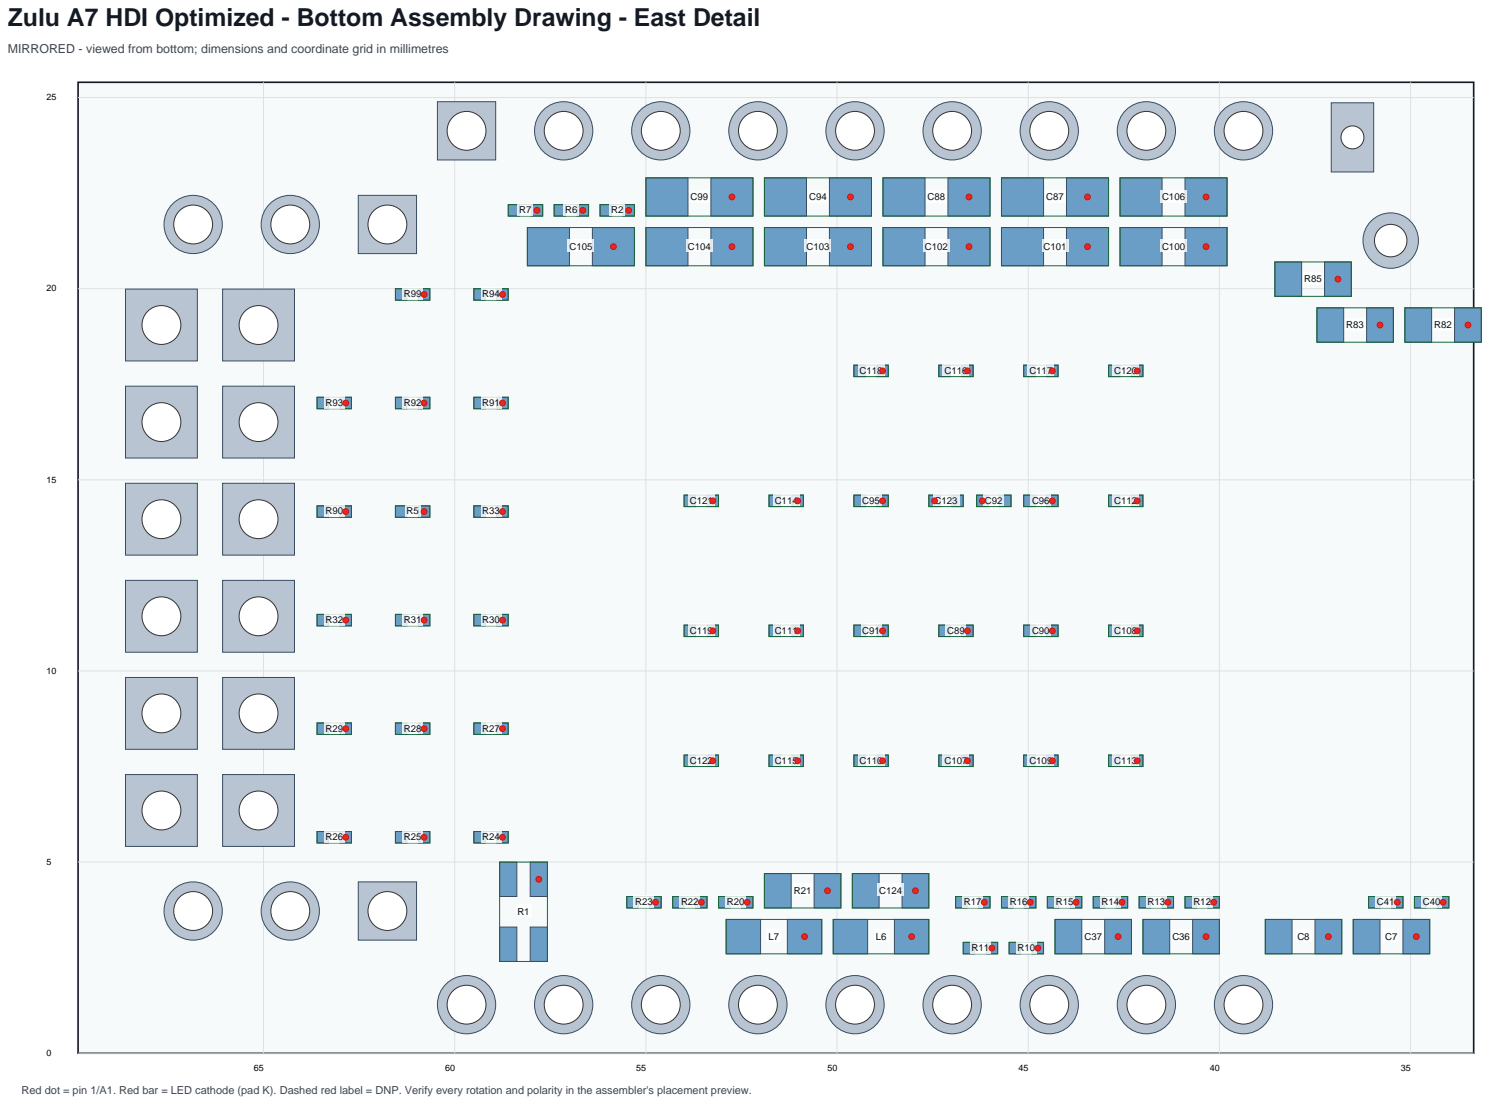
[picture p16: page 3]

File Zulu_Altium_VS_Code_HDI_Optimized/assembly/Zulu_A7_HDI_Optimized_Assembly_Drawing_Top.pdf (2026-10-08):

# Zulu A7 HDI Optimized - Top Assembly Drawing - Overview

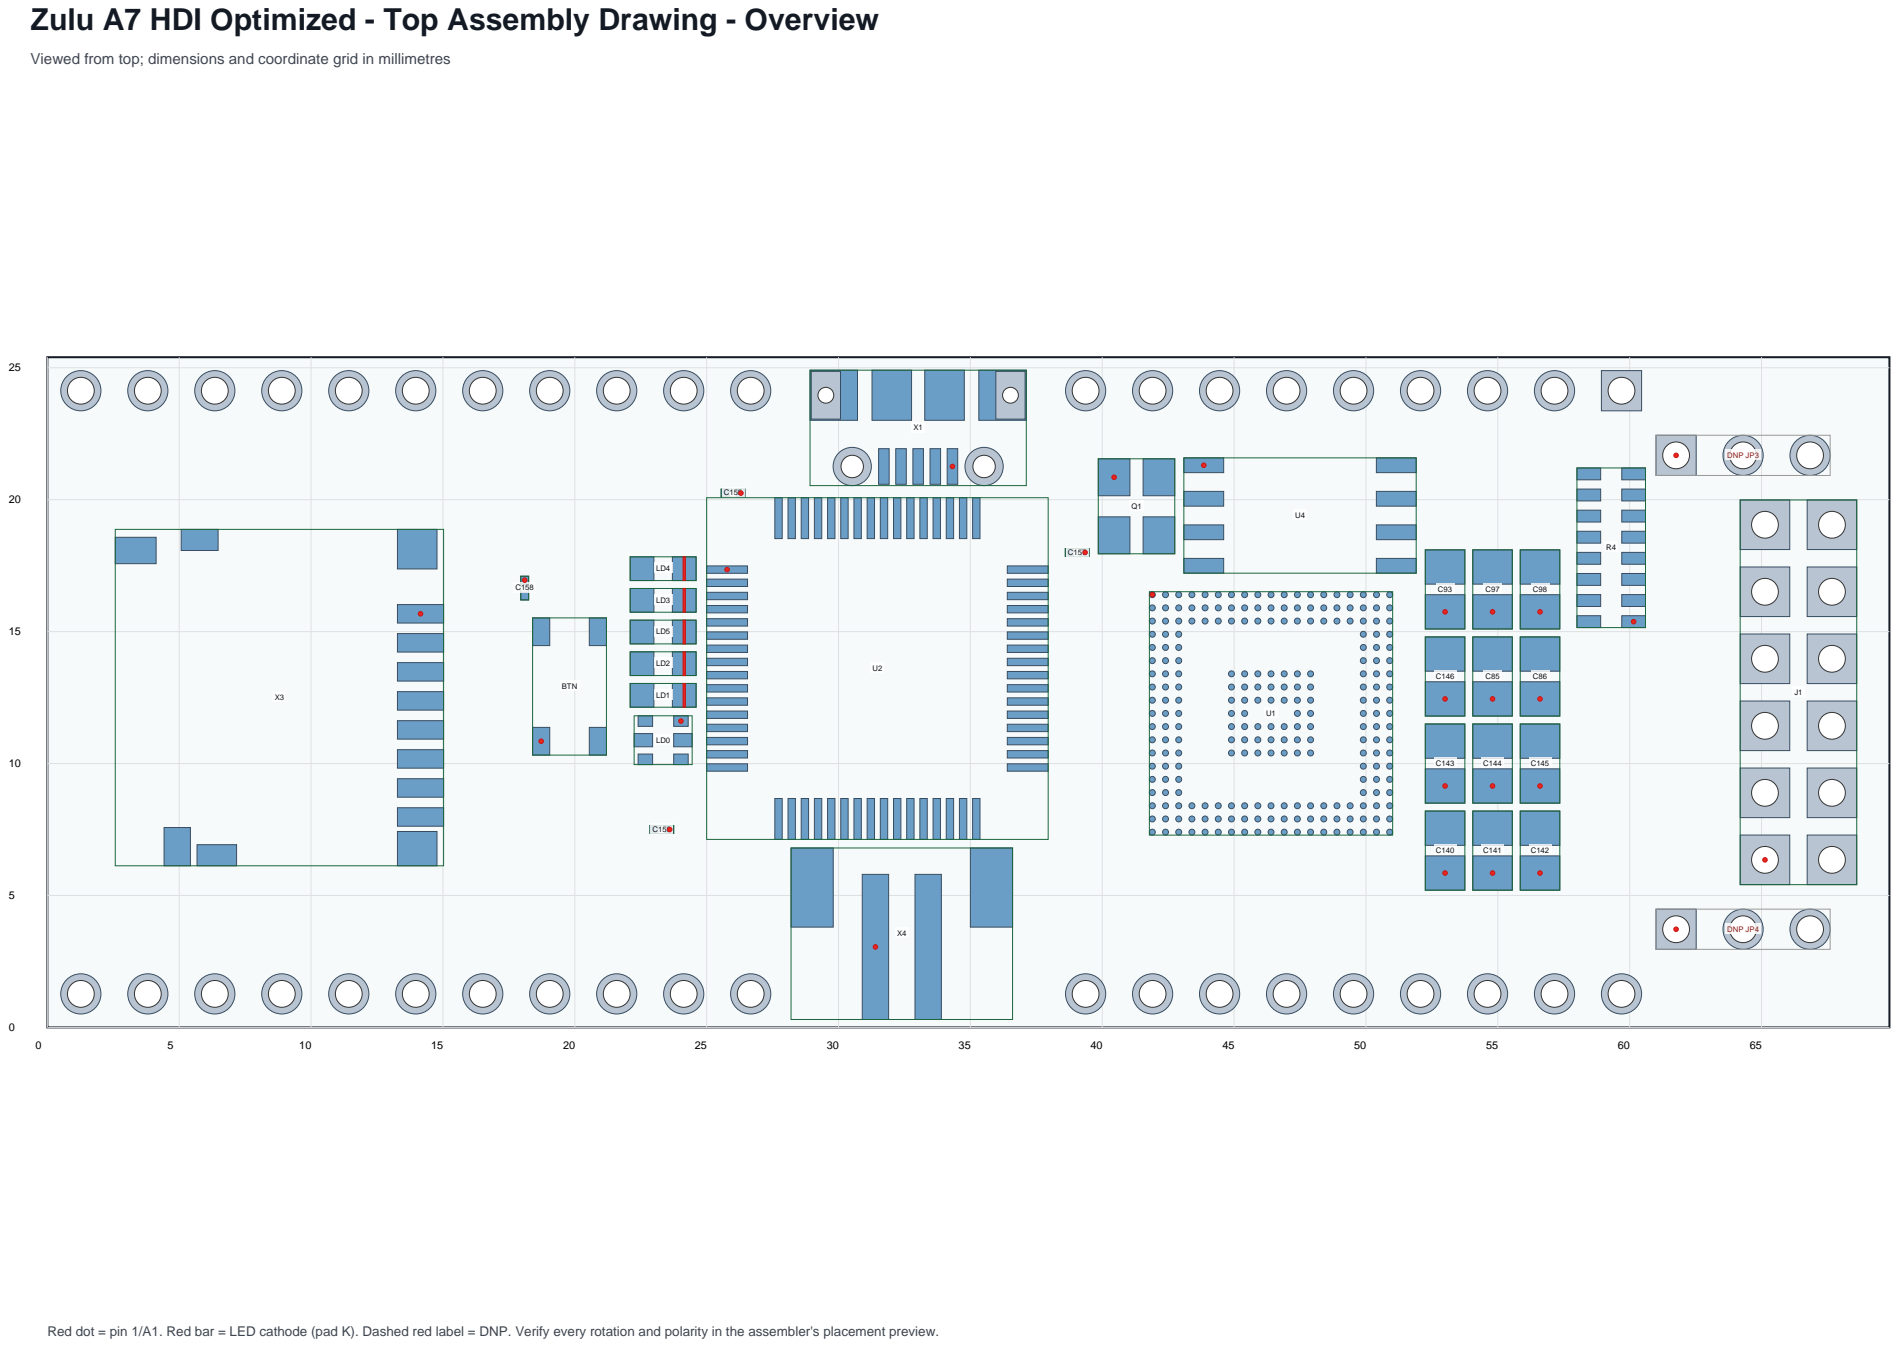
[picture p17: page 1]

Viewed from top; dimensions and coordinate grid in millimetres

Red dot = pin 1/A1. Red bar = LED cathode (pad K). Dashed red label = DNP. Verify every rotation and polarity in the assembler's placement preview.

# Zulu A7 HDI Optimized - Top Assembly Drawing - West Detail

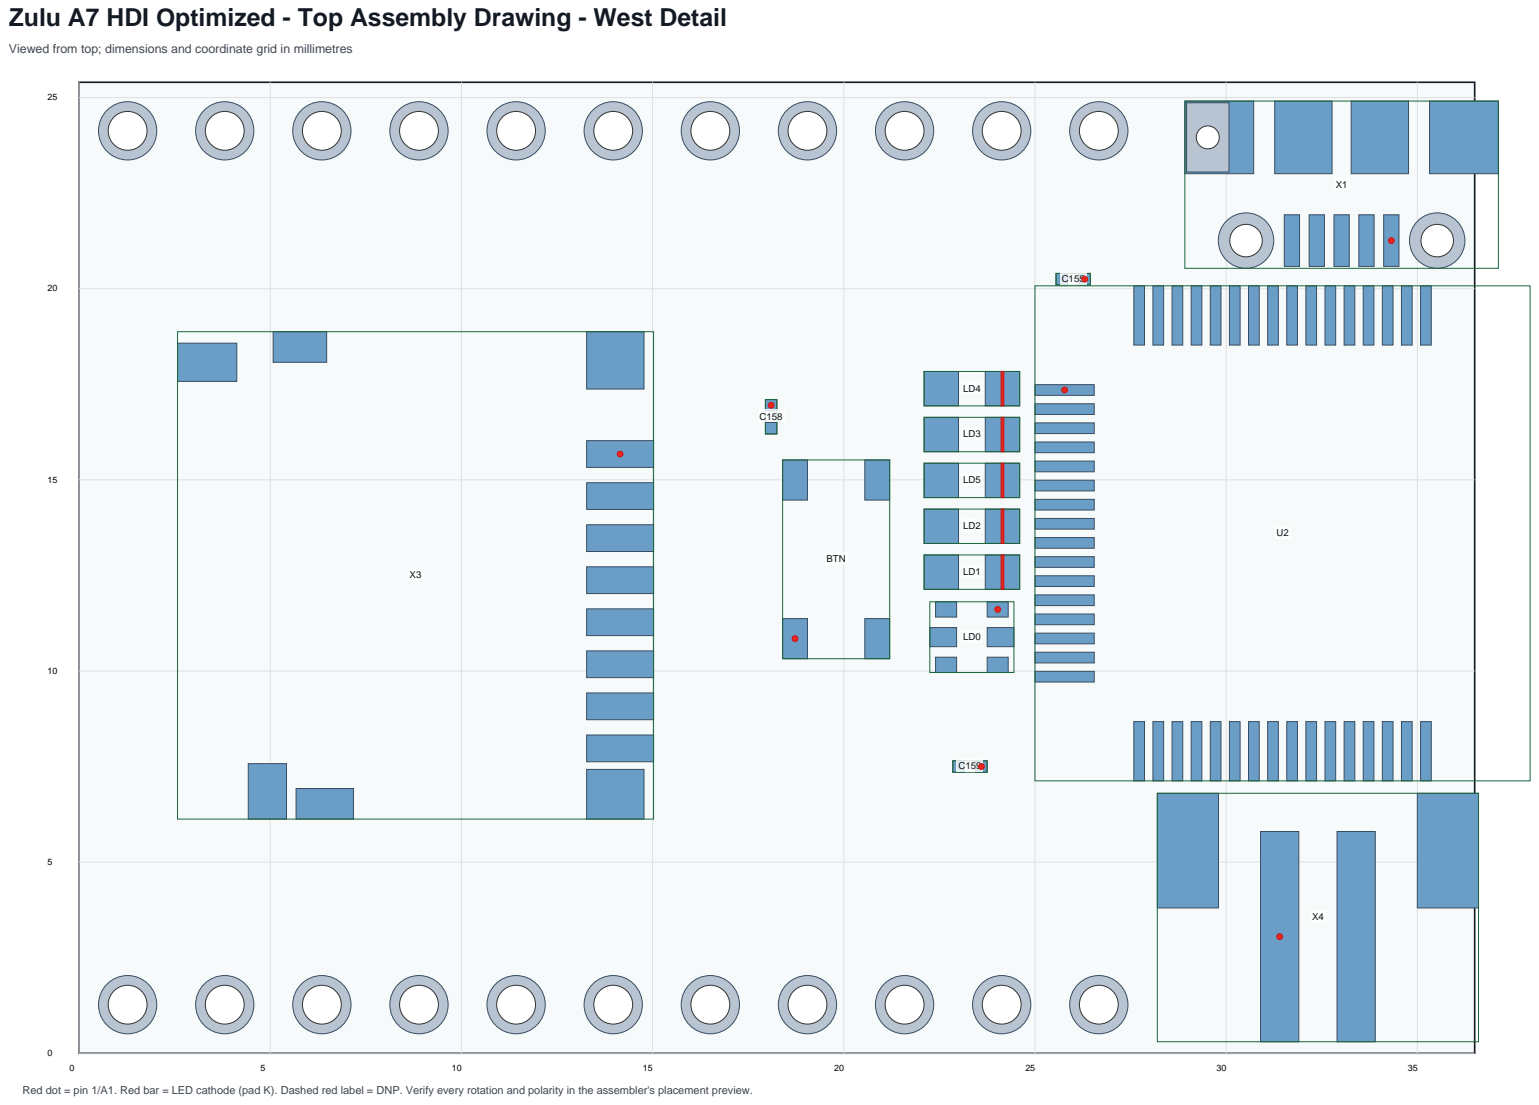
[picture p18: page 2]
BTN

# Zulu A7 HDI Optimized - Top Assembly Drawing - East Detail

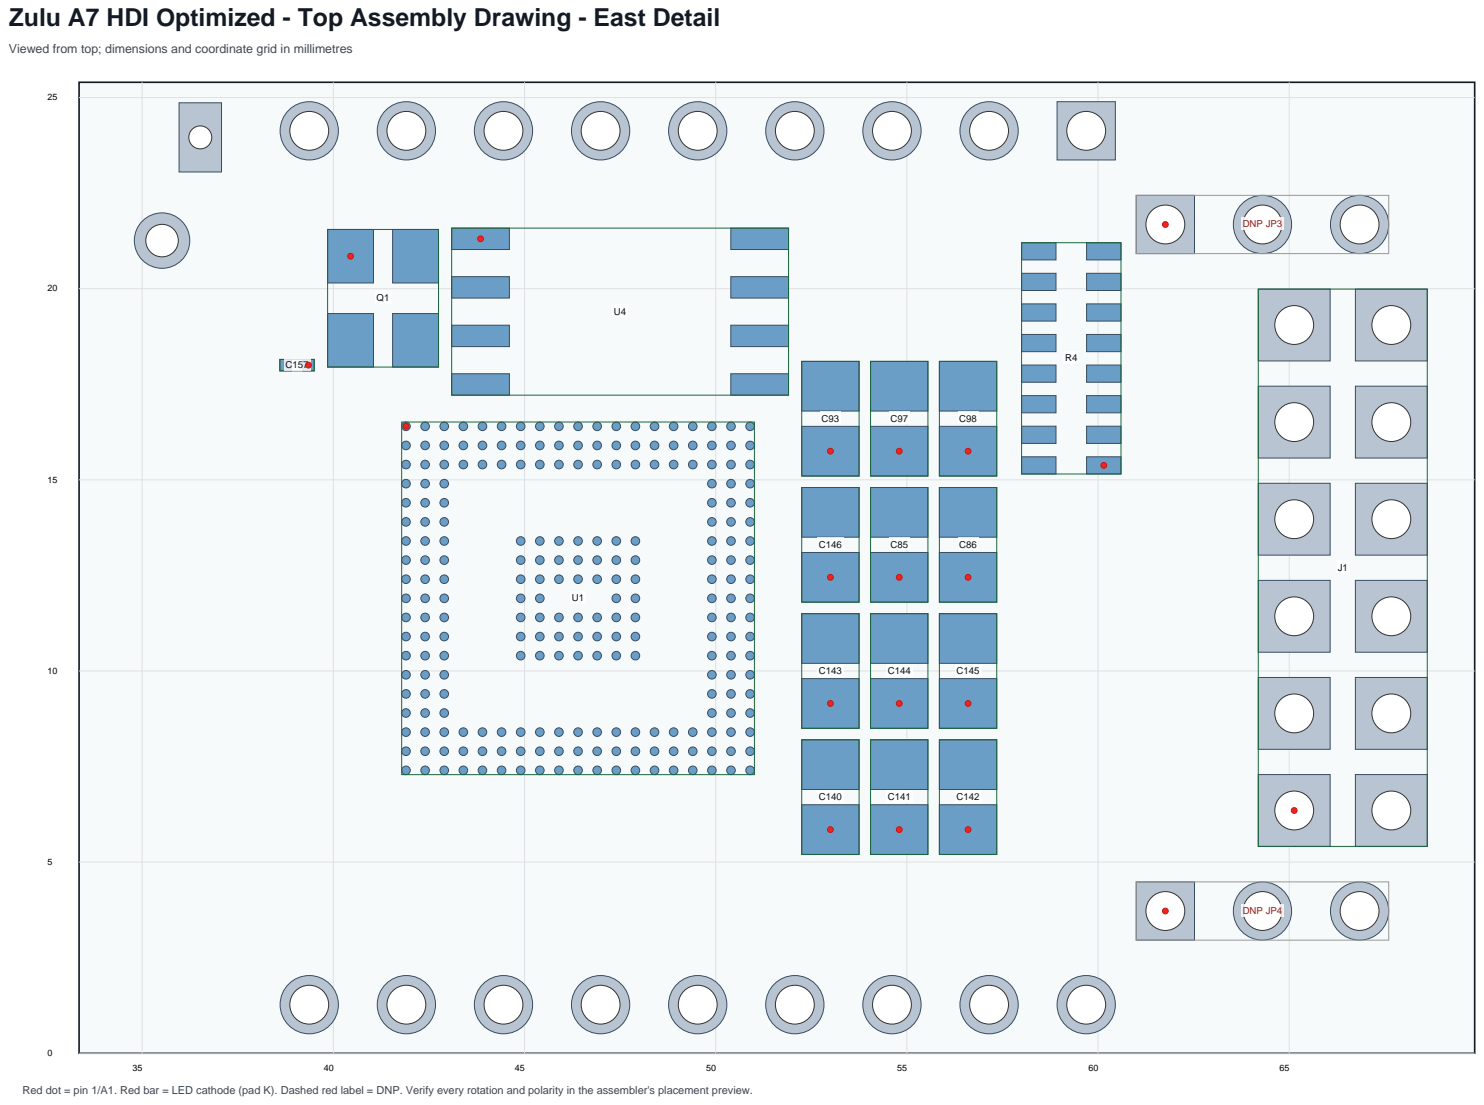
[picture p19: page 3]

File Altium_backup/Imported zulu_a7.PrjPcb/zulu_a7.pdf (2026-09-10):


SPI flash sits on the FPGA's dedicated
master-SPI config pins: CCLK C11, FCS_B K19,
DQ0-3 on D18/D19/G18/F18. Read at power-up.

microSD runs the native 4-bit SD bus, not SPI:
CLK and CMD in bank 34, DAT0/DAT1/DAT3 in 16
and DAT2 in 35 -- none of them on the config bus.

PROJECT: zulu_a7 | REV: | 9/2/2026 1:29:21 PM

AUTHOR | Sheet: 1 1


JST PH 2-pin, 1S LiPo

2026-09-09: D1 (USB VBUS Schottky) replaced by U8, a TI bq24232 LiPo charger with power path: USB5V0 into IN, OUT onto VU (4.4 V on USB, VBAT

- 60 mV on battery), battery on X4 (JST PH 2.0 mm, pin 1 = +). Input limit 495 mA (R103), charge 244 mA (R102), termination 36 mA (R105), 7.5

h timer (R104), TS disabled (R106): the pack needs its own protection. LD3 green = USB power good, LD4 red = charging. The +5V-INPUT pin with

D2 and D3 was removed on 2026-09-09: the LiPo on X4 is the external supply. Footprints VQFN16-3X3-RGT and JST-B2B-PH-SM4-TB to draw.

2026-09-06: LTC3569 section replaced by three fixed SC189 bucks (Cmod A7 style), EN tied to VU, no

dividers, no sequencer; L1-L3 1.5uH, 22uF out, 10uF in; LD5 now shows VCC3V3. See docs/power_budget.md

PROJECT: zulu_a7 | REV: | 9/2/2026 1:29:21 PM

AUTHOR | Sheet: 2 2


X2: 40 pins on a 2.54 mm grid, rows 22.86 mm (0.900 in) apart, numbered 1-40 straight
TOP ROW, x 59.69 down to 1.27: GND (pin 1), CHAN-CLK (2), CHAN0..CHAN6 (3-9),
then CHAN7..CHAN13 (10-16), +3.3V, +1.8V, +1.0V, GND (17-20).
BOTTOM ROW, x 59.69 down to 1.27: GND, VU, RST# (pins 21-23), CHAN14..CHAN16 (24-26),
CHAN17..CHAN19 (27-29), then CHAN20..CHAN28 (30-38), ANALOG-IO0, ANALOG-IO1 (39, 40).
FOUR positions in each row -- x 36.83, 34.29, 31.75, 29.21, between pins 9 and 10 above
and between pins 29 and 30 below -- are RESERVED, not spare: the edge-mounted
micro-USB X1 lands on the top row (7.80 mm of copper), the top-side LiPo header X4
(JST B2B-PH-SM4-TB, 7.95 mm body) lands on the bottom row directly opposite it.
Each landing is 12.70 mm between the neighbouring pin centres, 11.176 mm clear.

pins 5/11 are GND and 6/12 are VCC3V3 -- so a 2x6 header carries EIGHT signals, not twelve,
JA1-JA4 (the top row, the half a Pmod uses for SPI) are all in bank 16: A14 A15 B15 A16.

General IO 2026, Christian Tambe. Some rights reserved.

Licensed under a Creative Commons

Attribution-Share-Alike Unported License.

PROJECT: zulu_a7 zulu_a7 | REV: | 9/2/2026 1:29:21 PM

See creativecommons.org/licenses/by-sa/3.0/

AUTHOR | Sheet: 3


U3 = AS4C32M16SB-7TCN: 512Mbit (32M x 16) = 64MB.
Pin-for-pin and dimensionally identical to the 256Mb
AS4C16M16SA-6TIN it replaces -- all 54 pins and every
TSOP-II dimension checked against both datasheets, and
pin 40 is NC on both.
ONE DIFFERENCE, AND IT IS NOT A PIN: the column address
controller must be set to 10 column bits, or it reaches
refresh (8192 cycles / 64ms) are unchanged.
-7TCN since 2026-09-08 (-6TIN dry): 143 MHz max at CL3,
tRCD/tRP 21, tRC 63 ns, TA 0-70 C, IDD1 max 110 mA.

R2A/R2B keep WP#/HOLD# high through the x1 command phase and through the float window before the FPGA drives D02/D03
The microSD is deliberately NOT on this bus any more: an inserted card sits in native SD mode watching bitstream traffic go
past on what it believes is CMD, and one 48-bit window with a valid CRC7 is enough to make it answer and drive the line the
DAT0 where the socket stub is.

from prototyping-header CHAN1/CHAN0; DAT3 is the old SPI chip-select, which needs no new pin.
only) was removed: one damped line out of four is a skew, not termination.
2026-09-06: X3 is now the Hirose DM3D-SF push-pull socket (HRS 609-0025-8), DM3 catalog p9. Same 8-contact pinout;
shell pads G1-G4 to GND; card-detect switch A/B (closed with card) left open. Needs its own footprint on the PCB.

U3 DECOUPLING -- each cap bridges one supply pin to the ground pin OPPOSITE it.
In the 54-pin TSOP-II, pin n faces pin 55-n, and every supply pin faces a ground of its
own domain: VDD 1/14/27 to VSS 54/41/28, VDDQ 3/9/43/49 to VSSQ 52/46/12/6. Alliance
isolates VDDQ from VDD for DQ noise immunity -- LAYOUT MUST KEEP THE PAIRS: each cap on
the underside spanning its two pins, own vias, VDDQ returning to VSSQ and VDD to VSS.
C10 is bulk and pairs with nothing. Do NOT split the ground plane.


FT-VPLL FT-REF

VREGOUT 49 | PROG#

USB_D_N USB_D_P | DM 7 | DONE UART_FT_TXD

VCC 8 NC 7 CLK NC 6 DI VSS 5 | 2 EE-CLK | EECLK 62 EECS 63
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

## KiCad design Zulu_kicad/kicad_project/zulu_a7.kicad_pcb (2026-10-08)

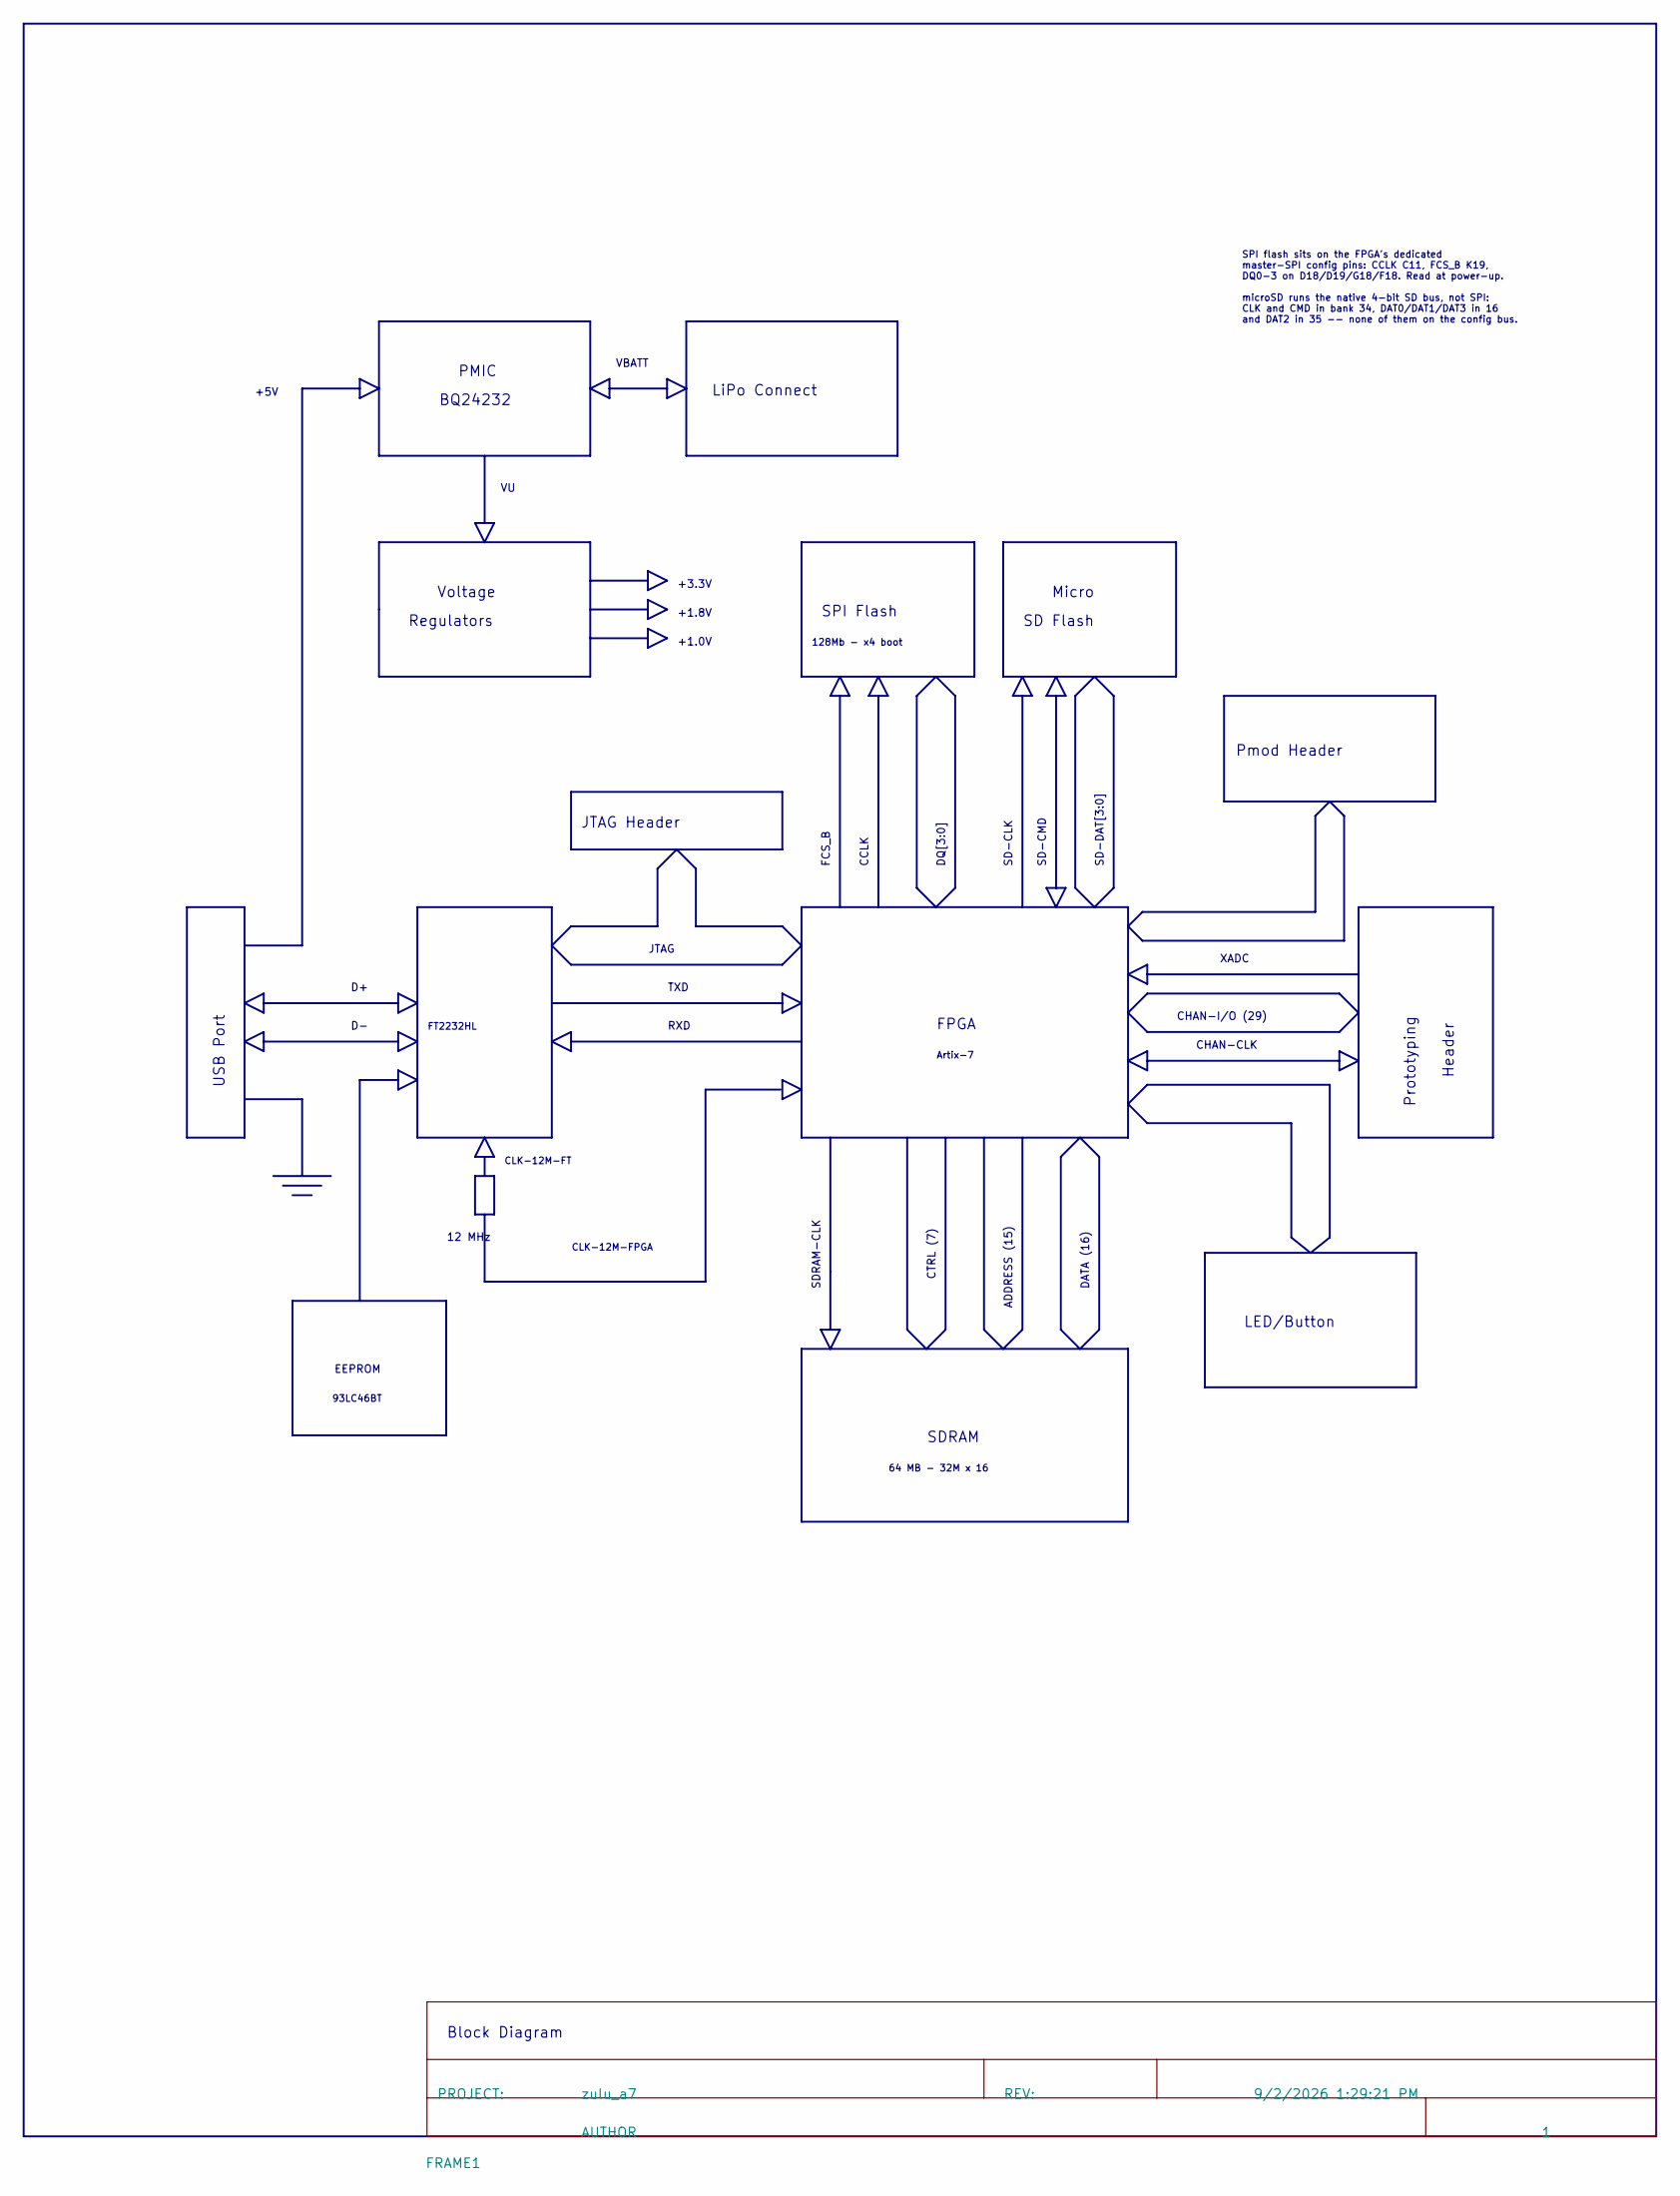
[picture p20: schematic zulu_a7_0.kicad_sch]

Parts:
FRAME1: DOCFIELD

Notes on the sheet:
Header
FPGA
SDRAM-CLK
FT2232HL
PMIC
SD-CMD
Prototyping
SD Flash
SD-DAT[3:0]
CLK-12M-FPGA
Voltage
SDRAM
FCS_B
Micro
JTAG
CTRL (7)
Block Diagram
93LC46BT
JTAG Header
CHAN-I/O (29)
+3.3V
CLK-12M-FT
LED/Button
DATA (16)
CHAN-CLK
Artix-7
XADC
ADDRESS (15)
128Mb - x4 boot
+5V
Pmod Header
DQ[3:0]
LiPo Connect
SD-CLK
RXD
TXD
+1.8V
12 MHz
+1.0V
CCLK

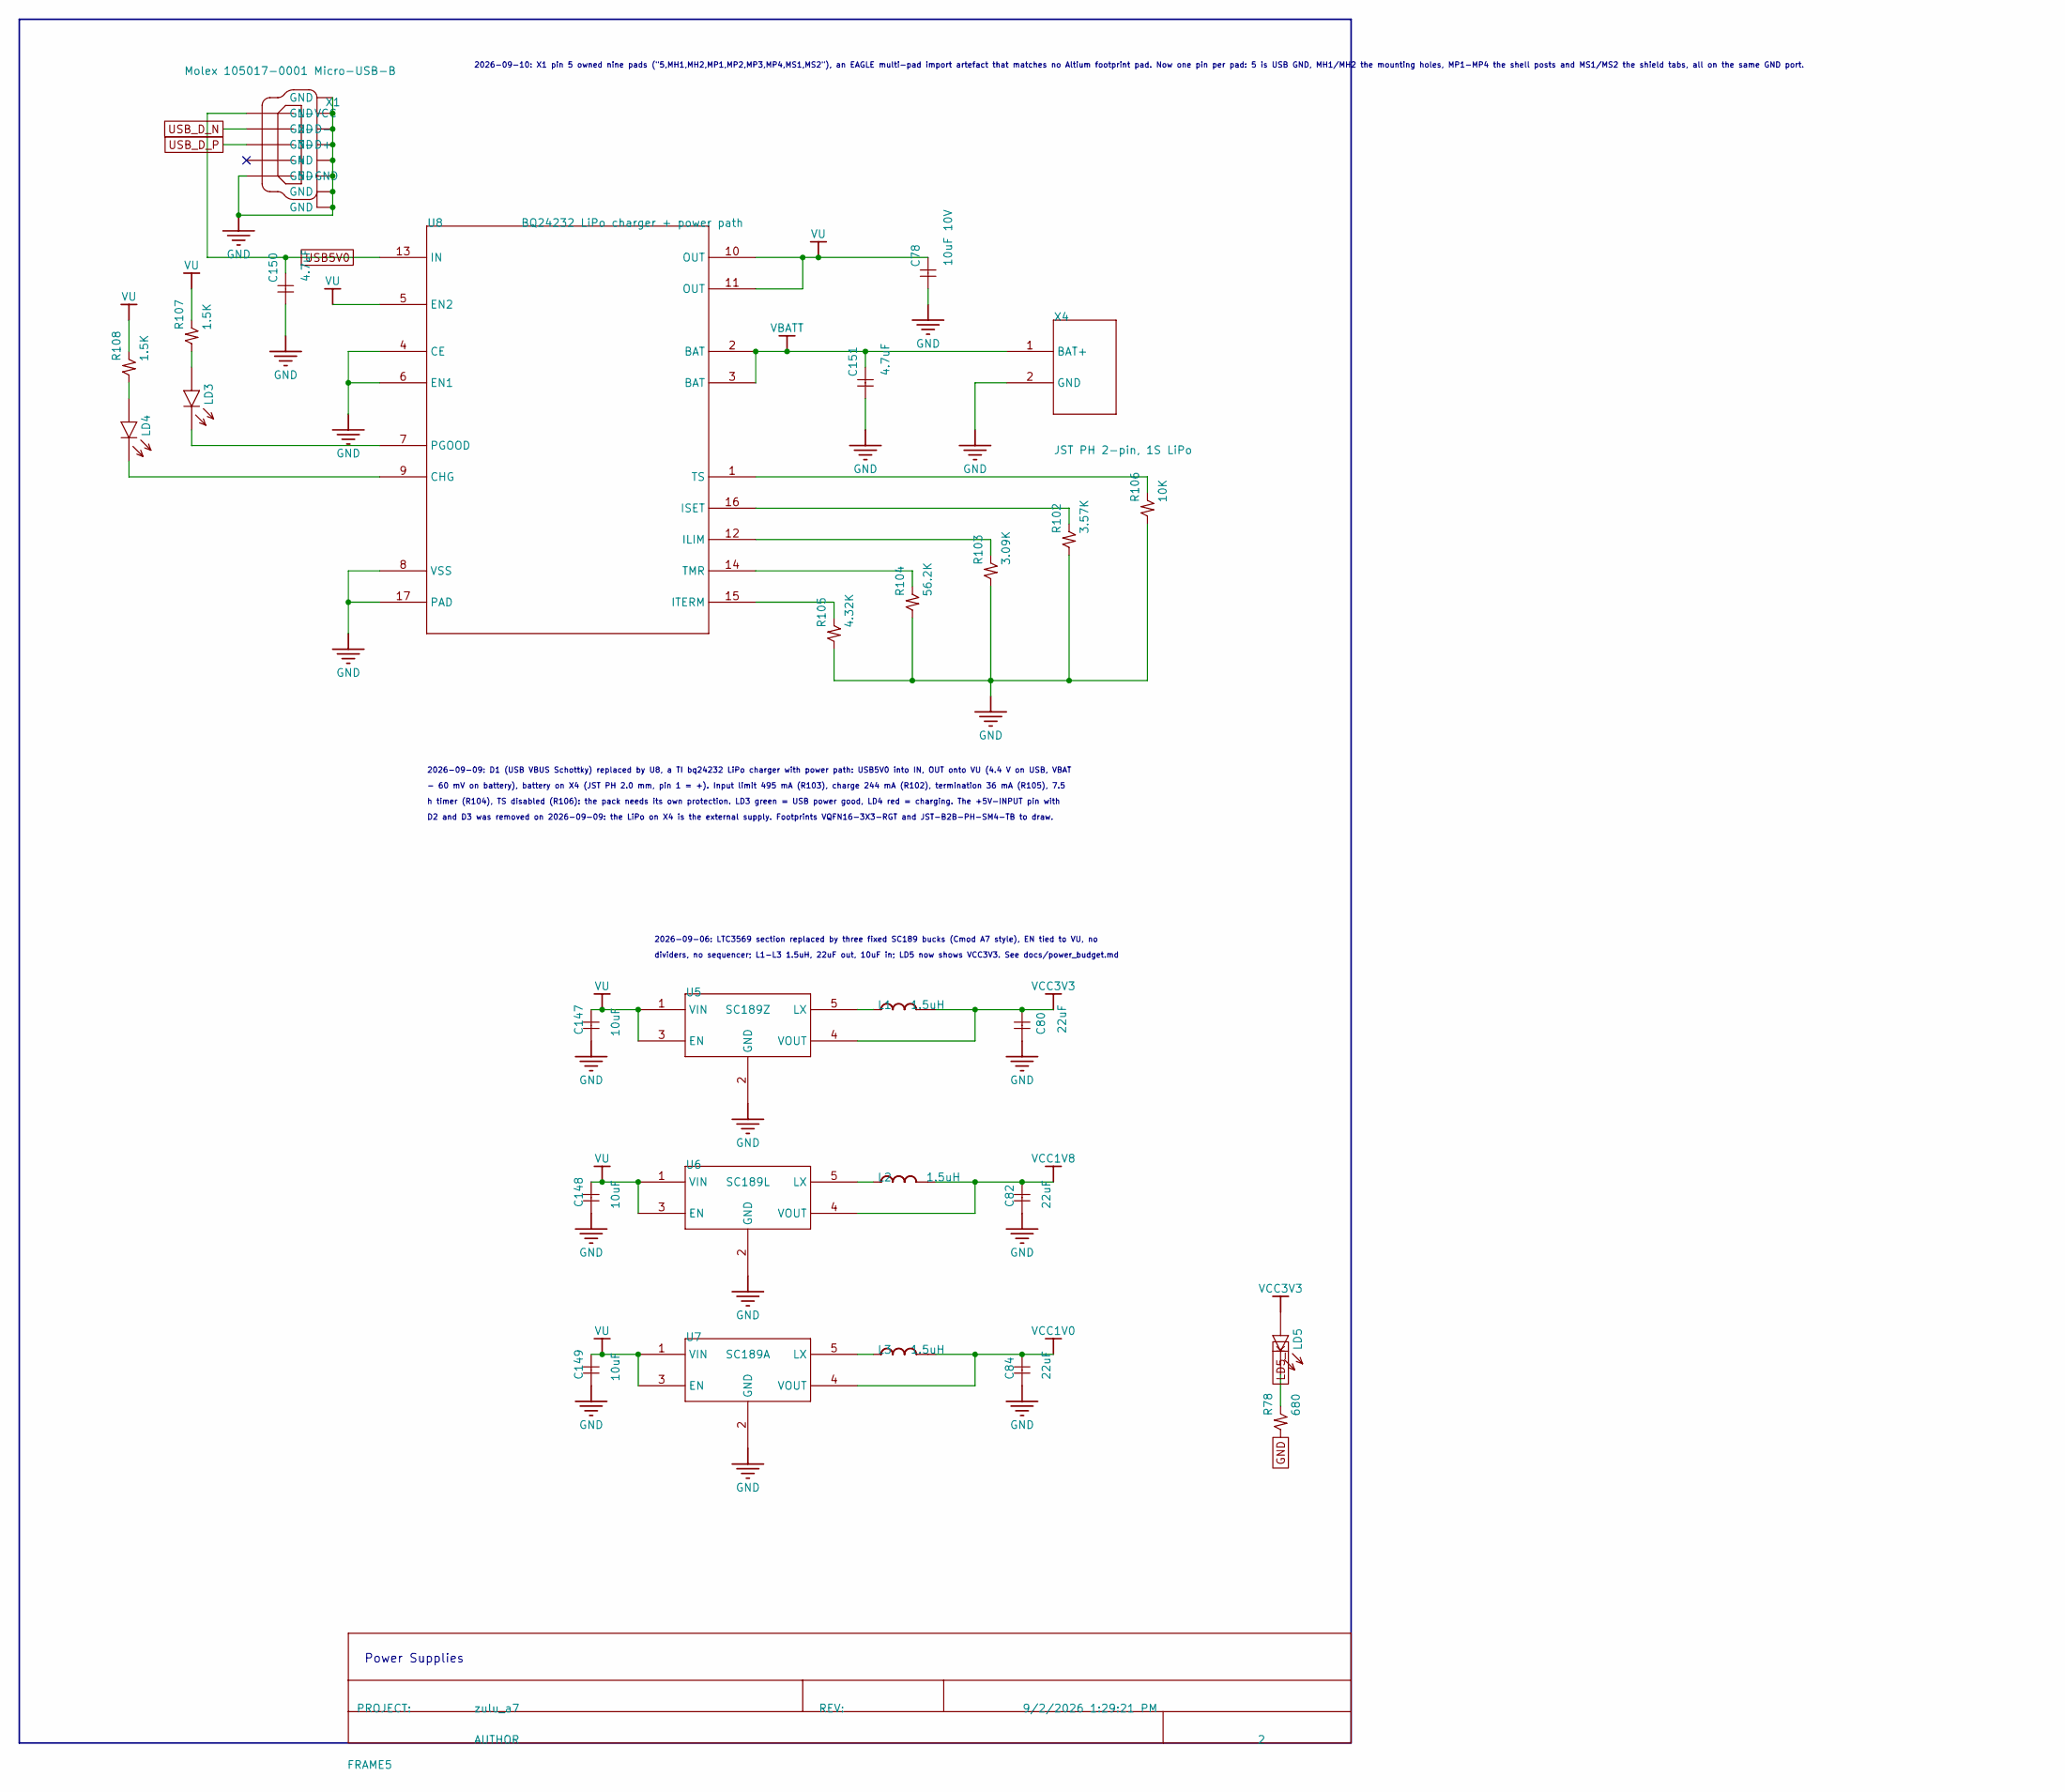
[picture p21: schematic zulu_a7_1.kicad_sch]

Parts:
C78: 10uF 10V; C0805
C80: 22uF; C0805
C82, C84: 22uF; C0603
C147, C148, C149: 10uF; C0805
C150, C151: 4.7uF; C0603
FRAME5: DOCFIELD
L1, L2, L3: 1.5uH; IND2520
LD3, LD5: green; LED0603
LD4: red; LED0603
R78: 680; R0402
R102: 3.57K; R0402
R103: 3.09K; R0402
R104: 56.2K; R0402
R105: 4.32K; R0402
R106: 10K; R0402
R107, R108: 1.5K; R0402
U5: SC189ZSKTRT; SOT23-5; PARTNAME SC189Z
U6: SC189LSKTRT; SOT23-5; PARTNAME SC189L
U7: SC189ASKTRT; SOT23-5; PARTNAME SC189A
U8: BQ24232 LiPo charger + power path; VQFN16-3X3-RGT
X1: Molex 105017-0001 Micro-USB-B; MOLEX-105017-0001
X4: JST PH 2-pin, 1S LiPo; JST-B2B-PH-SM4-TB

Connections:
GND: C78.1, C80.1, C82.1, C84.1, C147.1, C148.1, C149.1, C150.1, C151.1, R78.1, R102.1, R103.1, R104.1, R105.1, R106.1, U5.2 (GND), U6.2 (GND), U7.2 (GND), U8.4 (CE), U8.6 (EN1), U8.8 (VSS), U8.17 (PAD), X1.5 (5-GND), X1.MH1 (GND), X1.MH2 (GND), X1.MP1 (GND), X1.MP2 (GND), X1.MP3 (GND), X1.MP4 (GND), X1.MS1 (GND), X1.MS2 (GND), X4.2 (GND); also elsewhere on the board
LD5_K: LD5.K, R78.2
unnamed: LD3.A, R107.1
unnamed: LD4.A, R108.1
unnamed: L1.1, U5.5 (LX)
unnamed: L2.1, U6.5 (LX)
unnamed: L3.1, U7.5 (LX)
unnamed: LD4.K, U8.9 (CHG)
unnamed: R103.2, U8.12 (ILIM)
unnamed: R102.2, U8.16 (ISET)
unnamed: R105.2, U8.15 (ITERM)
unnamed: LD3.K, U8.7 (PGOOD)
unnamed: R104.2, U8.14 (TMR)
unnamed: R106.2, U8.1 (TS)
USB5V0: C150.2, U8.13 (IN), X1.1 (1-VCC)
USB_D_N: X1.2 (2-D-); also elsewhere on the board
USB_D_P: X1.3 (3-D+); also elsewhere on the board
VBATT: C151.2, U8.2 (BAT), U8.3 (BAT), X4.1 (BAT+)
VCC1V0: C84.2, L3.2, U7.4 (VOUT); also elsewhere on the board
VCC1V8: C82.2, L2.2, U6.4 (VOUT); also elsewhere on the board
VCC3V3: C80.2, L1.2, LD5.A, U5.4 (VOUT); also elsewhere on the board
VU: C78.2, C147.2, C148.2, C149.2, R107.2, R108.2, U5.1 (VIN), U5.3 (EN), U6.1 (VIN), U6.3 (EN), U7.1 (VIN), U7.3 (EN), U8.5 (EN2), U8.10 (OUT), U8.11 (OUT); also elsewhere on the board

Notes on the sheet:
2026-09-06: LTC3569 section replaced by three fixed SC189 bucks (Cmod A7 style), EN tied to VU, no
Power Supplies
2026-09-09: D1 (USB VBUS Schottky) replaced by U8, a TI bq24232 LiPo charger with power path: USB5V0 into IN, OUT onto VU (4.4 V on USB, VBAT
- 60 mV on battery), battery on X4 (JST PH 2.0 mm, pin 1 = +). Input limit 495 mA (R103), charge 244 mA (R102), termination 36 mA (R105), 7.5
2026-09-10: X1 pin 5 owned nine pads ("5,MH1,MH2,MP1,MP2,MP3,MP4,MS1,MS2"), an EAGLE multi-pad import artefact that matches no Altium footprint pad. Now one pin per pad: 5 is USB GND, MH1/MH2 the mounting holes, MP1-MP4 the shell posts and MS1/MS2 the shield tabs, all on the same GND port.
dividers, no sequencer; L1-L3 1.5uH, 22uF out, 10uF in; LD5 now shows VCC3V3. See docs/power_budget.md
D2 and D3 was removed on 2026-09-09: the LiPo on X4 is the external supply. Footprints VQFN16-3X3-RGT and JST-B2B-PH-SM4-TB to draw.
h timer (R104), TS disabled (R106): the pack needs its own protection. LD3 green = USB power good, LD4 red = charging. The +5V-INPUT pin with

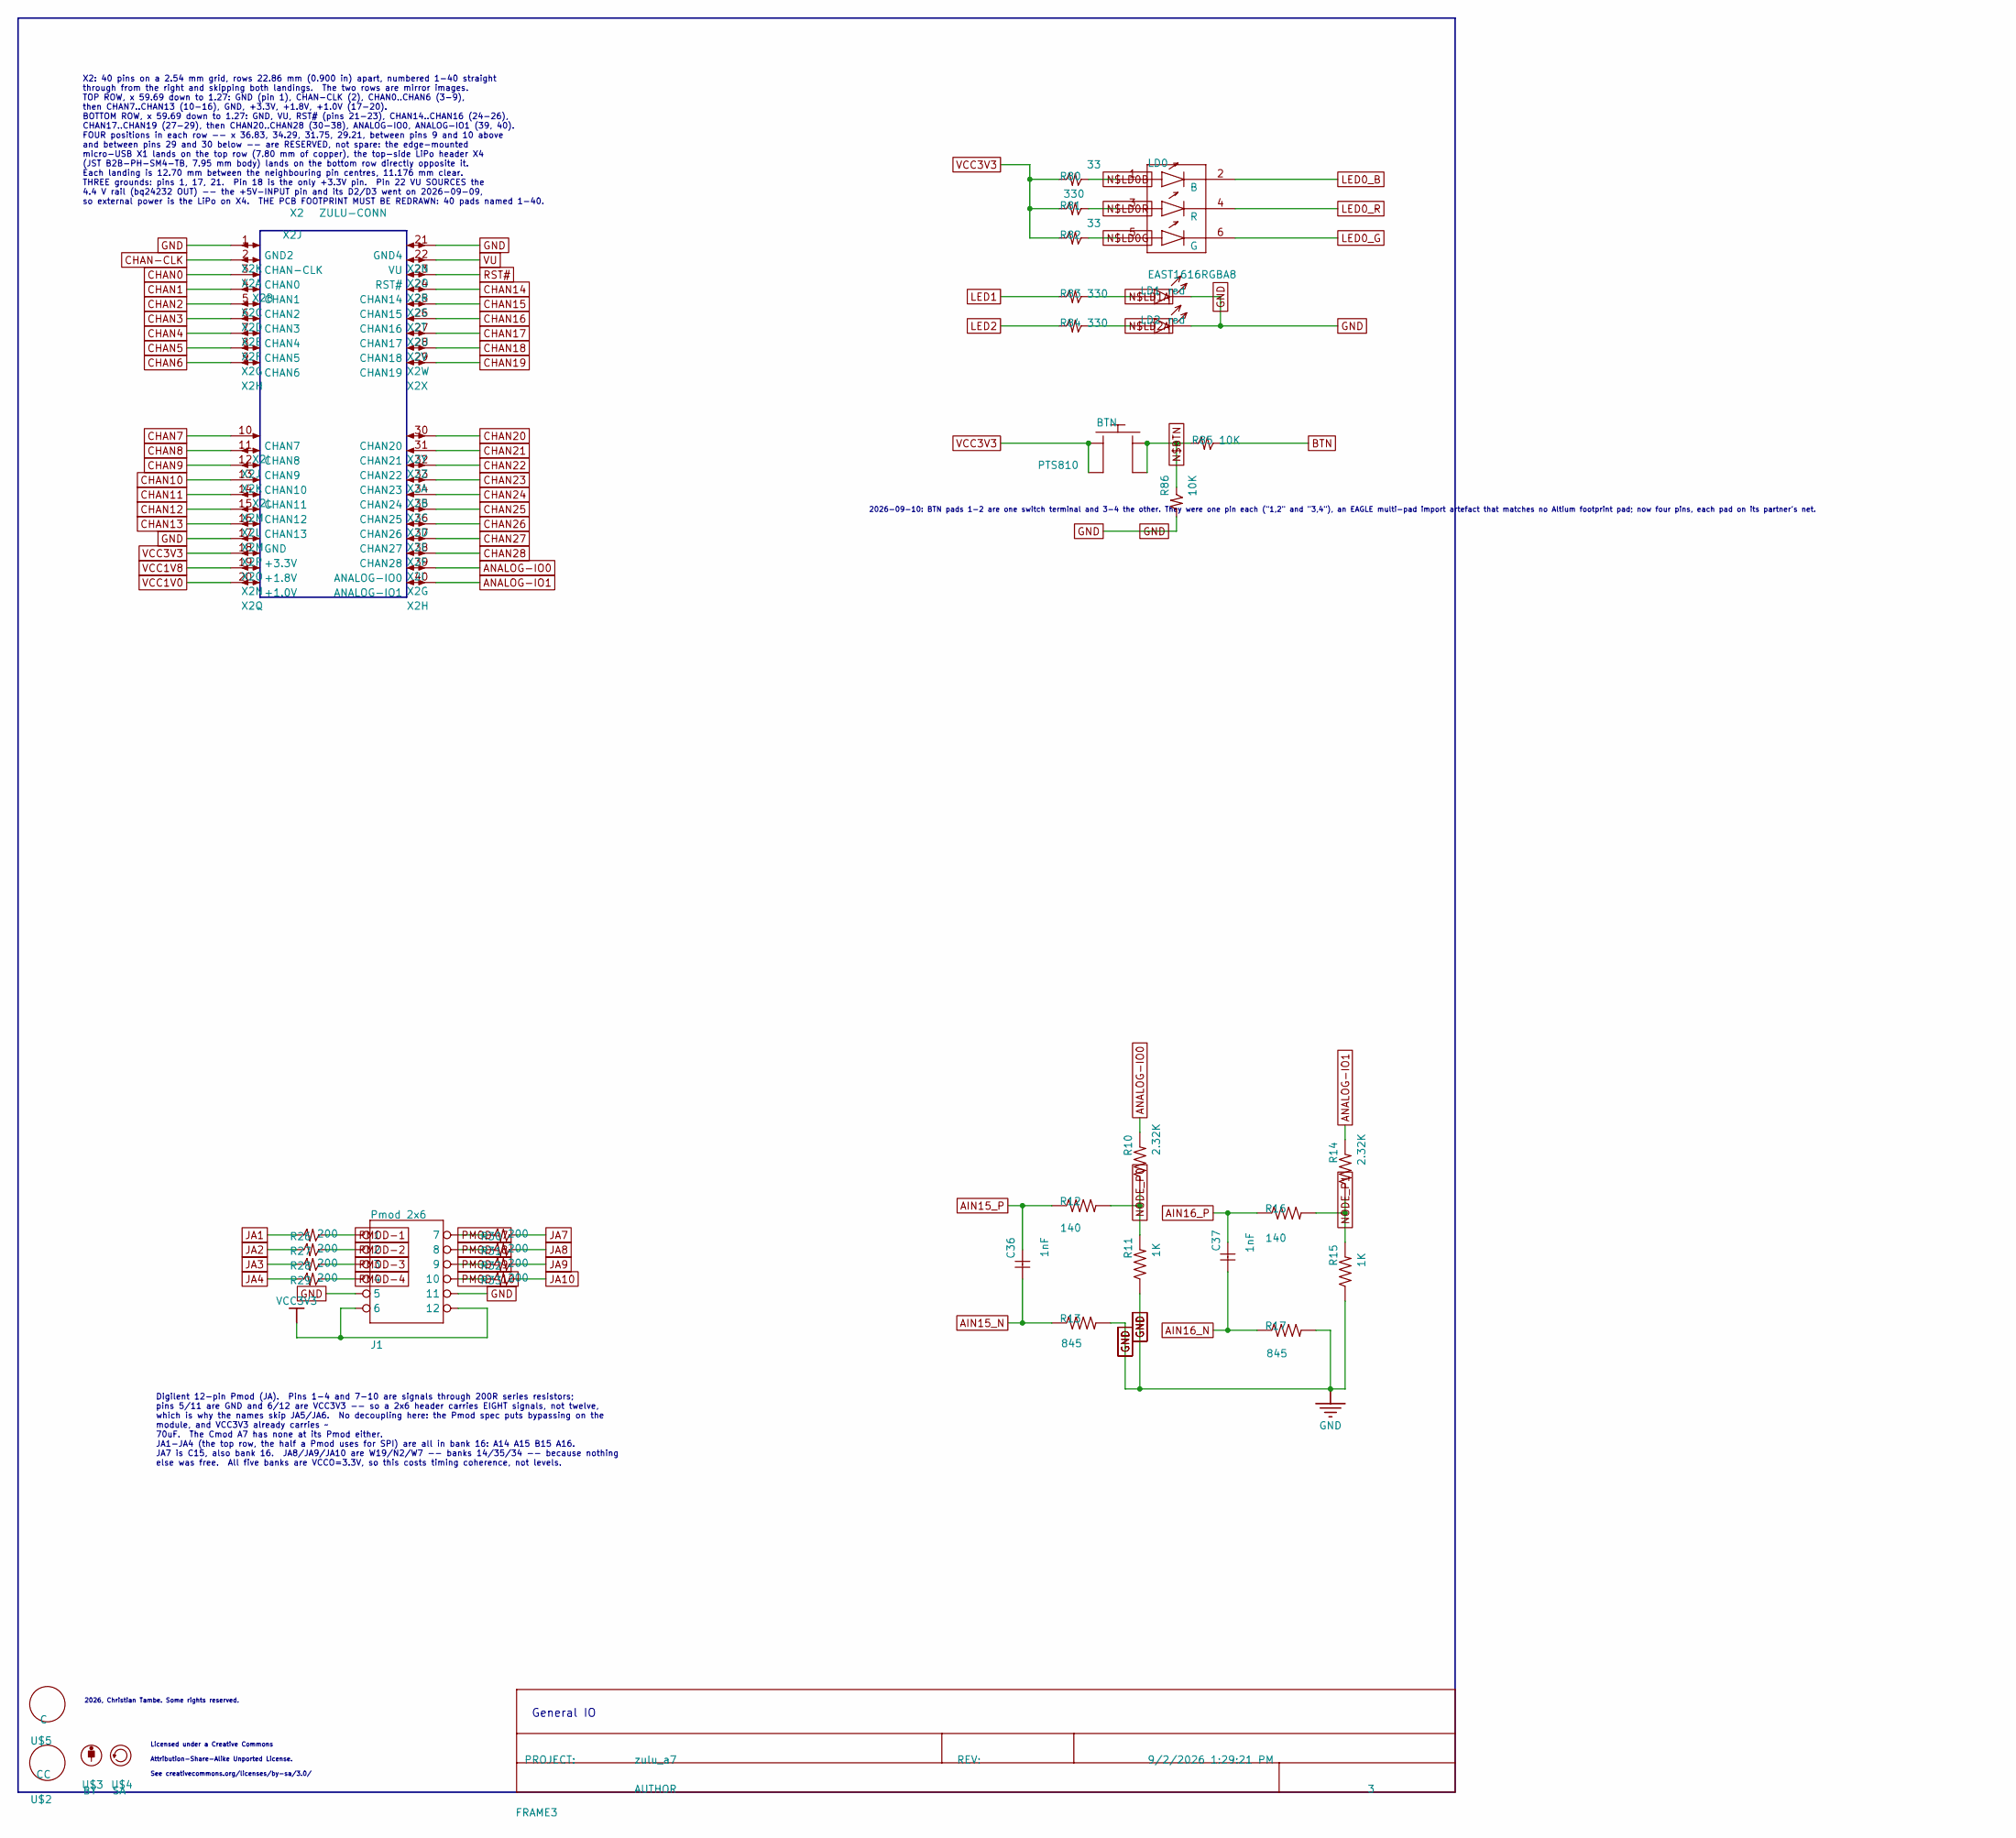
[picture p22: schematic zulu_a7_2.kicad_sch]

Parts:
BTN: PTS810
C36, C37: 1nF; C0402
FRAME3: DOCFIELD
J1: Pmod 2x6; 2X06
LD0: EAST1616RGBA8; EVERLIGHT-19-337
LD1, LD2: red; LED0603
R10, R14: 2.32K; R0201
R11, R15: 1K; R0201
R12, R16: 140; R0201
R13, R17: 845; R0201
R26, R27, R28, R29, R30, R31, R32, R33: 200; R0201
R80, R82: 33; R0402
R81, R83, R84: 330; R0402
R85, R86: 10K; R0402
U$2: CC_CC
U$3: CC_BY
U$4: CC_SA
U$5: CC_COPYRIGHT
X2: ZULU-CONN; ZULU-DIP37

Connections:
AIN15_N: C36.1, R13.1; also elsewhere on the board
AIN15_P: C36.2, R12.1; also elsewhere on the board
AIN16_N: C37.1, R17.1; also elsewhere on the board
AIN16_P: C37.2, R16.1; also elsewhere on the board
ANALOG-IO0: R10.2, X2.39
ANALOG-IO1: R14.2, X2.40
BTN: R85.2; also elsewhere on the board
CHAN0: X2.3; also elsewhere on the board
CHAN1: X2.4; also elsewhere on the board
CHAN2: X2.5; also elsewhere on the board
CHAN3: X2.6; also elsewhere on the board
CHAN4: X2.7; also elsewhere on the board
CHAN5: X2.8; also elsewhere on the board
CHAN6: X2.9; also elsewhere on the board
CHAN7: X2.10; also elsewhere on the board
CHAN8: X2.11; also elsewhere on the board
CHAN9: X2.12; also elsewhere on the board
CHAN10: X2.13; also elsewhere on the board
CHAN11: X2.14; also elsewhere on the board
CHAN12: X2.15; also elsewhere on the board
CHAN13: X2.16; also elsewhere on the board
CHAN14: X2.24; also elsewhere on the board
CHAN15: X2.25; also elsewhere on the board
CHAN16: X2.26; also elsewhere on the board
CHAN17: X2.27; also elsewhere on the board
CHAN18: X2.28; also elsewhere on the board
CHAN19: X2.29; also elsewhere on the board
CHAN20: X2.30; also elsewhere on the board
CHAN21: X2.31; also elsewhere on the board
CHAN22: X2.32; also elsewhere on the board
CHAN23: X2.33; also elsewhere on the board
CHAN24: X2.34; also elsewhere on the board
CHAN25: X2.35; also elsewhere on the board
CHAN26: X2.36; also elsewhere on the board
CHAN27: X2.37; also elsewhere on the board
CHAN28: X2.38; also elsewhere on the board
CHAN-CLK: X2.2; also elsewhere on the board
GND: J1.5, J1.11, LD1.K, LD2.K, R11.1, R13.2, R15.1, R17.2, R86.1, X2.1, X2.17, X2.21; also elsewhere on the board
JA1: R26.1; also elsewhere on the board
JA2: R27.1; also elsewhere on the board
JA3: R28.1; also elsewhere on the board
JA4: R29.1; also elsewhere on the board
JA7: R30.2; also elsewhere on the board
JA8: R31.2; also elsewhere on the board
JA9: R32.2; also elsewhere on the board
JA10: R33.2; also elsewhere on the board
LED0_B: LD0.2; also elsewhere on the board
LED0_G: LD0.6; also elsewhere on the board
LED0_R: LD0.4; also elsewhere on the board
LED1: R83.1; also elsewhere on the board
LED2: R84.1; also elsewhere on the board
N$BTN: BTN.3 (2), BTN.4 (2), R85.1, R86.2
N$LD0B: LD0.1, R80.2
N$LD0G: LD0.5, R82.2
N$LD0R: LD0.3, R81.2
N$LD1A: LD1.A, R83.2
N$LD2A: LD2.A, R84.2
NODE_P0: R10.1, R11.2, R12.2
NODE_P1: R14.1, R15.2, R16.2
PMOD-1: J1.1, R26.2
PMOD-2: J1.2, R27.2
PMOD-3: J1.3, R28.2
PMOD-4: J1.4, R29.2
PMOD-7: J1.7, R30.1
PMOD-8: J1.8, R31.1
PMOD-9: J1.9, R32.1
PMOD-10: J1.10, R33.1
RST#: X2.23; also elsewhere on the board
VCC1V0: X2.20; also elsewhere on the board
VCC1V8: X2.19; also elsewhere on the board
VCC3V3: BTN.1, BTN.2 (1), J1.6, J1.12, R80.1, R81.1, R82.1, X2.18; also elsewhere on the board
VU: X2.22; also elsewhere on the board

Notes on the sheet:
Licensed under a Creative Commons
See creativecommons.org/licenses/by-sa/3.0/
General IO
2026-09-10: BTN pads 1-2 are one switch terminal and 3-4 the other. They were one pin each ("1,2" and "3,4"), an EAGLE multi-pad import artefact that matches no Altium footprint pad; now four pins, each pad on its partner's net.
Attribution-Share-Alike Unported License.
2026, Christian Tambe. Some rights reserved.
Digilent 12-pin Pmod (JA). Pins 1-4 and 7-10 are signals through 200R series resistors; pins 5/11 are GND and 6/12 are VCC3V3 -- so a 2x6 header carries EIGHT signals, not twelve, which is why the names skip JA5/JA6. No decoupling here: the Pmod spec puts bypassing on the module, and VCC3V3 already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
X2: 40 pins on a 2.54 mm grid, rows 22.86 mm (0.900 in) apart, numbered 1-40 straight through from the right and skipping both landings. The two rows are mirror images. TOP ROW, x 59.69 down to 1.27: GND (pin 1), CHAN-CLK (2), CHAN0..CHAN6 (3-9), then CHAN7..CHAN13 (10-16), GND, +3.3V, +1.8V, +1.0V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

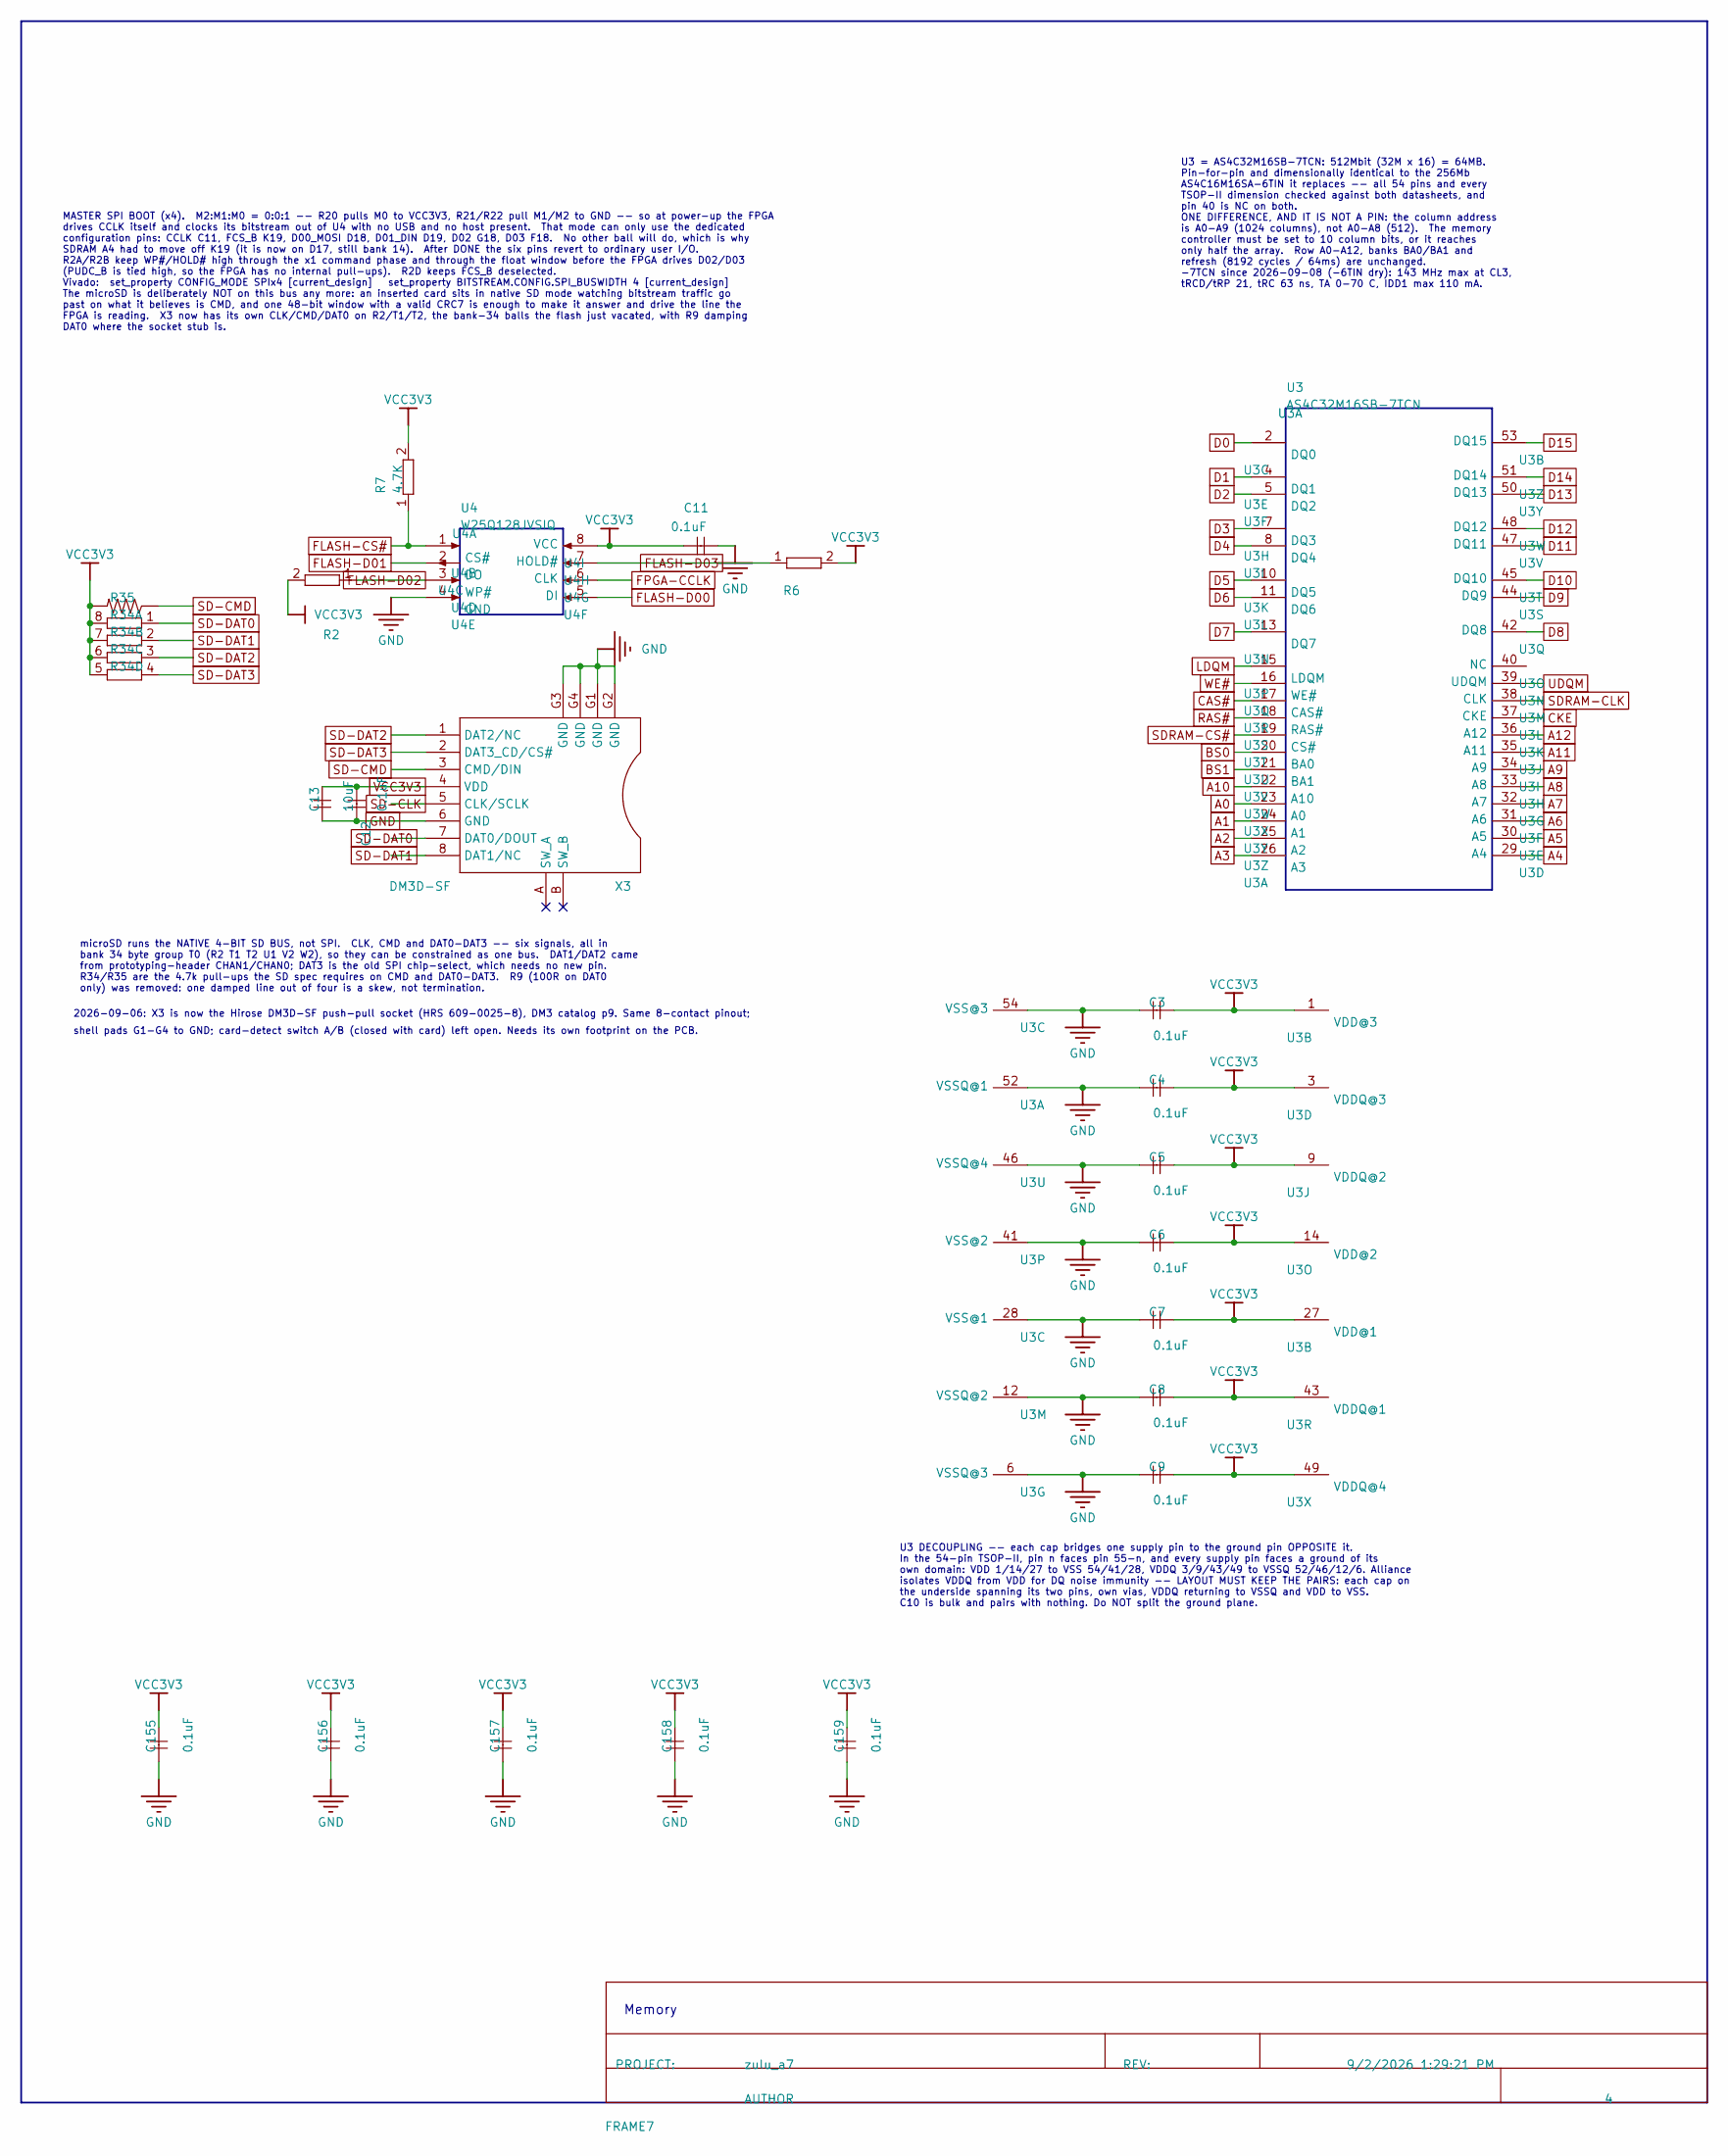
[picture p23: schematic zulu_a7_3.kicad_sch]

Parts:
C3, C4, C5, C6, C7, C8, C9, C11, C12: 0.1uF; C0402
C13: 10uF; C0603
C155, C156, C157, C158, C159: 0.1uF; C0201
FRAME7: DOCFIELD
R2, R6, R7: 4.7K; R0201
R34: 4.7K; 742C083; MOUSER# 774-742C083???JP; DIGIKEY# 742C083???JPCT-ND
R35: 4.7K; R0402
U3: AS4C32M16SB-7TCN; TSOPII-54
U4: W25Q128JVSIQ; SOIC-8_208MIL; PART U4; DIGIKEY# W25Q128JVSIQ-ND
X3: DM3D-SF; MOUSER# MOUSER#

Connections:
A0: U3.23; also elsewhere on the board
A1: U3.24; also elsewhere on the board
A2: U3.25; also elsewhere on the board
A3: U3.26; also elsewhere on the board
A4: U3.29; also elsewhere on the board
A5: U3.30; also elsewhere on the board
A6: U3.31; also elsewhere on the board
A7: U3.32; also elsewhere on the board
A8: U3.33; also elsewhere on the board
A9: U3.34; also elsewhere on the board
A10: U3.22; also elsewhere on the board
A11: U3.35; also elsewhere on the board
A12: U3.36; also elsewhere on the board
BS0: U3.20; also elsewhere on the board
BS1: U3.21; also elsewhere on the board
CAS#: U3.17; also elsewhere on the board
CKE: U3.37; also elsewhere on the board
D0: U3.2; also elsewhere on the board
D1: U3.4; also elsewhere on the board
D2: U3.5; also elsewhere on the board
D3: U3.7; also elsewhere on the board
D4: U3.8; also elsewhere on the board
D5: U3.10; also elsewhere on the board
D6: U3.11; also elsewhere on the board
D7: U3.13; also elsewhere on the board
D8: U3.42; also elsewhere on the board
D9: U3.44; also elsewhere on the board
D10: U3.45; also elsewhere on the board
D11: U3.47; also elsewhere on the board
D12: U3.48; also elsewhere on the board
D13: U3.50; also elsewhere on the board
D14: U3.51; also elsewhere on the board
D15: U3.53; also elsewhere on the board
FLASH-CS#: R7.1, U4.1; also elsewhere on the board
FLASH-D00: U4.5; also elsewhere on the board
FLASH-D01: U4.2; also elsewhere on the board
FLASH-D02: R2.1, U4.3; also elsewhere on the board
FLASH-D03: R6.1, U4.7; also elsewhere on the board
FPGA-CCLK: U4.6; also elsewhere on the board
GND: C3.1, C4.1, C5.1, C6.1, C7.1, C8.1, C9.1, C11.1, C12.1, C13.1, C155.1, C156.1, C157.1, C158.1, C159.1, U3.6, U3.12, U3.28, U3.41, U3.46, U3.52, U3.54, U4.4, X3.6 (GND), X3.G1 (GND), X3.G2 (GND), X3.G3 (GND), X3.G4 (GND); also elsewhere on the board
LDQM: U3.15; also elsewhere on the board
RAS#: U3.18; also elsewhere on the board
SD-CLK: X3.5 (CLK/SCLK); also elsewhere on the board
SD-CMD: R35.1, X3.3 (CMD/DIN); also elsewhere on the board
SD-DAT0: R34.1, X3.7 (DAT0/DOUT); also elsewhere on the board
SD-DAT1: R34.2 (1), X3.8 (DAT1/NC); also elsewhere on the board
SD-DAT2: R34.3 (1), X3.1 (DAT2/NC); also elsewhere on the board
SD-DAT3: R34.4 (1), X3.2 (DAT3_CD/CS#); also elsewhere on the board
SDRAM-CLK: U3.38; also elsewhere on the board
SDRAM-CS#: U3.19; also elsewhere on the board
UDQM: U3.39; also elsewhere on the board
VCC3V3: C3.2, C4.2, C5.2, C6.2, C7.2, C8.2, C9.2, C11.2, C12.2, C13.2, C155.2, C156.2, C157.2, C158.2, C159.2, R2.2, R6.2, R7.2, R34.5 (2), R34.6 (2), R34.7 (2), R34.8 (2), R35.2, U3.1, U3.3, U3.9, U3.14, U3.27, U3.43, U3.49, U4.8, X3.4 (VDD); also elsewhere on the board
WE#: U3.16; also elsewhere on the board

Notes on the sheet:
Memory
shell pads G1-G4 to GND; card-detect switch A/B (closed with card) left open. Needs its own footprint on the PCB.
2026-09-06: X3 is now the Hirose DM3D-SF push-pull socket (HRS 609-0025-8), DM3 catalog p9. Same 8-contact pinout;
MASTER SPI BOOT (x4). M2:M1:M0 = 0:0:1 -- R20 pulls M0 to VCC3V3, R21/R22 pull M1/M2 to GND -- so at power-up the FPGA drives CCLK itself and clocks its bitstream out of U4 with no USB and no host present. That mode can only use the dedicated configuration pins: CCLK C11, FCS_B K19, D00_MOSI D18, D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
U3 DECOUPLING -- each cap bridges one supply pin to the ground pin OPPOSITE it. In the 54-pin TSOP-II, pin n faces pin 55-n, and every supply pin faces a ground of its own domain: VDD 1/14/27 to VSS 54/41/28, VDDQ 3/9/43/49 to VSSQ 52/46/12/6. Alliance isolates VDDQ from VDD for DQ noise immunity -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
U3 = AS4C32M16SB-7TCN: 512Mbit (32M x 16) = 64MB. Pin-for-pin and dimensionally identical to the 256Mb AS4C16M16SA-6TIN it replaces -- all 54 pins and every TSOP-II dimension checked against both datasheets, and pin 40 is NC on both. ONE DIFFERENCE, AND IT IS NOT A PIN: the column address is A0-A9 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
microSD runs the NATIVE 4-BIT SD BUS, not SPI. CLK, CMD and DAT0-DAT3 -- six signals, all in bank 34 byte group T0 (R2 T1 T2 U1 V2 W2), so they can be constrained as one bus. DAT1/DAT2 came from prototyping-header CHAN1/CHAN0; DAT3 is the old SPI chip-select, which needs no new pin. R34/R35 are the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

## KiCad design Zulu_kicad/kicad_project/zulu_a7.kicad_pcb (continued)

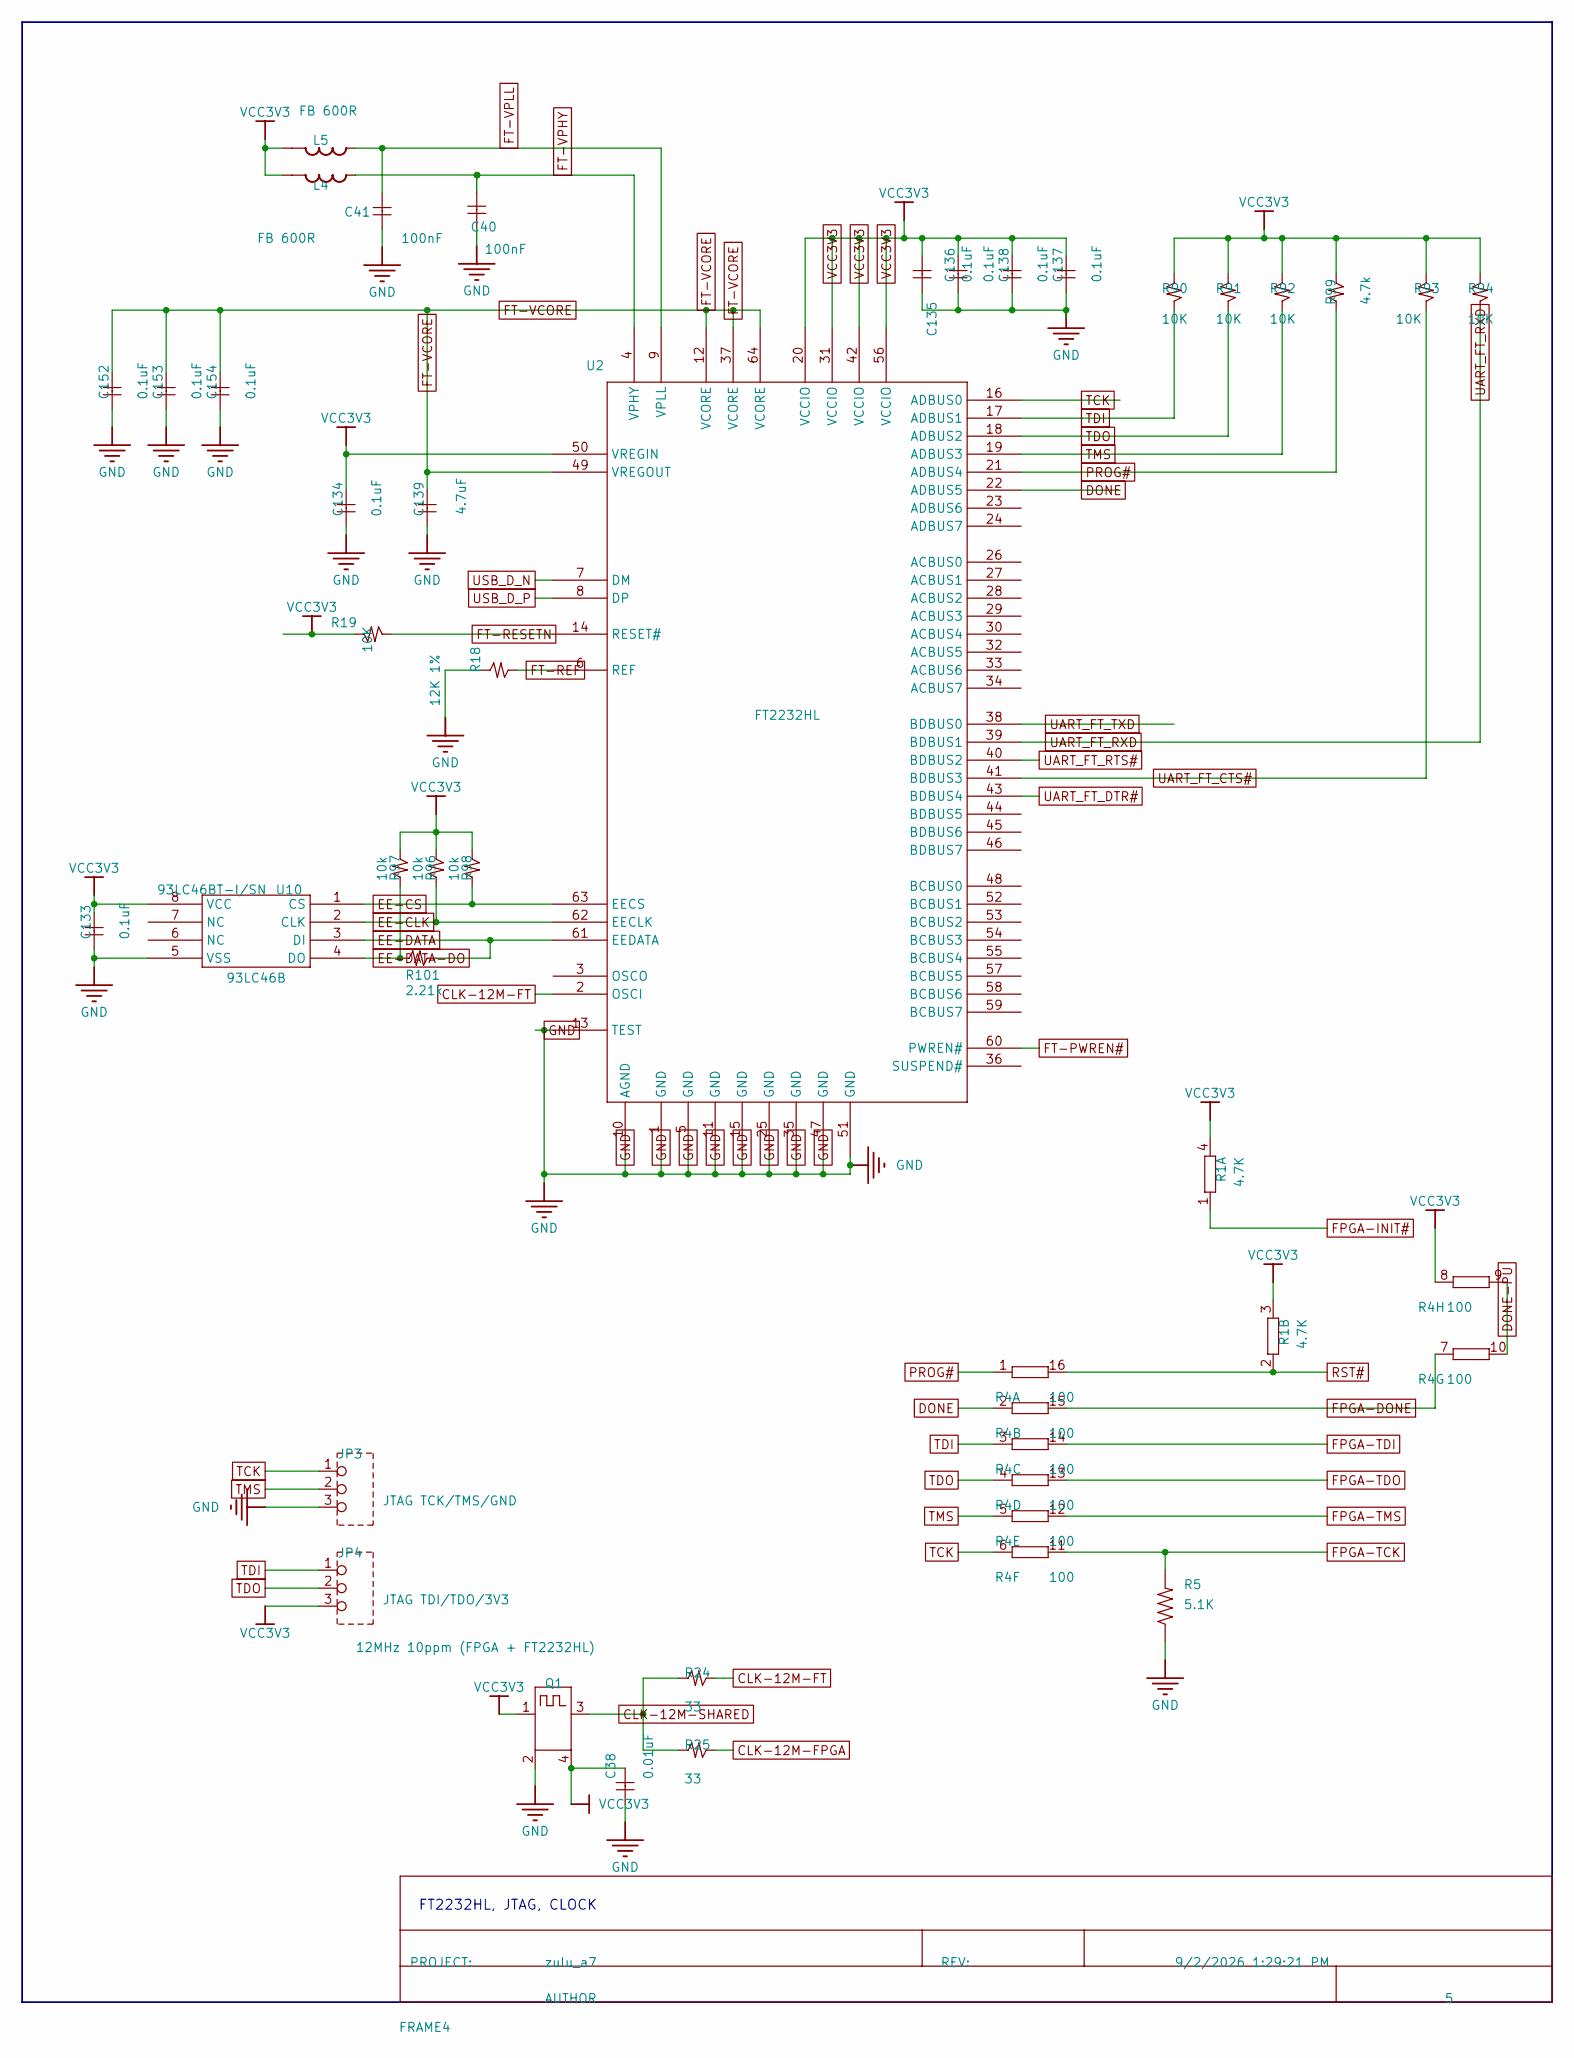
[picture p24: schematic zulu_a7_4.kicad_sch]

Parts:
C38: 0.01uF; C0201
C40, C41: 100nF; C0201
C133, C134, C135, C136, C137, C138, C152, C153, C154: 0.1uF; C0201
C139: 4.7uF; C0402
FRAME4: DOCFIELD
JP3: JTAG TCK/TMS/GND; 1X03-NOSILK
JP4: JTAG TDI/TDO/3V3; 1X03-NOSILK
L4, L5: FB 600R; IND0603
Q1: 12MHz 10ppm (FPGA + FT2232HL); 32X25
R1: 4.7K; 742C043
R4: 100; 742C163
R5: 5.1K; R0201; MOUSER# 301-5.1K-RC
R18: 12K 1%; R0402
R19, R90, R91, R92, R93, R94: 10K; R0201
R24, R25: 33; R0201
R96, R97, R98: 10k; R0201
R99: 4.7k; R0201
R101: 2.21k; R0201
U2: FT2232HL USB-UART/JTAG Bridge; FT2232HL-LQFP64
U10: 93LC46BT-I/SN; SPI-8_SOIC_150

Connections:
CLK-12M-FPGA: R25.2; also elsewhere on the board
CLK-12M-FT: R24.2, U2.2 (OSCI)
CLK-12M-SHARED: Q1.3, R24.1, R25.1
DONE: R4.2 (1), U2.22 (ADBUS5)
DONE-PU: R4.9 (2), R4.10 (2)
EE-CLK: R96.1, U2.62 (EECLK), U10.2 (CLK)
EE-CS: R98.1, U2.63 (EECS), U10.1 (CS)
EE-DATA: R101.2, U2.61 (EEDATA), U10.3 (DI)
EE-DATA-DO: R97.1, R101.1, U10.4 (DO)
FPGA-DONE: R4.7 (1), R4.15 (2); also elsewhere on the board
FPGA-INIT#: R1.1; also elsewhere on the board
FPGA-TCK: R4.11 (2), R5.2; also elsewhere on the board
FPGA-TDI: R4.14 (2); also elsewhere on the board
FPGA-TDO: R4.13 (2); also elsewhere on the board
FPGA-TMS: R4.12 (2); also elsewhere on the board
FT-PWREN#: U2.60 (PWREN#); also elsewhere on the board
FT-REF: R18.2, U2.6 (REF)
FT-RESETN: R19.1, U2.14 (RESET#)
FT-VCORE: C139.2, C152.2, C153.2, C154.2, U2.12 (VCORE), U2.37 (VCORE), U2.49 (VREGOUT), U2.64 (VCORE)
FT-VPHY: C40.2, L4.1, U2.4 (VPHY)
FT-VPLL: C41.2, L5.1, U2.9 (VPLL)
GND: C38.1, C40.1, C41.1, C133.1, C134.1, C135.1, C136.1, C137.1, C138.1, C139.1, C152.1, C153.1, C154.1, JP3.3, Q1.2, R5.1, R18.1, U2.1 (GND), U2.5 (GND), U2.10 (AGND), U2.11 (GND), U2.13 (TEST), U2.15 (GND), U2.25 (GND), U2.35 (GND), U2.47 (GND), U2.51 (GND), U10.5 (VSS); also elsewhere on the board
PROG#: R4.1, R99.1, U2.21 (ADBUS4)
RST#: R1.2 (1), R4.16 (2); also elsewhere on the board
TCK: JP3.1, R4.6 (1), U2.16 (ADBUS0)
TDI: JP4.1, R4.3 (1), R90.1, U2.17 (ADBUS1)
TDO: JP4.2, R4.4 (1), R91.1, U2.18 (ADBUS2)
TMS: JP3.2, R4.5 (1), R92.1, U2.19 (ADBUS3)
UART_FT_CTS#: R93.1, U2.41 (BDBUS3); also elsewhere on the board
UART_FT_DTR#: U2.43 (BDBUS4); also elsewhere on the board
UART_FT_RTS#: U2.40 (BDBUS2); also elsewhere on the board
UART_FT_RXD: R94.1, U2.39 (BDBUS1); also elsewhere on the board
UART_FT_TXD: U2.38 (BDBUS0); also elsewhere on the board
USB_D_N: U2.7 (DM); also elsewhere on the board
USB_D_P: U2.8 (DP); also elsewhere on the board
VCC3V3: C38.2, C133.2, C134.2, C135.2, C136.2, C137.2, C138.2, JP4.3, L4.2, L5.2, Q1.1, Q1.4, R1.3 (2), R1.4 (2), R4.8 (1), R19.2, R90.2, R91.2, R92.2, R93.2, R94.2, R96.2, R97.2, R98.2, R99.2, U2.20 (VCCIO), U2.31 (VCCIO), U2.42 (VCCIO), U2.50 (VREGIN), U2.56 (VCCIO), U10.8 (VCC); also elsewhere on the board

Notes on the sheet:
FT2232HL, JTAG, CLOCK

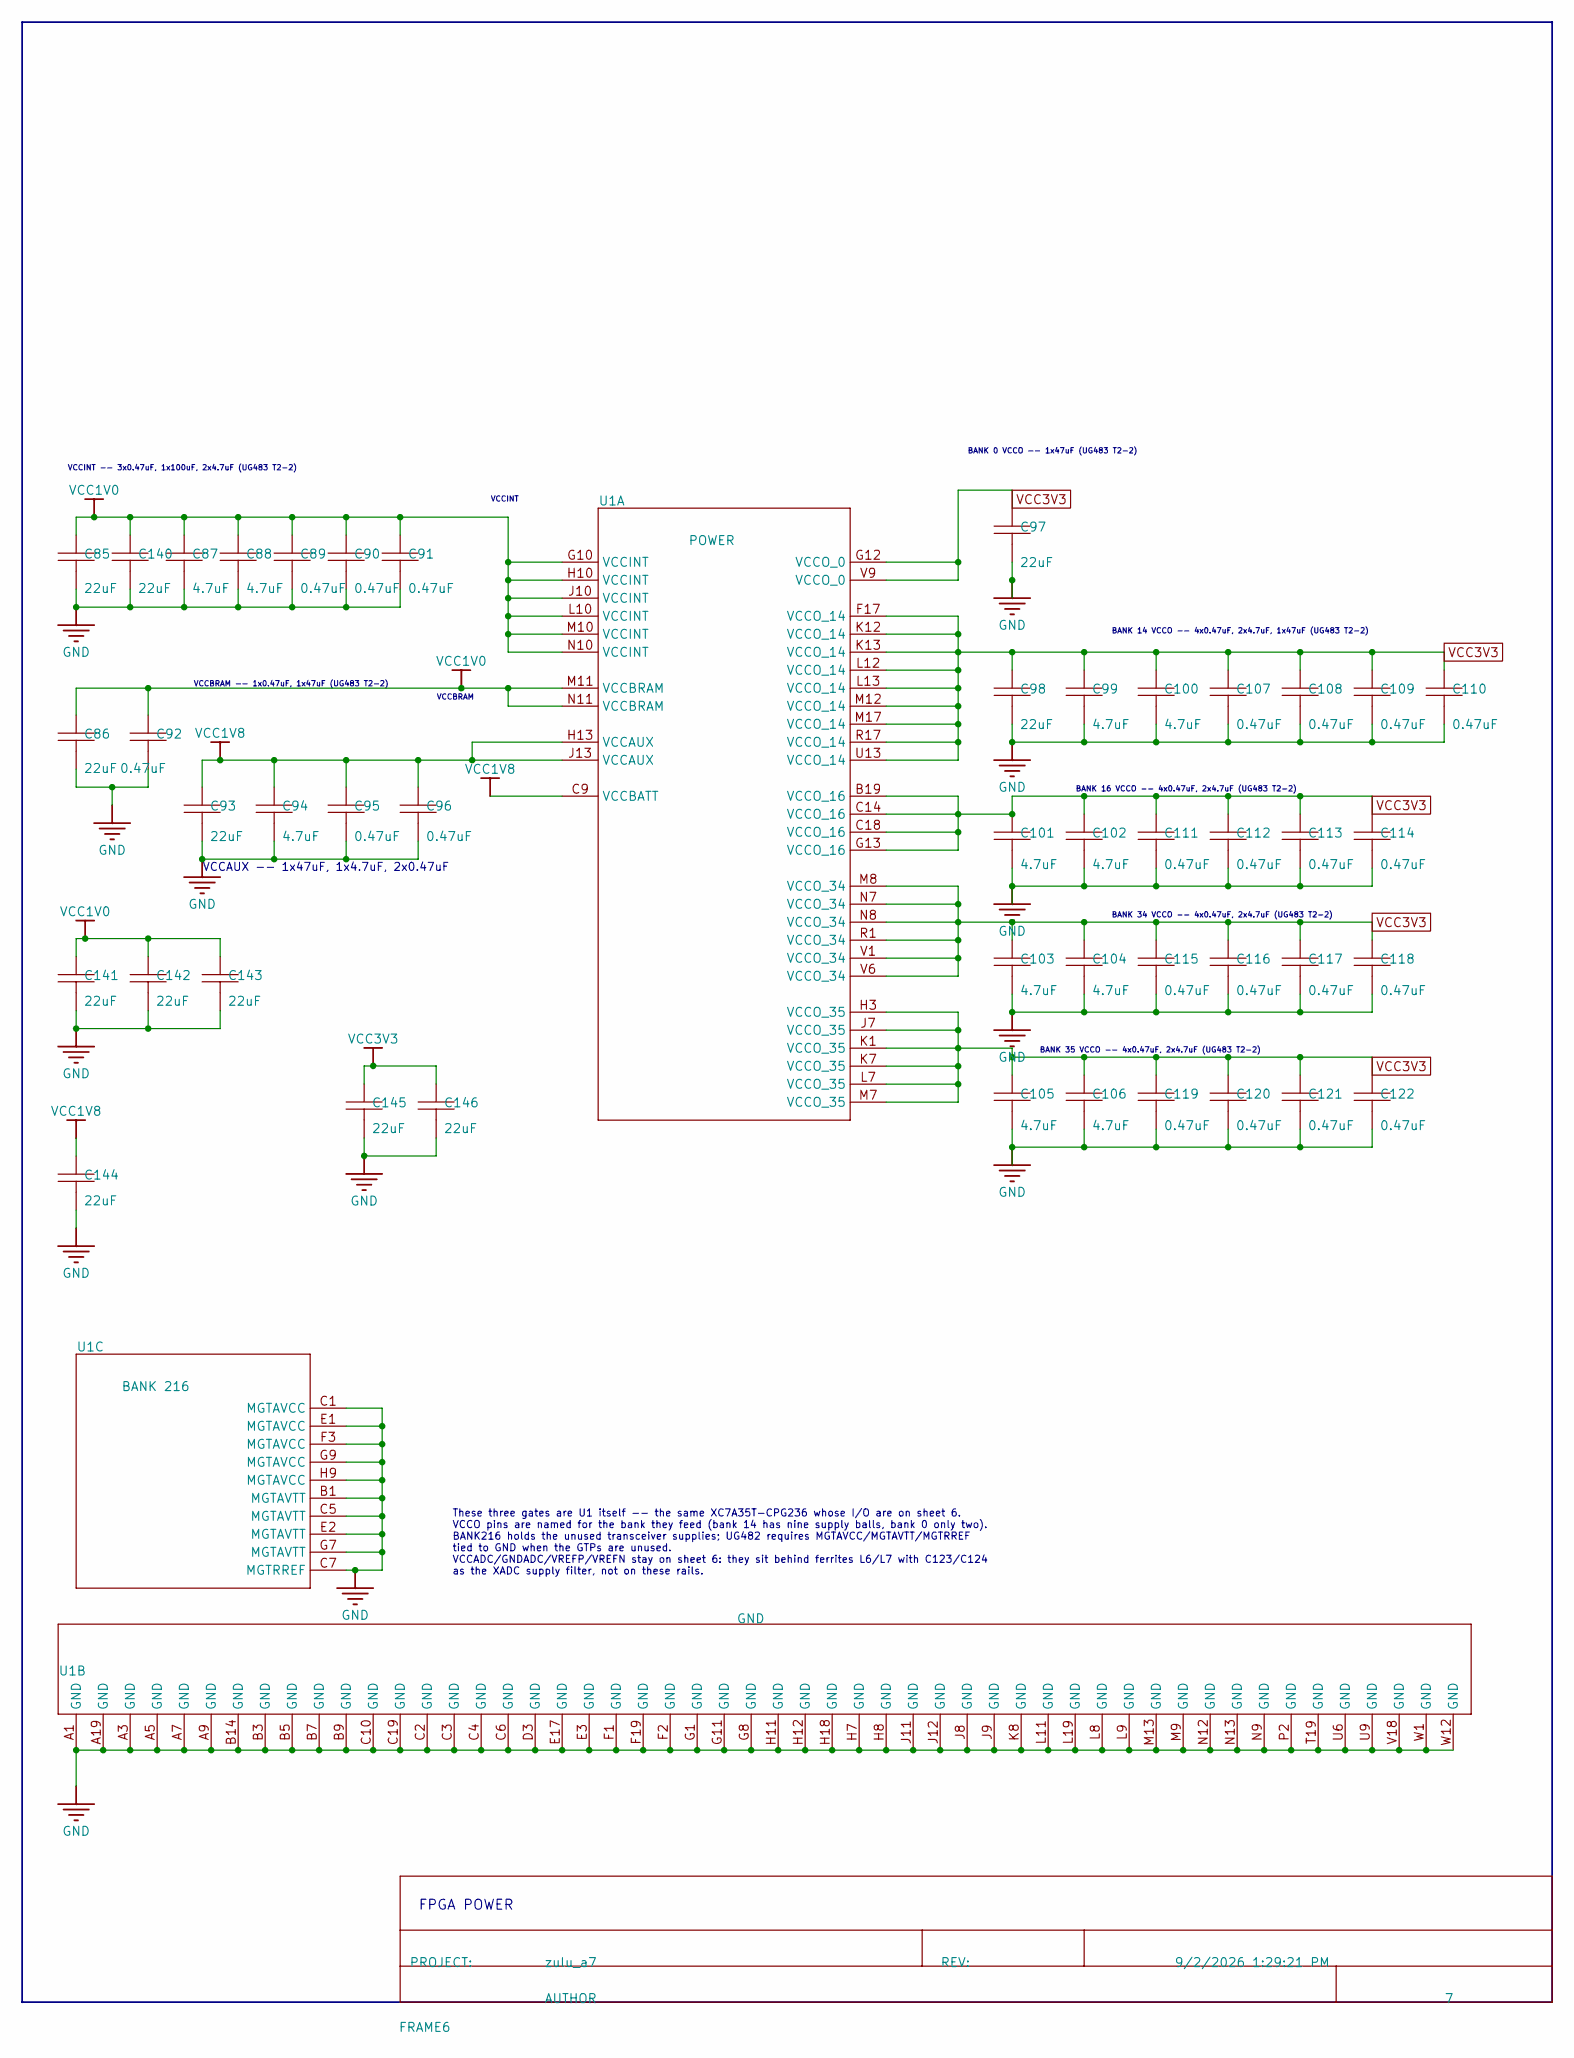
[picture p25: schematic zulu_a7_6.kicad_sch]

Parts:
C85, C86, C93, C97, C98, C140, C141, C142, C143, C144, C145, C146: 22uF; C0805
C87, C88, C94, C99, C100, C101, C102, C103, C104, C105, C106: 4.7uF; C0603
C89, C90, C91, C92, C95, C96, C107, C108, C109, C110, C111, C112, C113, C114, C115, C116, C117, C118, C119, C120, C121, C122: 0.47uF; C0201
FRAME6: DOCFIELD
U1: XC7A35T-1CPG236C; XC7A35T-CPG236

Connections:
A0: U1.U2 (1); also elsewhere on the board
A1: U1.T3 (1); also elsewhere on the board
A2: U1.T2 (1); also elsewhere on the board
A3: U1.T1 (1); also elsewhere on the board
A4: U1.R3 (1); also elsewhere on the board
A5: U1.R2 (1); also elsewhere on the board
A6: U1.P3 (1); also elsewhere on the board
A7: U1.P1 (1); also elsewhere on the board
A8: U1.N3 (1); also elsewhere on the board
A9: U1.N2 (1); also elsewhere on the board
A10: U1.U3 (1); also elsewhere on the board
A11: U1.N1 (1); also elsewhere on the board
A12: U1.M3 (1); also elsewhere on the board
AIN15_N: U1.G2 (1); also elsewhere on the board
AIN15_P: U1.G3 (1); also elsewhere on the board
AIN16_N: U1.J2 (1); also elsewhere on the board
AIN16_P: U1.H2 (1); also elsewhere on the board
BS0: U1.V2 (1); also elsewhere on the board
BS1: U1.U1 (1); also elsewhere on the board
BTN: U1.N19 (1); also elsewhere on the board
CAS#: U1.W3 (1); also elsewhere on the board
CFG-M0: U1.V12 (1); also elsewhere on the board
CFG-M1: U1.W11 (1); also elsewhere on the board
CFG-M2: U1.U10 (1); also elsewhere on the board
CHAN0: U1.B18 (1); also elsewhere on the board
CHAN1: U1.A18 (1); also elsewhere on the board
CHAN2: U1.B17 (1); also elsewhere on the board
CHAN3: U1.A17 (1); also elsewhere on the board
CHAN4: U1.C16 (1); also elsewhere on the board
CHAN5: U1.D17 (1); also elsewhere on the board
CHAN6: U1.H17 (1); also elsewhere on the board
CHAN7: U1.G17 (1); also elsewhere on the board
CHAN8: U1.J18 (1); also elsewhere on the board
CHAN9: U1.J17 (1); also elsewhere on the board
CHAN10: U1.J19 (1); also elsewhere on the board
CHAN11: U1.K18 (1); also elsewhere on the board
CHAN12: U1.E19 (1); also elsewhere on the board
CHAN13: U1.H19 (1); also elsewhere on the board
CHAN14: U1.W17 (1); also elsewhere on the board
CHAN15: U1.V17 (1); also elsewhere on the board
CHAN16: U1.W16 (1); also elsewhere on the board
CHAN17: U1.U16 (1); also elsewhere on the board
CHAN18: U1.V16 (1); also elsewhere on the board
CHAN19: U1.W15 (1); also elsewhere on the board
CHAN20: U1.V15 (1); also elsewhere on the board
CHAN21: U1.U15 (1); also elsewhere on the board
CHAN22: U1.W14 (1); also elsewhere on the board
CHAN23: U1.V14 (1); also elsewhere on the board
CHAN24: U1.U14 (1); also elsewhere on the board
CHAN25: U1.W13 (1); also elsewhere on the board
CHAN26: U1.V13 (1); also elsewhere on the board
CHAN27: U1.T18 (1); also elsewhere on the board
CHAN28: U1.T17 (1); also elsewhere on the board
CHAN-CLK: U1.P18 (1); also elsewhere on the board
CKE: U1.M2 (1); also elsewhere on the board
CLK-12M-FPGA: U1.L17 (1); also elsewhere on the board
D0: U1.V8 (1); also elsewhere on the board
D1: U1.V7 (1); also elsewhere on the board
D2: U1.W7 (1); also elsewhere on the board
D3: U1.W6 (1); also elsewhere on the board
D4: U1.U5 (1); also elsewhere on the board
D5: U1.W5 (1); also elsewhere on the board
D6: U1.V5 (1); also elsewhere on the board
D7: U1.U4 (1); also elsewhere on the board
D8: U1.L1 (1); also elsewhere on the board
D9: U1.K3 (1); also elsewhere on the board
D10: U1.K2 (1); also elsewhere on the board
D11: U1.J1 (1); also elsewhere on the board
D12: U1.J3 (1); also elsewhere on the board
D13: U1.H1 (1); also elsewhere on the board
D14: U1.A14 (1); also elsewhere on the board
D15: U1.A15 (1); also elsewhere on the board
FLASH-CS#: U1.K19 (1); also elsewhere on the board
FLASH-D00: U1.D18 (1); also elsewhere on the board
FLASH-D01: U1.D19 (1); also elsewhere on the board
FLASH-D02: U1.G18 (1); also elsewhere on the board
FLASH-D03: U1.F18 (1); also elsewhere on the board
FPGA-CCLK: U1.C11 (1); also elsewhere on the board
FPGA-DONE: U1.U12 (1); also elsewhere on the board
FPGA-INIT#: U1.U11 (1); also elsewhere on the board
FPGA-TCK: U1.C8 (1); also elsewhere on the board
FPGA-TDI: U1.W10 (1); also elsewhere on the board
FPGA-TDO: U1.W8 (1); also elsewhere on the board
FPGA-TMS: U1.W9 (1); also elsewhere on the board
FT-PWREN#: U1.P19 (1); also elsewhere on the board
GND: C85.2, C86.2, C87.2, C88.2, C89.2, C90.2, C91.2, C92.2, C93.2, C94.2, C95.2, C96.2, C97.2, C98.2, C99.2, C100.2, C101.2, C102.2, C103.2, C104.2, C105.2, C106.2, C107.2, C108.2, C109.2, C110.2, C111.2, C112.2, C113.2, C114.2, C115.2, C116.2, C117.2, C118.2, C119.2, C120.2, C121.2, C122.2, C140.2, C141.2, C142.2, C143.2, C144.2, C145.2, C146.2, U1.A1 (GND), U1.A3 (GND), U1.A4 (1), U1.A5 (GND), U1.A6 (1), U1.A7 (GND), U1.A9 (GND), U1.A11 (1), U1.A19 (GND), U1.B1 (MGTAVTT), U1.B3 (GND), U1.B4 (1), U1.B5 (GND), U1.B6 (1), U1.B7 (GND), U1.B9 (GND), U1.B11 (1), U1.B14 (GND), U1.C1 (MGTAVCC), U1.C2 (GND), U1.C3 (GND), U1.C4 (GND), U1.C5 (MGTAVTT), U1.C6 (GND), U1.C7 (MGTRREF), U1.C10 (GND), U1.C19 (GND), U1.D3 (GND), U1.E1 (MGTAVCC), U1.E2 (MGTAVTT), U1.E3 (GND), U1.E17 (GND), U1.F1 (GND), U1.F2 (GND), U1.F3 (MGTAVCC), U1.F19 (GND), U1.G1 (GND), U1.G7 (MGTAVTT), U1.G8 (GND), U1.G9 (MGTAVCC), U1.G11 (GND), U1.H7 (GND), U1.H8 (GND), U1.H9 (MGTAVCC), U1.H11 (GND), U1.H12 (GND), U1.H18 (GND), U1.J8 (GND), U1.J9 (GND), U1.J11 (GND), U1.J12 (GND), U1.K8 (GND), U1.L8 (GND), U1.L9 (GND), U1.L11 (GND), U1.L19 (GND), U1.M9 (GND), U1.M13 (GND), U1.N9 (GND), U1.N12 (GND), U1.N13 (GND), U1.P2 (GND), U1.T19 (GND), U1.U6 (GND), U1.U9 (GND), U1.V18 (GND), U1.W1 (GND), U1.W12 (GND); also elsewhere on the board
GNDADC: U1.A12 (1), U1.A13 (1), U1.B12 (1), U1.B13 (1), U1.C12 (1); also elsewhere on the board
JA1: U1.U18 (1); also elsewhere on the board
JA2: U1.U19 (1); also elsewhere on the board
JA3: U1.W18 (1); also elsewhere on the board
JA4: U1.C17 (1); also elsewhere on the board
JA7: U1.R19 (1); also elsewhere on the board
JA8: U1.W19 (1); also elsewhere on the board
JA9: U1.V19 (1); also elsewhere on the board
JA10: U1.U17 (1); also elsewhere on the board
LDQM: U1.W4 (1); also elsewhere on the board
LED0_B: U1.N17 (1); also elsewhere on the board
LED0_G: U1.R18 (1); also elsewhere on the board
LED0_R: U1.P17 (1); also elsewhere on the board
LED1: U1.N18 (1); also elsewhere on the board
LED2: U1.M19 (1); also elsewhere on the board
PUDC_B: U1.E18 (1); also elsewhere on the board
RAS#: U1.V3 (1); also elsewhere on the board
RST#: U1.V10 (1); also elsewhere on the board
SD-CLK: U1.U8 (1); also elsewhere on the board
SD-CMD: U1.U7 (1); also elsewhere on the board
SD-DAT0: U1.C15 (1); also elsewhere on the board
SD-DAT1: U1.B15 (1); also elsewhere on the board
SD-DAT2: U1.L3 (1); also elsewhere on the board
SD-DAT3: U1.A16 (1); also elsewhere on the board
SDRAM-CLK: U1.M1 (1); also elsewhere on the board
SDRAM-CS#: U1.W2 (1); also elsewhere on the board
UART_FT_CTS#: U1.B16 (1); also elsewhere on the board
UART_FT_DTR#: U1.M18 (1); also elsewhere on the board
UART_FT_RTS#: U1.L18 (1); also elsewhere on the board
UART_FT_RXD: U1.G19 (1); also elsewhere on the board
UART_FT_TXD: U1.K17 (1); also elsewhere on the board
UDQM: U1.L2 (1); also elsewhere on the board
VCC1V0: C85.1, C86.1, C87.1, C88.1, C89.1, C90.1, C91.1, C92.1, C140.1, C141.1, C142.1, C143.1, U1.G10 (VCCINT), U1.H10 (VCCINT), U1.J10 (VCCINT), U1.L10 (VCCINT), U1.M10 (VCCINT), U1.M11 (VCCBRAM), U1.N10 (VCCINT), U1.N11 (VCCBRAM); also elsewhere on the board
VCC1V8: C93.1, C94.1, C95.1, C96.1, C144.1, U1.C9 (VCCBATT), U1.H13 (VCCAUX), U1.J13 (VCCAUX); also elsewhere on the board
VCC3V3: C97.1, C98.1, C99.1, C100.1, C101.1, C102.1, C103.1, C104.1, C105.1, C106.1, C107.1, C108.1, C109.1, C110.1, C111.1, C112.1, C113.1, C114.1, C115.1, C116.1, C117.1, C118.1, C119.1, C120.1, C121.1, C122.1, C145.1, C146.1, U1.B19 (VCCO_16), U1.C14 (VCCO_16), U1.C18 (VCCO_16), U1.F17 (VCCO_14), U1.G12 (VCCO_0), U1.G13 (VCCO_16), U1.H3 (VCCO_35), U1.J7 (VCCO_35), U1.K1 (VCCO_35), U1.K7 (VCCO_35), U1.K12 (VCCO_14), U1.K13 (VCCO_14), U1.L7 (VCCO_35), U1.L12 (VCCO_14), U1.L13 (VCCO_14), U1.M7 (VCCO_35), U1.M8 (VCCO_34), U1.M12 (VCCO_14), U1.M17 (VCCO_14), U1.N7 (VCCO_34), U1.N8 (VCCO_34), U1.R1 (VCCO_34), U1.R17 (VCCO_14), U1.U13 (VCCO_14), U1.V1 (VCCO_34), U1.V6 (VCCO_34), U1.V9 (VCCO_0), U1.V11 (1); also elsewhere on the board
VCCADC: U1.C13 (1); also elsewhere on the board
WE#: U1.V4 (1); also elsewhere on the board

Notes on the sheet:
BANK 0 VCCO -- 1x47uF (UG483 T2-2)
BANK 16 VCCO -- 4x0.47uF, 2x4.7uF (UG483 T2-2)
VCCINT
VCCINT -- 3x0.47uF, 1x100uF, 2x4.7uF (UG483 T2-2)
BANK 35 VCCO -- 4x0.47uF, 2x4.7uF (UG483 T2-2)
VCCAUX -- 1x47uF, 1x4.7uF, 2x0.47uF
VCCBRAM
BANK 34 VCCO -- 4x0.47uF, 2x4.7uF (UG483 T2-2)
FPGA POWER
VCCBRAM -- 1x0.47uF, 1x47uF (UG483 T2-2)
BANK 14 VCCO -- 4x0.47uF, 2x4.7uF, 1x47uF (UG483 T2-2)
These three gates are U1 itself -- the same XC7A35T-CPG236 whose I/O are on sheet 6. VCCO pins are named for the bank they feed (bank 14 has nine supply balls, bank 0 only two). BANK216 holds the unused transceiver supplies; UG482 requires MGTAVCC/MGTAVTT/MGTRREF tied to GND when the GTPs are unuse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

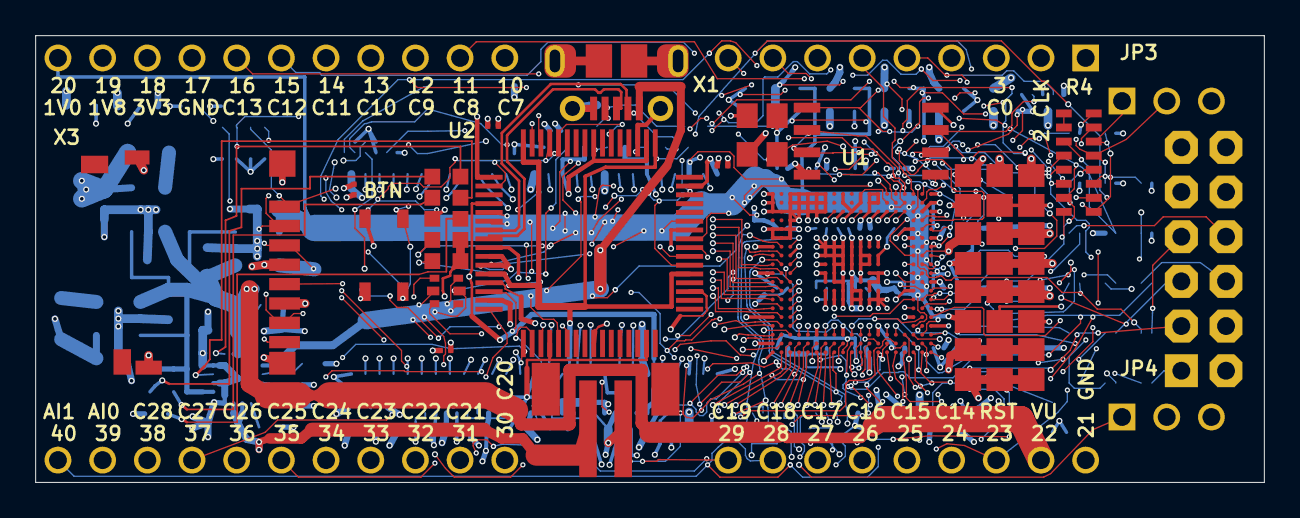
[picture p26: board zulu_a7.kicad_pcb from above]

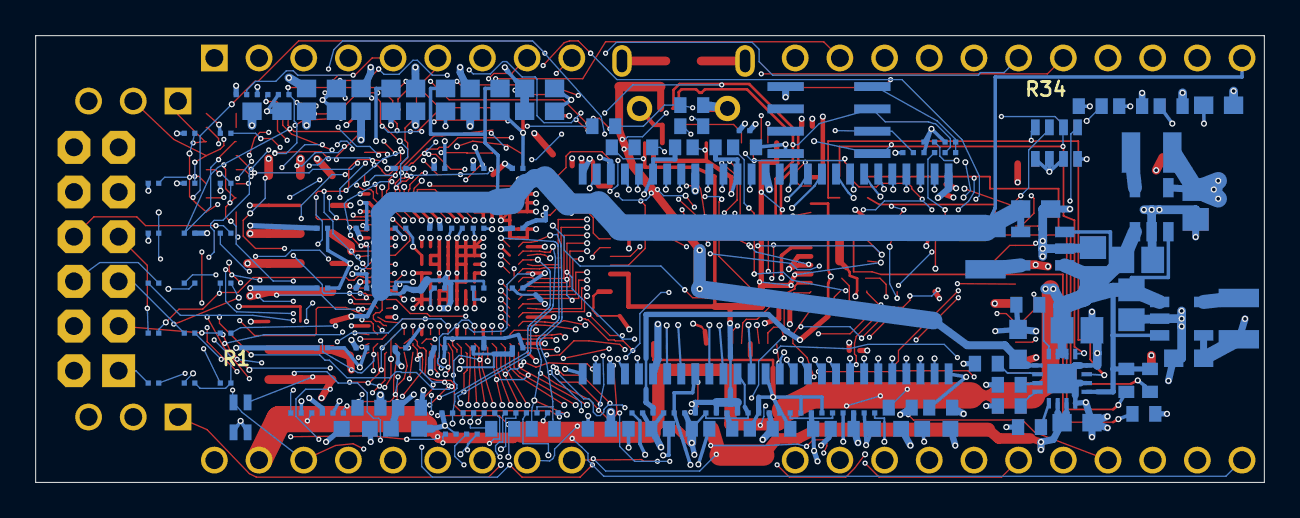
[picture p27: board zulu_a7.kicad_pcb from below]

Board: 6 copper layers, 69.8 x 25.4 mm, 178 parts (139 on the bottom side), 177 nets.

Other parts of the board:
C123: 100nF; C0201
C124: 470nF; C0402
L6, L7: FB 600R; IND0603
R20, R22, R23: 1K; R0201
R21: 1K; R0402

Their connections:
CFG-M0: R20.1; also elsewhere on the board
CFG-M1: R21.2; also elsewhere on the board
CFG-M2: R22.2; also elsewhere on the board
GND: L6.1, R21.1, R22.1; also elsewhere on the board
GNDADC: C123.2, C124.2, L6.2; also elsewhere on the board
PUDC_B: R23.2; also elsewhere on the board
VCC1V8: L7.1; also elsewhere on the board
VCC3V3: R20.2, R23.1; also elsewhere on the board
VCCADC: C123.1, C124.1, L7.2; also elsewhere on the board

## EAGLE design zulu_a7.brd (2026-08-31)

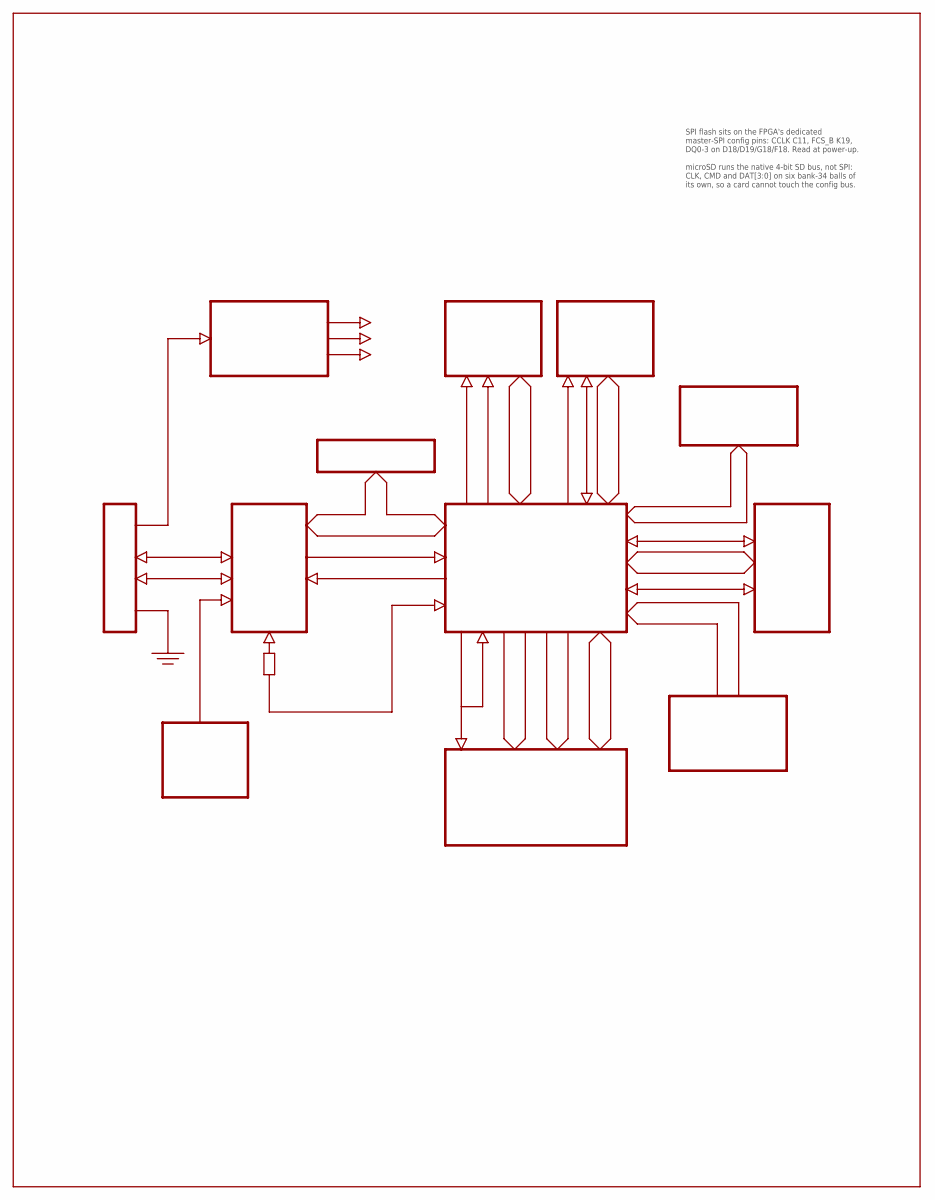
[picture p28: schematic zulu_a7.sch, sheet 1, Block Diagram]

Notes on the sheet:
SPI flash sits on the FPGA's dedicated master-SPI config pins: CCLK C11, FCS_B K19, DQ0-3 on D18/D19/G18/F18. Read at power-up. microSD runs the native 4-bit SD bus, not SPI: CLK, CMD and DAT[3:0] on six bank-34 balls of its own, so a card cannot touch the config bus.

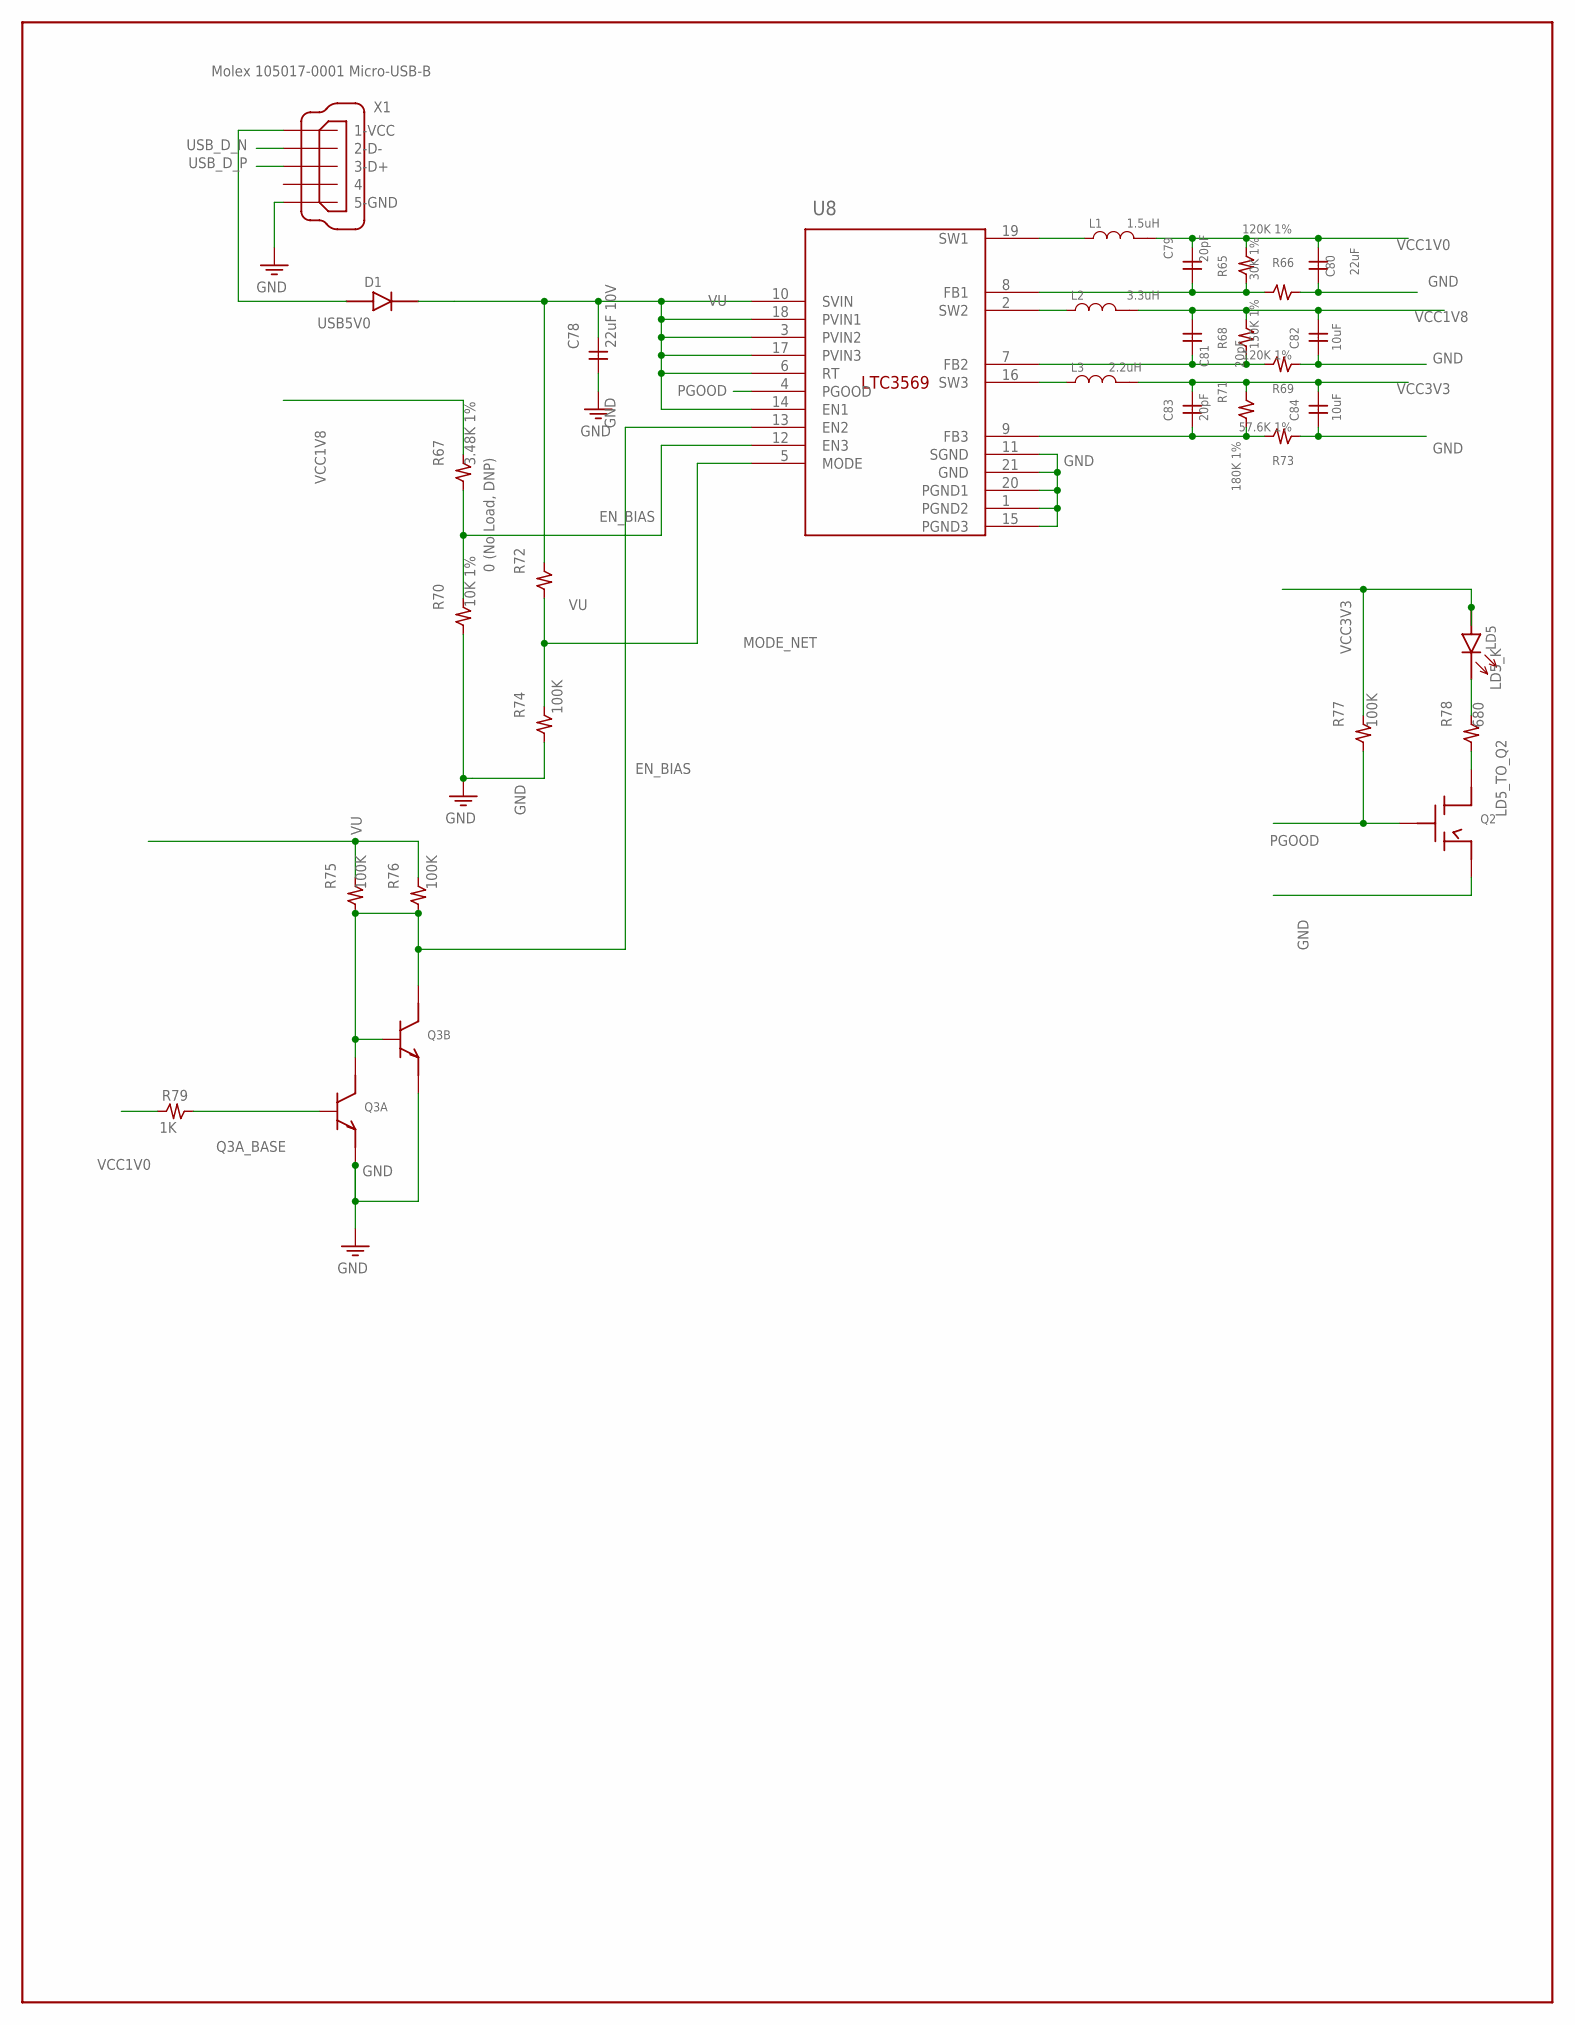
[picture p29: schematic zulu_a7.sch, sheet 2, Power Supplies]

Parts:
C78: 22uF 10V; C0805
C79, C81, C83: 20pF; C0402
C80: 22uF; C0805
C82, C84: 10uF; C0603
D1: PMEG2020EJ,115; SOD123
L1: 1.5uH; IND2520
L2: 3.3uH; IND2520
L3: 2.2uH; IND2520
LD5: green; LED0603
Q2: 2N7002; SOT23-3
Q3: MBT3904DW1T1; SOT363
R65: 30K 1%; R0402
R66, R69: 120K 1%; R0402
R67: 3.48K 1%; R0402
R68: 150K 1%; R0402
R70: 10K 1%; R0402
R71: 180K 1%; R0402
R72: 0 (No Load, DNP); R0402
R73: 57.6K 1%; R0402
R74, R75, R76, R77: 100K; R0402
R78: 680; R0402
R79: 1K; R0402
U8: LTC3569EUDC#TRPBF; LTC3569-QFN20
X1: Molex 105017-0001 Micro-USB-B; MOLEX-105017-0001

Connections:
EN_BIAS: Q3.4 (B), Q3.5 (C), Q3.6 (C), R67.1, R70.2, R75.1, R76.1, U8.12 (EN3), U8.13 (EN2)
FB1_NODE: C79.1, R65.1, R66.2, U8.8 (FB1)
FB2_NODE: C81.1, R68.1, R69.2, U8.7 (FB2)
FB3_NODE: C83.1, R71.1, R73.2, U8.9 (FB3)
GND: C78.1, C80.1, C82.1, C84.1, Q2.S, Q3.2 (E), Q3.3 (E), R66.1, R69.1, R70.1, R73.1, R74.1, U8.1 (PGND2), U8.11 (SGND), U8.15 (PGND3), U8.20 (PGND1), U8.21 (GND), X1.5 (5-GND), X1.MH1 (5-GND), X1.MH2 (5-GND), X1.MP1 (5-GND), X1.MP2 (5-GND), X1.MP3 (5-GND), X1.MP4 (5-GND), X1.MS1 (5-GND), X1.MS2 (5-GND); also elsewhere on the board
LD5_K: LD5.K, R78.2
LD5_TO_Q2: Q2.D, R78.1
MODE_NET: R72.1, R74.2, U8.5 (MODE)
PGOOD: Q2.G, R77.1, U8.4 (PGOOD)
Q3A_BASE: Q3.1 (B), R79.2
SW1_NET: L1.1, U8.19 (SW1)
SW2_NET: L2.1, U8.2 (SW2)
SW3_NET: L3.1, U8.16 (SW3)
USB5V0: D1.A, X1.1 (1-VCC)
USB_D_N: X1.2 (2-D-); also elsewhere on the board
USB_D_P: X1.3 (3-D+); also elsewhere on the board
VCC1V0: C79.2, C80.2, L1.2, R65.2, R79.1; also elsewhere on the board
VCC1V8: C81.2, C82.2, L2.2, R67.2, R68.2; also elsewhere on the board
VCC3V3: C83.2, C84.2, L3.2, LD5.A, R71.2, R77.2; also elsewhere on the board
VU: C78.2, D1.K, R72.2, R75.2, R76.2, U8.3 (PVIN2), U8.6 (RT), U8.10 (SVIN), U8.14 (EN1), U8.17 (PVIN3), U8.18 (PVIN1); also elsewhere on the board

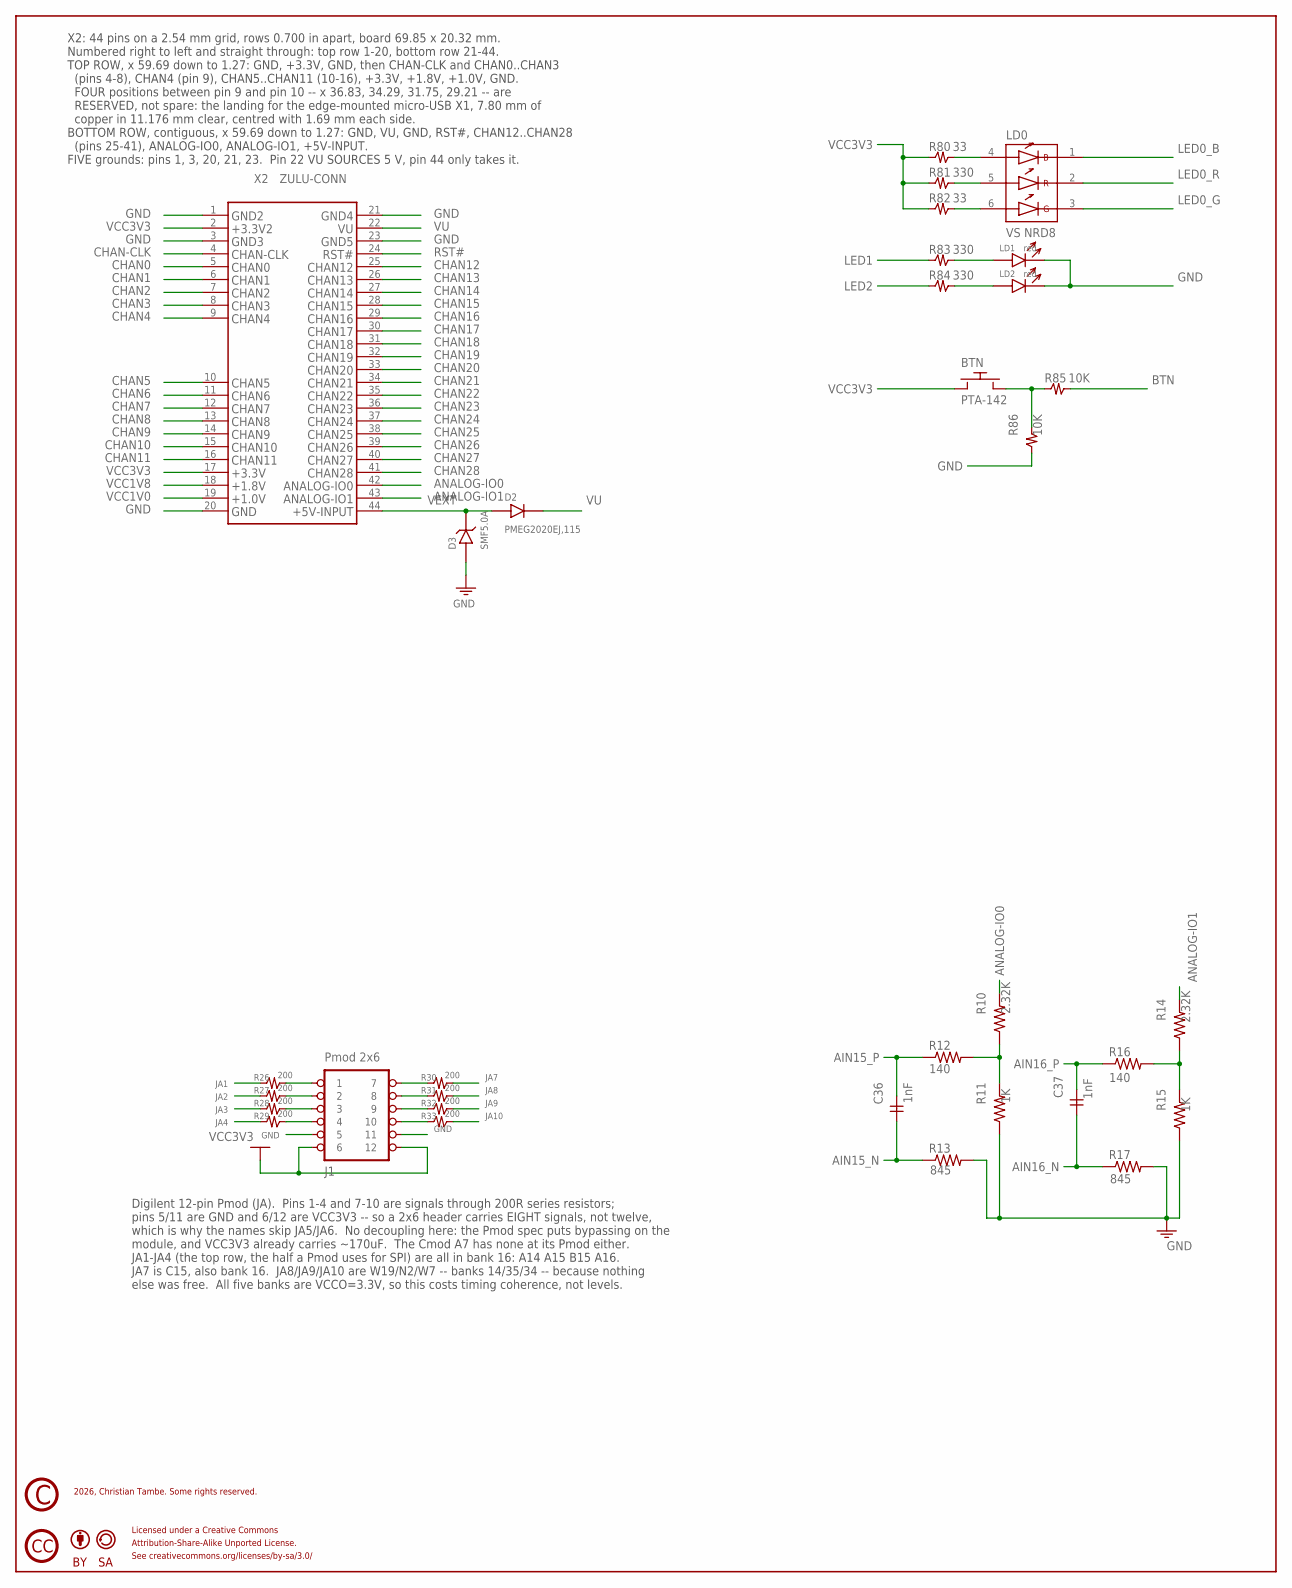
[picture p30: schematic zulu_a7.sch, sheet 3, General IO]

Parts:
BTN: PTA-142
C36, C37: 1nF; C0402
D2: PMEG2020EJ,115; SOD123
D3: SMF5.0A; SOD123
J1: Pmod 2x6; 2X06
LD0: VS NRD8; VS-NRD8
LD1, LD2: red; LED0603
R10, R14: 2.32K; R0201
R11, R15: 1K; R0201
R12, R16: 140; R0201
R13, R17: 845; R0201
R26, R27, R28, R29, R30, R31, R32, R33: 200; R0201
R80, R82: 33; R0402
R81, R83, R84: 330; R0402
R85, R86: 10K; R0402
U$2: CC_CC
U$3: CC_BY
U$4: CC_SA
U$5: CC_COPYRIGHT
X2: ZULU-CONN; ZULU-DIP37

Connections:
AIN15_N: C36.1, R13.1; also elsewhere on the board
AIN15_P: C36.2, R12.1; also elsewhere on the board
AIN16_N: C37.1, R17.1; also elsewhere on the board
AIN16_P: C37.2, R16.1; also elsewhere on the board
ANALOG-IO0: R10.2, X2.42
ANALOG-IO1: R14.2, X2.43
BTN: R85.2; also elsewhere on the board
CHAN0: X2.5; also elsewhere on the board
CHAN1: X2.6; also elsewhere on the board
CHAN2: X2.7; also elsewhere on the board
CHAN3: X2.8; also elsewhere on the board
CHAN4: X2.9; also elsewhere on the board
CHAN5: X2.10; also elsewhere on the board
CHAN6: X2.11; also elsewhere on the board
CHAN7: X2.12; also elsewhere on the board
CHAN8: X2.13; also elsewhere on the board
CHAN9: X2.14; also elsewhere on the board
CHAN10: X2.15; also elsewhere on the board
CHAN11: X2.16; also elsewhere on the board
CHAN12: X2.25; also elsewhere on the board
CHAN13: X2.26; also elsewhere on the board
CHAN14: X2.27; also elsewhere on the board
CHAN15: X2.28; also elsewhere on the board
CHAN16: X2.29; also elsewhere on the board
CHAN17: X2.30; also elsewhere on the board
CHAN18: X2.31; also elsewhere on the board
CHAN19: X2.32; also elsewhere on the board
CHAN20: X2.33; also elsewhere on the board
CHAN21: X2.34; also elsewhere on the board
CHAN22: X2.35; also elsewhere on the board
CHAN23: X2.36; also elsewhere on the board
CHAN24: X2.37; also elsewhere on the board
CHAN25: X2.38; also elsewhere on the board
CHAN26: X2.39; also elsewhere on the board
CHAN27: X2.40; also elsewhere on the board
CHAN28: X2.41; also elsewhere on the board
CHAN-CLK: X2.4; also elsewhere on the board
GND: D3.A, J1.5, J1.11, LD1.K, LD2.K, R11.1, R13.2, R15.1, R17.2, R86.1, X2.1, X2.3, X2.20, X2.21, X2.23; also elsewhere on the board
JA1: R26.1; also elsewhere on the board
JA2: R27.1; also elsewhere on the board
JA3: R28.1; also elsewhere on the board
JA4: R29.1; also elsewhere on the board
JA7: R30.2; also elsewhere on the board
JA8: R31.2; also elsewhere on the board
JA9: R32.2; also elsewhere on the board
JA10: R33.2; also elsewhere on the board
LED0_B: LD0.1; also elsewhere on the board
LED0_G: LD0.3; also elsewhere on the board
LED0_R: LD0.2; also elsewhere on the board
LED1: R83.1; also elsewhere on the board
LED2: R84.1; also elsewhere on the board
N$BTN: BTN.3 (2), BTN.4 (2), R85.1, R86.2
N$LD0B: LD0.4, R80.2
N$LD0G: LD0.6, R82.2
N$LD0R: LD0.5, R81.2
N$LD1A: LD1.A, R83.2
N$LD2A: LD2.A, R84.2
NODE_P0: R10.1, R11.2, R12.2
NODE_P1: R14.1, R15.2, R16.2
PMOD-1: J1.1, R26.2
PMOD-2: J1.2, R27.2
PMOD-3: J1.3, R28.2
PMOD-4: J1.4, R29.2
PMOD-7: J1.7, R30.1
PMOD-8: J1.8, R31.1
PMOD-9: J1.9, R32.1
PMOD-10: J1.10, R33.1
RST#: X2.24; also elsewhere on the board
VCC1V0: X2.19; also elsewhere on the board
VCC1V8: X2.18; also elsewhere on the board
VCC3V3: BTN.1, BTN.2 (1), J1.6, J1.12, R80.1, R81.1, R82.1, X2.2, X2.17; also elsewhere on the board
VEXT: D2.A, D3.K, X2.44
VU: D2.K, X2.22; also elsewhere on the board

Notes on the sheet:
2026, Christian Tambe. Some rights reserved.
Licensed under a Creative Commons
Attribution-Share-Alike Unported License.
See creativecommons.org/licenses/by-sa/3.0/
Digilent 12-pin Pmod (JA). Pins 1-4 and 7-10 are signals through 200R series resistors; pins 5/11 are GND and 6/12 are VCC3V3 -- so a 2x6 header carries EIGHT signals, not twelve, which is why the names skip JA5/JA6. No decoupling here: the Pmod spec puts bypassing on the module, and VCC3V3 already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
X2: 44 pins on a 2.54 mm grid, rows 0.700 in apart, board 69.85 x 20.32 mm. Numbered right to left and straight through: top row 1-20, bottom row 21-44. TOP ROW, x 59.69 down to 1.27: GND, +3.3V, GND, then CHAN-CLK and CHAN0..CHAN3 (pins 4-8), CHAN4 (pin 9), CHAN5..CHAN11 (10-16), +3.3V, +1.8V, +1.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

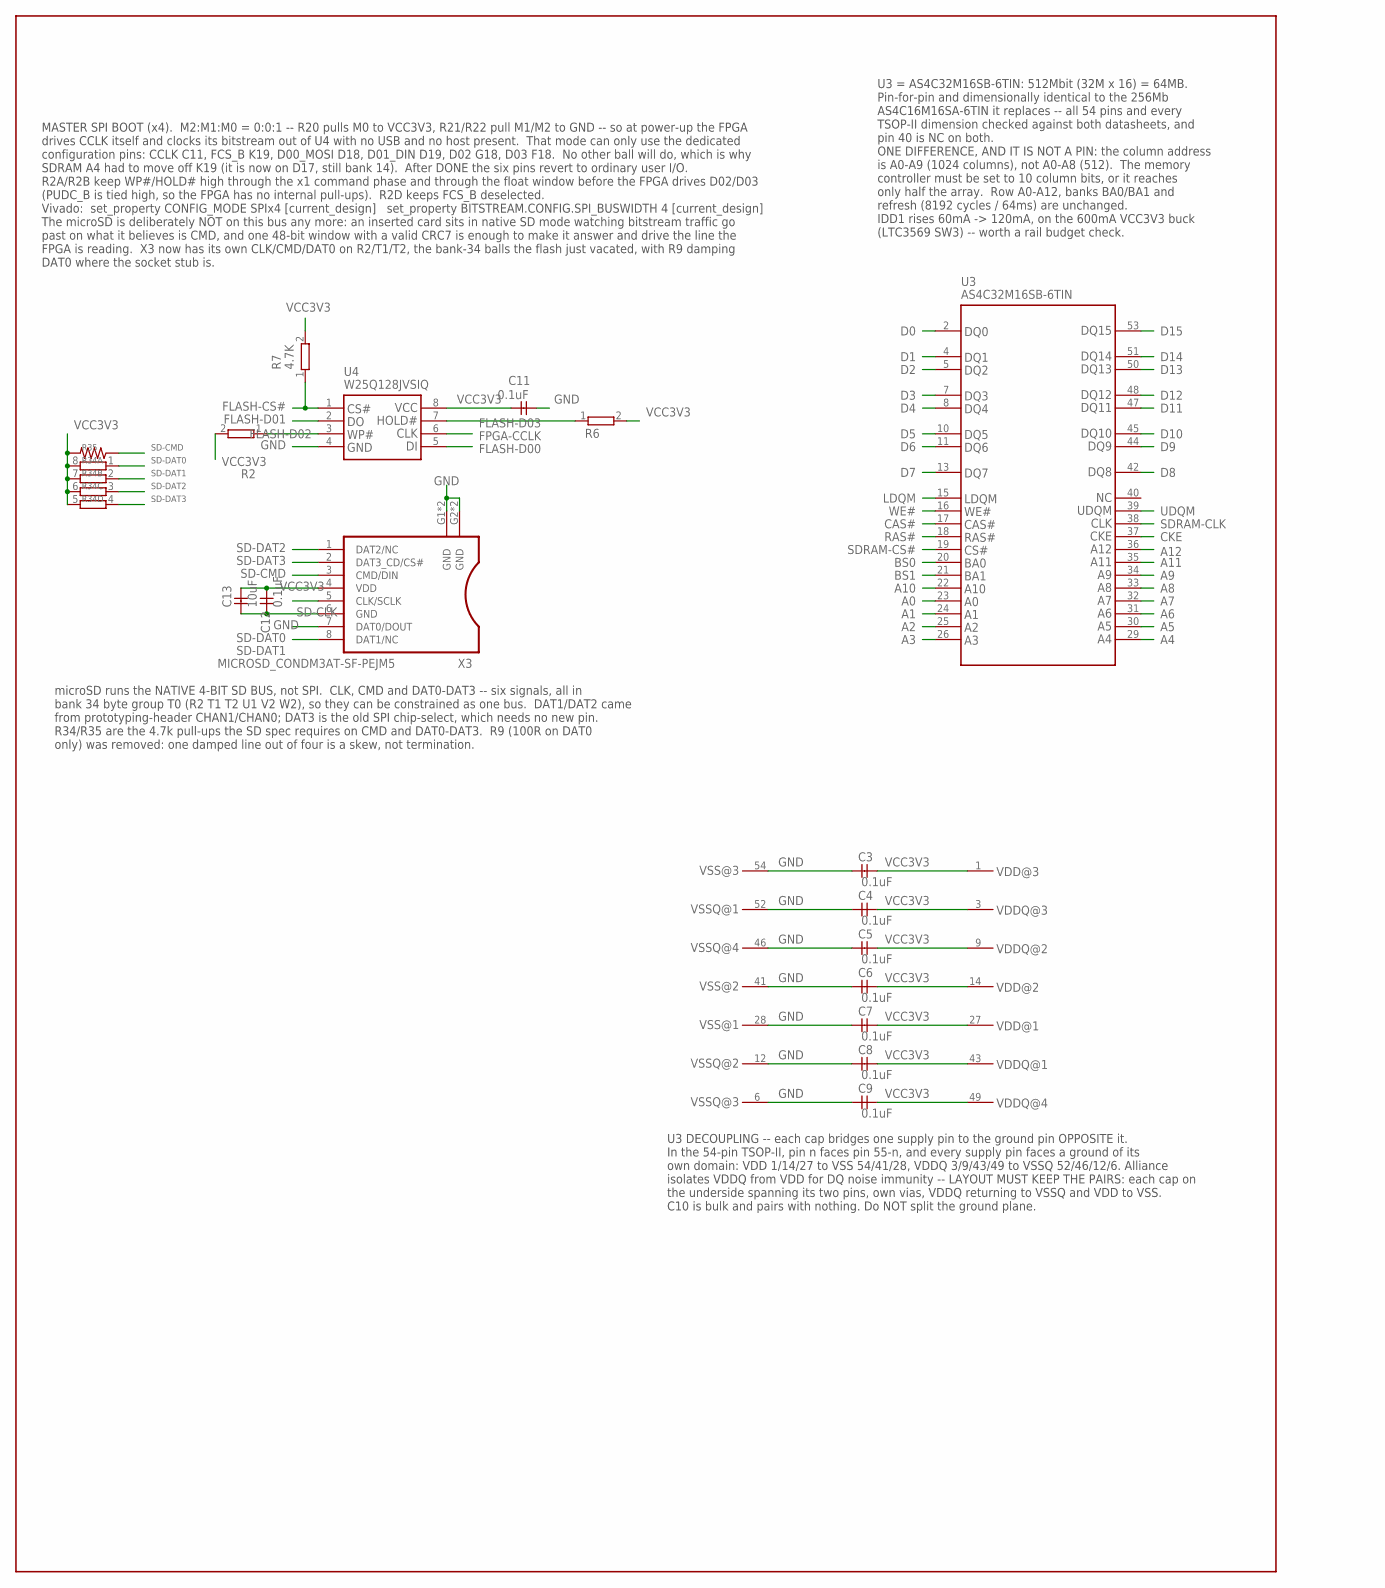
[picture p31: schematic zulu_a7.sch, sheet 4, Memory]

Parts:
C3, C4, C5, C6, C7, C8, C9, C11, C12: 0.1uF; C0402
C13: 10uF; C0603
R2, R6, R7: 4.7K; R0201
R34: 4.7K; 742C083
R35: 4.7K; R0402
U3: AS4C32M16SB-6TIN; TSOPII-54
U4: W25Q128JVSIQ; SOIC-8_208MIL; DIGIKEY# W25Q128JVSIQ-ND
X3: MICROSD_CONDM3AT-SF-PEJM5; DM3AT-SF-PEJM5

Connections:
A0: U3.23; also elsewhere on the board
A1: U3.24; also elsewhere on the board
A2: U3.25; also elsewhere on the board
A3: U3.26; also elsewhere on the board
A4: U3.29; also elsewhere on the board
A5: U3.30; also elsewhere on the board
A6: U3.31; also elsewhere on the board
A7: U3.32; also elsewhere on the board
A8: U3.33; also elsewhere on the board
A9: U3.34; also elsewhere on the board
A10: U3.22; also elsewhere on the board
A11: U3.35; also elsewhere on the board
A12: U3.36; also elsewhere on the board
BS0: U3.20; also elsewhere on the board
BS1: U3.21; also elsewhere on the board
CAS#: U3.17; also elsewhere on the board
CKE: U3.37; also elsewhere on the board
D0: U3.2; also elsewhere on the board
D1: U3.4; also elsewhere on the board
D2: U3.5; also elsewhere on the board
D3: U3.7; also elsewhere on the board
D4: U3.8; also elsewhere on the board
D5: U3.10; also elsewhere on the board
D6: U3.11; also elsewhere on the board
D7: U3.13; also elsewhere on the board
D8: U3.42; also elsewhere on the board
D9: U3.44; also elsewhere on the board
D10: U3.45; also elsewhere on the board
D11: U3.47; also elsewhere on the board
D12: U3.48; also elsewhere on the board
D13: U3.50; also elsewhere on the board
D14: U3.51; also elsewhere on the board
D15: U3.53; also elsewhere on the board
FLASH-CS#: R7.1, U4.1; also elsewhere on the board
FLASH-D00: U4.5; also elsewhere on the board
FLASH-D01: U4.2; also elsewhere on the board
FLASH-D02: R2.1, U4.3; also elsewhere on the board
FLASH-D03: R6.1, U4.7; also elsewhere on the board
FPGA-CCLK: U4.6; also elsewhere on the board
GND: C3.1, C4.1, C5.1, C6.1, C7.1, C8.1, C9.1, C11.1, C12.1, C13.1, U3.6, U3.12, U3.28, U3.41, U3.46, U3.52, U3.54, U4.4, X3.6 (GND), X3.G1 (GND), X3.G2 (GND), X3.G3 (GND), X3.G4 (GND); also elsewhere on the board
LDQM: U3.15; also elsewhere on the board
RAS#: U3.18; also elsewhere on the board
SD-CLK: X3.5 (CLK/SCLK); also elsewhere on the board
SD-CMD: R35.1, X3.3 (CMD/DIN); also elsewhere on the board
SD-DAT0: R34.1, X3.7 (DAT0/DOUT); also elsewhere on the board
SD-DAT1: R34.2 (1), X3.8 (DAT1/NC); also elsewhere on the board
SD-DAT2: R34.3 (1), X3.1 (DAT2/NC); also elsewhere on the board
SD-DAT3: R34.4 (1), X3.2 (DAT3_CD/CS#); also elsewhere on the board
SDRAM-CLK: U3.38; also elsewhere on the board
SDRAM-CS#: U3.19; also elsewhere on the board
UDQM: U3.39; also elsewhere on the board
VCC3V3: C3.2, C4.2, C5.2, C6.2, C7.2, C8.2, C9.2, C11.2, C12.2, C13.2, R2.2, R6.2, R7.2, R34.5 (2), R34.6 (2), R34.7 (2), R34.8 (2), R35.2, U3.1, U3.3, U3.9, U3.14, U3.27, U3.43, U3.49, U4.8, X3.4 (VDD); also elsewhere on the board
WE#: U3.16; also elsewhere on the board

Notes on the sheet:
U3 DECOUPLING -- each cap bridges one supply pin to the ground pin OPPOSITE it. In the 54-pin TSOP-II, pin n faces pin 55-n, and every supply pin faces a ground of its own domain: VDD 1/14/27 to VSS 54/41/28, VDDQ 3/9/43/49 to VSSQ 52/46/12/6. Alliance isolates VDDQ from VDD for DQ noise immunity -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
MASTER SPI BOOT (x4). M2:M1:M0 = 0:0:1 -- R20 pulls M0 to VCC3V3, R21/R22 pull M1/M2 to GND -- so at power-up the FPGA drives CCLK itself and clocks its bitstream out of U4 with no USB and no host present. That mode can only use the dedicated configuration pins: CCLK C11, FCS_B K19, D00_MOSI D18, D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
microSD runs the NATIVE 4-BIT SD BUS, not SPI. CLK, CMD and DAT0-DAT3 -- six signals, all in bank 34 byte group T0 (R2 T1 T2 U1 V2 W2), so they can be constrained as one bus. DAT1/DAT2 came from prototyping-header CHAN1/CHAN0; DAT3 is the old SPI chip-select, which needs no new pin. R34/R35 are the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
U3 = AS4C32M16SB-6TIN: 512Mbit (32M x 16) = 64MB. Pin-for-pin and dimensionally identical to the 256Mb AS4C16M16SA-6TIN it replaces -- all 54 pins and every TSOP-II dimension checked against both datasheets, and pin 40 is NC on both. ONE DIFFERENCE, AND IT IS NOT A PIN: the column address is A0-A9 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


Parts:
C38: 0.01uF; C0201
C39, C139: 3.3uF; C0402
C40, C41: 100nF; C0201
C133, C134, C135, C136, C137, C138: 0.1uF; C0201
JP3: JTAG TCK/TMS/GND; 1X03-NOSILK
JP4: JTAG TDI/TDO/3V3; 1X03-NOSILK
L4, L5: FB 600R@100MHz; IND0603
Q1: 12MHz 25ppm (FPGA + FT2232HQ); 32X25
R1, R3: 4.7K; R0201
R4, R8, R9, R36, R37, R38: 100; R0402
R5: 5.1K; R0201; MOUSER# 301-5.1K-RC
R18: 12K 1%; R0402
R19, R89, R90, R91, R92, R93, R94: 10K; R0201
R24, R25: 33; R0201
R96, R97, R98: 10k; R0201
R99: 4.7k; R0201
R100: 330; R0402
R101: 2.21k; R0201
U2: FT2232HQ USB-UART/JTAG Bridge; FT2232HQ-QFN64
U10: 93LC46BT-I/SN; SOIC8

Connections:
CLK-12M-FPGA: R25.2; also elsewhere on the board
CLK-12M-FT: R24.2, U2.2 (OSCI)
CLK-12M-SHARED: Q1.3, R24.1, R25.1
DONE: R38.1, R100.1, U2.22 (ADBUS5)
EE-CLK: R96.1, U2.62 (EECLK), U10.2 (CLK)
EE-CS: R98.1, U2.63 (EECS), U10.1 (CS)
EE-DATA: R101.2, U2.61 (EEDATA), U10.3 (DI)
EE-DATA-DO: R97.1, R101.1, U10.4 (DO)
FPGA-DONE: R38.2; also elsewhere on the board
FPGA-INIT#: R1.1; also elsewhere on the board
FPGA-TCK: R5.2, R36.2; also elsewhere on the board
FPGA-TDI: R8.2; also elsewhere on the board
FPGA-TDO: R37.2; also elsewhere on the board
FPGA-TMS: R4.2; also elsewhere on the board
FT-PWREN#: U2.60 (PWREN#); also elsewhere on the board
FT-REF: R18.2, U2.6 (REF)
FT-RESETN: R19.1, U2.14 (RESET#)
FT-VCORE: C39.2, C139.2, U2.12 (VCORE), U2.37 (VCORE), U2.49 (VREGOUT), U2.64 (VCORE)
FT-VPHY: C40.2, L4.1, U2.4 (VPHY)
FT-VPLL: C41.2, L5.1, U2.9 (VPLL)
GND: C38.1, C39.1, C40.1, C41.1, C133.1, C134.1, C135.1, C136.1, C137.1, C138.1, C139.1, JP3.3, Q1.2, R3.2, R5.1, R18.1, U2.1 (GND), U2.5 (GND), U2.10 (AGND), U2.11 (GND), U2.13 (TEST), U2.15 (GND), U2.25 (GND), U2.35 (GND), U2.47 (GND), U2.51 (GND), U2.EP, U10.5 (VSS); also elsewhere on the board
PROG#: R9.1, R99.1, U2.21 (ADBUS4)
RST#: R3.1, R9.2; also elsewhere on the board
TCK: JP3.1, R36.1, R89.1, U2.16 (ADBUS0)
TDI: JP4.1, R8.1, R90.1, U2.17 (ADBUS1)
TDO: JP4.2, R37.1, R91.1, U2.18 (ADBUS2)
TMS: JP3.2, R4.1, R92.1, U2.19 (ADBUS3)
UART_FT_CTS#: R93.1, U2.41 (BDBUS3); also elsewhere on the board
UART_FT_DTR#: U2.43 (BDBUS4); also elsewhere on the board
UART_FT_RTS#: U2.40 (BDBUS2); also elsewhere on the board
UART_FT_RXD: R94.1, U2.39 (BDBUS1); also elsewhere on the board
UART_FT_TXD: U2.38 (BDBUS0); also elsewhere on the board
USB_D_N: U2.7 (DM); also elsewhere on the board
USB_D_P: U2.8 (DP); also elsewhere on the board
VCC3V3: C38.2, C133.2, C134.2, C135.2, C136.2, C137.2, C138.2, JP4.3, L4.2, L5.2, Q1.1, Q1.4, R1.2, R19.2, R89.2, R90.2, R91.2, R92.2, R93.2, R94.2, R96.2, R97.2, R98.2, R99.2, R100.2, U2.20 (VCCIO), U2.31 (VCCIO), U2.42 (VCCIO), U2.50 (VREGIN), U2.56 (VCCIO), U10.8 (VCC); also elsewhere on the board

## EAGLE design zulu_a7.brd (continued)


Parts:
C123: 100nF; C0402
C124: 470nF; C0402
L6, L7: FB 600R@100MHz; IND0603
R20, R21, R22, R23: 1K; R0402
U1: XC7A35T-1CPG236C; XC7A35T-CPG236

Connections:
A0: U1.U2 (1); also elsewhere on the board
A1: U1.T3 (1); also elsewhere on the board
A2: U1.T2 (1); also elsewhere on the board
A3: U1.T1 (1); also elsewhere on the board
A4: U1.R3 (1); also elsewhere on the board
A5: U1.R2 (1); also elsewhere on the board
A6: U1.P3 (1); also elsewhere on the board
A7: U1.P1 (1); also elsewhere on the board
A8: U1.N3 (1); also elsewhere on the board
A9: U1.N2 (1); also elsewhere on the board
A10: U1.U3 (1); also elsewhere on the board
A11: U1.N1 (1); also elsewhere on the board
A12: U1.M3 (1); also elsewhere on the board
AIN15_N: U1.G2 (1); also elsewhere on the board
AIN15_P: U1.G3 (1); also elsewhere on the board
AIN16_N: U1.J2 (1); also elsewhere on the board
AIN16_P: U1.H2 (1); also elsewhere on the board
BS0: U1.V2 (1); also elsewhere on the board
BS1: U1.U1 (1); also elsewhere on the board
BTN: U1.N17 (1); also elsewhere on the board
CAS#: U1.W3 (1); also elsewhere on the board
CFG-M0: R20.1, U1.V12 (1)
CFG-M1: R21.2, U1.W11 (1)
CFG-M2: R22.2, U1.U10 (1)
CHAN0: U1.B18 (1); also elsewhere on the board
CHAN1: U1.A18 (1); also elsewhere on the board
CHAN2: U1.B17 (1); also elsewhere on the board
CHAN3: U1.A17 (1); also elsewhere on the board
CHAN4: U1.C16 (1); also elsewhere on the board
CHAN5: U1.D17 (1); also elsewhere on the board
CHAN6: U1.H17 (1); also elsewhere on the board
CHAN7: U1.H19 (1); also elsewhere on the board
CHAN8: U1.J18 (1); also elsewhere on the board
CHAN9: U1.J17 (1); also elsewhere on the board
CHAN10: U1.J19 (1); also elsewhere on the board
CHAN11: U1.K17 (1); also elsewhere on the board
CHAN12: U1.W19 (1); also elsewhere on the board
CHAN13: U1.W18 (1); also elsewhere on the board
CHAN14: U1.W17 (1); also elsewhere on the board
CHAN15: U1.V17 (1); also elsewhere on the board
CHAN16: U1.W16 (1); also elsewhere on the board
CHAN17: U1.U16 (1); also elsewhere on the board
CHAN18: U1.V16 (1); also elsewhere on the board
CHAN19: U1.W15 (1); also elsewhere on the board
CHAN20: U1.V15 (1); also elsewhere on the board
CHAN21: U1.U15 (1); also elsewhere on the board
CHAN22: U1.W14 (1); also elsewhere on the board
CHAN23: U1.V14 (1); also elsewhere on the board
CHAN24: U1.U14 (1); also elsewhere on the board
CHAN25: U1.W13 (1); also elsewhere on the board
CHAN26: U1.V13 (1); also elsewhere on the board
CHAN27: U1.T18 (1); also elsewhere on the board
CHAN28: U1.R19 (1); also elsewhere on the board
CHAN-CLK: U1.P18 (1); also elsewhere on the board
CKE: U1.M2 (1); also elsewhere on the board
CLK-12M-FPGA: U1.L17 (1); also elsewhere on the board
D0: U1.V8 (1); also elsewhere on the board
D1: U1.V7 (1); also elsewhere on the board
D2: U1.W7 (1); also elsewhere on the board
D3: U1.W6 (1); also elsewhere on the board
D4: U1.U5 (1); also elsewhere on the board
D5: U1.W5 (1); also elsewhere on the board
D6: U1.V5 (1); also elsewhere on the board
D7: U1.U4 (1); also elsewhere on the board
D8: U1.L1 (1); also elsewhere on the board
D9: U1.K3 (1); also elsewhere on the board
D10: U1.K2 (1); also elsewhere on the board
D11: U1.J1 (1); also elsewhere on the board
D12: U1.J3 (1); also elsewhere on the board
D13: U1.H1 (1); also elsewhere on the board
D14: U1.A14 (1); also elsewhere on the board
D15: U1.A15 (1); also elsewhere on the board
FLASH-CS#: U1.K19 (1); also elsewhere on the board
FLASH-D00: U1.D18 (1); also elsewhere on the board
FLASH-D01: U1.D19 (1); also elsewhere on the board
FLASH-D02: U1.G18 (1); also elsewhere on the board
FLASH-D03: U1.F18 (1); also elsewhere on the board
FPGA-CCLK: U1.C11 (1); also elsewhere on the board
FPGA-DONE: U1.U12 (1); also elsewhere on the board
FPGA-INIT#: U1.U11 (1); also elsewhere on the board
FPGA-TCK: U1.C8 (1); also elsewhere on the board
FPGA-TDI: U1.W10 (1); also elsewhere on the board
FPGA-TDO: U1.W8 (1); also elsewhere on the board
FPGA-TMS: U1.W9 (1); also elsewhere on the board
FT-PWREN#: U1.P17 (1); also elsewhere on the board
GND: C124.2, L6.1, R21.1, R22.1, U1.A4 (1), U1.A6 (1), U1.A11 (1), U1.B4 (1), U1.B6 (1), U1.B11 (1); also elsewhere on the board
GNDADC: C123.2, L6.2, U1.A12 (1), U1.A13 (1), U1.B12 (1), U1.B13 (1), U1.C12 (1)
JA1: U1.U18 (1); also elsewhere on the board
JA2: U1.U19 (1); also elsewhere on the board
JA3: U1.G17 (1); also elsewhere on the board
JA4: U1.C17 (1); also elsewhere on the board
JA7: U1.T17 (1); also elsewhere on the board
JA8: U1.E19 (1); also elsewhere on the board
JA9: U1.V19 (1); also elsewhere on the board
JA10: U1.U17 (1); also elsewhere on the board
LDQM: U1.W4 (1); also elsewhere on the board
LED0_B: U1.N19 (1); also elsewhere on the board
LED0_G: U1.R18 (1); also elsewhere on the board
LED0_R: U1.P19 (1); also elsewhere on the board
LED1: U1.N18 (1); also elsewhere on the board
LED2: U1.M19 (1); also elsewhere on the board
PUDC_B: R23.2, U1.E18 (1)
RAS#: U1.V3 (1); also elsewhere on the board
RST#: U1.V10 (1); also elsewhere on the board
SD-CLK: U1.U8 (1); also elsewhere on the board
SD-CMD: U1.U7 (1); also elsewhere on the board
SD-DAT0: U1.C15 (1); also elsewhere on the board
SD-DAT1: U1.B15 (1); also elsewhere on the board
SD-DAT2: U1.L3 (1); also elsewhere on the board
SD-DAT3: U1.A16 (1); also elsewhere on the board
SDRAM-CLK: U1.M1 (1); also elsewhere on the board
SDRAM-CS#: U1.W2 (1); also elsewhere on the board
UART_FT_CTS#: U1.B16 (1); also elsewhere on the board
UART_FT_DTR#: U1.M18 (1); also elsewhere on the board
UART_FT_RTS#: U1.L18 (1); also elsewhere on the board
UART_FT_RXD: U1.G19 (1); also elsewhere on the board
UART_FT_TXD: U1.K18 (1); also elsewhere on the board
UDQM: U1.L2 (1); also elsewhere on the board
VCC1V8: L7.1; also elsewhere on the board
VCC3V3: R20.2, R23.1, U1.V11 (1); also elsewhere on the board
VCCADC: C123.1, C124.1, L7.2, U1.C13 (1)
WE#: U1.V4 (1); also elsewhere on the board

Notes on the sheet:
SDRAM
PROTOTYPING HEADER
JTAG
FLASH
CONFIG
V11 CFGBVS_0
E18 IO_L3P_T0_DQS_PUDC_B_14
C8 TCK_0
W8 TDO_0
W9 TMS_0
W10 TDI_0
U12 DONE_0
G17 IO_L5N_T0_D07_14
D19 IO_L1N_T0_D01_DIN_14
C11 CCLK_0
D18 IO_L1P_T0_D00_MOSI_14
W2 IO_L5N_T0_34
V2 IO_L5P_T0_34
W3 IO_L6N_T0_VREF_34
V3 IO_L6P_T0_34
W5 IO_L12P_T1_MRCC_34
V4 IO_L11N_T1_SRCC_34
U4 IO_L11P_T1_SRCC_34
V5 IO_L16N_T2_34
W4 IO_L12N_T1_MRCC_34
U5 IO_L16P_T2_34
U2 IO_L9N_T1_DQS_34
W6 IO_L13N_T2_MRCC_34
U3 IO_L9P_T1_DQS_34
U7 IO_L19P_T3_34
M3 IO_L8N_T1_AD14N_35
R18 IO_L14N_T2_SRCC_14
U8 IO_L14P_T2_SRCC_34
V8 IO_L14N_T2_SRCC_34
R3 IO_L2P_T0_34
V7 IO_L19N_T3_VREF_34
H1 IO_L3P_T0_DQS_AD5P_35
J1 IO_L3N_T0_DQS_AD5N_35
J3 IO_L7P_T1_AD6P_35
K2 IO_L5P_T0_AD13P_35


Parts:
C85, C86, C93, C97, C98, C140, C141, C142, C143, C144, C145, C146: 22uF; C0805
C87, C88, C94, C99, C100, C101, C102, C103, C104, C105, C106: 4.7uF; C0603
C89, C90, C91, C92, C95, C96, C107, C108, C109, C110, C111, C112, C113, C114, C115, C116, C117, C118, C119, C120, C121, C122: 0.47uF; C0201
U1: XC7A35T-1CPG236C; XC7A35T-CPG236

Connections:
GND: C85.2, C86.2, C87.2, C88.2, C89.2, C90.2, C91.2, C92.2, C93.2, C94.2, C95.2, C96.2, C97.2, C98.2, C99.2, C100.2, C101.2, C102.2, C103.2, C104.2, C105.2, C106.2, C107.2, C108.2, C109.2, C110.2, C111.2, C112.2, C113.2, C114.2, C115.2, C116.2, C117.2, C118.2, C119.2, C120.2, C121.2, C122.2, C140.2, C141.2, C142.2, C143.2, C144.2, C145.2, C146.2, U1.A1 (GND), U1.A3 (GND), U1.A5 (GND), U1.A7 (GND), U1.A9 (GND), U1.A19 (GND), U1.B1 (MGTAVTT), U1.B3 (GND), U1.B5 (GND), U1.B7 (GND), U1.B9 (GND), U1.B14 (GND), U1.C1 (MGTAVCC), U1.C2 (GND), U1.C3 (GND), U1.C4 (GND), U1.C5 (MGTAVTT), U1.C6 (GND), U1.C7 (MGTRREF), U1.C10 (GND), U1.C19 (GND), U1.D3 (GND), U1.E1 (MGTAVCC), U1.E2 (MGTAVTT), U1.E3 (GND), U1.E17 (GND), U1.F1 (GND), U1.F2 (GND), U1.F3 (MGTAVCC), U1.F19 (GND), U1.G1 (GND), U1.G7 (MGTAVTT), U1.G8 (GND), U1.G9 (MGTAVCC), U1.G11 (GND), U1.H7 (GND), U1.H8 (GND), U1.H9 (MGTAVCC), U1.H11 (GND), U1.H12 (GND), U1.H18 (GND), U1.J8 (GND), U1.J9 (GND), U1.J11 (GND), U1.J12 (GND), U1.K8 (GND), U1.L8 (GND), U1.L9 (GND), U1.L11 (GND), U1.L19 (GND), U1.M9 (GND), U1.M13 (GND), U1.N9 (GND), U1.N12 (GND), U1.N13 (GND), U1.P2 (GND), U1.T19 (GND), U1.U6 (GND), U1.U9 (GND), U1.V18 (GND), U1.W1 (GND), U1.W12 (GND); also elsewhere on the board
VCC1V0: C85.1, C86.1, C87.1, C88.1, C89.1, C90.1, C91.1, C92.1, C140.1, C141.1, C142.1, C143.1, U1.G10 (VCCINT), U1.H10 (VCCINT), U1.J10 (VCCINT), U1.L10 (VCCINT), U1.M10 (VCCINT), U1.M11 (VCCBRAM), U1.N10 (VCCINT), U1.N11 (VCCBRAM); also elsewhere on the board
VCC1V8: C93.1, C94.1, C95.1, C96.1, C144.1, U1.C9 (VCCBATT), U1.H13 (VCCAUX), U1.J13 (VCCAUX); also elsewhere on the board
VCC3V3: C97.1, C98.1, C99.1, C100.1, C101.1, C102.1, C103.1, C104.1, C105.1, C106.1, C107.1, C108.1, C109.1, C110.1, C111.1, C112.1, C113.1, C114.1, C115.1, C116.1, C117.1, C118.1, C119.1, C120.1, C121.1, C122.1, C145.1, C146.1, U1.B19 (VCCO_16), U1.C14 (VCCO_16), U1.C18 (VCCO_16), U1.F17 (VCCO_14), U1.G12 (VCCO_0), U1.G13 (VCCO_16), U1.H3 (VCCO_35), U1.J7 (VCCO_35), U1.K1 (VCCO_35), U1.K7 (VCCO_35), U1.K12 (VCCO_14), U1.K13 (VCCO_14), U1.L7 (VCCO_35), U1.L12 (VCCO_14), U1.L13 (VCCO_14), U1.M7 (VCCO_35), U1.M8 (VCCO_34), U1.M12 (VCCO_14), U1.M17 (VCCO_14), U1.N7 (VCCO_34), U1.N8 (VCCO_34), U1.R1 (VCCO_34), U1.R17 (VCCO_14), U1.U13 (VCCO_14), U1.V1 (VCCO_34), U1.V6 (VCCO_34), U1.V9 (VCCO_0); also elsewhere on the board

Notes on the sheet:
VCCAUX — 1x47uF, 1x4.7uF, 2x0.47uF
These three gates are U1 itself -- the same XC7A35T-CPG236 whose I/O are on sheet 6. VCCO pins are named for the bank they feed (bank 14 has nine supply balls, bank 0 only two). BANK216 holds the unused transceiver supplies; UG482 requires MGTAVCC/MGTAVTT/MGTRREF tied to GND when the GTPs are unuse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
BANK 0 VCCO -- 1x47uF (UG483 T2-2)
BANK 14 VCCO -- 4x0.47uF, 2x4.7uF, 1x47uF (UG483 T2-2)
BANK 16 VCCO -- 4x0.47uF, 2x4.7uF (UG483 T2-2)
BANK 34 VCCO -- 4x0.47uF, 2x4.7uF (UG483 T2-2)
BANK 35 VCCO -- 4x0.47uF, 2x4.7uF (UG483 T2-2)
VCCINT
VCCBRAM
VCCINT -- 3x0.47uF, 1x100uF, 2x4.7uF (UG483 T2-2)
VCCBRAM -- 1x0.47uF, 1x47uF (UG483 T2-2)



Board: 6 copper layers, 61.0 x 25.4 mm, 183 parts (89 on the bottom side), 175 nets.

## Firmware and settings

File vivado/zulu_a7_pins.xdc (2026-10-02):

# generated from zulu_a7.sch -- ball assignments exactly as drawn
set_property CFGBVS VCCO [current_design]
set_property CONFIG_VOLTAGE 3.3 [current_design]
set_property CONFIG_MODE SPIx4 [current_design]

set_property -dict {PACKAGE_PIN U2   IOSTANDARD LVCMOS33} [get_ports {A0}]  ;# A0  bank 34  IO_L9N_T1_DQS_34
set_property -dict {PACKAGE_PIN T3   IOSTANDARD LVCMOS33} [get_ports {A1}]  ;# A1  bank 34  IO_L2N_T0_34
set_property -dict {PACKAGE_PIN U3   IOSTANDARD LVCMOS33} [get_ports {A10}]  ;# A10  bank 34  IO_L9P_T1_DQS_34
set_property -dict {PACKAGE_PIN N1   IOSTANDARD LVCMOS33} [get_ports {A11}]  ;# A11  bank 35  IO_L10N_T1_AD15N_35
set_property -dict {PACKAGE_PIN M3   IOSTANDARD LVCMOS33} [get_ports {A12}]  ;# A12  bank 35  IO_L8N_T1_AD14N_35
set_property -dict {PACKAGE_PIN T2   IOSTANDARD LVCMOS33} [get_ports {A2}]  ;# A2  bank 34  IO_L1N_T0_34
set_property -dict {PACKAGE_PIN T1   IOSTANDARD LVCMOS33} [get_ports {A3}]  ;# A3  bank 34  IO_L3P_T0_DQS_34
set_property -dict {PACKAGE_PIN R3   IOSTANDARD LVCMOS33} [get_ports {A4}]  ;# A4  bank 34  IO_L2P_T0_34
set_property -dict {PACKAGE_PIN R2   IOSTANDARD LVCMOS33} [get_ports {A5}]  ;# A5  bank 34  IO_L1P_T0_34
set_property -dict {PACKAGE_PIN P3   IOSTANDARD LVCMOS33} [get_ports {A6}]  ;# A6  bank 35  IO_L12N_T1_MRCC_35
set_property -dict {PACKAGE_PIN P1   IOSTANDARD LVCMOS33} [get_ports {A7}]  ;# A7  bank 35  IO_L19N_T3_VREF_35
set_property -dict {PACKAGE_PIN N3   IOSTANDARD LVCMOS33} [get_ports {A8}]  ;# A8  bank 35  IO_L12P_T1_MRCC_35
set_property -dict {PACKAGE_PIN N2   IOSTANDARD LVCMOS33} [get_ports {A9}]  ;# A9  bank 35  IO_L10P_T1_AD15P_35
set_property -dict {PACKAGE_PIN V2   IOSTANDARD LVCMOS33} [get_ports {BS0}]  ;# BS0  bank 34  IO_L5P_T0_34
set_property -dict {PACKAGE_PIN U1   IOSTANDARD LVCMOS33} [get_ports {BS1}]  ;# BS1  bank 34  IO_L3N_T0_DQS_34
set_property -dict {PACKAGE_PIN N19  IOSTANDARD LVCMOS33} [get_ports {BTN}]  ;# BTN  bank 14  IO_L9N_T1_DQS_D13_14
set_property -dict {PACKAGE_PIN W3   IOSTANDARD LVCMOS33} [get_ports {CAS_N}]  ;# CAS#  bank 34  IO_L6N_T0_VREF_34
set_property -dict {PACKAGE_PIN B18  IOSTANDARD LVCMOS33} [get_ports {CHAN0}]  ;# CHAN0  bank 16  IO_L19P_T3_16
set_property -dict {PACKAGE_PIN A18  IOSTANDARD LVCMOS33} [get_ports {CHAN1}]  ;# CHAN1  bank 16  IO_L19N_T3_VREF_16
set_property -dict {PACKAGE_PIN J19  IOSTANDARD LVCMOS33} [get_ports {CHAN10}]  ;# CHAN10  bank 14  IO_L6N_T0_D08_VREF_14
set_property -dict {PACKAGE_PIN K18  IOSTANDARD LVCMOS33} [get_ports {CHAN11}]  ;# CHAN11  bank 14  IO_L8N_T1_D12_14
set_property -dict {PACKAGE_PIN E19  IOSTANDARD LVCMOS33} [get_ports {CHAN12}]  ;# CHAN12  bank 14  IO_L3N_T0_DQS_EMCCLK_14
set_property -dict {PACKAGE_PIN H19  IOSTANDARD LVCMOS33} [get_ports {CHAN13}]  ;# CHAN13  bank 14  IO_L4P_T0_D04_14
set_property -dict {PACKAGE_PIN W17  IOSTANDARD LVCMOS33} [get_ports {CHAN14}]  ;# CHAN14  bank 14  IO_L20N_T3_A07_D23_14
set_property -dict {PACKAGE_PIN V17  IOSTANDARD LVCMOS33} [get_ports {CHAN15}]  ;# CHAN15  bank 14  IO_L19N_T3_A09_D25_VREF_14
set_property -dict {PACKAGE_PIN W16  IOSTANDARD LVCMOS33} [get_ports {CHAN16}]  ;# CHAN16  bank 14  IO_L20P_T3_A08_D24_14
set_property -dict {PACKAGE_PIN U16  IOSTANDARD LVCMOS33} [get_ports {CHAN17}]  ;# CHAN17  bank 14  IO_L23N_T3_A02_D18_14
set_property -dict {PACKAGE_PIN V16  IOSTANDARD LVCMOS33} [get_ports {CHAN18}]  ;# CHAN18  bank 14  IO_L19P_T3_A10_D26_14
set_property -dict {PACKAGE_PIN W15  IOSTANDARD LVCMOS33} [get_ports {CHAN19}]  ;# CHAN19  bank 14  IO_L21N_T3_DQS_A06_D22_14
set_property -dict {PACKAGE_PIN B17  IOSTANDARD LVCMOS33} [get_ports {CHAN2}]  ;# CHAN2  bank 16  IO_L14N_T2_SRCC_16
set_property -dict {PACKAGE_PIN V15  IOSTANDARD LVCMOS33} [get_ports {CHAN20}]  ;# CHAN20  bank 14  IO_L21P_T3_DQS_14
set_property -dict {PACKAGE_PIN U15  IOSTANDARD LVCMOS33} [get_ports {CHAN21}]  ;# CHAN21  bank 14  IO_L23P_T3_A03_D19_14
set_property -dict {PACKAGE_PIN W14  IOSTANDARD LVCMOS33} [get_ports {CHAN22}]  ;# CHAN22  bank 14  IO_L22N_T3_A04_D20_14
set_property -dict {PACKAGE_PIN V14  IOSTANDARD LVCMOS33} [get_ports {CHAN23}]  ;# CHAN23  bank 14  IO_L24N_T3_A00_D16_14
set_property -dict {PACKAGE_PIN U14  IOSTANDARD LVCMOS33} [get_ports {CHAN24}]  ;# CHAN24  bank 14  IO_25_14
set_property -dict {PACKAGE_PIN W13  IOSTANDARD LVCMOS33} [get_ports {CHAN25}]  ;# CHAN25  bank 14  IO_L22P_T3_A05_D21_14
set_property -dict {PACKAGE_PIN V13  IOSTANDARD LVCMOS33} [get_ports {CHAN26}]  ;# CHAN26  bank 14  IO_L24P_T3_A01_D17_14
set_property -dict {PACKAGE_PIN T18  IOSTANDARD LVCMOS33} [get_ports {CHAN27}]  ;# CHAN27  bank 14  IO_L17N_T2_A13_D29_14
set_property -dict {PACKAGE_PIN T17  IOSTANDARD LVCMOS33} [get_ports {CHAN28}]  ;# CHAN28  bank 14  IO_L17P_T2_A14_D30_14
set_property -dict {PACKAGE_PIN A17  IOSTANDARD LVCMOS33} [get_ports {CHAN3}]  ;# CHAN3  bank 16  IO_L12N_T1_MRCC_16
set_property -dict {PACKAGE_PIN C16  IOSTANDARD LVCMOS33} [get_ports {CHAN4}]  ;# CHAN4  bank 16  IO_L13P_T2_MRCC_16
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

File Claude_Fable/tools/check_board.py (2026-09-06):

# -*- coding: utf-8 -*-
"""Check zulu_a7.brd against zulu_a7.sch, and report routing progress.

    python tools/check_board.py [board.brd [schematic.sch]]

WHY THIS EXISTS. Fusion links a schematic to a PCB through an Electronics
Design container, not by filename the way classic Eagle did. Editing the two
files loose on disk -- which is what keeps everything in tools/ working, since
they all read from Zulu_A7 -- means Fusion never runs its own consistency
check on them. This is that check, done from the outside.

It shares no code with tools/make_board.py on purpose. Both sides are rebuilt
from the files, so a bug in the generator cannot hide behind a matching bug in
the checker.

WHAT IT CHECKS

  1  structure      both files parse, versions and outline
  2  parts          every part with a package has exactly one element of that
                    package; parts without one (frames, supply symbols) have none
  3  nets           every net is a signal, and its set of (element, pad) pairs
                    matches what the deviceset's <connect> entries say -- including
                    pins that map to several pads, like the microSD shield tabs
  4  pads           every contactref names a pad that exists in that package
  5  libraries      the board's copy of each package still matches the schematic's,
                    so a footprint edited in one file cannot drift from the other
  6  placement      what is on the board, what is parked outside it, what overlaps
  7  rules          layer setup and the design rules actually loaded
  8  routing        how much is routed, and what is not

The exit code is the number of findings, so it can gate a commit.
"""

import re, io, os, sys, math, collections

sys.path.insert(0, os.path.dirname(os.path.abspath(__file__)))
# One via parser for the whole toolchain. check_board was self-contained until
# a board came back from Fusion with 868 vias written as open tags with no
# diameter, which every private regex here read as zero.
import geom as G   # noqa: E402

# KEEP THE OLD WRAPPER ALIVE. Several of these modules rebind sys.stdout to a
# utf-8 TextIOWrapper over sys.stdout.buffer. Import two of them and the first
# wrapper loses its last reference, gets collected, and CLOSES THE SHARED
# BUFFER on the way out -- every subsequent print dies with 'I/O operation on
# closed file'. It only bit once check_board started importing geom.
_prev_stdout = sys.stdout
sys.stdout = io.TextIOWrapper(sys.stdout.buffer, encoding="utf-8", errors="replace")
ROOT = os.path.normpath(os.path.join(os.path.dirname(os.path.abspath(__file__)), ".."))
findings = []


def head(s):
    print("\n" + s + "\n" + "-" * len(s))


def ok(s):
    print("  PASS  " + s)


def bad(s):
    findings.append(s)
    print("  ****  " + s)


def note(s):
    """Something true and deliberate that would otherwise read as a finding."""
    print("  ----  " + s)


def pads_of(src):
    return {m.group(1): (float(m.group(2)), float(m.group(3)))
            for m in re.finditer(r'<(?:pad|smd) name="([^"]+)" x="([-\d.]+)" y="([-\d.]+)"', src)}


# Eagle writes a design rule as a length with its unit attached, and which unit
# depends on what the tool last saved in: "0.0762mm", "3mil", "0.003in" are one
# value written three ways. Compare millimetres.
_UNITS = (("mil", 0.0254), ("mm", 1.0), ("inch", 25.4), ("in", 25.4))


def _mm(v):
    t = str(v).strip().lower()
    for suf, k in _UNITS:
        if t.endswith(suf):
            try:
                return float(t[:-len(suf)]) * k
            except ValueError:
                return float("nan")
    try:
        return float(t)            # bare number: Eagle means mm
    except ValueError:
        return float("nan")


def main(brdpath, schpath):
    s = open(schpath, encoding="utf-8").read()
    b = open(brdpath, encoding="utf-8").read()

    head("1. Structure")
    try:
        import xml.etree.ElementTree as ET
        ET.fromstring(s); ET.fromstring(b)
        ok("both files parse as XML")
    except Exception as e:
        bad("XML: %s" % e); return len(findings)
    if "<schematic" not in s:
        bad("%s is not a schematic" % schpath)
    if "<board>" not in b:
        bad("%s is not a board" % brdpath)
    seg = [tuple(map(float, m.groups())) for m in re.finditer(
        r'<wire x1="([-\d.]+)" y1="([-\d.]+)" x2="([-\d.]+)" y2="([-\d.]+)"[^>]*layer="20"', b)]
    if not seg:
        bad("no board outline on layer 20")
        BX0 = BY0 = BX1 = BY1 = 0.0
    else:
        xs = [c for w in seg for c in (w[0], w[2])]; ys = [c for w in seg for c in (w[1], w[3])]
        BX0, BY0, BX1, BY1 = min(xs), min(ys), max(xs), max(ys)
        ok("outline %.2f x %.2f mm = %.3f x %.3f in, %d segments on layer 20"
           % (BX1 - BX0, BY1 - BY0, (BX1 - BX0) / 25.4, (BY1 - BY0) / 25.4, len(seg)))

    # --- schematic model, rebuilt from scratch ------------------------------
    slib = {m.group(1): m.group(2) for m in re.finditer(r'<library name="([^"]+)">(.*?)</library>', s, re.S)}
    spkg = {}
    for L, body in slib.items():
        pm = re.search(r"<packages>(.*?)</packages>", body, re.S)
        if pm:
            for p in re.finditer(r'<package name="([^"]+)"[^>]*>(.*?)</package>', pm.group(1), re.S):
                spkg[(L, p.group(1))] = p.group(2)
    dev = {}
    for L, body in slib.items():
        for dm in re.finditer(r'<deviceset name="([^"]+)"[^>]*>(.*?)</deviceset>', body, re.S):
            for dv in re.finditer(r'<device name="([^"]*)"(?: package="([^"]+)")?>(.*?)</device>',
                                  dm.group(2), re.S):
                dev[(L, dm.group(1), dv.group(1))] = (dv.group(2), {
                    (g, p): pd.split() for g, p, pd in
                    re.findall(r'<connect gate="([^"]+)" pin="([^"]+)" pad="([^"]+)"/>', dv.group(3))})
    part = {m.group(1): (m.group(2), m.group(3), m.group(4)) for m in
            re.finditer(r'<part name="([^"]+)" library="([^"]+)" deviceset="([^"]+)" device="([^"]*)"', s)}
    want = {p: dev[k][0] for p, k in part.items() if dev.get(k, (None,))[0]}
    snet = collections.defaultdict(set)
    for m in re.finditer(r'<net name="([^"]+)" class="[^"]*">(.*?)</net>', s, re.S):
        snet[m.group(1)]
        for p, g, pn in re.findall(r'<pinref part="([^"]+)" gate="([^"]+)" pin="([^"]+)"/>', m.group(2)):
            k = part[p]
            if dev[k][0]:
                for pad in dev[k][1].get((g, pn), []):
                    snet[m.group(1)].add((p, pad))

    # --- board model --------------------------------------------------------
    el = {m.group(1): (m.group(2), m.group(3)) for m in
          re.finditer(r'<element name="([^"]+)" library="([^"]+)" package="([^"]+)"', b)}
    epos = {m.group(1): (float(m.group(2)), float(m.group(3)),
                         (re.search(r'rot="(M?R\d+)"', m.group(4)) or [None, "R0"])[1])
            for m in re.finditer(r'<element name="([^"]+)"[^>]*x="([-\d.]+)" y="([-\d.]+)"([^>]*)>', b)}
    bpkg = {}
    for m in re.finditer(r'<library name="([^"]+)">(.*?)</library>', b, re.S):
        for p in re.finditer(r'<package name="([^"]+)"[^>]*>(.*?)</package>', m.group(2), re.S):
            bpkg[(m.group(1), p.group(1))] = p.group(2)
    bsig = {m.group(1): m.group(2) for m in re.finditer(r'<signal name="([^"]+)"[^>]*>(.*?)</signal>', b, re.S)}
    def _dru(k, dflt):
        m = re.search(r'<param name="%s" value="([\d.]+)(mm)?"/>' % k, b)
        return float(m.group(1)) if m else dflt
    RVPADI = _dru('rvPadInner', 0.25)
    RLMINPADI = _dru('rlMinPadInner', 0.1)
    RLMAXPADI = _dru('rlMaxPadInner', 0.5)
    bcon = {n: set(re.findall(r'<contactref element="([^"]+)" pad="([^"]+)"/>', v)) for n, v in bsig.items()}

    head("2. Parts and elements")
    (ok if set(want) == set(el) else bad)(
        "%d parts with a package -> %d elements" % (len(want), len(el))
        if set(want) == set(el) else
        "parts and elements differ: only in schematic %s; only on board %s"
        % (sorted(set(want) - set(el))[:6], sorted(set(el) - set(want))[:6]))
    wrong = [(p, el[p][1], want[p]) for p in want if p in el and el[p][1] != want[p]]
    (ok if not wrong else bad)("every element carries the package its deviceset names"
                              if not wrong else "package mismatch: %s" % wrong[:6])
    ghost = [p for p in part if p not in want and p in el]
    (ok if not ghost else bad)(
        "%d schematic-only parts correctly have no element" % (len(part) - len(want))
        if not ghost else "parts with no package but an element anyway: %s" % ghost[:6])

    # Values drift silently: editing a resistor's tolerance in the schematic
    # leaves the board's copy stale, and the stale one is what gets silkscreened
    # and what feeds the BOM. A part whose deviceset fixes the value carries no
    # value= attribute at all, and the board writes that as "" -- not a mismatch.
    sval = {m.group(1): m.group(2) for m in
            re.finditer(r'<part name="([^"]+)"[^>]*?\svalue="([^"]*)"', s)}
    bval = {m.group(1): m.group(2) for m in
            re.finditer(r'<element name="([^"]+)"[^>]*?\svalue="([^"]*)"', b)}
    vdrift = sorted((p, sval.get(p, ""), bval[p]) for p in bval
                    if p in want and sval.get(p, "") != bval[p])
    (ok if not vdrift else bad)(
        "%d element value(s) match the schematic" % len(bval) if not vdrift else
        "value drift between schematic and board: %s"
        % ["%s sch %r brd %r" % v for v in vdrift[:5]])

    head("3. Nets and signals")
    (ok if set(snet) == set(bsig) else bad)(
        "%d nets -> %d signals" % (len(snet), len(bsig)) if set(snet) == set(bsig) else
        "nets and signals differ: %s" % sorted(set(snet) ^ set(bsig))[:6])
    diff = [n for n in snet if n in bcon and snet[n] != bcon[n]]
    if diff:
        bad("%d net(s) whose (element, pad) set differs" % len(diff))
        for n in diff[:4]:
            bad("   %-12s only in sch %s; only on brd %s"
                % (n, sorted(snet[n] - bcon[n])[:4], sorted(bcon[n] - snet[n])[:4]))
    else:
        ok("every signal's contactrefs match the schematic, %d in total"
           % sum(len(v) for v in bcon.values()))
    multi = sum(1 for k, (_pk, cs) in dev.items() for c in cs.values() if len(c) > 1)
    ok("%d pins map to more than one pad and were expanded" % multi)

    head("4. Contactrefs resolve to real pads")
    miss = [(e, pd) for n, cs in bcon.items() for e, pd in cs
            if e in el and pd not in pads_of(bpkg.get(el[e], ""))]
    (ok if not miss else bad)("every contactref names a pad that exists"
                             if not miss else "contactrefs with no such pad: %s" % miss[:6])

    head("5. Library drift")
    drift = []
    for p, (lib, pk) in el.items():
        if (lib, pk) not in bpkg:
            drift.append((pk, "not in the board's libraries")); continue
        if (lib, pk) not in spkg:
            drift.append((pk, "not in the schematic's libraries")); continue
        a, c = pads_of(spkg[(lib, pk)]), pads_of(bpkg[(lib, pk)])
        if a != c:
            drift.append((pk, "pads differ: %s" % sorted(set(a) ^ set(c))[:4]))
    drift = sorted(set(drift))
    (ok if not drift else bad)("all %d packages identical in both files" % len(set(el.values()))
                              if not drift else "footprints have drifted: %s" % drift[:4])

    head("6. Placement")
    def rp(x, y, rot):
        r = re.sub(r"^M", "", rot)
        x, y = {"R0": (x, y), "R90": (-y, x), "R180": (-x, -y), "R270": (y, -x)}[r]
        return (-x, y) if rot.startswith("M") else (x, y)

    box, art = {}, []
    for p, (lib, pk) in el.items():
        src = bpkg.get((lib, pk), "")
        xs, ys = [], []
        for m in re.finditer(r'<smd name="[^"]*" x="([-\d.]+)" y="([-\d.]+)" dx="([\d.]+)" dy="([\d.]+)"', src):
            x, y, dx, dy = map(float, m.groups()); xs += [x - dx / 2, x + dx / 2]; ys += [y - dy / 2, y + dy / 2]
        for m in re.finditer(r'<pad name="[^"]*" x="([-\d.]+)" y="([-\d.]+)"[^>]*drill="([\d.]+)"', src):
            x, y, d = map(float, m.groups()); r = d / 2 + 0.254; xs += [x - r, x + r]; ys += [y - r, y + r]
        if not xs:
            art.append(p)          # padless: the CC licence artwork, no copper to check
            continue
        ox, oy, rot = epos[p]
        pts = [rp(x, y, rot) for x in (min(xs), max(xs)) for y in (min(ys), max(ys))]
        box[p] = (ox + min(q[0] for q in pts), oy + min(q[1] for q in pts),
                  ox + max(q[0] for q in pts), oy + max(q[1] for q in pts), rot.startswith("M"))
    # Three states, not two. An element that is partly on and partly off the
    # board is neither placed nor parked -- it has copper hanging over the edge,
    # and treating it as parked would also exclude it from the overlap test.
    def inside(v):
        return (v[0] >= BX0 - 1e-6 and v[1] >= BY0 - 1e-6
                and v[2] <= BX1 + 1e-6 and v[3] <= BY1 + 1e-6)

    def clear(v):
        return v[2] <= BX0 + 1e-6 or v[0] >= BX1 - 1e-6 or v[3] <= BY0 + 1e-6 or v[1] >= BY1 - 1e-6

    # X1 hangs over the edge on purpose and the drawing says by how much. Molex
    # SD-105017-001 sheet 1 puts the CONNECTOR FRONT INTERFACE 0.70 mm beyond the
    # PCB EDGE, so the shell overhangs and a footprint that did not would be the
    # wrong one. Everything else straddling is still a finding.
    OVERHANG = {"X1": "Molex SD-105017-001: the mating face sits 0.70 mm past the PCB edge"}
    on = [p for p, v in box.items() if inside(v)]
    off = [p for p, v in box.items() if clear(v)]
    edge = [p for p in box if p not in on and p not in off]
    known = [p for p in edge if p in OVERHANG]
    edge = [p for p in edge if p not in OVERHANG]
    for p in known:
        note("%s hangs over the edge by design -- %s" % (p, OVERHANG[p]))
    (ok if not edge else bad)("no element straddles the board edge" if not edge else
                              "%d element(s) hang over the board edge: %s"
                              % (len(edge), [(p, tuple(round(c, 2) for c in box[p][:4])) for p in edge][:4]))
    edge = edge + known
    on = on + edge          # straddlers still have to be checked for collisions
    tally = len(on) + len(off) + len(art)
    (ok if tally == len(el) else bad)(
        "%d elements on the board, %d parked outside it, %d padless artwork -- %d in all"
        % (len(on), len(off), len(art), tally) if tally == len(el) else
        "placement tally %d does not account for all %d elements" % (tally, len(el)))
    if art:
        ok("padless, so nothing to place-check: %s" % ", ".join(sorted(art)))
    # One element is the board frame rather than a component: the header's
    # package carries the outline itself, so once placed its silk rectangle
    # coincides with the layer-20 outline and its bounding box spans the whole
    # board. Comparing that box against every other part reports an overlap with
    # everything on its side, which is noise. Identify it by that coincidence --
    # not by name -- and check its holes instead of its box.
    # Find it by the SHAPE of its silk, not by where it ended up -- otherwise a
    # frame that is misplaced simply stops being recognised and the check goes
    # quiet, which is exactly the failure being guarded against. X2 spent this
    # whole session parked 20 mm below the board because it was missing from
    # make_board.py's placement table, taking the outline drawing with it.
    frame, framexy = None, None
    for p, (lib, pk) in el.items():
        if p not in box:
            continue
        w21 = [tuple(map(float, q)) for q in re.findall(
            r'<wire x1="([-\d.]+)" y1="([-\d.]+)" x2="([-\d.]+)" y2="([-\d.]+)"[^>]*layer="21"',
            bpkg.get((lib, pk), ""))]
        if len(w21) < 4:
            continue
        xs = [v for q in w21 for v in (q[0], q[2])]; ys = [v for q in w21 for v in (q[1], q[3])]
        if (abs((max(xs) - min(xs)) - (BX1 - BX0)) < 1e-6
                and abs((max(ys) - min(ys)) - (BY1 - BY0)) < 1e-6):
            frame, framexy = p, (epos[p], (min(xs), min(ys)))
    if frame:
        (ox, oy, rot), (sx, sy) = framexy
        placed = rot == "R0" and abs(ox + sx - BX0) < 1e-6 and abs(oy + sy - BY0) < 1e-6
        (ok if placed else bad)(
            "%s carries the board outline and sits on it exactly, so it is the frame, "
            "not an obstruction" % frame if placed else
            "%s carries the board outline but is placed at (%.2f, %.2f) rot=%s -- its outline "
            "lands at (%.2f, %.2f) instead of (%.2f, %.2f), so every pad it owns is off the board"
            % (frame, ox, oy, rot, ox + sx, oy + sy, BX0, BY0))
        pass

    # A plated hole is copper on EVERY layer, so a through-hole part displaces
    # whatever is behind it as much as whatever is beside it. That is what makes
    # this different from the overlap test above, which ignores opposite-side
    # pairs: here the side is irrelevant. JP3 sat over four of the FPGA's
    # decoupling capacitors this way -- its pads cleared everything on its own
    # side, and its six holes went straight through the field on the other.
    #
    # It used to check only the frame's holes, so the one part whose holes were
    # actually landing on something was the part it never looked at.
    def holes(p):
        ox, oy, rot = epos[p]
        out = []
        for x, y, dr in re.findall(
                r'<pad name="[^"]*" x="([-\d.]+)" y="([-\d.]+)"[^>]*drill="([\d.]+)"',
                bpkg.get(el[p], "")):
            hx, hy = rp(float(x), float(y), rot)      # rotate: a hole map read
            out.append((ox + hx, oy + hy, float(dr) / 2 + 0.254))   # unrotated reports phantoms
        return out

    drilled = sorted(p for p in on if holes(p))
    pierce = []
    for a in drilled:
        for hx, hy, hr in holes(a):
            for c in on:
                if c == a or (a != frame and c == frame):
                    continue          # every part is inside the frame by design
                v = box[c]
                if v[0] < hx + hr and hx - hr < v[2] and v[1] < hy + hr and hy - hr < v[3]:
                    pierce.append("%s hole over %s" % (a, c))
    pierce = sorted(set(pierce))
    (ok if not pierce else bad)(
        "no plated hole of %s lands on another element, either side"
        % ", ".join(drilled) if not pierce else
        "%d hole collision(s), side irrelevant: %s" % (len(pierce), pierce[:6]))
    ov = [(a, c) for a in on for c in on if a < c and a != frame and c != frame
          and box[a][4] == box[c][4]
          and box[a][0] < box[c][2] and box[c][0] < box[a][2]
          and box[a][1] < box[c][3] and box[c][1] < box[a][3]]
    (ok if not ov else bad)("no two elements on the same side overlap"
                           if not ov else "%d overlapping pair(s) on one side: %s" % (len(ov), ov[:5]))

    # A layer-39 keepout is the part of a footprint that is not copper but still
    # cannot be built over: JP3's is its connector body, the microSD's is the
    # 8.70 mm the card travels on its way out. Nothing in the placement path
    # measures them -- make_board.py's bbox() reads layers 21 and 51 only -- so
    # they are compared here instead.
    #
    # Only SAME-SIDE pairs count, and the board frame is excluded. Without both
    # filters this reports 155 collisions on a correct board: the frame's
    # keepout is the whole outline, and the decoupling field sits behind the
    # ball field on purpose. With them it found the microSD rotated so its card
    # ejected into the board through BTN, and nothing else.
    def keepout(p):
        ox, oy, rot = epos[p]
        w = [tuple(map(float, q)) for q in re.findall(
            r'<wire x1="([-\d.]+)" y1="([-\d.]+)" x2="([-\d.]+)" y2="([-\d.]+)"[^>]*layer="39"',
            bpkg.get(el[p], ""))]
        if not w:
            return None
        # not clipped to the outline: a keepout that leaves the board is often
        # the point of it, and clipping would have hidden the one real defect
        pts = [rp(x, y, rot) for q in w for x, y in ((q[0], q[1]), (q[2], q[3]))]
        return (ox + min(v[0] for v in pts), oy + min(v[1] for v in pts),
                ox + max(v[0] for v in pts), oy + max(v[1] for v in pts))

    kohit = []
    for a in on:
        k = keepout(a) if a != frame else None
        if not k:
            continue
        for c in on:
            if c == a or c == frame or box[a][4] != box[c][4]:
                continue
            v = box[c]
            if k[0] < v[2] and v[0] < k[2] and k[1] < v[3] and v[1] < k[3]:
                kohit.append("%s keepout over %s copper" % (a, c))
    (ok if not kohit else bad)(
        "no keepout covers another element's copper on the same side"
        if not kohit else "%d keepout collision(s): %s" % (len(kohit), sorted(kohit)[:5]))
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

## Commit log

2026-08-30 Zulu A7 forks from XuLA3: the board is renamed, not redesigned
    The Artix-7 migration already happened in XuLA3 -- XC7A35T-1CPG236C for the
    Spartan-6, FT2232HQ for the PIC, LTC3569 for the discrete regulators. What
    was left was the name, and the name was in more places than the title block.
    Schematic:
    - X2's footprint and deviceset carried the old brand in their identifiers,
    not just their descriptions: XULA-DIP37 -> ZULU-DIP37, XULA-CONN ->
    ZULU-CONN. Renaming those is what makes the rest of this a fork rather
    than a copy with a new filename.
    - Dropped nine devicesets nothing places, and the eleven packages and five
    symbols left orphaned behind them -- the Spartan-6 XC6S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
    [zulu_a7.sch]
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2026-08-30 Make the JTAG two 1x3 headers instead of one 2x3 telling a lie
    The split footprint worked on the board and was wrong in the schematic. JP3 was
    still drawn as a single 2x3 part, and a 2x3 is a thing you plug into. Nothing
    plugs across 17.96 mm. Anyone reading the sheet would have believed a connector
    that does not exist, and the only place the truth lived was a package
    description two libraries away.
    So the part follows the copper. JP3 is TCK/TMS/GND, JP4 is TDI/TDO/VCC3V3, both
    PINHD-1X3 on the new 1X03-NOSILK footprint -- no silk, because a 2.54 mm body
    would come within 0.09 mm of the Pmod's shroud. The six nets are unchanged: the
    same TCK, TMS, GND, TDI, TDO and VCC3V3 land on the same s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
    [zulu_a7.sch]
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2026-08-30 Draw the JTAG as holes, because that is what it is
    Two photographs settled it: the Pmod is a socket a module plugs into, the JTAG
    is bare copper. Both were drawn as the same rectangle with numbered pins, so
    the only thing telling them apart was the refdes prefix. That is the same
    failure as the 2x3 -- a symbol promising a connector that is not there -- one
    level up, in the drawing rather than the footprint.
    So JP3 and JP4 stop looking like connectors:
    - the outline is dashed and 0.1524 wide, not solid 0.4064. Dashed is the
    ordinary way to say a body is not fitted, and it still groups the three.
    - each pin ends in an open circle: the plated hole itself.
    - function="dot" is gone. T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
    [zulu_a7.sch]
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2026-08-30 Move Q1 out from between the USB shell and the FT2232
    It was at x 33, in the 4.80 mm slot between the FT2232's top edge and the USB
    shell, with half a millimetre either side. Nothing else could use that slot,
    which is why I put it there, but "nothing else fits" is a reason to leave a gap
    empty, not a reason to wedge a part into it.
    At x 23 it sits above the LEDs and left of the FT2232, in the 7.34 mm of
    channel between the LED block and X2's top row. Its tightest neighbour is now
    BTN at 0.45 mm on one side, with 1.91 to the FT2232, 2.62 to the USB, 1.60 to
    the LEDs and 1.94 to X2's channel edge -- air on every side instead of two
    0.5 mm slivers.
    Same y, so it is still on the front and stil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
    [board_plan.py, make_board.py]
2026-08-30 Generate the board: 169 elements, 175 signals, nothing routed
    make_board.py and check_board.py both clean. The two share no code, so the
    board agreeing with the schematic is two independent readings of the files, not
    one function agreeing with itself.
    214 parts -> 169 elements, 45 schematic-only parts correctly have none
    175 signals, 787 contactrefs, 5 pins expanded to several pads
    32 packages across 3 libraries, none missing, none drifted between the files
    238 ball lands at 0.225 mm, 6 copper layers, JLCPCB rules loaded
    0 wires, 0 vias -- unrouted by design
    The check that mattered for the last few days of work: "no plated hole of J1,
    JP3, JP4, X1, X2 lands on another element, ei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
    [zulu_a7.brd]
2026-08-30 All 39 FPGA decoupling capacitors placed; the fields follow the ring now
    The nine parked 0.47 uF were a symptom. tile() was placing ZERO of the 35
    capacitors it is handed -- not nine short, none at all -- and the anchored pass
    further down was quietly catching 25 of them. The decoupling was not nearly
    right with a few gaps. It was unplanned, and it looked nearly right.
    WHY. The four fields were fixed boxes hugging the package, sized when Q1 sat at
    x 53.79 and capped the escape's fan-out ring at 6.94 half-width. Moving Q1 off
    the +x end for the split JTAG, and then again out from between the USB and the
    FT2232, left nothing capping the ring, so it opened to its full 7.64 -- exactly
    the figur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
    [zulu_a7.brd]
2026-08-30 Seat R33 and R91 by hand; D3 has nowhere worth going
    R91 lands 8.4 mm from U2's ADBUS2, which is beside the pin it pulls up and as
    good as it needs to be. R33 lands 15 mm from U1 ball 1 and 24 from J1 pin 10 --
    it is the series resistor between those two, so it wants to be at one END and
    is in the middle instead. Usable, not good.
    D3 IS STILL PARKED, ON PURPOSE. I said earlier it had a sensible home; that was
    wrong, and the error was in what I measured. I checked it fitted within 24 mm of
    U1 and reported that as fitting where it belongs. D3 does not belong near U1 --
    it belongs at X2 pad 1, because that is where VEXT enters the board. The nearest
    free keepout-sized slot to that pin is x 2.6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
    [zulu_a7.brd]
2026-08-30 The eight Pmod series resistors go 0402 -> 0201
    R26-R33, the 200R in series with the Pmod's eight signal pins. New R0201
    package in rcl and an R0201 device on R-US_SMALL; the parts keep their value,
    their nets and their 1 % tolerance.
    WHAT IT BOUGHT. All eight now sit in a 2x4 block at x 59.49 and 60.09, y 8.60
    to 13.99, hard against J1 -- which is where a series resistor for a connector
    pin belongs. R33 came off the hand-pin it needed two commits ago: at 0402 it
    would not seat within 24 mm of J1 and had to be stranded at x 33; at 0201 the
    anchored pass reaches it and it rejoined its seven siblings. Keepout per part
    falls 2.95 x 0.97 to 1.75 x 0.37, about a quarter of the area.
    THE POWER R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
    [zulu_a7.brd, zulu_a7.sch]
2026-08-30 The eight XADC resistors go 0603 -> 0201, and five parts come off the park
    R10-R17, both XADC channels: the 2.32k/1k divider, the 140R into AIN_P and the
    845R from AIN_N to ground. R-US_ gains an R0201 device; values, nets and 1 %
    tolerance unchanged.
    POWER IS NOT THE QUESTION HERE, unlike the Pmod eight. The only ones carrying
    current are R10/R14 at the top of a 3.32k divider: 2.3 mW at a 3.3 V input,
    5.3 mW at 5 V, against an 0201's 50 mW. Eleven per cent of rating at the worst
    case, nine times the margin. R12/R13/R16/R17 sit on XADC inputs and carry
    leakage. Nothing here cooks the way a shorted Pmod pin does.
    Nor does size touch what this circuit depends on. R13 = 845R is matching
    R12 +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
    [zulu_a7.brd, zulu_a7.sch]
2026-08-30 Split R1, R2 and R4 into eleven discretes; one part left parked
    R1 and R2 to 0201, R4 to 0402, as agreed. The arrays fitted NOWHERE -- a
    742C083 needs 3.55 x 3.35 and the largest free square on this board was 2.9 x
    2.9 front, 2.1 x 2.1 back -- so they were not short of a good spot, they were
    short of any spot.
    FIVE OF THE SIXTEEN ELEMENTS WERE NEVER CONNECTED. R1 used 2 of 4, R2 used 3 of
    4, R4 used 6 of 8. Three arrays were holding 25.4 mm2 of a board with no room
    in order to deliver eleven resistors. That is the real find; the size change is
    secondary.
    THE SYMBOL DID NOT CHANGE, WHICH IS WHY NO WIRE MOVED. R1NV0, the symbol the
    arrays drew their elements with, has its pins 10.16 mm apart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
    [zulu_a7.brd, zulu_a7.sch]
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2026-08-30 The board plan draws the board again: decoupling is two strips, not a block
    It had drifted into being a picture of a board that no longer exists. It drew
    the FPGA decoupling as one back-side block at x 40.00 to 53.90 -- which is the
    escape ring, the one place a capacitor now cannot go -- while the real
    capacitors sit in the bands above and below it, 25 on the back and 14 on the
    front, spread x 17.1 to 50.4. Only 4 of 39 were anywhere near the rectangle
    claiming to hold them.
    Nothing caught it because nothing could: board_plan.py reads the schematic and
    its own numbers, check_board.py reads the schematic and the board, and neither
    reads the other's output. The same failure as the decoupling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
    [board_plan.py]
2026-08-30 A BOM, keyed on what you order rather than what the value says
    tools/bom.py -> docs/zulu_a7-bom.csv. 63 lines, 179 parts, 176 fitted and 3 DNP.
    IT DOES NOT GROUP BY VALUE, and that is the whole design. Six part numbers in
    this schematic are spelled with two different value strings -- 10K and 10k,
    0.1uF and 100nF, 22uF and "22uF 10V", 4.7K and 4.7k -- so grouping by value
    would have produced twelve lines for six parts you order once. The key is the
    orderable identity: MANF# where there is one, and the value where the value IS
    the part number, which is how most of the ICs carry it here. The variants are
    reported rather than silently merged: they are worth fixing in the schematic,
    and I have n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
    [zulu_a7-bom.csv]
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2026-08-30 LD1, LD2 and R34 get part numbers; no unidentifiable part left
    R34 is the microSD DAT0-3 pull-ups and ALL FOUR elements are used -- which is
    what an array is for, and why this one stays an array where R1, R2 and R4 used
    2, 3 and 6 of theirs and were better off split. 4.7k was already the value; only
    the number was missing. CTS 742C083472JTR, and 5 percent where the discretes on
    this board are 1, because a pull-up does not care.
    LD1 and LD2 are user status LEDs off FPGA pins through R83/R84 at 330R, so
    (3.3 - Vf)/330: 3.9 mA green, 4.2 red, 3.6 yellow, 1.2 blue. Any of the first
    three is comfortable and well inside an LVCMOS33 pin's 12 mA. They are twice as
    bright as LD5's 1.9 mA, which is r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
    [zulu_a7-bom.csv, zulu_a7.sch]
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2026-08-30 J1 and Q1 get real parts; only the two datasheet-bound ones are left
    Q1 -> Abracon ASEM1-12.000MHZ-LC-T. THE SCHEMATIC SAYS IT IS AN OSCILLATOR AND
    NOT A CRYSTAL: pin 2 to GND, pin 4 to VCC3V3, pin 3 out into R24 and R25, pin 1
    tied high. A crystal would be two pads and a pair of load capacitors. The
    frequency was never a choice either -- the FT2232H wants 12 MHz for its USB PLL,
    so it was fixed before the rest of the board existed. 25 ppm is the figure
    already in the value and is inside what FTDI asks of the reference. Pin 1 to Vdd
    suits an OE part or one with pin 1 unconnected, so that does not narrow it. The
    design note had already named the ASEM1 family for the oscillator it replaced.
    J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
    [zulu_a7-bom.csv, zulu_a7.sch]
2026-08-30 Regenerate the board: four element values had not reached it
    I said several times that attribute-only edits do not need the board rebuilt.
    That is true of MANF, MANF# and SPEC, which live only in the schematic. It is
    NOT true of value: an EAGLE element carries its own value string, so LD1 and LD2
    still read "LED" on the board, and LD5 and Q2 read empty, while the schematic
    had red, red, green and 2N7002.
    check_board did not catch it and is not wrong to have missed it -- it compares
    parts to elements by package and nets to signals by contactref, which is what
    consistency means for connectivity. A value is a label. It is also what gets
    silkscreened and what a pick-and-place file carries, so i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
    [zulu_a7.brd]
2026-08-30 BTN and LD0 from their datasheets; every part now has a number
    Both were in Datasheet/, and both turned out to have had their number in the
    value field all along -- I had called them series names, and for these two that
    was wrong.
    LD0 -> VS NRD8, Victory Electronics. The datasheet's own "Part Number" column
    reads VS NRD8, so it is the part, not a family. Confirmed against the drawing
    this library's land was traced from.
    BTN -> PTA-142. The catalogue page is IMAGE-ONLY -- twelve JPEGs, no text layer
    at all -- so pdf text extraction returned nothing and I had to render it and read
    the picture. It says the part number is complete as it stands: one operating
    force (130 gf +-30), one stem colou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
    [zulu_a7-bom.csv, zulu_a7.sch]
2026-08-30 Balance the RGB LED, and correct what I said was wrong with it
    FIRST, THE RETRACTION. I said green and blue had "no headroom" and their current
    was "set by the diode knee", implying they might barely light. That was wrong,
    and the error was mine: I took Vf = 3.3 V typical from the datasheet's 20 mA
    table and applied it at a 2 mA operating point. The datasheet's own Vf/If curve
    on page 3 puts Vf near 3.0 V down there. Worked properly, the circuit as built
    gives red 6.9 mA, green 1.9 and blue 1.5. All three light.
    Cmod A7 ships the identical circuit -- same VS NRD8, same 182/182/100 off 3V3,
    per its schematic in Datasheet/cmod_a7_sch.pdf. Zulu A7 inherited it whole.
    WHAT IS ACTUALLY WRONG IS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
    [zulu_a7-bom.csv, zulu_a7.brd, zulu_a7.sch]
2026-08-30 Fix the 0201 land: the heel was positive, which is how 0201 tombstones
    The land I drew was pads 0.30 x 0.30 on a 0.20 gap. Measured against the
    standardised 0201 body -- 0.60 x 0.30 with 0.15 mm terminals -- that is toe
    +0.10, HEEL +0.05, side 0.00.
    The heel is the defect. A positive heel puts 0.05 mm of pad under the body at
    each end, and solder wicking in under one end before the other wets is the
    classic 0201 tombstone mechanism. IPC puts heel at 0.00 for chips this size and
    spends the margin on the toe instead, where the fillet is also the one an
    inspector can actually see.
    Pads move out to +-0.30: gap 0.30, span 0.90, toe +0.15, heel 0.00, side 0.00.
    The keepout follows, 1.746 -> 1.84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
    [zulu_a7.brd, zulu_a7.sch]
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2026-08-30 Route 25 more signals: the missing QFN escape, the run order, and the nets nobody owned
    52 signals carried no copper; 27 do now, and check_board is clean at 0
    findings -- 2373 wires, 375 vias, everything clearing foreign copper by
    >= 0.090 mm.
    Most of the 52 were never attempted. signals.py had five group regexes and
    the board is not only buses: the Pmod signals, the LEDs, the pushbutton, the
    slide switches, the LTC3569 feedback dividers, PGOOD, MODE, the XADC pair,
    the shared 12 MHz clock and the EEPROM data line matched none of them and
    reported "unrouted" every run without a router ever looking at them.
    escape_qfn.py was not in the chain. U2's QFN-64 fan-out is a stage of its
    own; witho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
    [zulu_a7.brd]
2026-08-30 signals.py: validate the finished greedy plan instead of trusting the run
    The greedy router checked every route against `rivals` -- the plan AT THAT
    INSTANT -- and never looked at the finished set. That check is correct when
    it is made and stops being correct immediately: rip-up removes members and
    adds others, the best-round snapshot can restore a net that was placed
    before the net it now sits on, and pairplan is merged in at the end having
    been routed against none of the group. PMOD-4 came out of it with its L3
    trace through PMOD-7's via at -0.16 mm, a short between two Pmod signals
    that only check_board.py could see.
    The clearance test was never the problem. collides() is if anything
    str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
    [zulu_a7.brd]
2026-08-30 signals.py: PathFinder gets the same final validation, from one shared helper
    The greedy branch got a pass over the finished plan last commit; PathFinder
    had the same exposure and a weaker guard than it looked. Its revert loop
    compares WIRE AGAINST WIRE ON ONE LAYER -- vias never enter the comparison
    -- and its remedy is to restore a net's unstraightened path, which silently
    does nothing once neither net still has a raw path to go back to:
    bad.add(...) runs, `if n in raw` fails, and three rounds pass without
    changing anything or saying so. It also runs BEFORE pairplan is merged, so
    the differential pair was never checked against the group at all. That gap
    is where D10 vs SDRAM-CLK at -0.1000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
    [zulu_a7.brd]
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2026-08-31 The USB differential pair routes: five faults, each hidden by the one before it
    USB_D_P/USB_D_N goes down on L16 at 21.6/21.6 mm, skew 0.921 against a
    1.27 mm budget, coupled at exactly 0.2750 mm centre to centre for its whole
    length, 0.15 mm conductors, L1 fan-in / L16 coupled / L3 for the side swap.
    AIN15 and AIN16 come with it as ordinary single-ended nets, which is right
    for XADC inputs at 1 MSPS. 20 of 175 signals bare, against 24; 2620 wires,
    408 vias, 0 findings.
    Nothing here was congestion. Every one of these was found only after the
    previous one stopped masking it.
    1. THE FAN-OUT WAS NEVER WIDENED. The two vias at an end sit where their
    conductors end, PAIR_W + PAIR_GAP = 0.275 mm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
    [zulu_a7.brd]
2026-08-31 VU, VEXT and USB5V0 route: eight rails close, and the obstacle models agree
    All eight rails now go down -- VCC1V0, VCC1V8, FT-VCORE, FT-VPHY, FT-VPLL,
    VU (166.7 mm), VEXT (42.5) and USB5V0 (44.8), 0 edges failed on any of them.
    16 of 175 signals bare, against 20; 3031 wires, 423 vias, 0 findings.
    Almost none of this was congestion. Seven of the eight faults were a router
    carrying its own private model of the board with a category missing from it,
    and check_board -- which builds its model from the finished article -- caught
    every one.
    U8 GETS A FAN-OUT. VU arrives on six pins of a QFN-20 at 0.5 mm pitch and
    there is room beside it for two vias, so four were stranded every run.
    escape_qfn's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
    [zulu_a7.brd]
2026-08-31 U2's footprint shorted 30 pin pairs, and the drill rule was missing everywhere
    Fusion's DRC reported 727 errors on a board check_board.py called clean. It
    was right and this toolchain was wrong in three separate ways.
    U2'S QFN-64 FOOTPRINT SHORTS ADJACENT PINS. FT2232HQ-QFN64 has dx and dy
    swapped on two of its four edges: the north pads sit at 0.5 mm pitch along x
    and were 0.6 mm wide, overlapping BOTH neighbours by 0.1 mm, and the west
    pads do the same along y. 16 + 16 pads, 30 shorted pairs, in copper, in the
    library. South and east are correct, which is why it survived -- three edges
    of four look right and the two wrong ones are wrong in opposite directions,
    so nothing about the outline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
    [zulu_a7.brd, zulu_a7.sch]
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2026-09-06 Zulu_Altrium: un-flip the imported text, tidy the labels, prove the netlist
    The EAGLE importer keeps R180/R270 text as Altium orientation 2/3, which
    Altium draws upside down where EAGLE had auto-flipped it: 435 net labels,
    designators and notes on six sheets. tools/fix_text_orientation.py turns
    them into 0/90 with the justification mirrored (top-right for the old 180s)
    so every anchor stays on its wire and every text box stays where it was;
    the font is swapped for the same face at the matching rotation.
    tools/fix_labels.py holds the placement fixes found by reviewing the Smart
    PDF export: the 16 hidden-name labels (SW*_NET, PMOD-*, NODE_P*) and the
    N$ ones are small and hang under their wir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
    [zulu_a7_0.SchDoc, zulu_a7_1.SchDoc, zulu_a7_2.SchDoc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]
2026-09-06 Zulu_Altrium: show the gate names on X2, U3, U4 and the FPGA again
    The one-pin-per-gate EAGLE parts label each pin through the symbol's
    >GATE text. The importer turns that into a GATE parameter on every placed
    gate but stamps all of them OwnerPartId=1, and Altium only draws a
    parameter whose owner part matches the component's current part, so only
    one name per part survived (CHAN-CLK on X2). It showed correctly in the
    wizard's in-memory view, which is why the first screenshot had them all.
    tools/fix_gate_labels.py re-owns each of the 244 labels to its own gate:
    44 on X2, 54 on U3, 8 on U4, 138 on U1. Netlist re-checked: unchanged,
    CONNECTIVITY MATCH. zulu_a7.pdf re-exported.
    Co-Authored-By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
    [zulu_a7_2.SchDoc, zulu_a7_3.SchDoc]
2026-09-07 Zulu_Altrium: ERC clean, with the reasons the importer made it noisy
    Project > Validate on the imported schematic gave 9 errors and 59 warnings.
    None were design faults:
    - 9 "floating input pin" errors + 9 "unconnected pin" warnings were the
    eight GTP balls the FPGA sheet marks "float per UG482 T5-4" and the USB
    ID pin X1-4, all open in EAGLE too; their EAGLE direction is "in".
    tools/add_noerc.py puts a No-ERC marker on each pin's hot end.
    - 4 "IO pin and power pin" warnings came from the EAGLE library typing the
    supply/ground pins of U2, U3, U4, U10 and every pin of the X2 header as
    "io". tools/fix_pin_types.py makes supply pins Power (including U2's
    VREGOUT and the header's GN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
    [zulu_a7_1.SchDoc, zulu_a7_2.SchDoc, zulu_a7_3.SchDoc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]
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2026-09-07 Zulu_Altrium: VCC3V3 onto the LTC3569's 1.2 A channel, VCC1V0 onto SW3
    Power Supplies sheet: the rail labels after L1 and L3 swap, R65/R66 go
    30K/120K -> 180K/57.6K so FB1 regulates 3.3 V, R71/R73 go 180K/57.6K ->
    30K/120K so FB3 regulates 1.0 V, and EN1/EN3 swap their wiring so the
    always-on enable on VU still starts VCC1V0 first (UG483 order). The
    inductors keep their channels: L1 (1.5 uH, 1.8 A part) carries VCC3V3 on
    the 1.2 A buck, L3 (2.2 uH, 0.9 A part) carries VCC1V0 on the 600 mA one;
    C80 22 uF now backs the 1.2 A channel and C84 10 uF the 600 mA one, which
    is the datasheet pairing. tools/swap_vcc3v3_to_sw1.py made the edit and
    is the change record; a dated note sits above U8 on the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
    [zulu_a7_1.SchDoc]
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2026-09-07 Zulu_Altrium: three fixed SC189 bucks replace the LTC3569 on the power sheet
    The power budget showed the LTC3569's 600 mA channels short of headroom
    on VCC3V3 once the SD and SDRAM worst cases stack, and the user wants
    those met from a USB-A port alone. Sheet 1 now carries the Cmod A7
    arrangement: one SC189 per rail (U5 SC189Z 3.3 V, U6 SC189L 1.8 V,
    U7 SC189A 1.0 V), each 1.5 A, fixed output, EN tied to VU. The feedback
    dividers, the EN_BIAS RC, the sequencing FET Q3, R79 and the LTC3569's
    own bypass caps go away; L1-L3 become 1.5 uH, C80/C82/C84 22 uF,
    C78 10 uF 10 V, and each buck gets a 10 uF input cap (C147-C149).
    LD5 keeps its R77/Q2 driver and now shows VCC3V3.
    tools/sc189_power_sect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
    [zulu_a7_1.SchDoc]
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2026-09-07 Zulu_Altrium: X3 becomes the Hirose DM3D-SF push-pull microSD socket
    The user asked for the DM3AT-SF-PEJM5 (push-push, with ejector) to be
    replaced by the DM3D-SF (push-pull, HRS 609-0025-8). Page 9 of the DM3
    catalog already on disk as Datasheet/DM3AT-SF-PEJM5.pdf is the DM3D-SF
    page: same eight microSD contacts in the same order, four solder points
    on the metal cover, and a card-detection switch with two terminals that
    close when a card is in.
    tools/x3_dm3d_sf.py rewrites X3 on sheet 3: part identity, Comment,
    DeviceName, MANF#, new HRS# and SPEC parameters, footprint model name
    DM3D-SF; the two multi-pad shell pins 'G1,3'/'G2,4' left over from the
    EAGLE import become four pins G1-G4 on t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
    [zulu_a7_3.SchDoc]
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
